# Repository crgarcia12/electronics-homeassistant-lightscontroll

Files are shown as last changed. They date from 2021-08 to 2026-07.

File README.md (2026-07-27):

# Home Automation Lights Controller - ESPHome & Home Assistant Compatible

A smart lighting controller PCB that integrates seamlessly with ESPHome and Home Assistant while maintaining full compatibility with traditional mechanical switches. This device acts as a "sidecar" to existing latching relays, adding smart home capabilities without compromising safety or requiring rewiring.

## Table of Contents

- [Overview](#overview)
- [Key Features](#key-features)
- [Quick Start](#quick-start)
- [Prerequisites](#prerequisites)
- [Available Versions](#available-versions)
- [How It Works](#how-it-works)
- [Installation Guide](#installation-guide)
- [Configuration](#configuration)
- [Technical Specifications](#technical-specifications)
- [Ordering from JLCPCB](#how-to-order-from-jlcpcb)
- [Development](#development-notes)
- [Version History](#version-history)
- [Contributing](#contributing)

## Overview

This circuit controls home lights following these core principles:

1. **Safe**: Safety is first and is not compromised in any decision
2. **Fail-safe**: If this device fails, the lights are still controllable using the mechanical switches
3. **Follows standard installation**: This device does not require you to rewire your house
4. **Centrally installable**: Can be installed in a central electrical panel

Following those principles and using as a reference a multi-switch light controlled with a mechanical latching relay, this is the wiring concept:

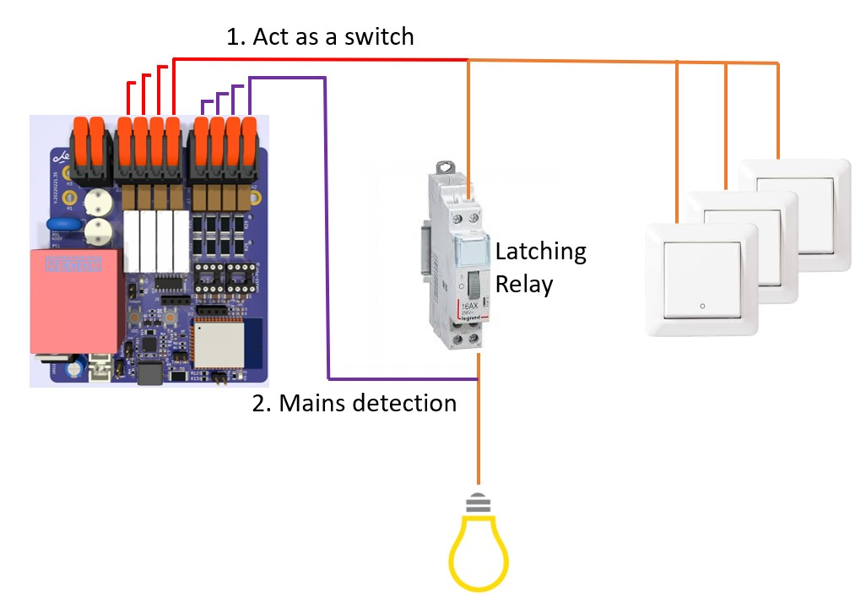
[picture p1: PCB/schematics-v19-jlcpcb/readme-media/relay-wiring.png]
Relay wiring diagram showing how the controller integrates with existing latching relay setup


A normal circuit sends all push buttons to the latching relay, which controls the lights. This circuit (ESPHome) acts as a sidecar to the latching relay, functioning as a standard push button while also sensing the output of the latching relay to detect whether the lights are on or off.

## Key Features

### Hardware Features

- **Extensible design**:
  - Exposed I2C pins
  - Exposed Serial pins
  - Multiple GPIO pins available
  - 3.3V jumper: Allows disconnecting the internal ESP32 and replacing it with any other microcontroller
  - Relay pins (4-channel version): Relays can be controlled with an external microcontroller or device directly
  - Current sensing pins: Current sensing information is exposed for external microcontroller or device integration
  - Provides both 3.3V and 5V power rails
- **ESPHome compatible**: Easy integration with Home Assistant
- **Latest versions use ESP32-S3**: A powerful microcontroller with extensive features

### Safety Features

This device incorporates multiple layers of protection:

- Input fast-blow fuse
- Input MOV (Metal Oxide Varistor) for surge protection
- Slow fuses in every relay output
- Slow fuses in every mains detection input
- 4kV insulated power supply for low voltage isolation
- Conformal coating with 90kV/mm² insulation
- High-precision temperature sensor (SHT40)

## Available Versions

There are two main versions of the board:
- **4-channel version**: Compact design for smaller installations
- **8-channel version**: Extended capacity for larger installations

Latest versions use the ESP32-S3, which is a powerful microcontroller with WiFi, Bluetooth, and extensive GPIO capabilities.

## Quick Start

### What You'll Need

- One of the PCB versions (4 or 8 channels)
- Existing installation with mechanical latching relays
- WiFi network for ESPHome connectivity
- Home Assistant instance (optional, but recommended)

### Basic Setup Steps

1. **Order the PCB**: See [Ordering from JLCPCB](#how-to-order-from-jlcpcb) section
2. **Wire the device**: Connect to your existing latching relay setup
3. **Flash ESPHome**: Upload the ESPHome configuration (see [Configuration](#configuration))
4. **Integrate with Home Assistant**: The device will auto-discover in Home Assistant

For detailed instructions, see the [Installation Guide](#installation-guide) section below.

## Prerequisites

Before installing this controller, ensure you have:

- Basic understanding of electrical wiring and safety
- Existing mechanical latching relay installation
- Access to your electrical panel
- **Safety equipment**: Insulated tools, voltage tester
- **Knowledge**: Only qualified electricians should work with mains voltage
- ESPHome installed (for firmware flashing)
- Home Assistant (optional, for smart home integration)

## Current Version: Version 27

Version 27 is an evolution of version 26.1, optimized to fit perfectly in the standard DIN rail enclosure.

**Hardware**: Uses SN74LVCH8 level shifter with OUTPUT_ENABLED feature

Board schematics for version 27
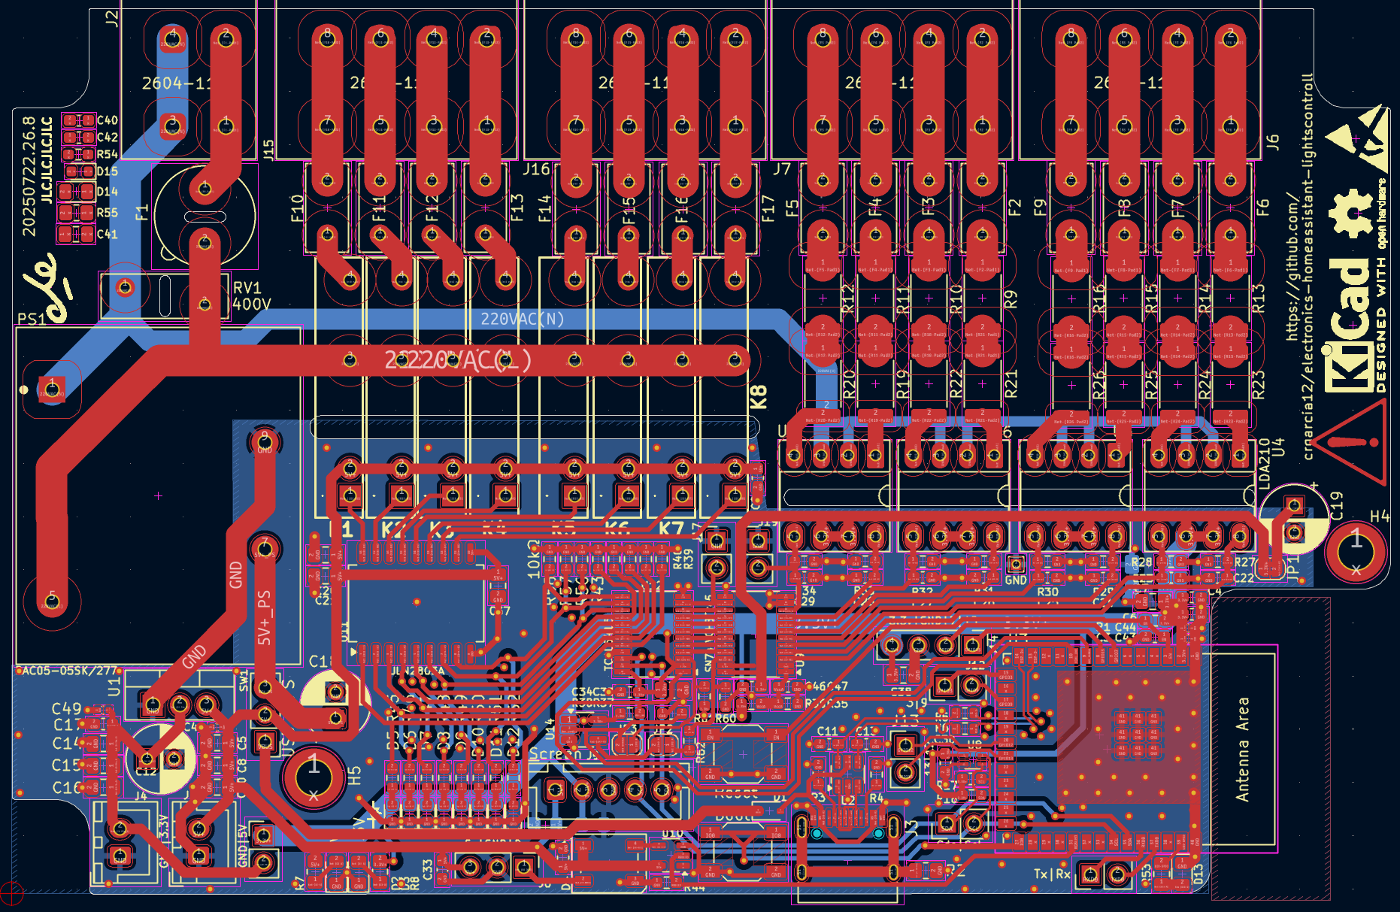
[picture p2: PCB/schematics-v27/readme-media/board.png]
PCB layout for version 27

Front view of PCB version 27
Back view of PCB version 27
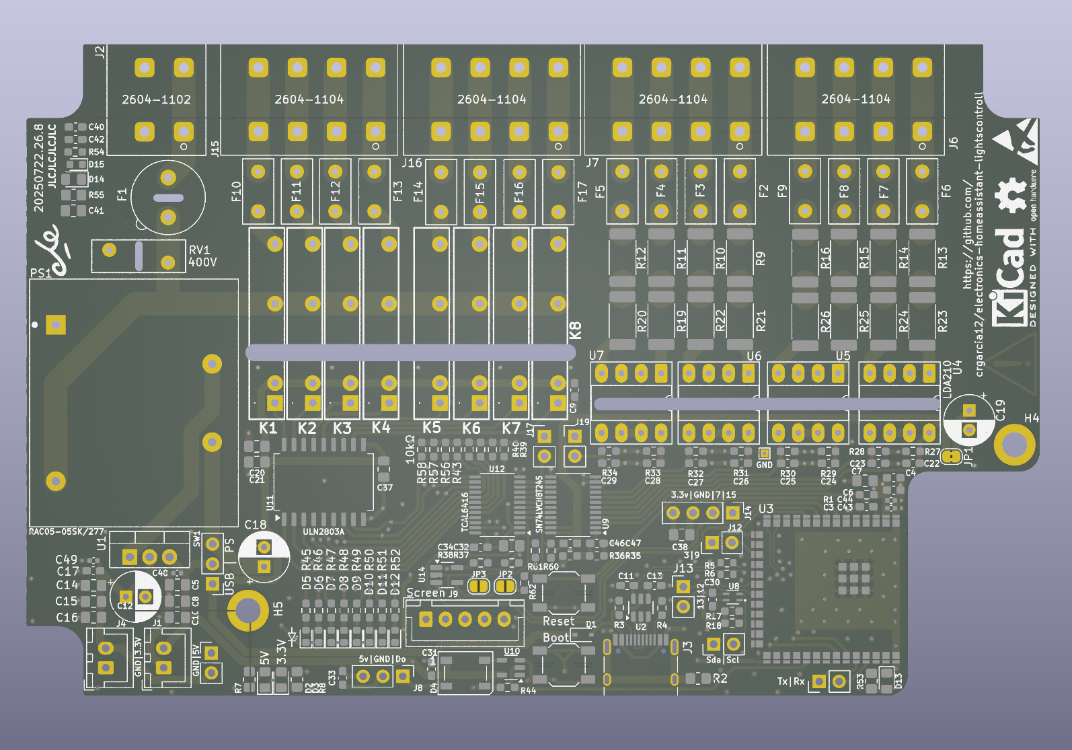
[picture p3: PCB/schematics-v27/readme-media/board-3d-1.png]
3D render of board - angle 1

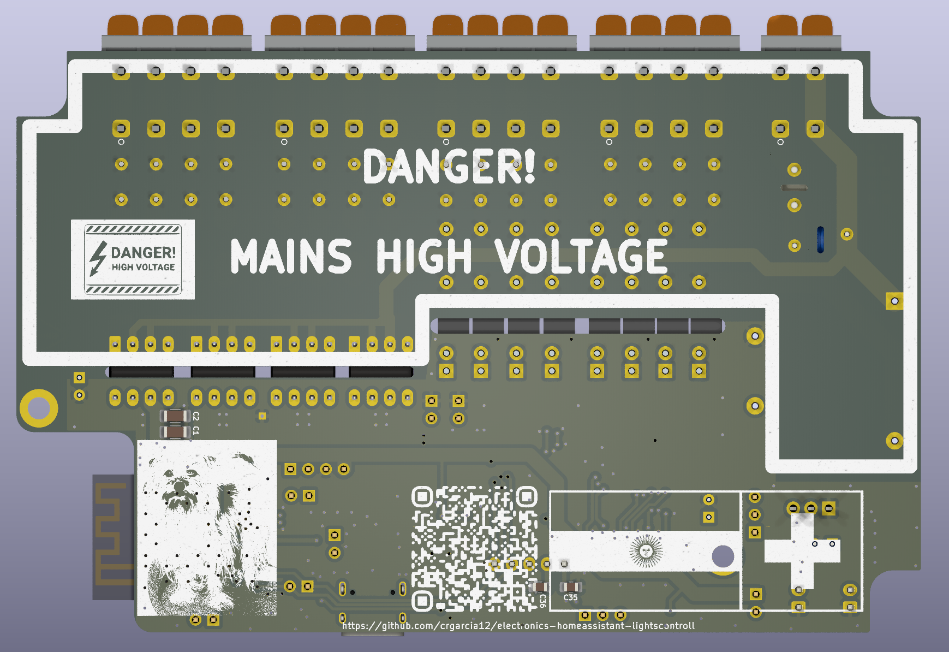
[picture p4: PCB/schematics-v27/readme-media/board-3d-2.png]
3D render of board - angle 2

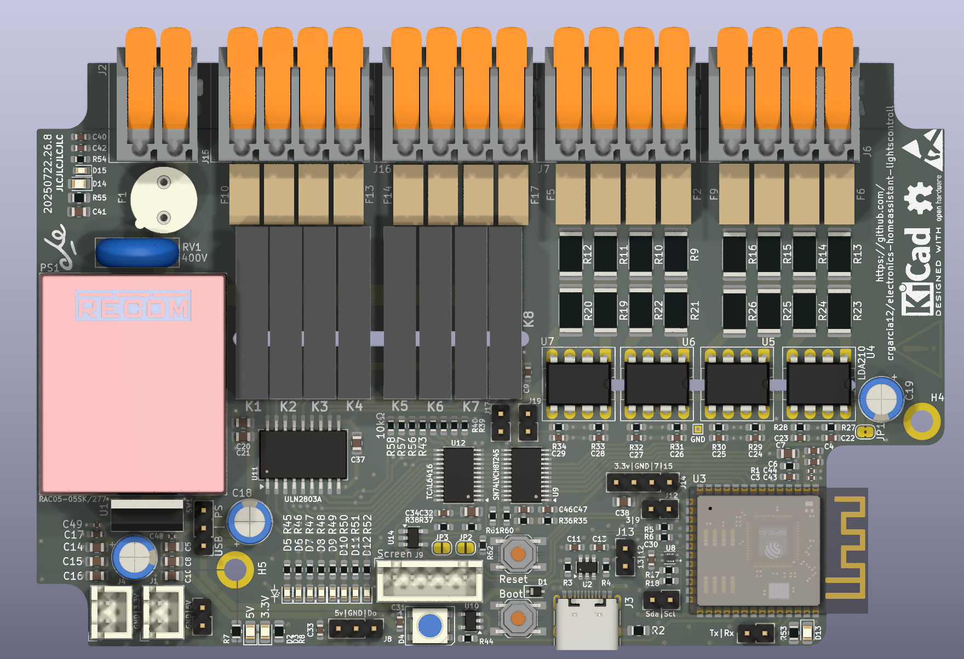
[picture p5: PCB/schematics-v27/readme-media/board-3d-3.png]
3D render of board - angle 3

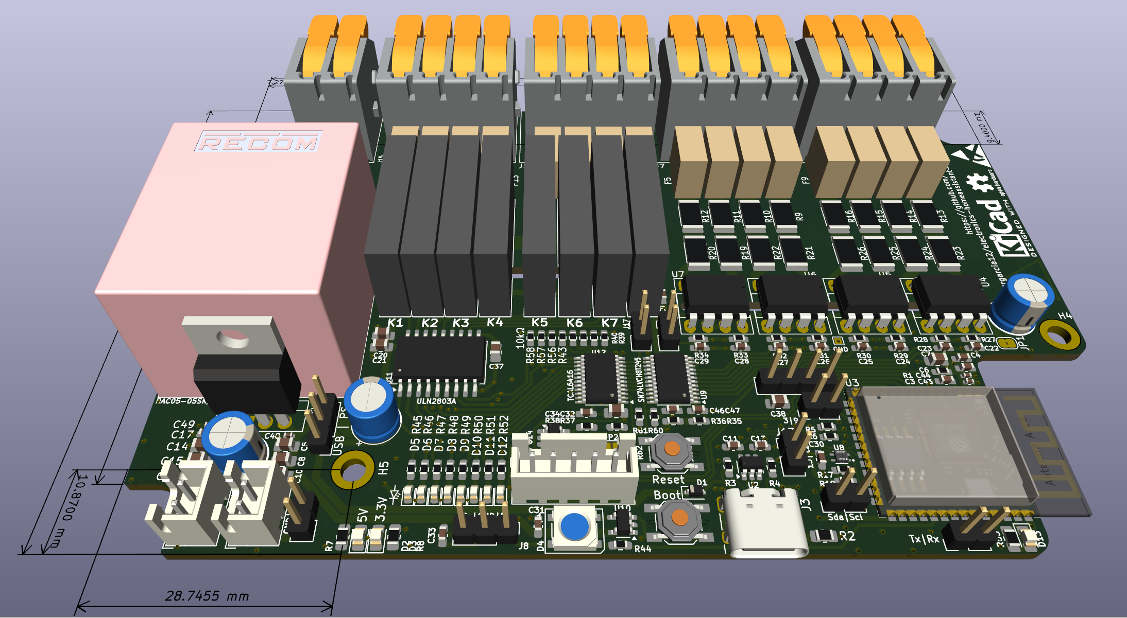
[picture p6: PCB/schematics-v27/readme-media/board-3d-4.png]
3D render of board - angle 4

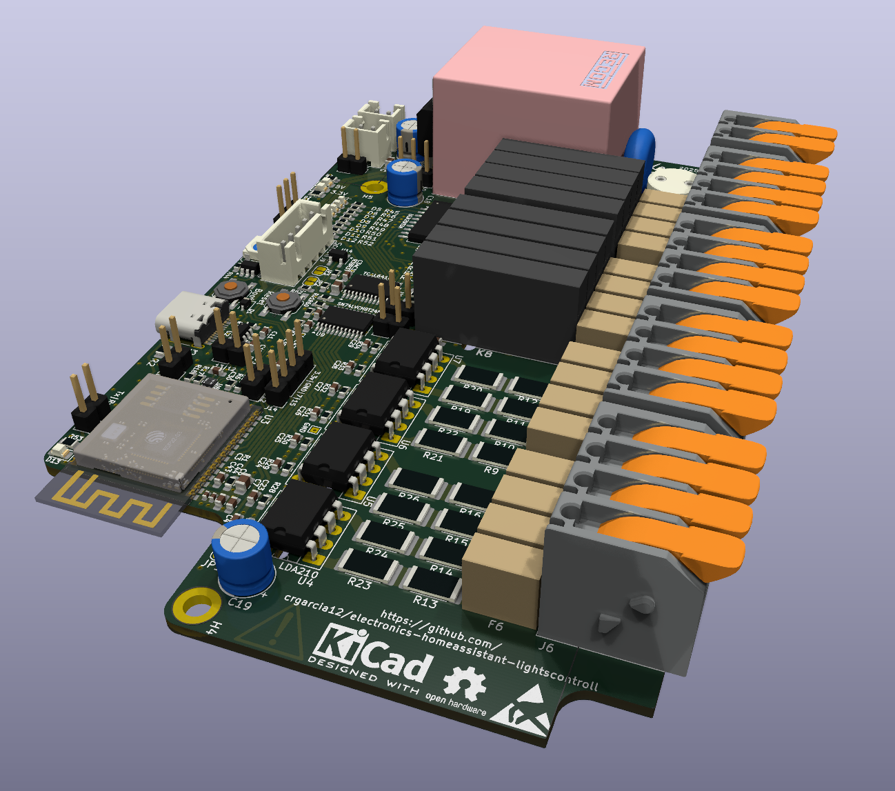
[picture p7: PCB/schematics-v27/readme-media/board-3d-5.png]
3D render of board - angle 5


## How It Works

### Mains Sensing
The PCB uses an optocoupler (LDA210 or ILD755) to detect the presence of mains voltage. These Darlington optocouplers are chosen specifically for their low current requirements, drawing only 0.7mA at less than 2V. This low-power design allows for efficient sensing without overheating components.

To reduce the mains voltage to a safe level for the optocoupler, a 300kΩ resistance setup is used. This configuration dissipates only 0.17W, which is split across two resistors. Each resistor, therefore, dissipates about 0.08W, preventing overheating issues commonly seen with other designs (such as those using the HCP chip). This improvement enhances both the safety and longevity of the PCB.

Each mains sensing channel is equipped with a fuse to protect against failures. In the event that one of the resistors fails short, the remaining resistor can carry up to 1.5mA until the fuse burns out, effectively preventing further damage. During this failure condition, the resistor would dissipate about 0.4W, so large resistors are used to withstand this potential load.

### Optocoupler and Capacitor Behavior

This PCB uses a Darlington optocoupler (LDA210), chosen for its high-gain behavior, which allows the system to react more quickly when mains power is turned on and requires less current on the LED side.

The oscilloscope images below show two different channels after the optocoupler while they are sensing mains. The yellow channel does not have any capacitors on the output, while the blue line has the capacitors.

In the first image, the optocoupler’s response to the sine wave is shown when mains power is ON. The blue line illustrates how capacitors help maintain the output in a high state when the AC cycle is crossing zero. This capacitor-induced holding effect ensures that the output remains stable, preventing fluctuations in the DC output that could cause false OFF triggers. However, this design means the line must be off for several cycles before the microcontroller can reliably detect the "off" state. Using excessively large capacitors can increase the detection delay to a noticeable extent, so capacitor size must be carefully selected to balance responsiveness and stability.

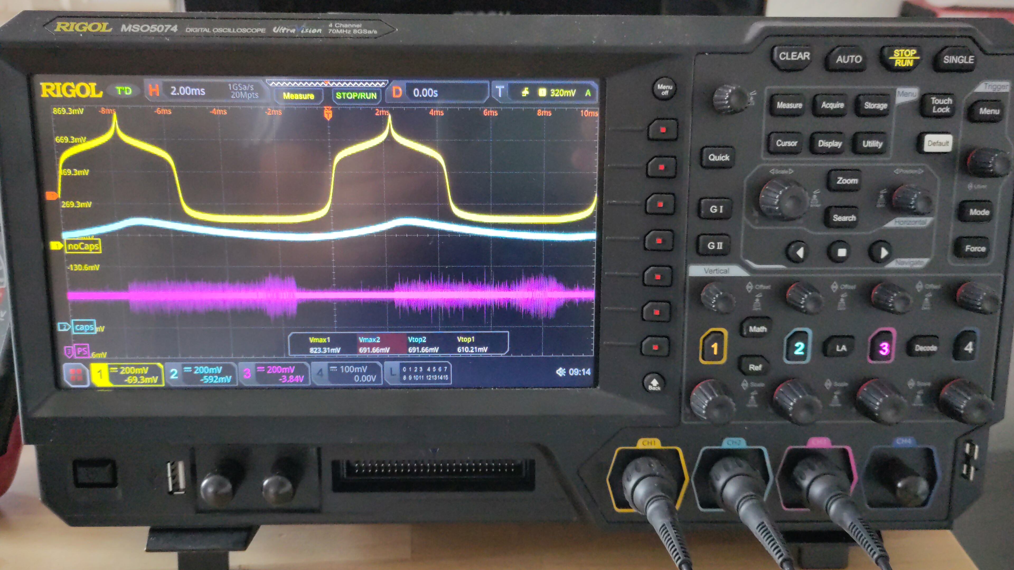
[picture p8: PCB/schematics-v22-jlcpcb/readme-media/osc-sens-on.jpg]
oscilloscope-sensing-mains-1


When mains power is first applied (yellow line), the capacitor requires time to charge before the optocoupler’s output reaches a high state (blue line). This results in a slight delay before the microcontroller detects the power-on state. If overly large capacitors are used, this delay becomes more pronounced, which can reduce responsiveness. The capacitor size must be carefully selected to minimize this delay while ensuring system stability.

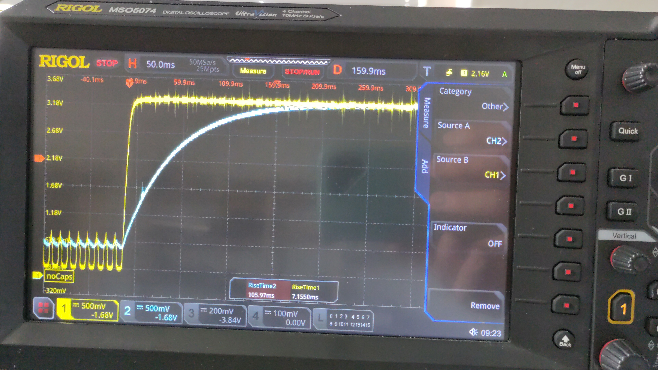
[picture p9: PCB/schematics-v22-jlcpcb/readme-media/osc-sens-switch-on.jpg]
oscilloscope-sensing-mains-2


Switching off mains power can generate noise, particularly depending on where in the sine wave the power is cut (e.g., at zero-crossing). Capacitors on the PCB help absorb much of this noise, reducing the likelihood of transient spikes or false "on" triggers that could interfere with other components or the microcontroller. This filtering helps improve system reliability, especially in noisy environments.

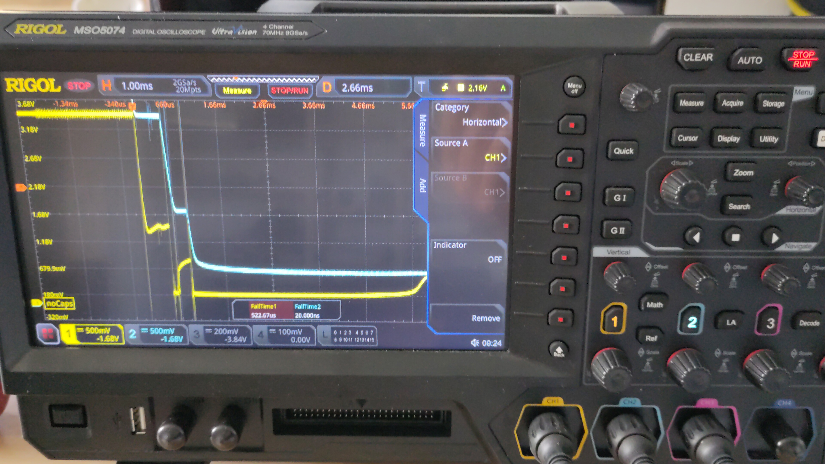
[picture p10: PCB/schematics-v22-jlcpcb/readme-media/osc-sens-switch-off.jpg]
oscilloscope-sensing-mains-3


### Relays
The initial design for this system included small PCB-mounted mechanical relays, such as the PCN105D model. These relays, while compact and effective for basic switching, generated significant electromagnetic interference (EMI) due to the mechanical contacts. Despite efforts to mitigate this noise by adding flyback diodes and isolating the ground plane, the interference remained high. Under certain conditions, EMI levels were high enough to cause the microcontroller to reset, making this setup unreliable for stable home automation.

The image below illustrates the noise generated by the PCN105D mechanical relay during operation. This noise spike, especially during switching events, demonstrated the limitations of PCB-mounted relays in applications requiring low EMI.

These PCB relays are intended to trigger DIN-mounted latching relays, which are commonly used in electrical installations typically without flyback diodes, resulting in voltage spikes of several KV when switched off.

This picture shows PCN105D relays when switched off:

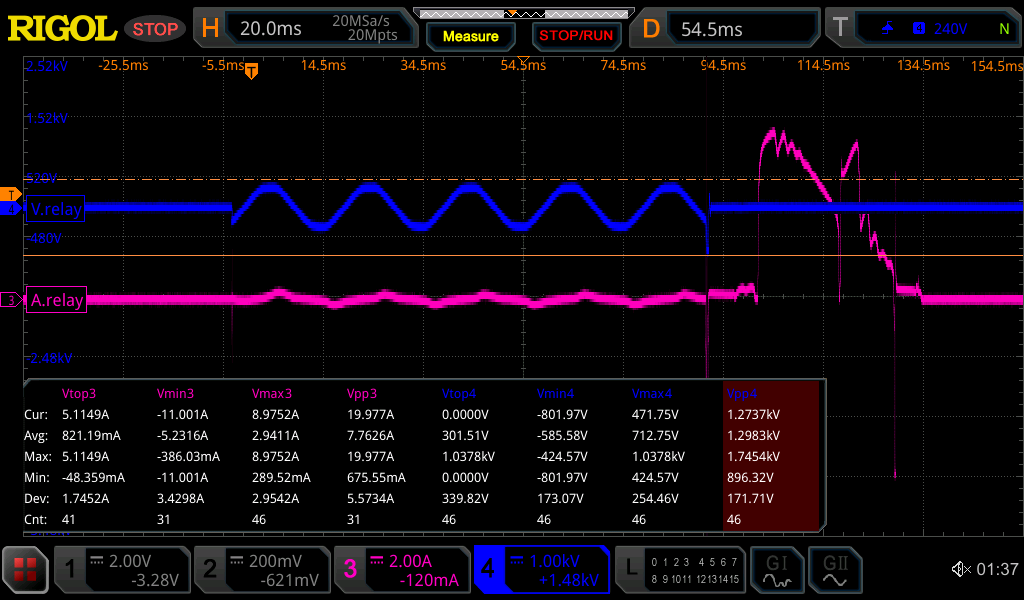
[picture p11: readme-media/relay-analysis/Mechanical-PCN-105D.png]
Oscilloscope showing EMI noise from PCN105D mechanical relay


To address the noise and stability issues, the design was upgraded to use AQG22205 solid-state relays. These relays are only rated at 2A, but they incorporate an internal snubber circuit, making them far more resistant to voltage spikes on the mains side. Unlike mechanical relays, these solid-state relays do not generate any noise during switching.

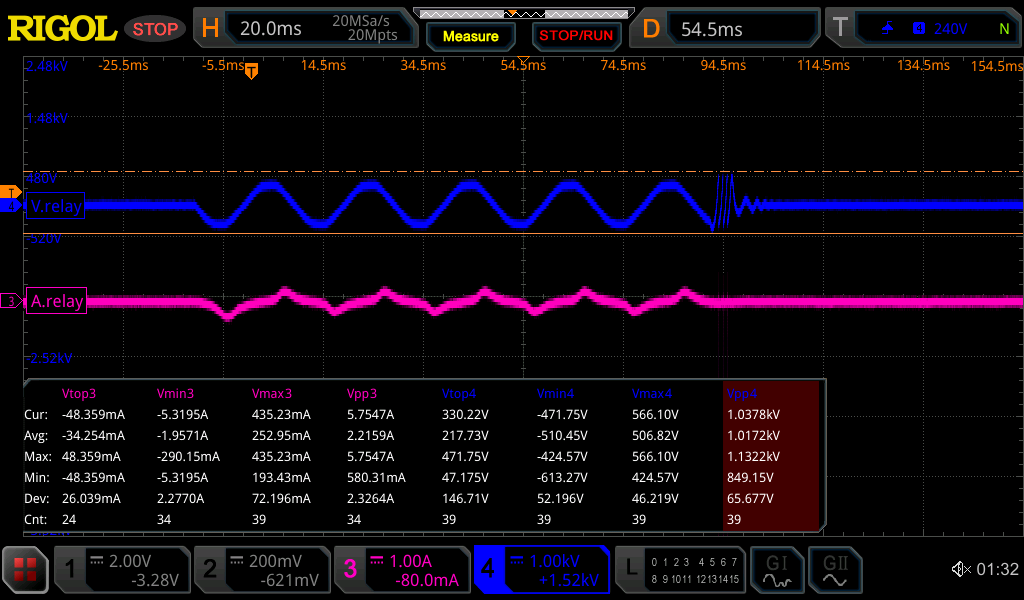
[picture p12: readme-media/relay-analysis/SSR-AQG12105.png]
Oscilloscope showing clean switching with AQG12105 solid-state relay


## Installation Guide

> **⚠️ WARNING**: Installation involves working with mains voltage. Only qualified electricians should perform this installation. Improper installation can result in serious injury or death.

### Wiring Instructions

1. **Power off** all circuits at the breaker
2. **Verify** power is off using a voltage tester
3. Connect the controller to your existing latching relay setup following the wiring diagram above
4. Connect each mains sensing input to the appropriate circuit outputs
5. Ensure all connections are secure and properly insulated
6. **Double-check** all wiring before applying power

### First Power-On

1. Apply power to the device
2. The device should create a WiFi access point named "Hamodule Fallback Hotspot"
3. Connect to this access point and configure your WiFi credentials
4. The device will restart and connect to your network

## Configuration

### ESPHome Configuration

Example configuration files are provided in the
[`firmware/tester-code-esphome`](firmware/tester-code-esphome/) directory:

- [`EspHome.yml`](firmware/tester-code-esphome/EspHome.yml) - Basic 4-channel configuration
- [`EspHome-v22.yml`](firmware/tester-code-esphome/EspHome-v22.yml) - Configuration for version 22

#### Basic Configuration Example

```yaml
esphome:
  name: hamodule
  platform: ESP32
  board: esp32dev

wifi:
  ssid: "YOUR_WIFI_SSID"
  password: "YOUR_WIFI_PASSWORD"

api:
ota:

# Temperature sensor
sensor:
  - platform: sht4x
    temperature:
      name: "Temperature"
    humidity:
      name: "Relative Humidity"

# Light sensing and control
binary_sensor:
  - platform: gpio
    name: "Light 1 Status"
    pin: GPIO_PIN_NUMBER

switch:
  - platform: gpio
    name: "Light 1"
    pin: GPIO_PIN_NUMBER
```

### Home Assistant Integration

Once configured with ESPHome, the device will automatically be discovered by Home Assistant. You can then:

1. Go to **Settings** → **Devices & Services**
2. Look for the ESPHome integration
3. Click **Configure** on your device
4. Add it to your dashboard

Example floorplan integrations are available in the [`home-assistant`](home-assistant/) directory.

### ESP-IDF MQTT Firmware

The unified C++ firmware in [`firmware/lightcontrol`](firmware/lightcontrol/) supports the four-channel and
eight-channel boards. On first boot, connect to the `LightsSetup-XXXX` access point and open
`http://192.168.4.1` to configure WiFi, MQTT, room/device names, and the HTTPS firmware update URL.
Home Assistant discovers the light controls, firmware version sensor, and firmware update button through MQTT.
When an SHT40 is present at I2C address `0x44`, the firmware also publishes temperature and relative humidity
every 30 seconds. The onboard WS2812B on GPIO38 is exposed as a full RGB and brightness-controlled Home
Assistant light.

Configuration can instead be written directly over USB without using the setup access point. Store one
version-controlled JSON file per controller under
[`firmware/lightcontrol/provisioning/devices`](firmware/lightcontrol/provisioning/devices/). These files contain
the expected MAC address, WiFi SSID, MQTT broker/user, device name, room, and OTA URL, but never passwords.

Copy `secrets.example.json` to the ignored `secrets.local.json` and enter the shared WiFi and MQTT passwords:

```powershell
Copy-Item .\firmware\lightcontrol\provisioning\secrets.example.json `
  .\firmware\lightcontrol\provisioning\secrets.local.json
```

Then provision a connected controller:

```powershell
powershell -ExecutionPolicy Bypass -File .\firmware\lightcontrol\provision.ps1 `
  -Port COM3 `
  -ConfigPath .\firmware\lightcontrol\provisioning\devices\lightscontrol-36d4.json
```

The script verifies the connected ESP32 MAC, merges the tracked configuration with the ignored passwords,
flashes only the NVS partition, and deletes its temporary credential files. Missing secrets are requested
interactively instead of being added to the device configuration. `mqttPassword` can be shared by every
controller, or `mqttPasswords` can map each tracked MQTT username to a separate password.

The first OTA-capable image must be installed over USB because it introduces the dual-slot partition table.
Afterward, pressing **Install firmware update** in Home Assistant downloads the configured HTTPS image into
the inactive slot. ESP-IDF retains the previous image for automatic rollback if the new image cannot boot.
The Home Assistant **Firmware status** diagnostic reports each OTA phase and download percentage.
The RGB LED rapidly blinks purple while updating, then alternates blue and green during the reboot
connection sequence and turns off once WiFi and MQTT are healthy. The first update that installs this
behavior is still executed by the previous firmware, so purple indication begins with subsequent updates.
The separate active-high status LED on GPIO1 stays off and emits one brief pulse whenever an MQTT
message is published or received.

## Technical Specifications

### Circuit Simulation

If you want to understand how the mains sensing circuit works, you can use this simulation: [lushprojects circuit simulator](http://lushprojects.com/circuitjs/circuitjs.html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).

<details>
<summary>Circuit simulation code</summary>

```
$ 1 0.000005 30.13683688681966 70 5 50 5e-11
v -96 368 -96 80 0 1 50 230 0 0 0.5
w 48 80 48 144 0
d 48 144 112 208 2 default
d 48 272 112 208 2 default
d -16 208 48 144 2 default
d -16 208 48 272 2 default
w 48 272 48 368 0
w 48 368 -96 368 0
w -16 208 -16 304 0
w 112 208 160 208 0
w -16 304 224 304 0
r -96 80 48 80 0 300000
x 633 351 750 354 4 20 ESP32\sGPIO
407 448 208 528 208 1
w 224 240 224 304 0
v 752 272 752 208 0 0 40 3.3 0 0 0.5
w 624 208 544 208 0
r 624 272 752 272 0 50000
w 544 240 544 272 0
c 624 208 624 272 0 0.0000049999999999999996 0.08913507182464649 0.001
w 544 272 624 272 0
w 624 208 752 208 0
s 272 208 336 208 0 0 false
r 624 320 752 320 0 1000000
w 624 272 624 320 0
w 752 272 752 320 0
x 209 185 404 188 4 20 Mains\sSensing\sSwitch
w 448 208 336 208 0
w 272 208 160 208 0
w 448 240 224 240 0
o 0 64 0 4099 320 0.00078125 0 2 0 3
o 17 64 0 4099 5 0.00009765625 1 2 17 3
o 23 64 0 4099 5 0.00009765625 2 2 23 3
```
</details>

## How to Order from JLCPCB
Step-by-step guide for ordering PCB from JLCPCB

For detailed fabrication files and assembly instructions, see the [Development Notes](#development-notes) section below.

## Development Notes

## Generating fabrication files for JLCPCB
1. Plot PCB Gerber + Drill + Map:

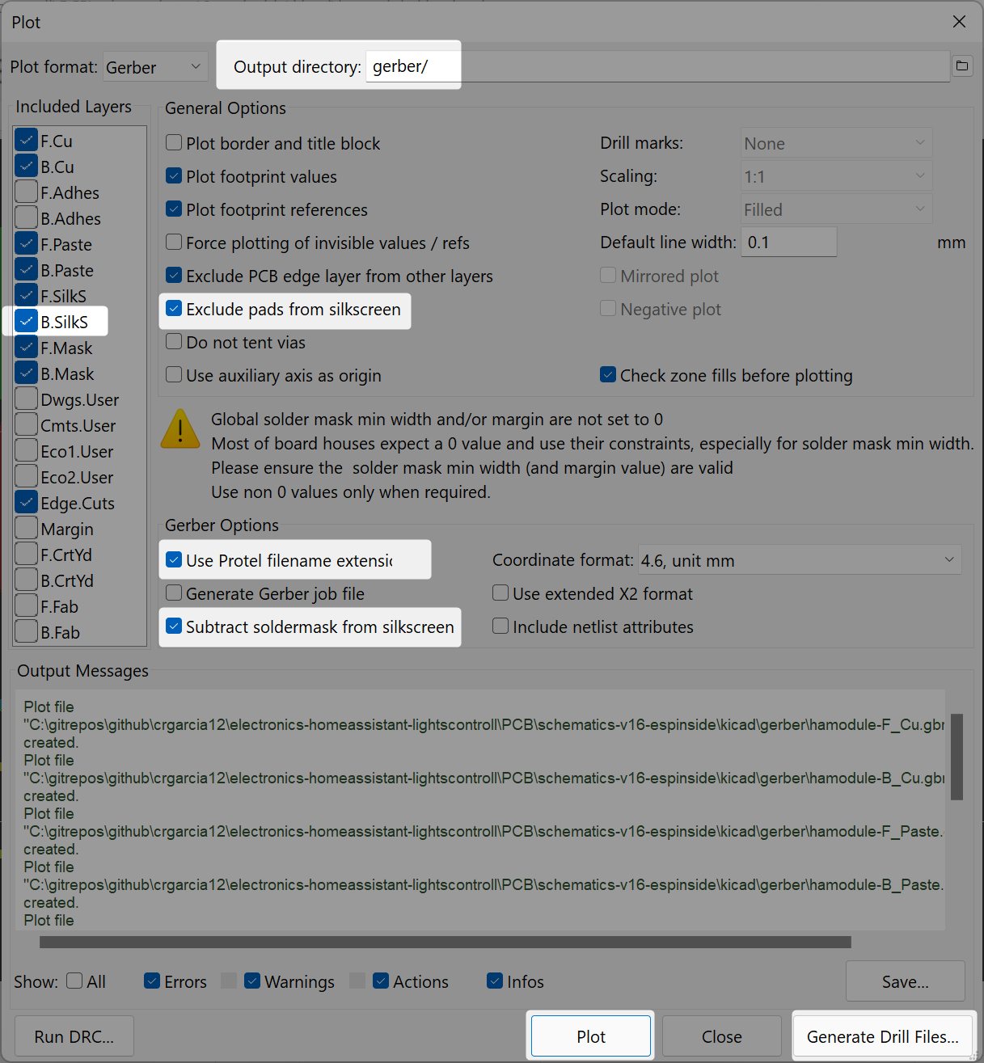
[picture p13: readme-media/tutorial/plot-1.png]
    
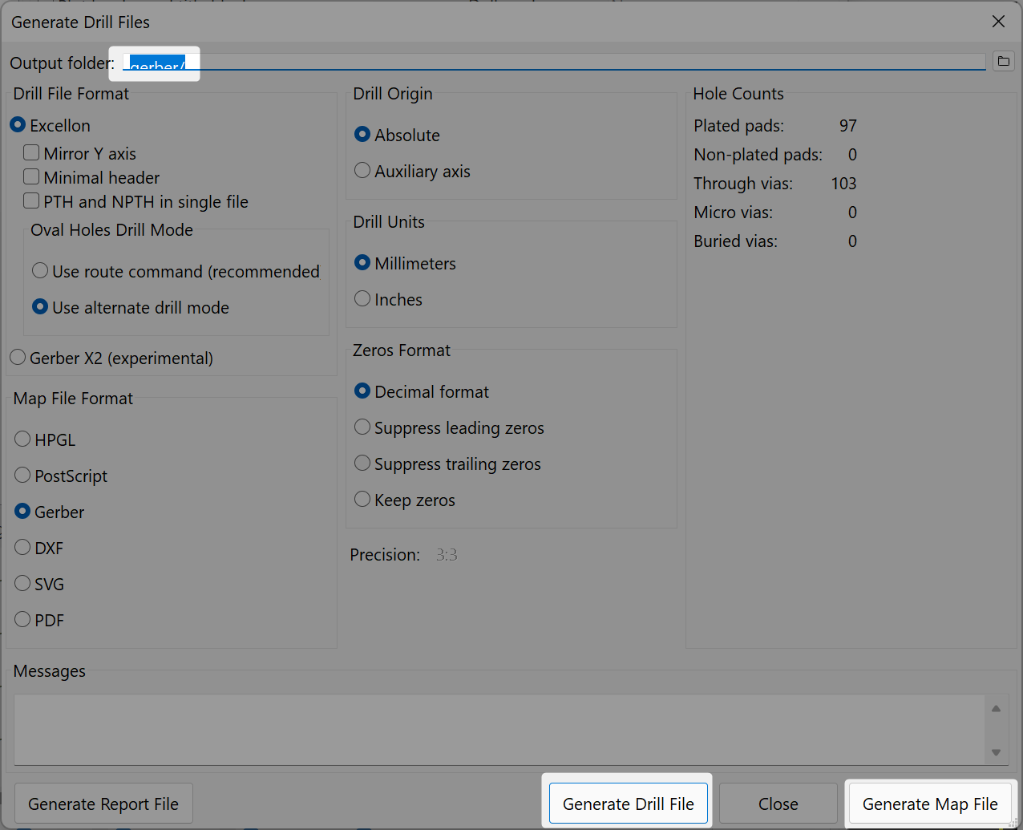
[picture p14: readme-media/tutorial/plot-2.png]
    

1. Bom files
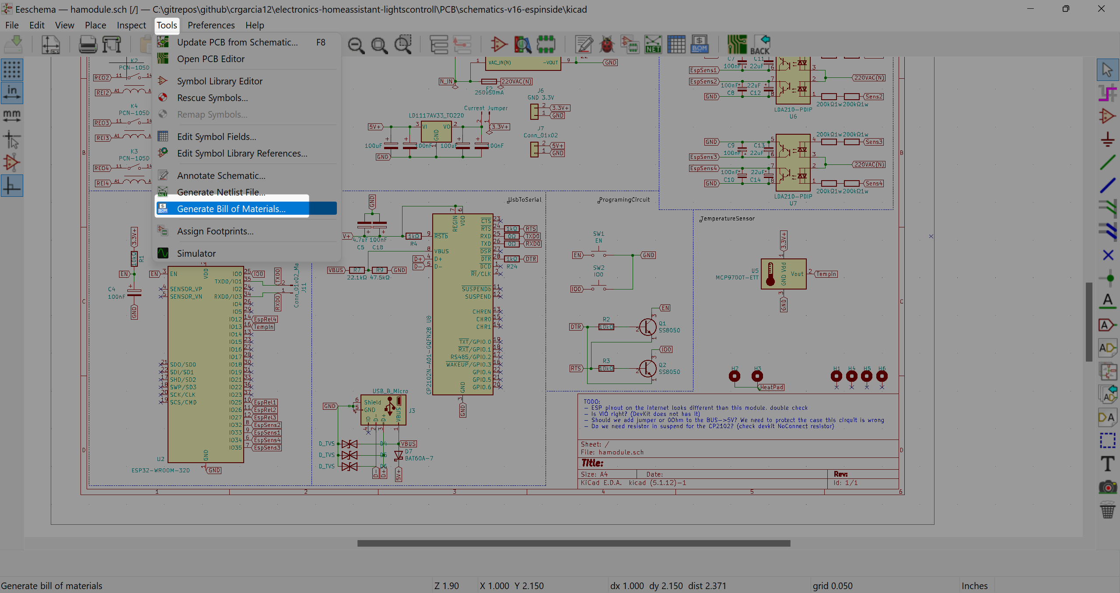
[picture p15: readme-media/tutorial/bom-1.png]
    
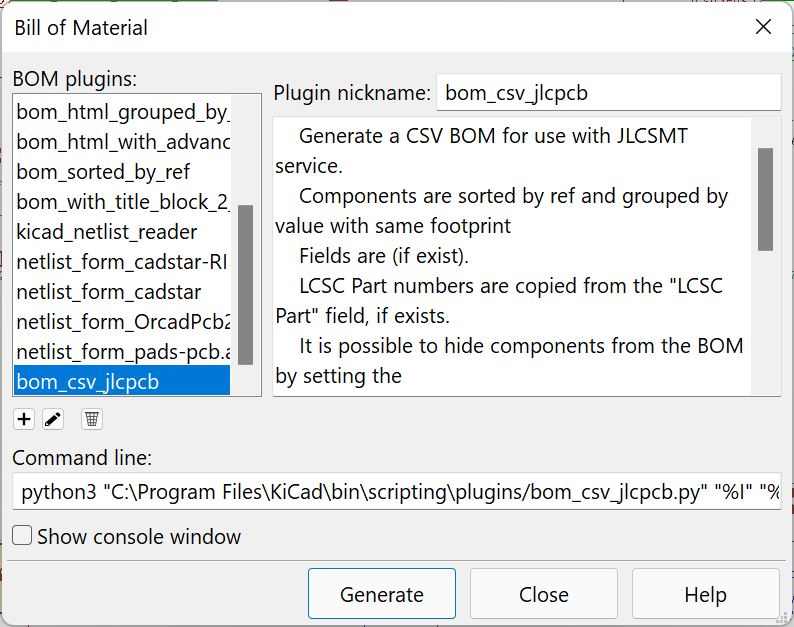
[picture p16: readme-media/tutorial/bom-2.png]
    

    Command: python3 "C:\Program Files\KiCad\bin\scripting\plugins/bom_csv_jlcpcb.py" "%I" "%O.csv"
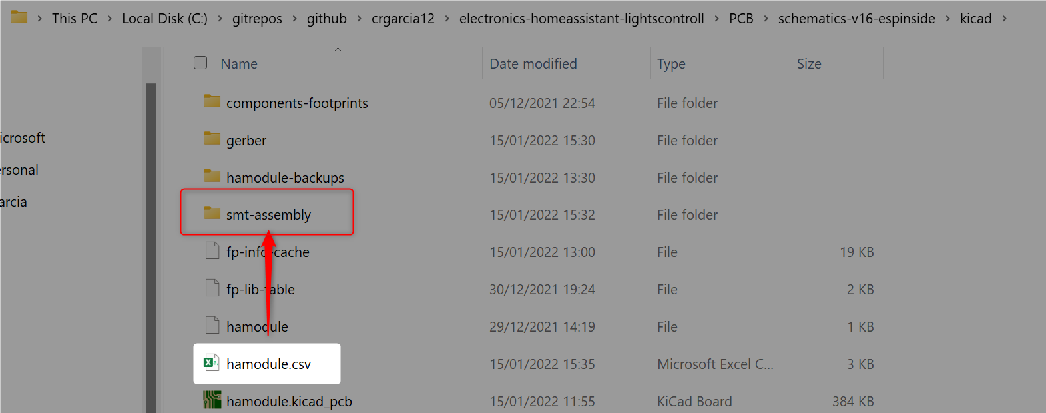
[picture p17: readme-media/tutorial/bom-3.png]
    

1. Drill files
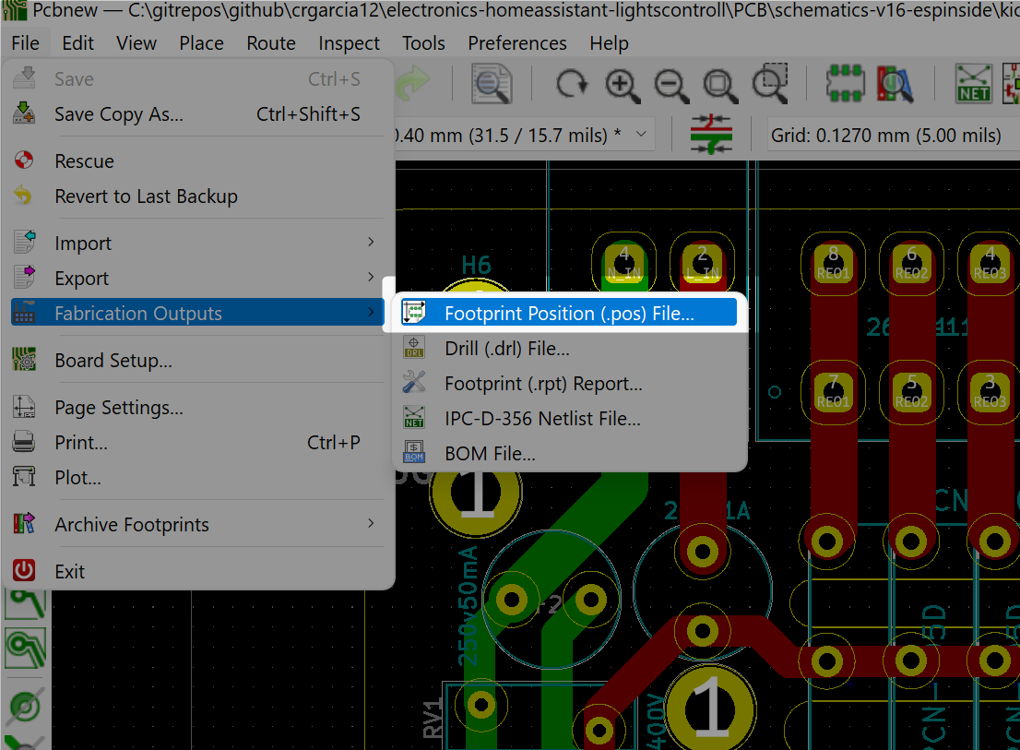
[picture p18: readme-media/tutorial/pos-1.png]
    
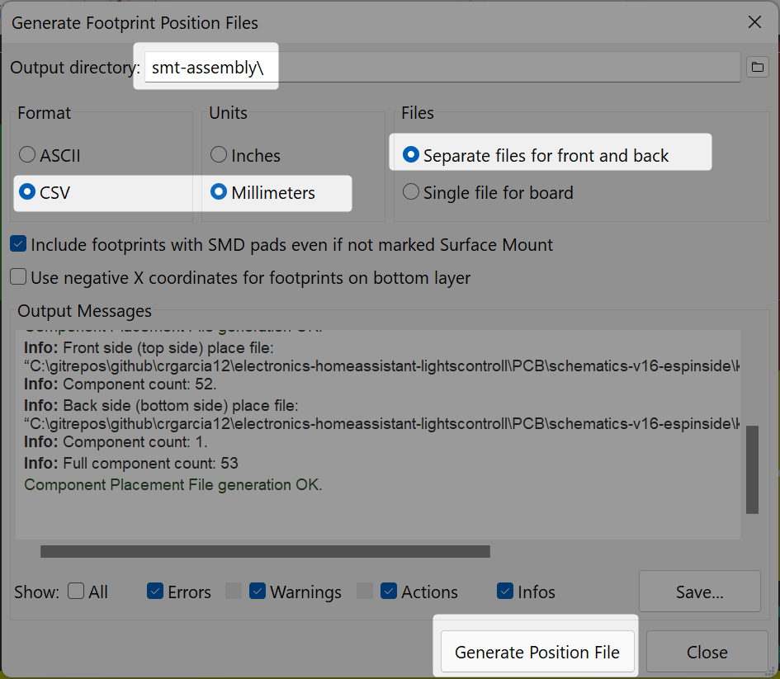
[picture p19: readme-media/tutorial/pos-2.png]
    
    run the python script to rotate the components
    

    PS C:\\...\smt-assembly> python3 .\kicad-to-jlcpcb-pos.py .\hamodule-top-pos.csv .\hamodule-top-pos-jlcpcb.csv

### Generate Documentation

**Schematics:**
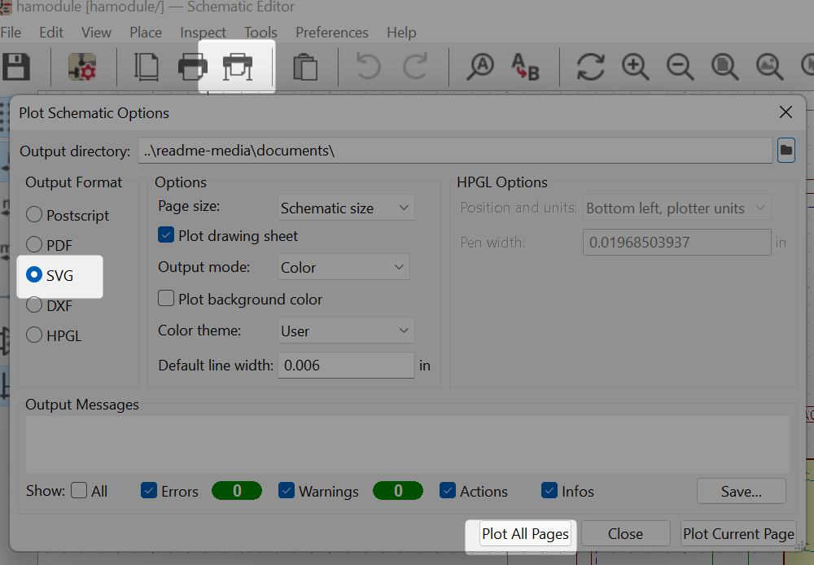
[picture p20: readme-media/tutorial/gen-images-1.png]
Screenshot showing schematic generation


**PCB:**
Print to PDF, and use a high-resolution PDF to JPG converting website like: https://pdf2jpg.net/

---

## Version History

This section documents the evolution of the board design through multiple iterations.

### Older Versions: 26.1, 26.2, 26.3 - Eight Channels with IO Expander
**Changes compared to version 23:**
- Using TCAL6416A instead of MCP23108 due to having push-pull instead of open-drain outputs
- MCP23017 has released an amendment to the datasheet declaring a bug in two pins, making them read-only
- Adjusted the border cut-outs to fit the middle mounting hole
- Fixed a bug in the TXB0108 implementation: OE and DIR pins should reference VccA (requires voltage divider: VccA = 3V, not 3.3V)
- Added descriptions in the schematics
- Created 3 subversions by JLCPCB to test fitting in the case (all the same circuit, different board sizes)
- **Known Bug**: The resistors R27-R34 are too weak because the 74LVCH8T245PWE4 level shifter has bus voltage holder

Version 26.1 (SN74LVCH8 + OUTPUT_ENABLED)
board-schematics
board-pcb
board-pcb
board-pcb
board-pcb
board-pcb
board-pcb
board-pcb
board-pcb

### Older Versions: 24 - Eight Channels with IO Expander

**Changes compared to version 23:**
- Using TCAL6416A instead of MCP23108 due to having push-pull instead of open-drain outputs
- MCP23017 has released an amendment to the datasheet declaring a bug in two pins, making them read-only
- Adjusted the border cut-outs to fit the middle mounting hole
- There are two versions of this board: one using SN74LVCH8 and the other one using TXB0108. To compare them, switch between the two schematics in two browser tabs

Version 24.8-1 (TXB0108)
board-schematics
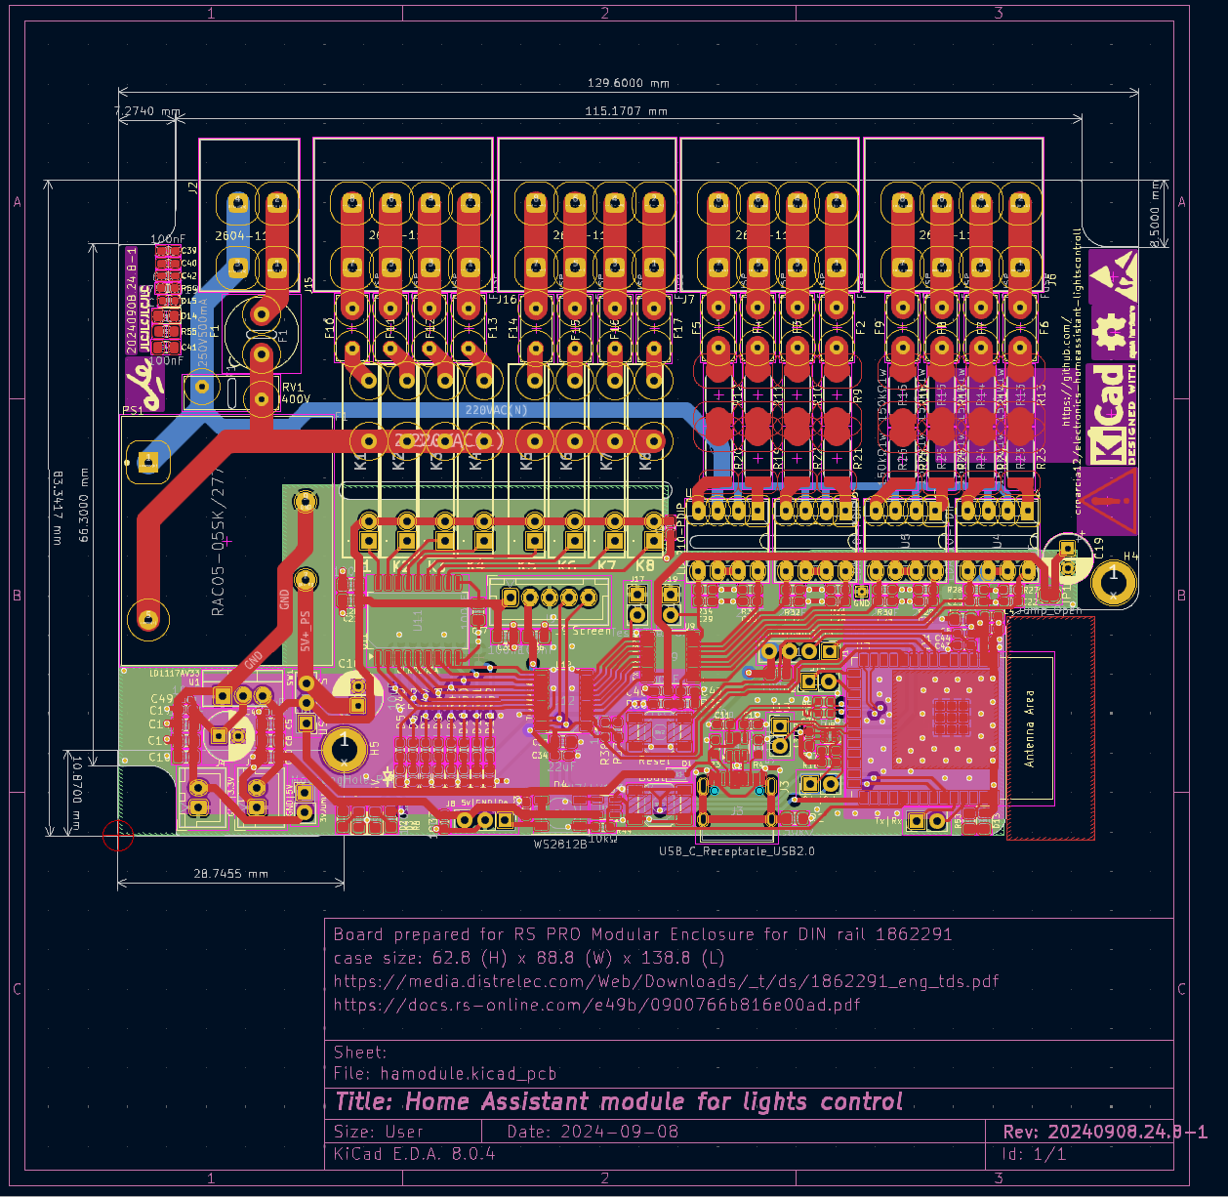
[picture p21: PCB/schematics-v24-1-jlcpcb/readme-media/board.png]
board-pcb


Version 24.8-2 (SN74LVCH8 + OUTPUT_ENABLED)
board-schematics
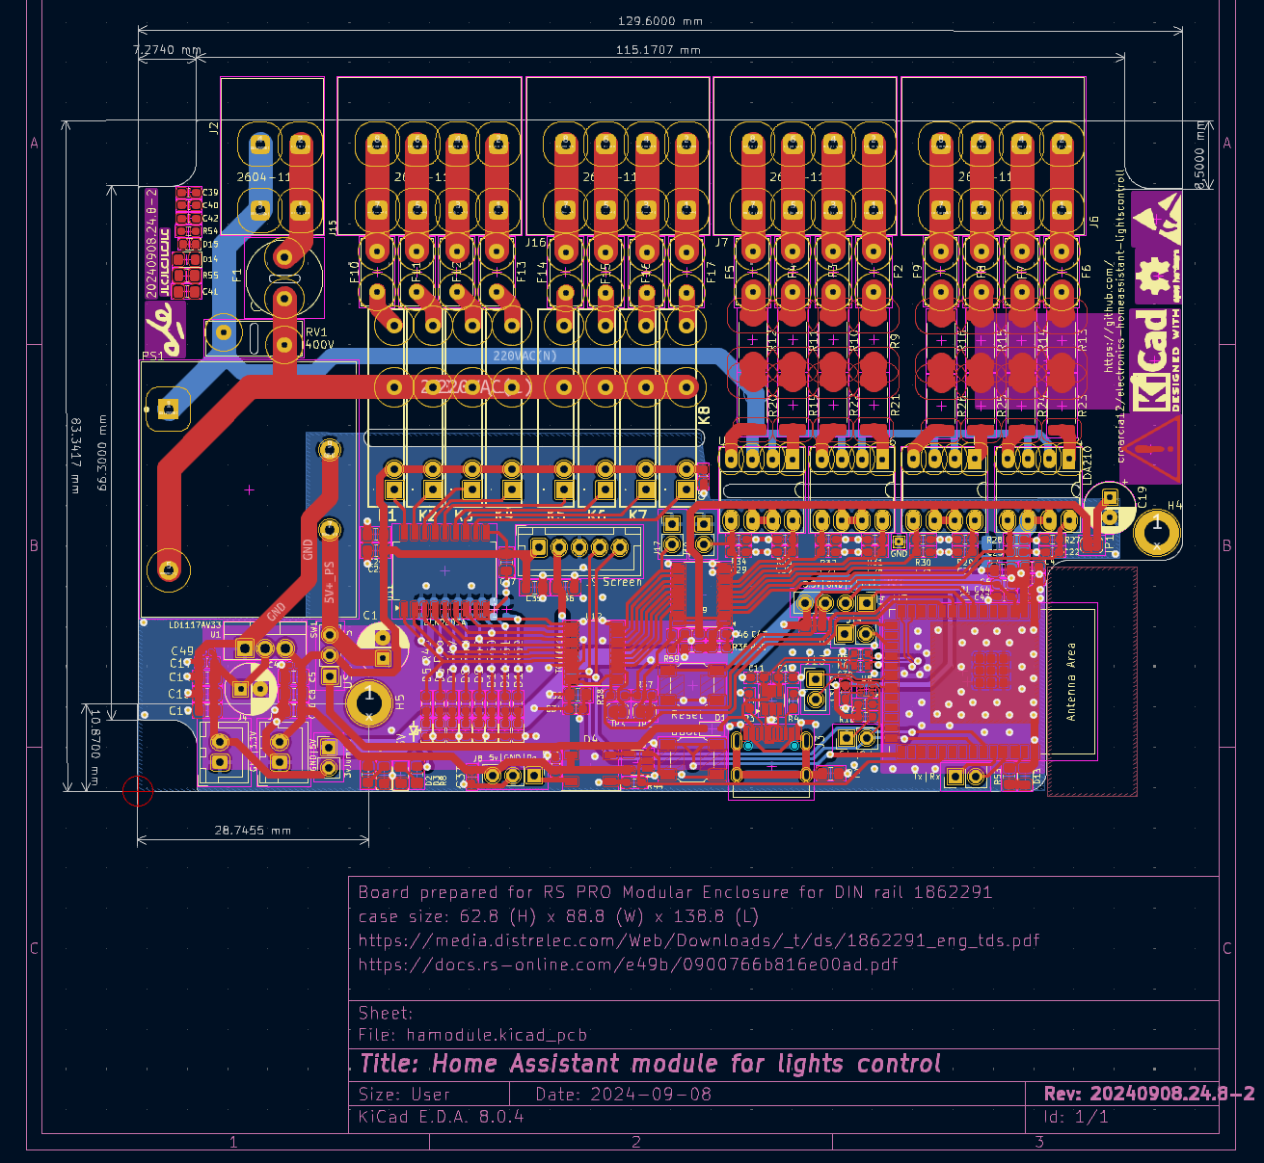
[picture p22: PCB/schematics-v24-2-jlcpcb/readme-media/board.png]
board-pcb

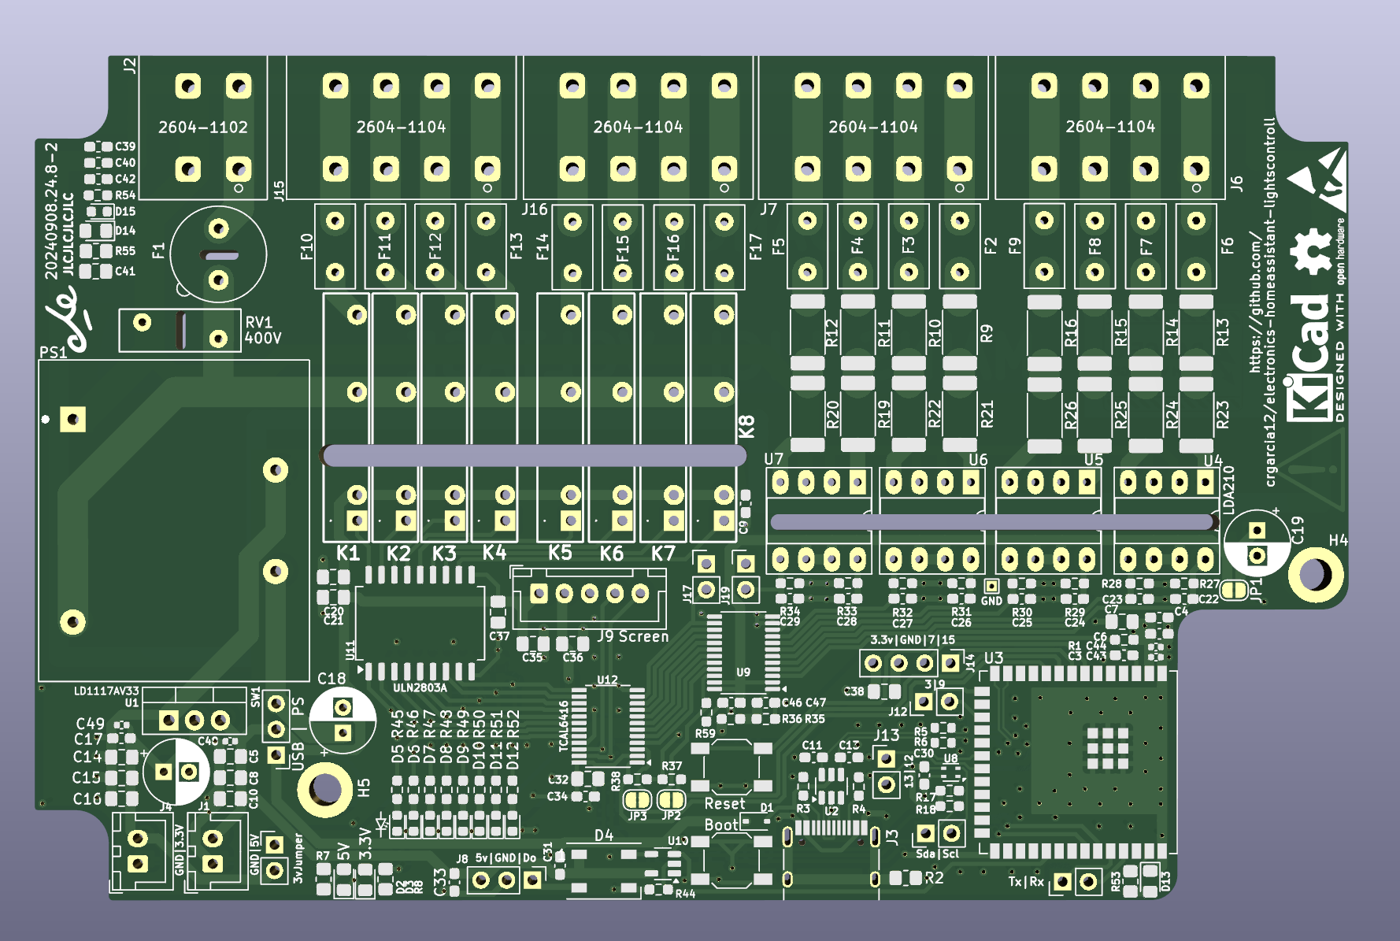
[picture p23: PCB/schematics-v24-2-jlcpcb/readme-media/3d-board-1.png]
board-pcb

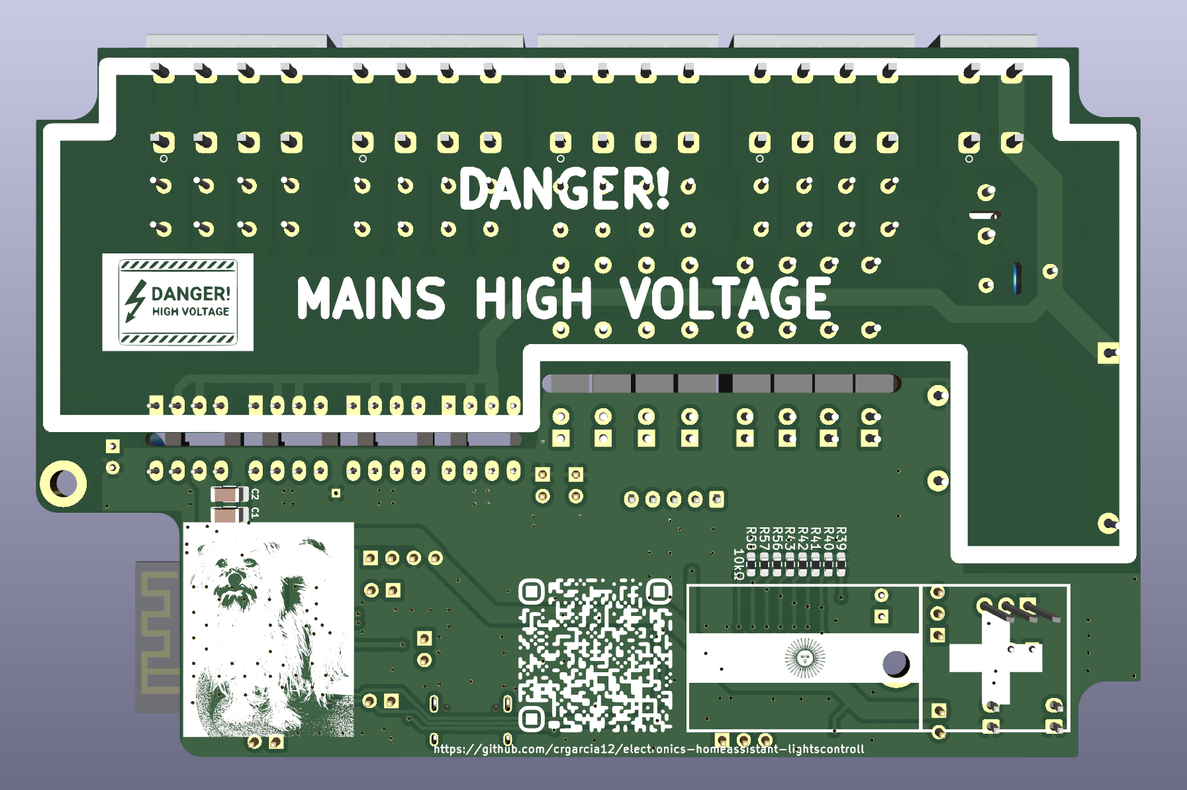
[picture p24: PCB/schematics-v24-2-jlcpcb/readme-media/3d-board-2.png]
board-pcb

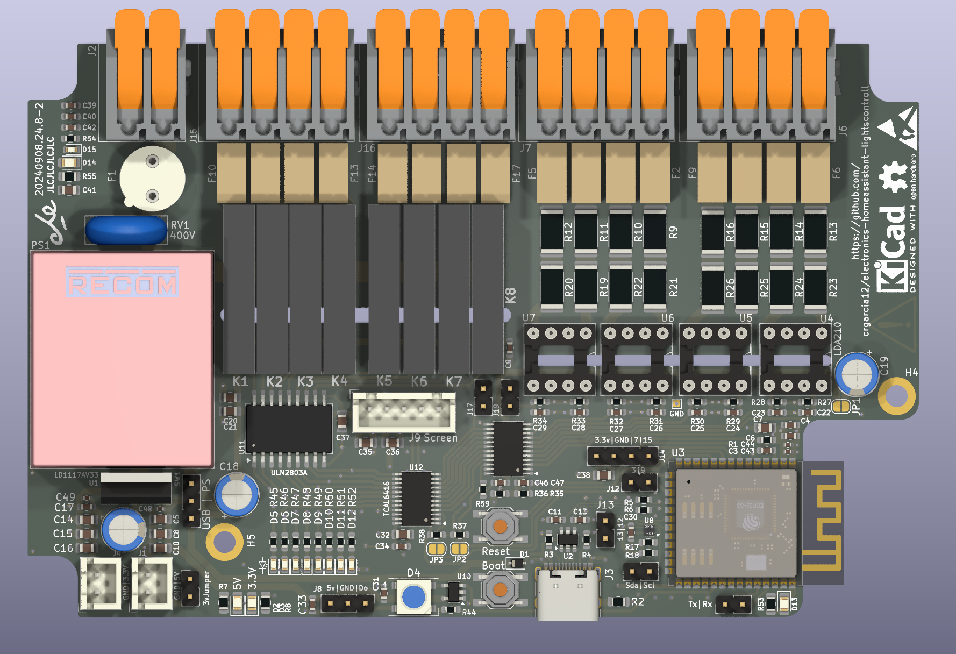
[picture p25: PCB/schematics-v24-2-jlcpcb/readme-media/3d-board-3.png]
board-pcb

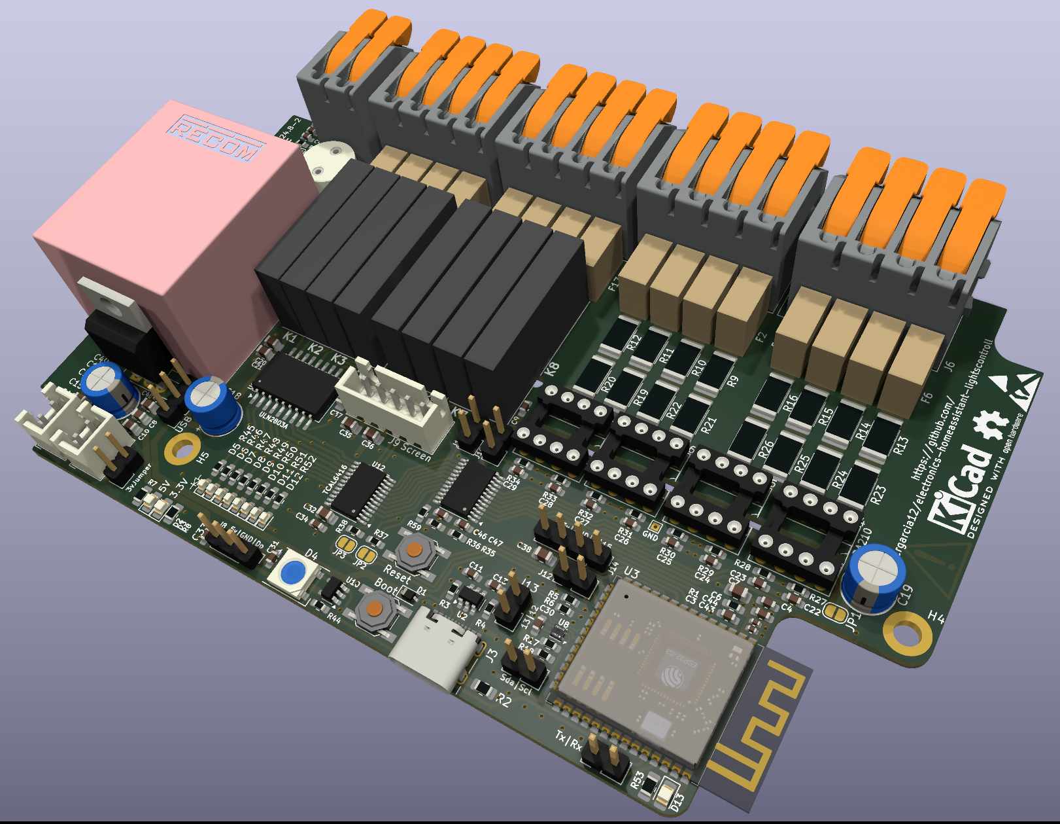
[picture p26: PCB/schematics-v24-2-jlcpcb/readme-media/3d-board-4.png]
board-pcb


### Older Versions: 23 - Eight Channels

**Changes compared to version 22:**
* Eight channels controlled via I2C for relays and mains sensing
* Added RGB Led controller
* Capacitor for 5v line
* Compatible with case: RS PRO Modular Enclosure for DIN rail Stock number: 1862291 (https://uk.rs-online.com/web/p/din-rail-enclosures/1862291/)
* Added MCP23018 as IO expander and TXB0108PW to shift the output of the Darlington (~2.5V) to the logical high (3.3V)

Bugs
* MCP23018 is open drain and not a direct replace from MCP23017: Outputs are GND or disconnected, not Vcc
* Mid-PCB mounting hole in the cut version is not properly placed

board-schematics
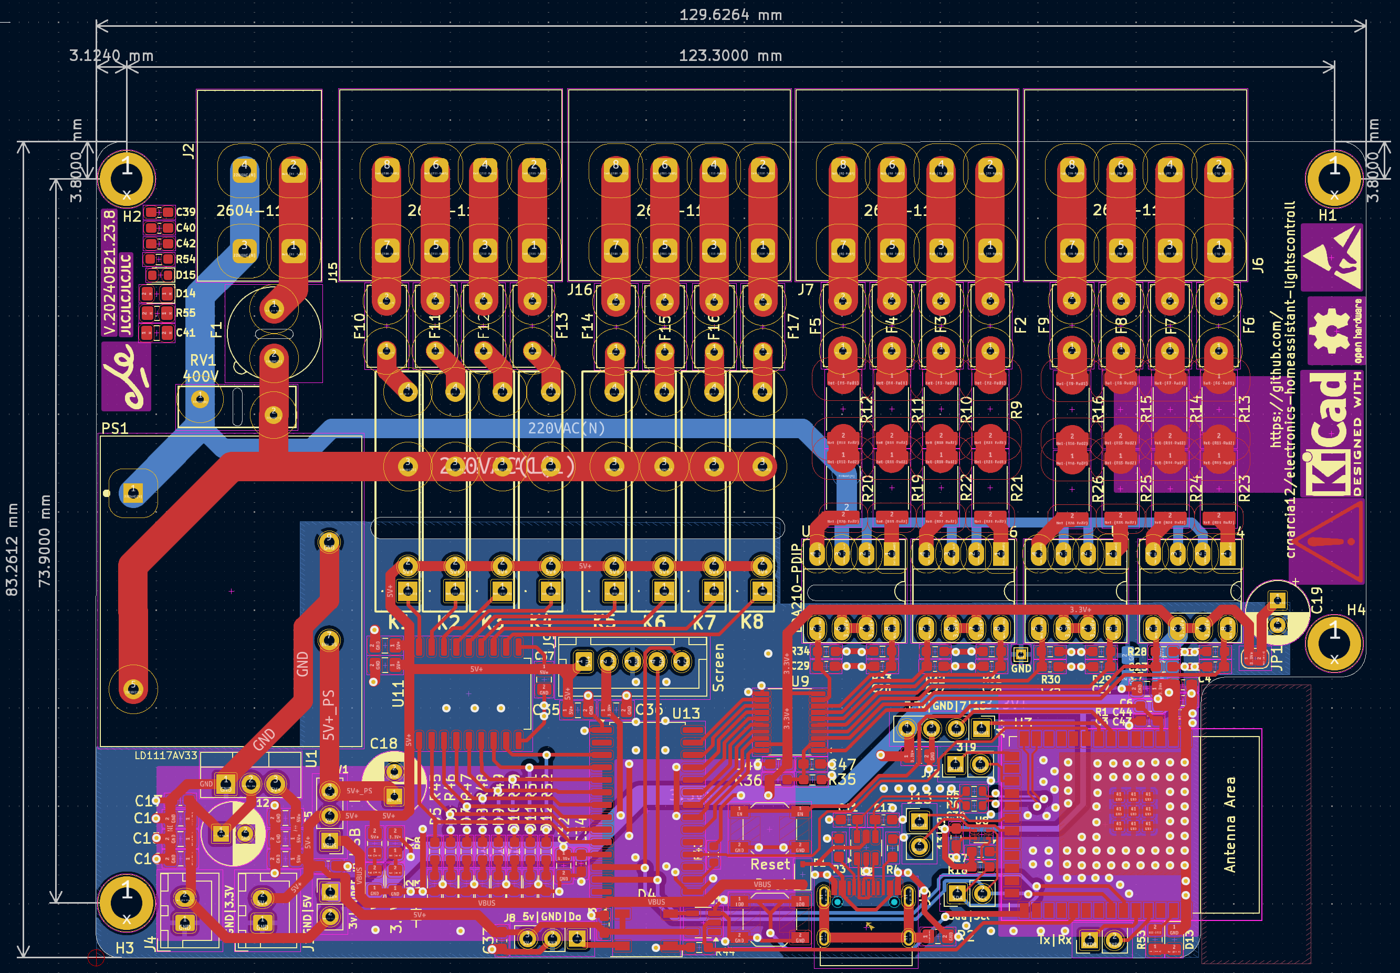
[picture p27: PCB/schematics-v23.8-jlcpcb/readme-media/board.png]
board-pcb

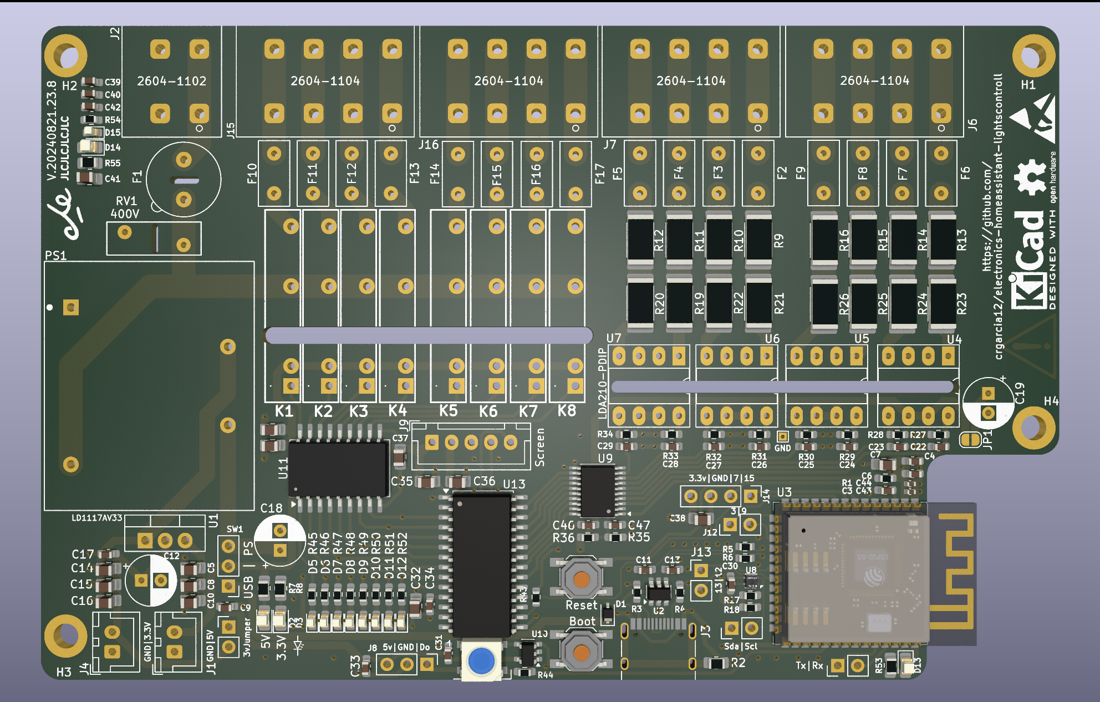
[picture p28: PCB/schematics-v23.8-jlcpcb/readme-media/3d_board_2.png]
board-pcb

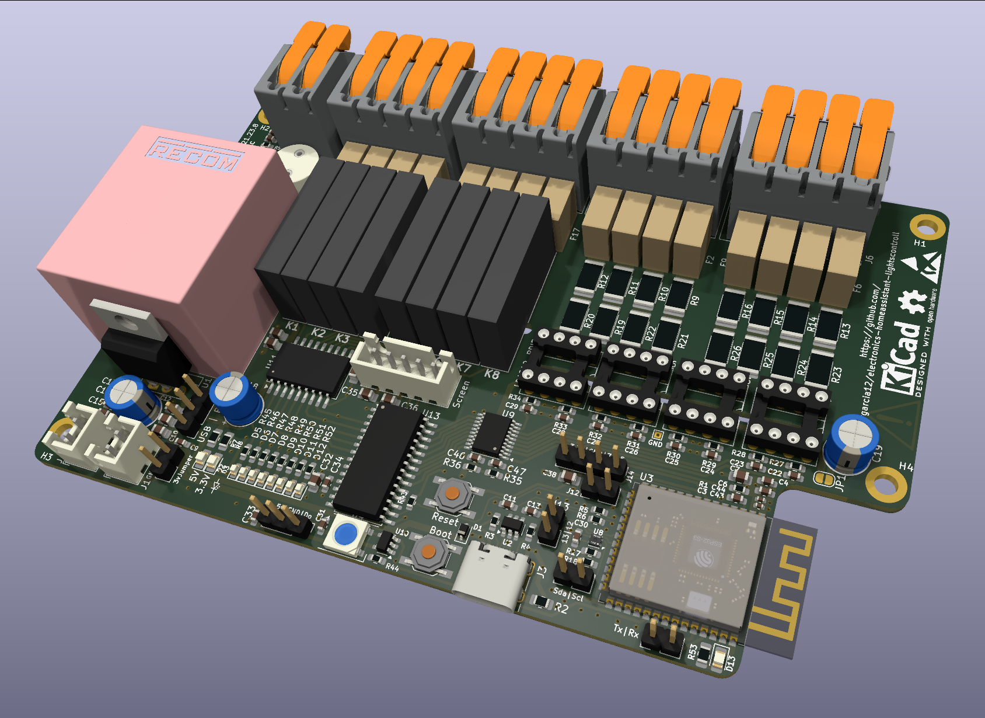
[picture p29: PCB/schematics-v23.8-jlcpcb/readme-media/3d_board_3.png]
board-pcb

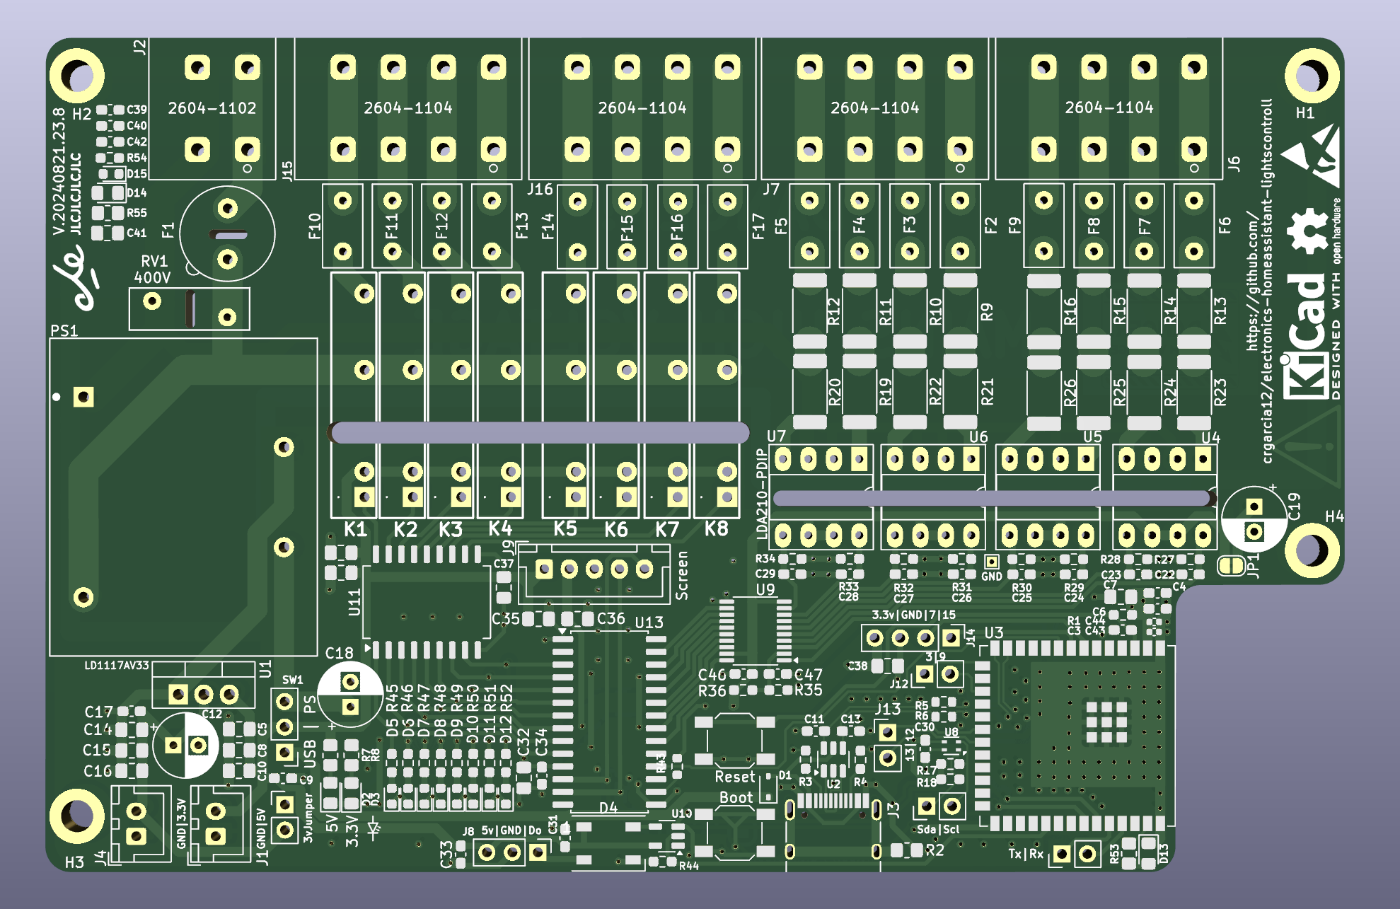
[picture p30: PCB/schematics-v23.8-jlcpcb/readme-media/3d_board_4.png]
board-pcb


### Older Versions: 22 - Four Channels
[Detailed information](PCB/schematics-v22-jlcpcb/)

**Changes since Version 17:**
- Cut-out ESP32 antenna area
- Moved silkscreen for better readability
- Improved schematic readability
- Added LEDs to indicate when relays are ON

board-schematics
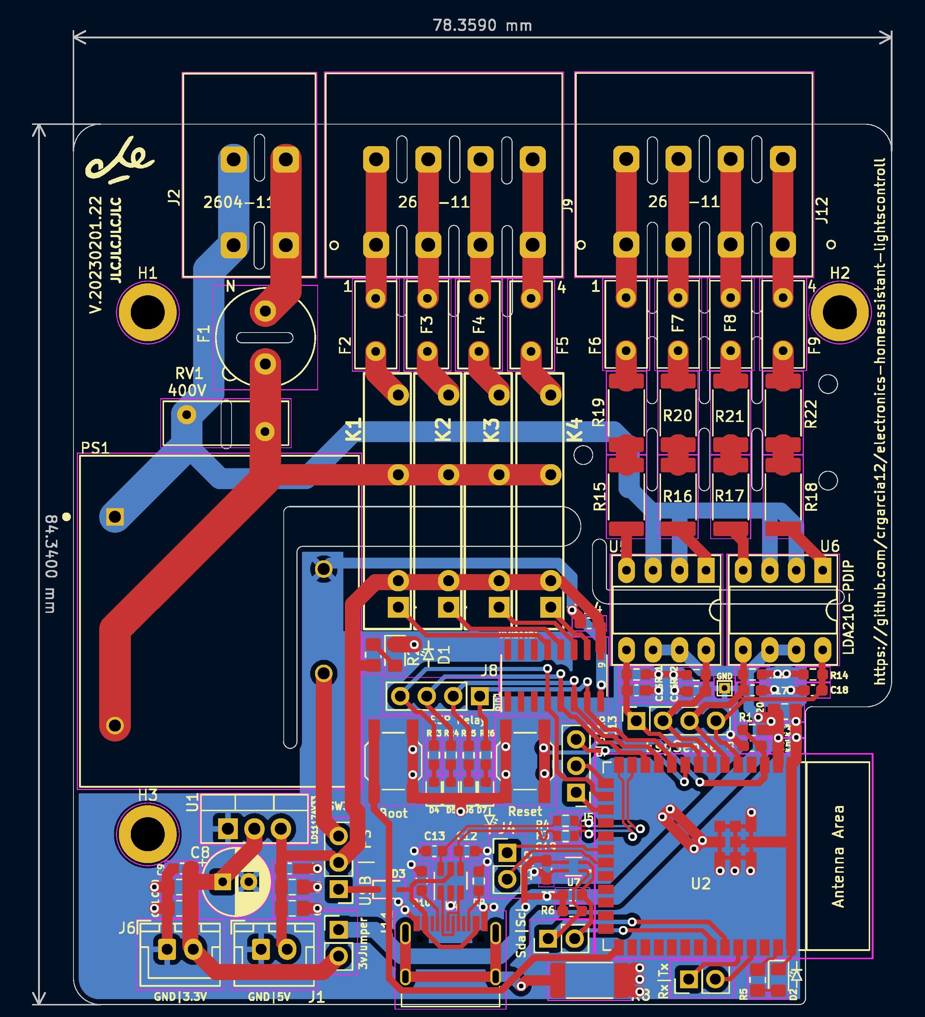
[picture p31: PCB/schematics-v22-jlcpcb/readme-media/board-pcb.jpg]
board-pcb

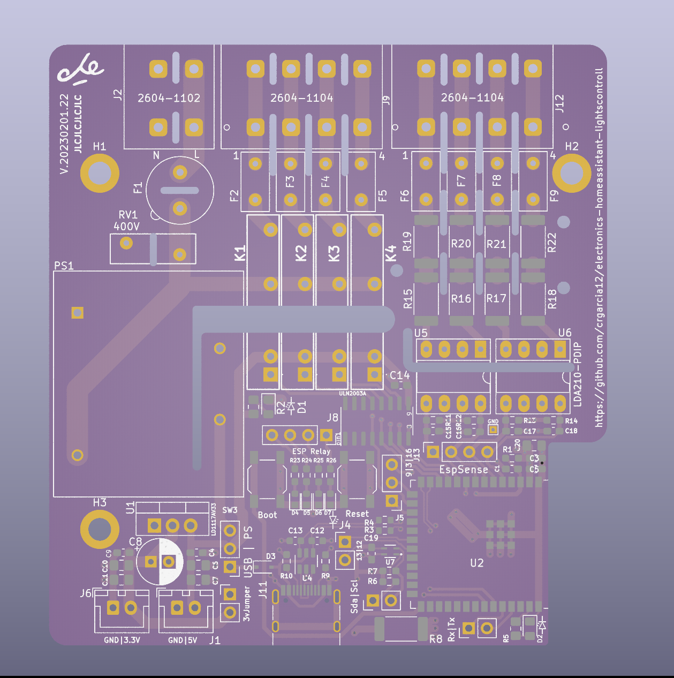
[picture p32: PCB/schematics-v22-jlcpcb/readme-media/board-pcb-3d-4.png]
board-pcb-3d

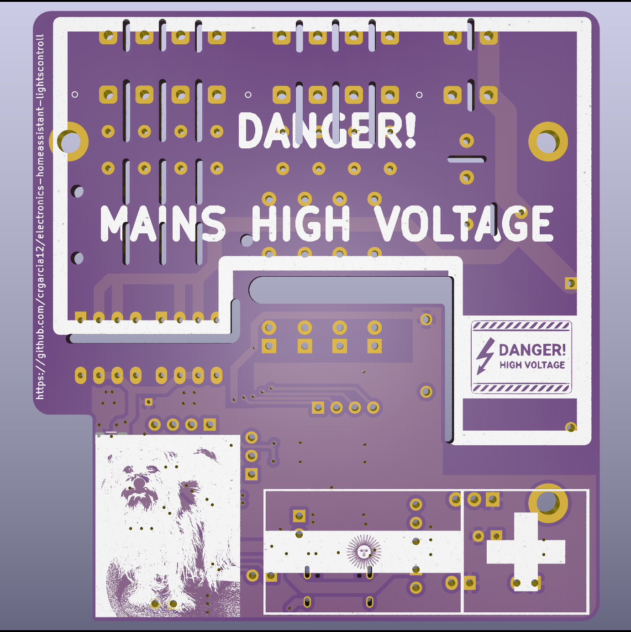
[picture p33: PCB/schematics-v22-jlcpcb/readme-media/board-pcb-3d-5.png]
board-pcb-3d

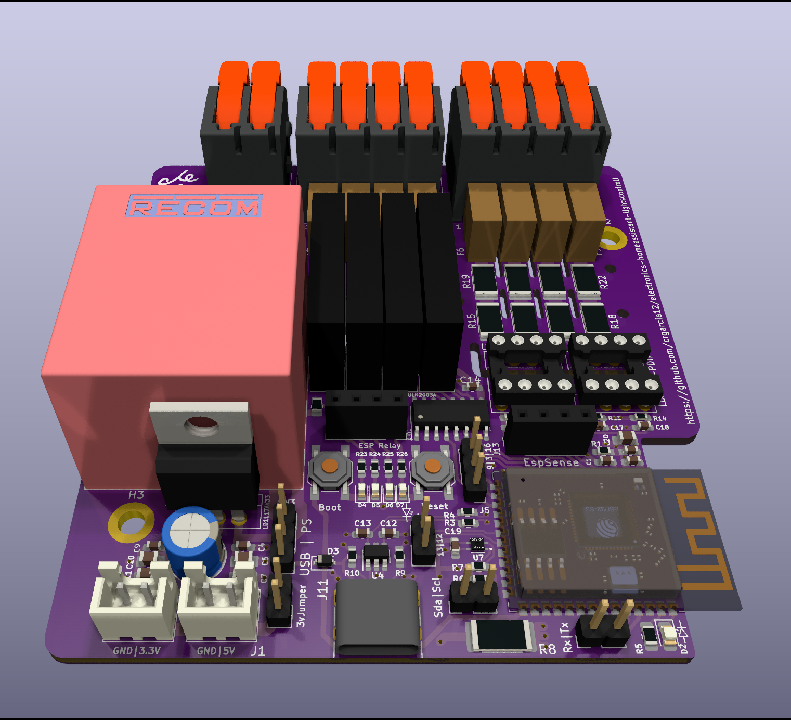
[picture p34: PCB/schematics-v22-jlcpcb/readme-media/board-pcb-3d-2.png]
board-pcb-3d

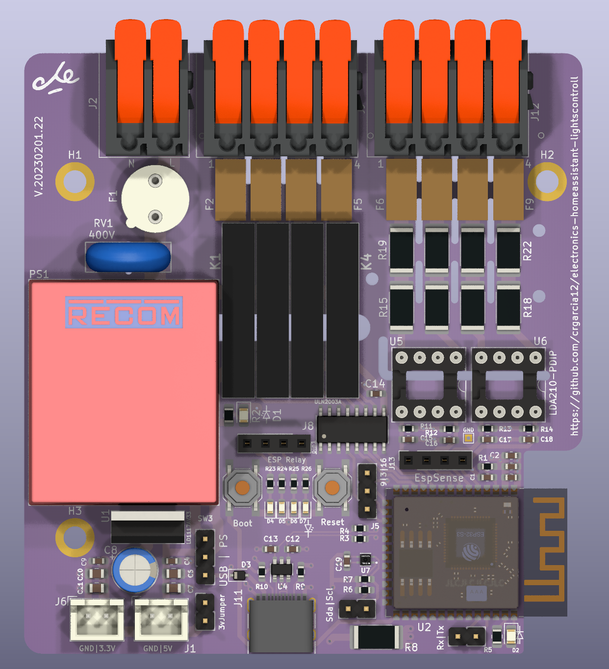
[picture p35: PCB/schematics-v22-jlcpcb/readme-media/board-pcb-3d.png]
board-pcb-3d

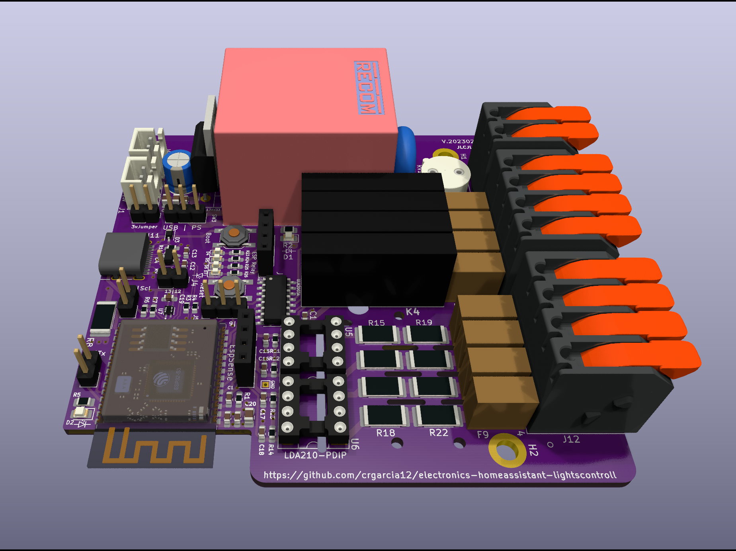
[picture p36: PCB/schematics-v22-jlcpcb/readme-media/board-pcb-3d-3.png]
board-pcb-3d

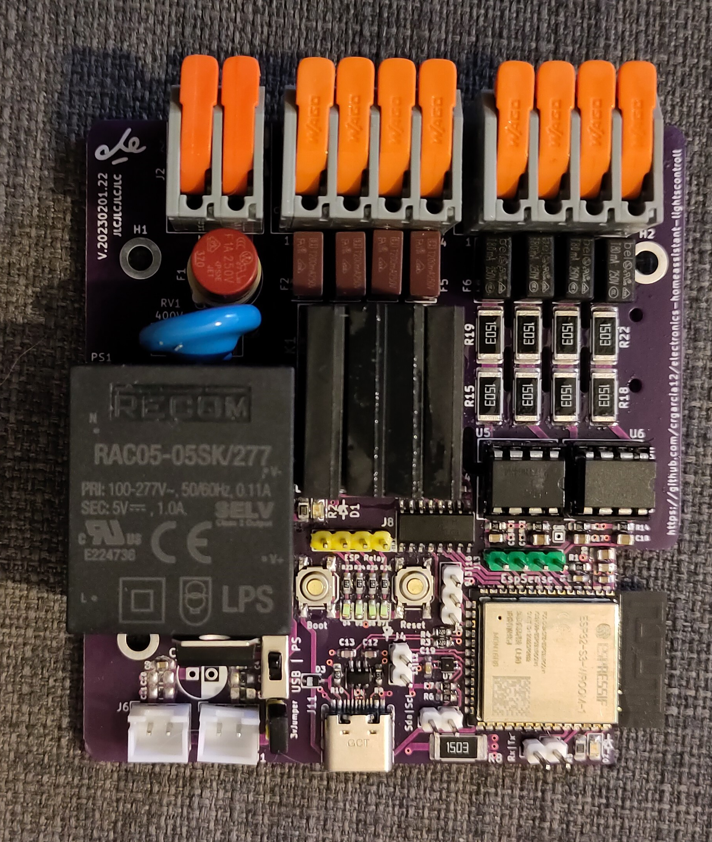
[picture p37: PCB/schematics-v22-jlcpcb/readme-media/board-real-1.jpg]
board-real-image

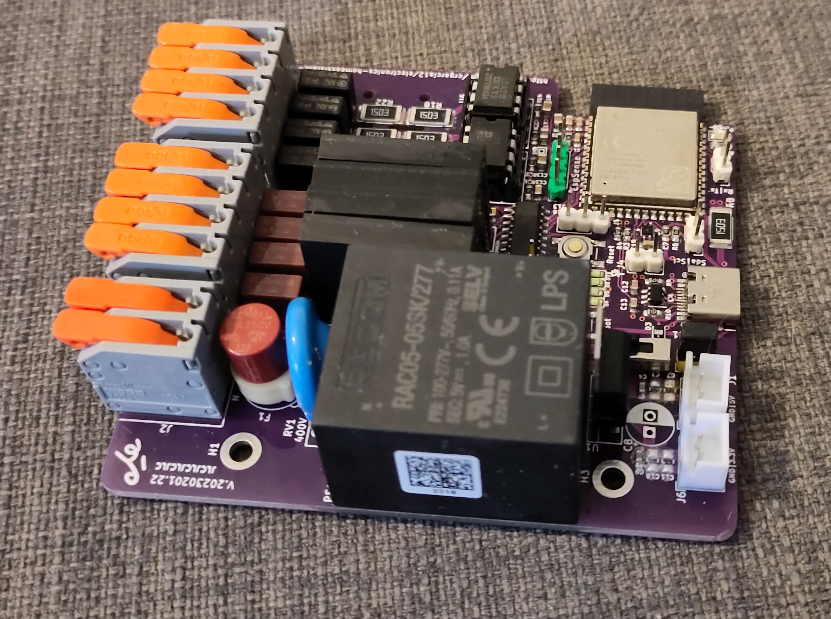
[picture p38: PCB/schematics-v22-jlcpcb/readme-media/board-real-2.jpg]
board-real-image

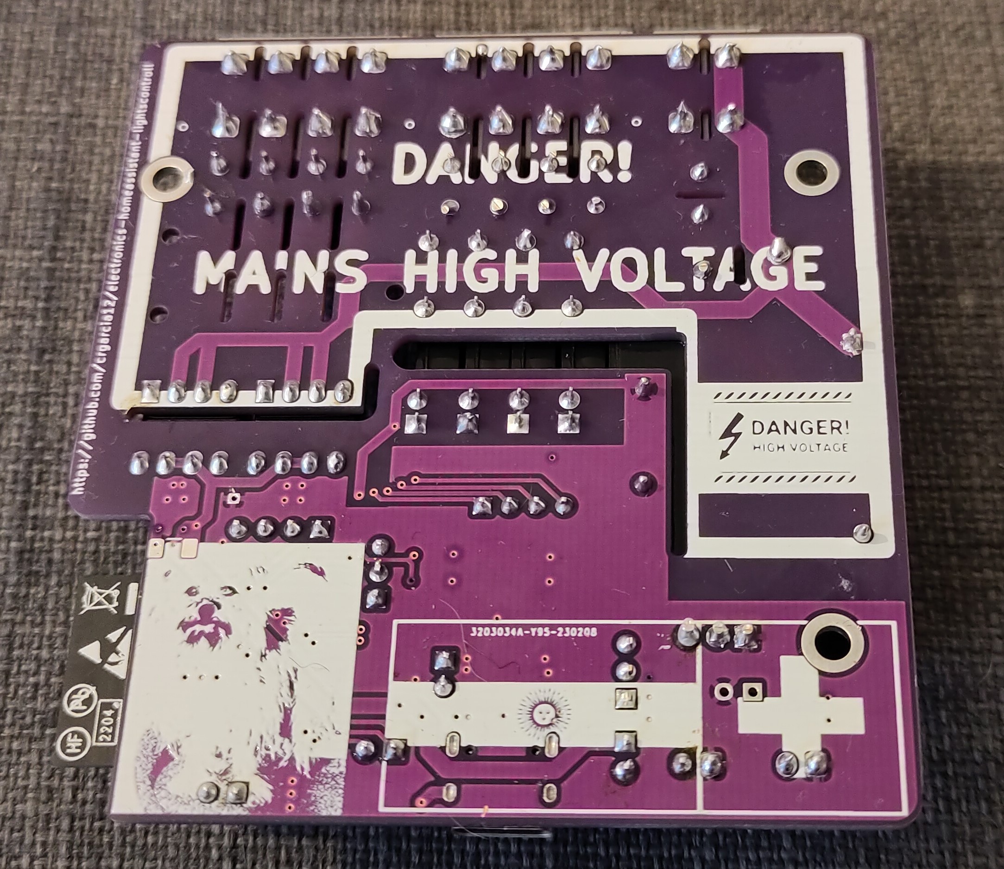
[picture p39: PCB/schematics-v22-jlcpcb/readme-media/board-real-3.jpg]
board-real-image

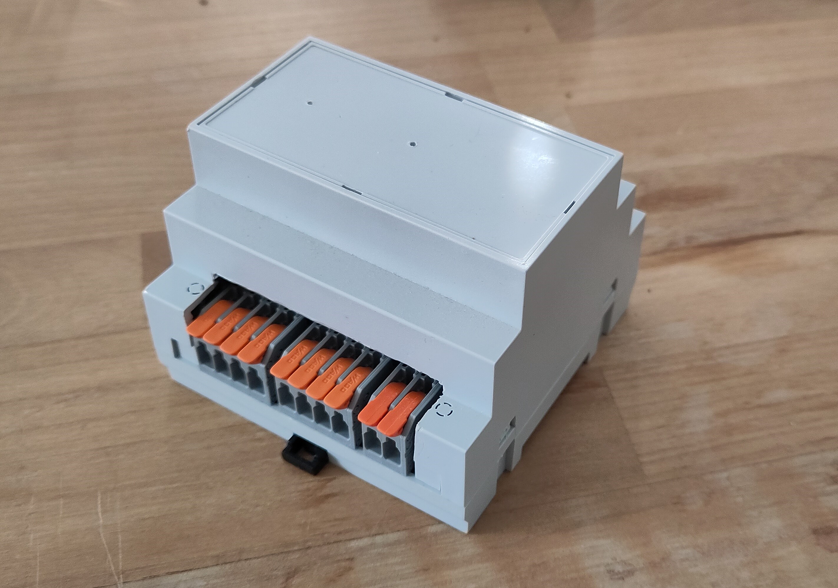
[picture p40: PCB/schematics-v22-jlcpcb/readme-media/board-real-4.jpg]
board-real-image


### Older Versions: 21

**Key Changes:**
- Using the new ESP32-S3 microcontroller
- Replaced CP2102 with ESP integrated USB support
- Replaced USB protection diodes with an IC

board-schematics
board-pcb
board-pcb-3d
board-pcb-3d
board-pcb-3d
board-pcb-3d

### Older Versions: 20
[Detailed information](PCB/schematics-v20-pcbway/)

**Changes since Version 17:**
- Mains sensing is inverted to make better use of rectifier capacitors and have constant reading
- Removed low-voltage fuse (having only one fuse is sufficient since PS has overcurrent protection and >4kV insulation)
- Moved screws - now has one extra holding point
- Exposed GPIO12 and GPIO33 for better board extensibility
- Moved to SSR with integrated snubber instead of mechanical relays (the kickback of the inductive load from latching relays was creating spikes and restarting the ESP32)
- Added SMD capacitors to the 3.3V and 5V lines for noisy conditions
- Separated GND for relays and ULN from the digital signal plane to reduce noise 

board-schematics
board-pcb
board-pcb-3d
board-pcb-3d
board-pcb-3d
board-pcb-3d

### Older Versions: 19
[Detailed information](PCB/schematics-v19-jlcpcb/)

**Changes since Version 17:**
- Added fuses to every relay output (protection in case two relays are closed simultaneously and one is accidentally wired to N - current could flow from one to the other)
- Moved SHT40 and extended the footprint for easier soldering
- Moved LD11 for easier fitting in the case
- Tested with both optocouplers: LDA210 and ILD755-D

board-schematics
board-pcb
board-pcb-3d
board-pcb-3d
board-pcb-3d
board-pcb-3d

### Older Versions: 17
[Detailed information](PCB/schematics-v17-safety-jlcpcb/)

**Major changes since Version 13:**
- Changed optocoupler to one with lower current requirements
- Changed resistors to 150kΩ × 2
- Added fuses to every sensing channel and removed fuse in N
- Added a separate fuse for 5V and 3.3V track
- Littlefuse now has a holder instead of being soldered directly to PCB
- Added ESP32 onboard module
- Added temperature sensor to detect if the board gets too hot
- Added USB-C powered by CP2102N UART chip
- Removed capacitors from 5V→3.3V converter to avoid inrush current at the USB
- Added external pull-up resistors for ESP32 (some pins do not have internal pull-ups)
- Added mains nets with proper creepage and clearance
- Replaced mains connectors with Wago lever connectors (super reliable and easy to use!)
- Replaced analog temperature sensor with SHT40 using I2C protocol
- Added I2C terminal so any I2C sensor can be plugged in
board-schematics
board-pcb
board-pcb-3d

board-pcb-3d

The enclosure compared with a DIN relay. Size is perfect :)
board-pcb-3d

### Older Versions: 16
Size comparison between V16 and V13:

board-pcb-3d

### Older Versions: 13

**Miniaturization improvements:**
- Using SPST-NO 3A smaller relays
- Using SMD 3W 29kΩ resistors instead of THT
- Removed external buttons connector
- Removed external LEDs connector
- Using SMD ULN2003A instead of THT
- HCPL3700 THT capacitors replaced by Tantalum SMD

**Security additions:**
- Added fuse at the neutral return from the sensors (F2)
- Resistors are placed before HCPL3700 to work with less than 4V to N instead of 110V to N

**Stability improvements:**
- Added filter capacitor to ULN2003A
- Added filter capacitors to LD1117AV33

**Other changes:**
- Added LED indicator when powered on

v2-board-schematics
v2-board-pcb
v2-board-pcb-3d
v2-board-pcb-3d

### Older Versions: 9

Early development version. 

v1-board-schematics
v1-board-pcb
v1-board-pcb-3d
v2-board-pcb-3d

### Older Versions: 1

Initial prototype version (included to show the evolution of the project). 

Version 1 board schematics
Version 1 PCB layout

---

## Contributing

Contributions are welcome! If you have improvements, bug fixes, or new features to propose:

1. Fork the repository
2. Create a feature branch (`git checkout -b feature/your-feature`)
3. Make your changes
4. Test thoroughly (especially if working with mains voltage)
5. Submit a pull request with a clear description of your changes

**Please note:** Any contributions involving electrical safety must be thoroughly tested and documented.

## Safety Disclaimer

⚠️ **WARNING**: This device works with mains voltage which can be lethal. Only qualified electricians should install, modify, or work on this device. The authors assume no liability for any damage, injury, or death resulting from the use of this device. Use at your own risk.

## License

This project is open source. Please check the repository for specific license information.

---

## Support

For questions, issues, or discussions:
- Open an issue on GitHub
- Review existing issues and documentation
- Check the ESPHome and Home Assistant communities for integration help

---

**Project maintained by the community. Star ⭐ this repository if you find it useful!**

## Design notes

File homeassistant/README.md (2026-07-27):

# Home Assistant setup

Copy `homeassistant/lightcontrol-dashboard.yaml` to
`/config/lightcontrol-dashboard.yaml`, then add an additional YAML dashboard:

```yaml
lovelace:
  dashboards:
    lightcontrol-dashboard:
      mode: yaml
      title: LightControl
      icon: mdi:home-lightbulb
      show_in_sidebar: true
      filename: lightcontrol-dashboard.yaml
```

Restart Home Assistant after changing `configuration.yaml`.

## What it does

- MQTT discovery exposes the controller switches, firmware update entities, update-check buttons,
  diagnostics, and sensors.
- The dashboard creates one collapsed Online/Offline summary per discovered controller. Expanding
  it shows every switch, update entity, and sensor belonging to that device. New controllers appear
  automatically.
- The dashboard publishes `UPDATE` to `home/lightcontrol/all/firmware/update`.
- **Check for updates in all controllers** publishes `CHECK` to
  `home/lightcontrol/all/firmware/check`, waking each
  online controller's release task immediately.
- Each device keeps its own `update.lightcontrol_*_firmware` entity for individual updates.
- Identity diagnostics include the configured device name, room, board model, and channel count.

## Dashboard dependency

This dashboard uses two HACS frontend cards:

- `custom:auto-entities` to discover controllers and their entities automatically.
- `custom:expander-card` to keep each controller collapsed until its details are needed.

Install **Auto Entities** and **Expander Card** from **HACS → Frontend**.

## Update flow

1. Press a controller's **Check for updates** button, or
   **Check for updates in all controllers** for the fleet.
2. Use an individual `update.lightcontrol_*_firmware` entity for one controller.
3. Test that controller.
4. Use **Update all controllers** to publish the global MQTT update command.

While an update runs, the update entity reports that installation is in progress and the expanded
controller card's **Firmware status** sensor moves through `scheduled`, `checking release`,
`downloading N%`, and `restarting`. A failure is retained there with its ESP-IDF error.

The RGB LED rapidly blinks purple throughout the update. After installation, the controller reboots,
alternates blue and green while reconnecting, and turns the RGB LED off when WiFi and MQTT are healthy.
The update that first installs this behavior cannot blink purple because the previous firmware performs
that download. The separate active-high status LED on GPIO1 stays off and emits one brief pulse whenever
an MQTT message is published or received.

The global command is not retained, so offline controllers do not unexpectedly update later.
Online controllers wait a random 0-30 seconds before downloading to avoid a download spike.

## Release versions

The firmware release workflow builds `firmware/lightcontrol` with ESP-IDF `v5.3.1`.

Firmware versions are stable numeric `MAJOR.MINOR.PATCH` values without a prefix or suffix:

- `1.0.1`
- `1.0.2`
- `1.0.3`

Push a numeric tag to publish a stable release. You can also run the workflow manually with an
existing numeric tag. Controllers ignore drafts, prereleases, and tags that do not exactly match
the numeric version format.

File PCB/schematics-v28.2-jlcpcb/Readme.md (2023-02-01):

 # Home automation led controller custom module

 This circuit controll home lights following these rules:
 1. Safe: Safety is not trade in any decision.
 1. Fail safe: If this device fails, the ligts are still controllable using the mechanical switches.
 1. Follows standard instalation: This device does not require you to wire your house for it.
 1. It can be installed centrally

The circuit is placed close to the mains switching box, next to the latching relays. Wiring: 



A normal circuit sends all push buttons to the latching relay, which controlls the lights.
This circuit (ESPHome) is a side-car to the latching relay acting as an standard push button, but also sensing the output of the latching relay to detect if the lights are on or off.

# Changes in this version

* Using ESP32-S3-WROOM-2
* Using internal USB port
* Exposing a third GPIO (3,9,16)
* Changed USB protections by USBLC6-2SC6

# Device schematics

board-schematics

# PCB images

Solder mask color: #54006ED4

board-pcb
board-pcb-3d-4
board-pcb-3d
board-pcb-3d-2
board-pcb-3d-2

# Clearance
There are three nets: Default, Mains-LowVoltage and Mains. Even when conformal coating is added, Clearance are calculated without it for added safety. In practice, instead of using A7, A6 is being used to do the calculations:

* Default: Low voltage - 0.2mm
* Mains-LowVoltage: A6 < 2V = 0.13. For added safety 0.8 mm is used (red) 
* Mains: A6 for > 300V = 1.5mm (green)

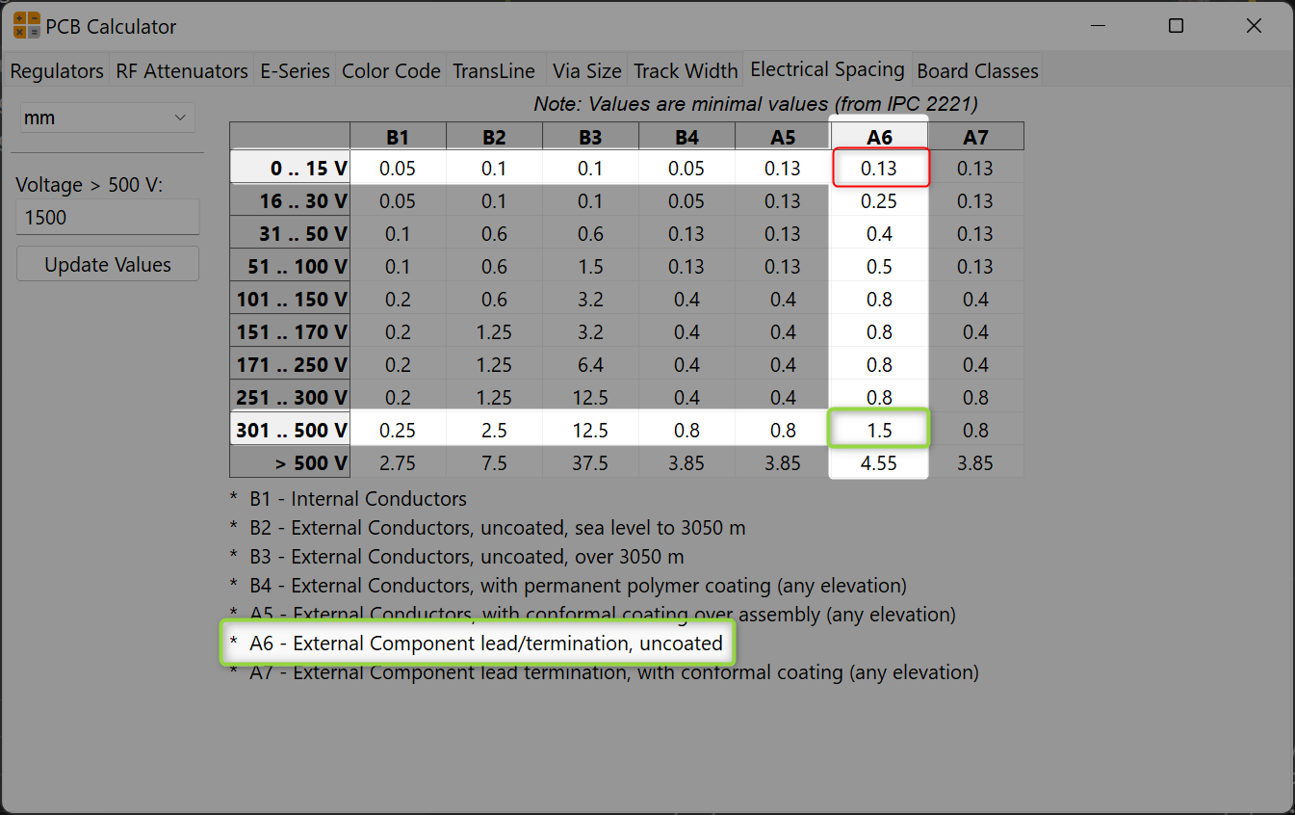
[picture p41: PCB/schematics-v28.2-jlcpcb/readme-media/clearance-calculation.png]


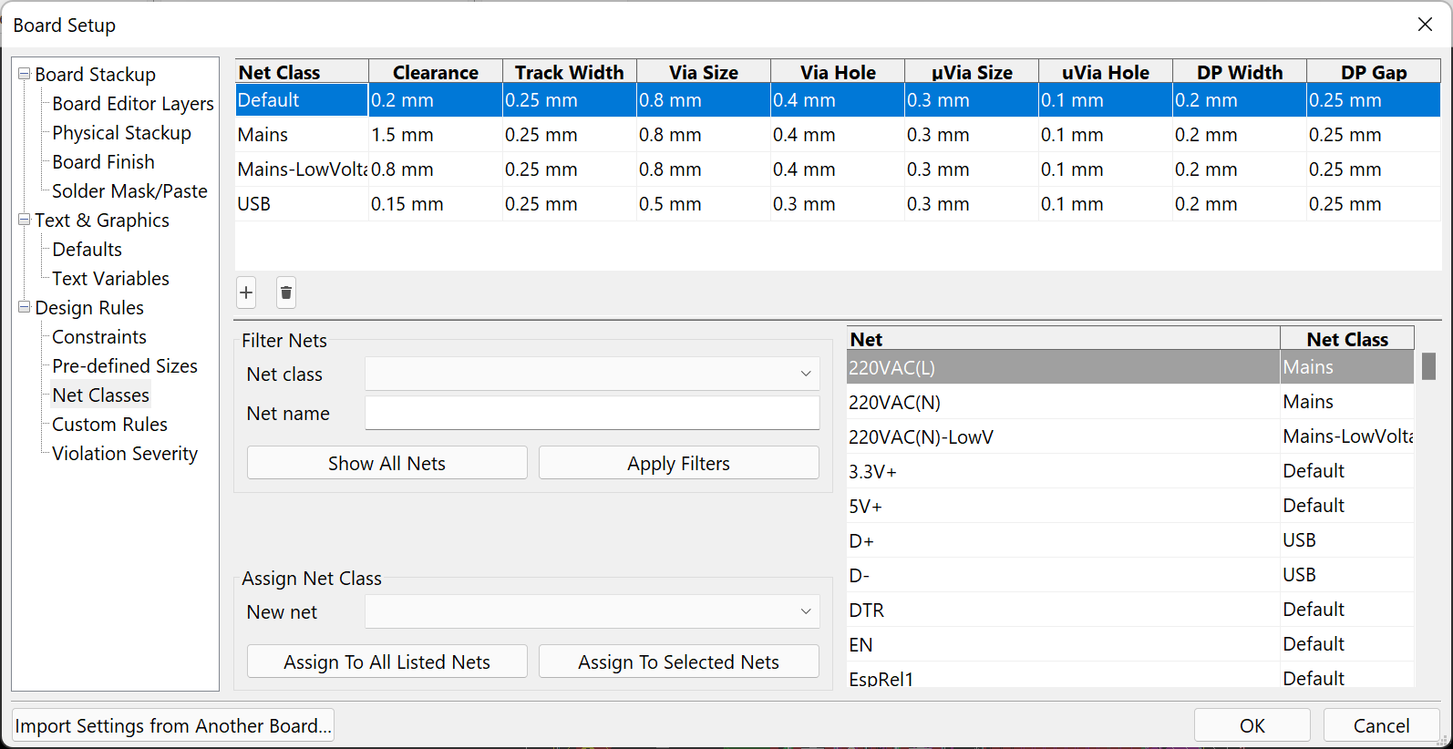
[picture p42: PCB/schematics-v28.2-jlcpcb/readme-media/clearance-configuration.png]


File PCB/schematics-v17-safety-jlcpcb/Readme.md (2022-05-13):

 # Home automation led controller custom module v17 (printed PCB V20220221.35)

 This circuit controll home lights following these rules:
 1. Safe: Safety is not trade in any decision.
 1. Fail safe: If this device fails, the ligts are still controllable using the mechanical switches.
 1. Follows standard instalation: This device does not require you to wire your house for it.
 1. It can be installed centrally

The circuit is placed close to the mains switching box, next to the latching relays. Wiring: 

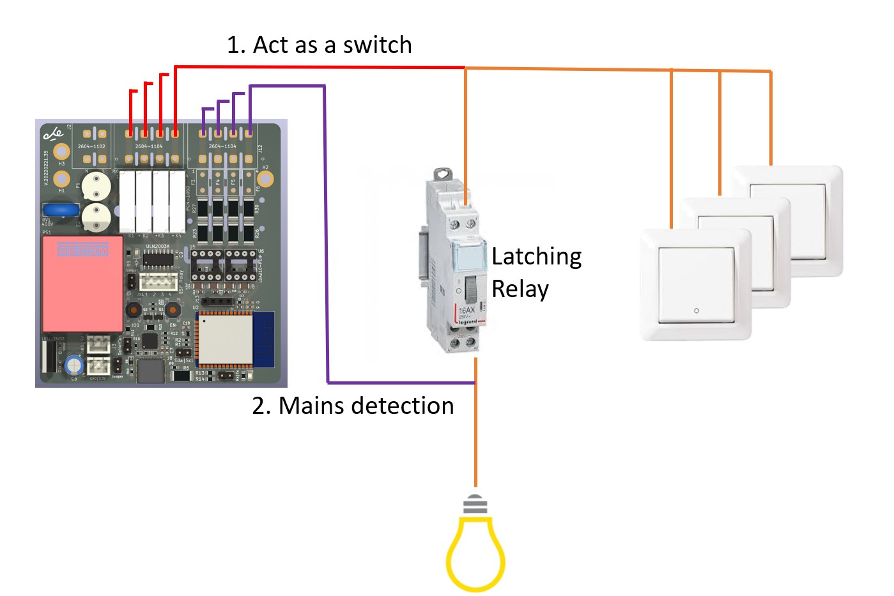
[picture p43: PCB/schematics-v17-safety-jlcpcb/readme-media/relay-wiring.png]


A normal circuit sends all push buttons to the latching relay, which controlls the lights.
This circuit (ESPHome) is a side-car to the latching relay acting as an standard push button, but also sensing the output of the latching relay to detect if the lights are on or off.

# Changes in this version

This version adds:
* USB-C support
* I2C temperature IC. To alert in case the board get hot
* Debugging pins for I2C and Serial
* Led to ESP32 pin
* Fix bug: ESP32 cannot pull up on all pins - adding external pull-ups resistors

Security additions:
* Added fuses to every sensing channel
* Added littlefuse holders, for easier replacing of fuses
* Increased net clearance
* Routed mains N far from digital area
* Redesigned safety slots
* Production board is conformal coated with a silicone resin Electrolube SCC3

# Device schematics

board-schematics
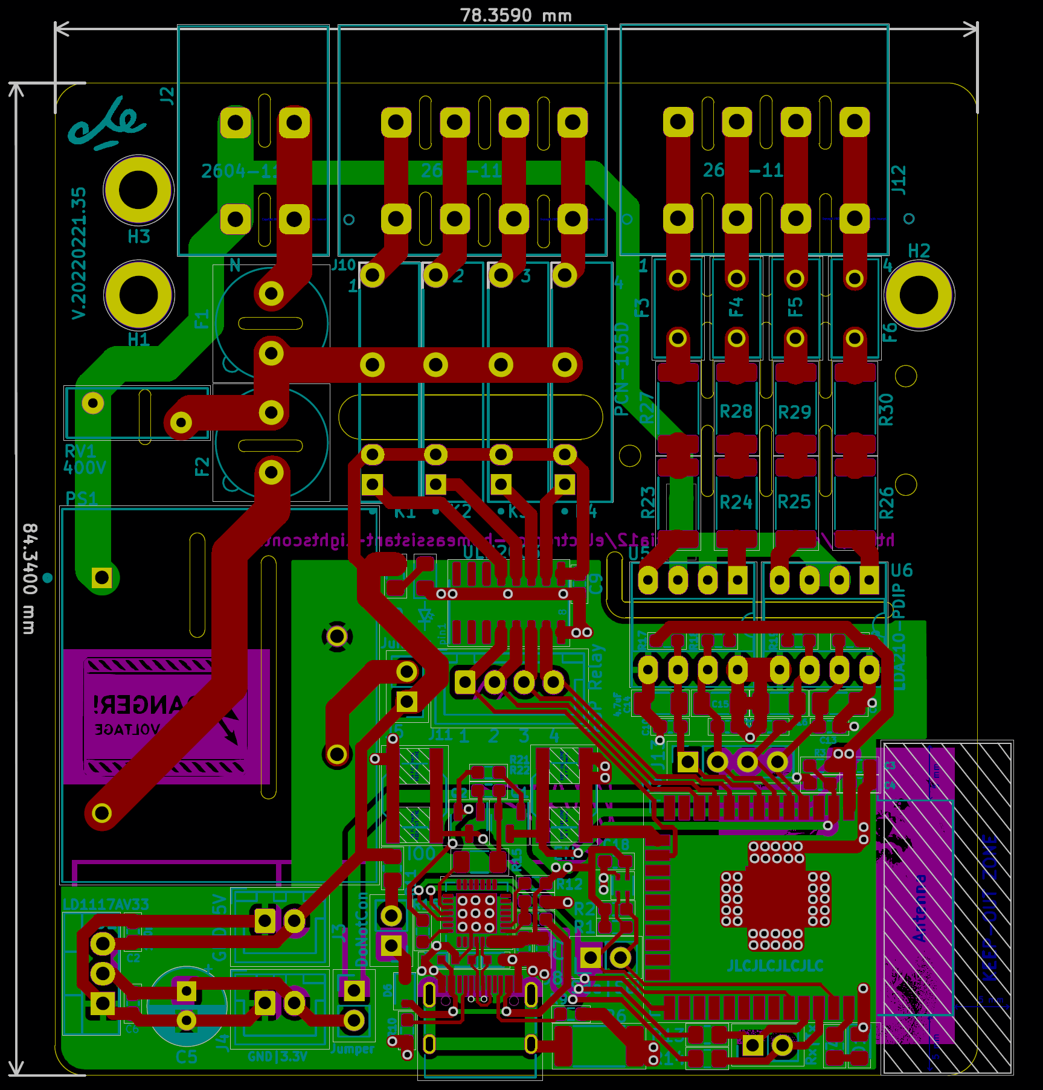
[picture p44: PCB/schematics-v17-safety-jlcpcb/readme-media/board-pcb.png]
board-pcb

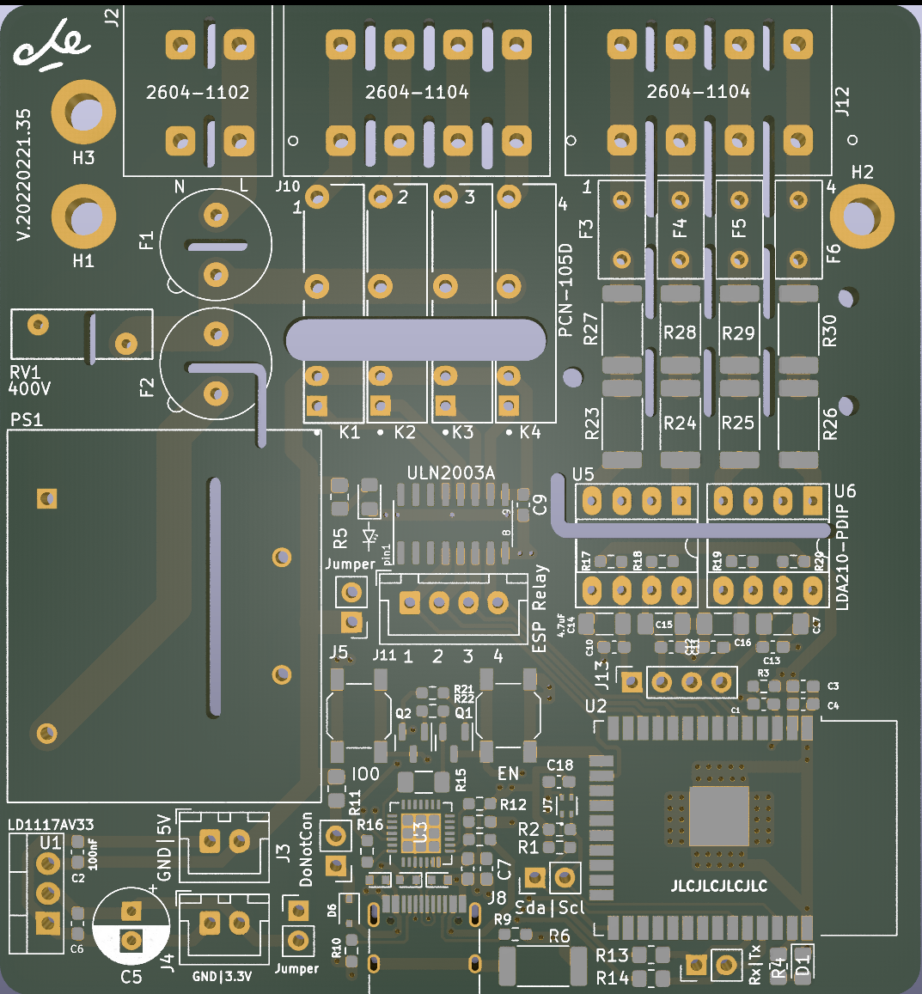
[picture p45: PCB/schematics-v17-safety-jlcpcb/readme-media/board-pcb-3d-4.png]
board-pcb-3d-4

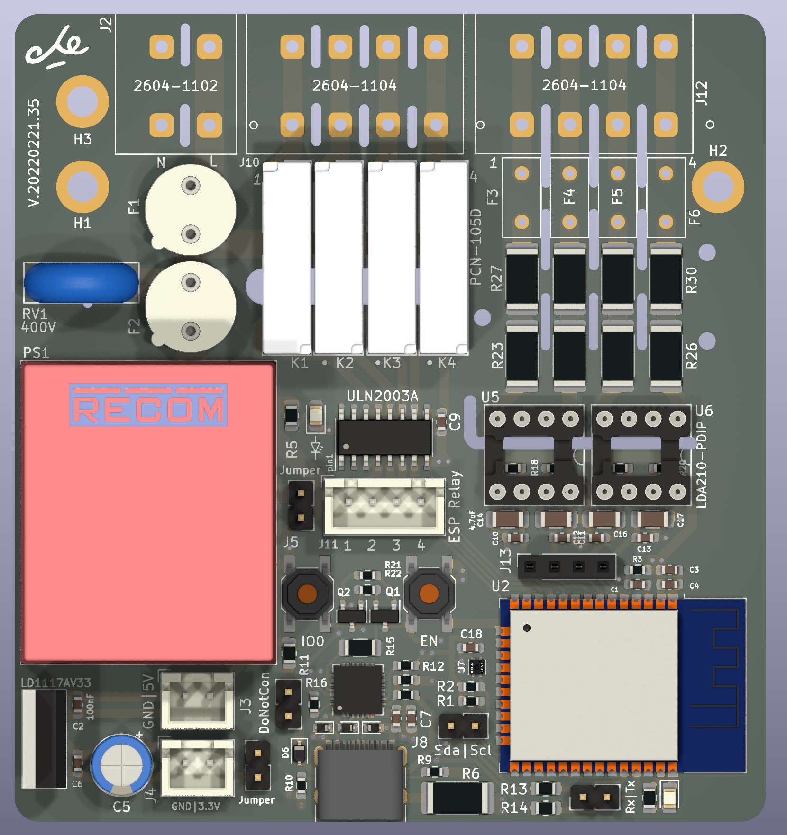
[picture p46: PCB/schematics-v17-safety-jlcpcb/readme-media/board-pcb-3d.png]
board-pcb-3d

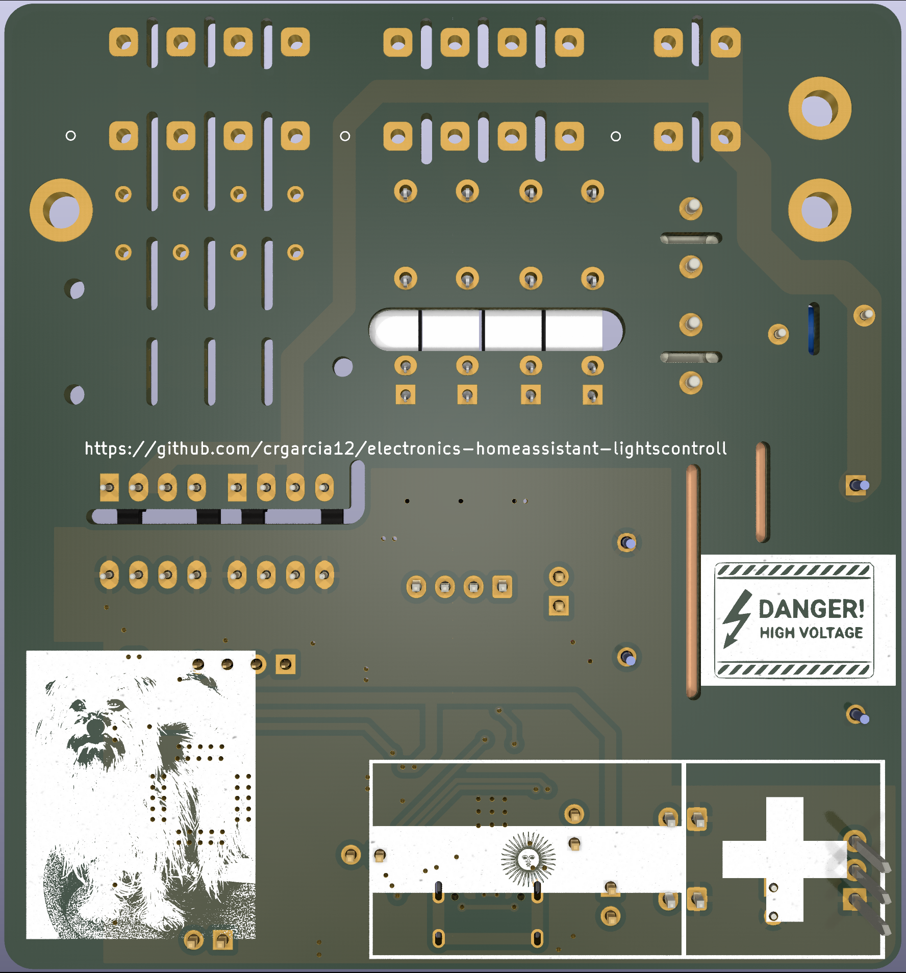
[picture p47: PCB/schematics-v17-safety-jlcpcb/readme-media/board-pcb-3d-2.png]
board-pcb-3d-2

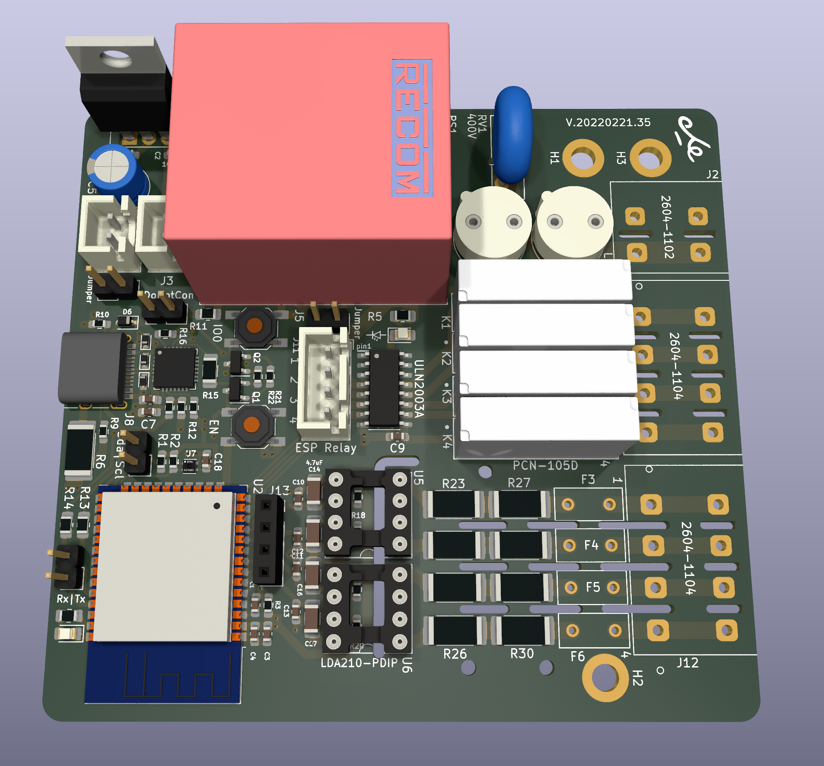
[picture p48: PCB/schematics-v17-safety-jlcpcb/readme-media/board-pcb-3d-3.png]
board-pcb-3d-2


# Clearance

There are three nets: Default, Mains-LowVoltage and Mains. Even when conformal coating is added, Clearance are calculated without it for added safety. In practice, instead of using A7, A6 is being used to do the calculations:

* Default: Low voltage - 0.2mm
* Mains-LowVoltage: A6 < 2V = 0.13. For added safety 0.8 mm is used (red) 
* Mains: A6 for > 300V = 1.5mm (green)

board-pcb-3d-2

board-pcb-3d-2

# Development notes

## Generating fabrication files for JLCPCB
1. Plot PCB Gerber + Drill + Map:

    
    

1. Bom files
    
    

    Command: python3 "C:\Program Files\KiCad\bin\scripting\plugins/bom_csv_jlcpcb.py" "%I" "%O.csv"
    

1. Drill files
    
    
    run the python script to rotate the components
    

    PS C:\\...\smt-assembly> python3 .\kicad-to-jlcpcb-pos.py .\hamodule-top-pos.csv .\hamodule-top-pos-jlcpcb.csv

## Generate documents

schematics:


PCBNew:

Print to PDF, and then use an online tool to get high resolution images. For example https://pdfshelter.com/pdf-to-jpg

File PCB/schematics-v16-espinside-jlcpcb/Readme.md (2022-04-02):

 # Home automation led controller custom module

 This circuit controll home lights following these rules:
 1. Safe: Safety is not trade in any decision.
 1. Fail safe: If this device fails, the ligts are still controllable using the mechanical switches.
 1. Follows standard instalation: This device does not require you to wire your house for it.
 1. It can be installed centrally

The circuit is placed close to the mains switching box, next to the latching relays. Wiring: 

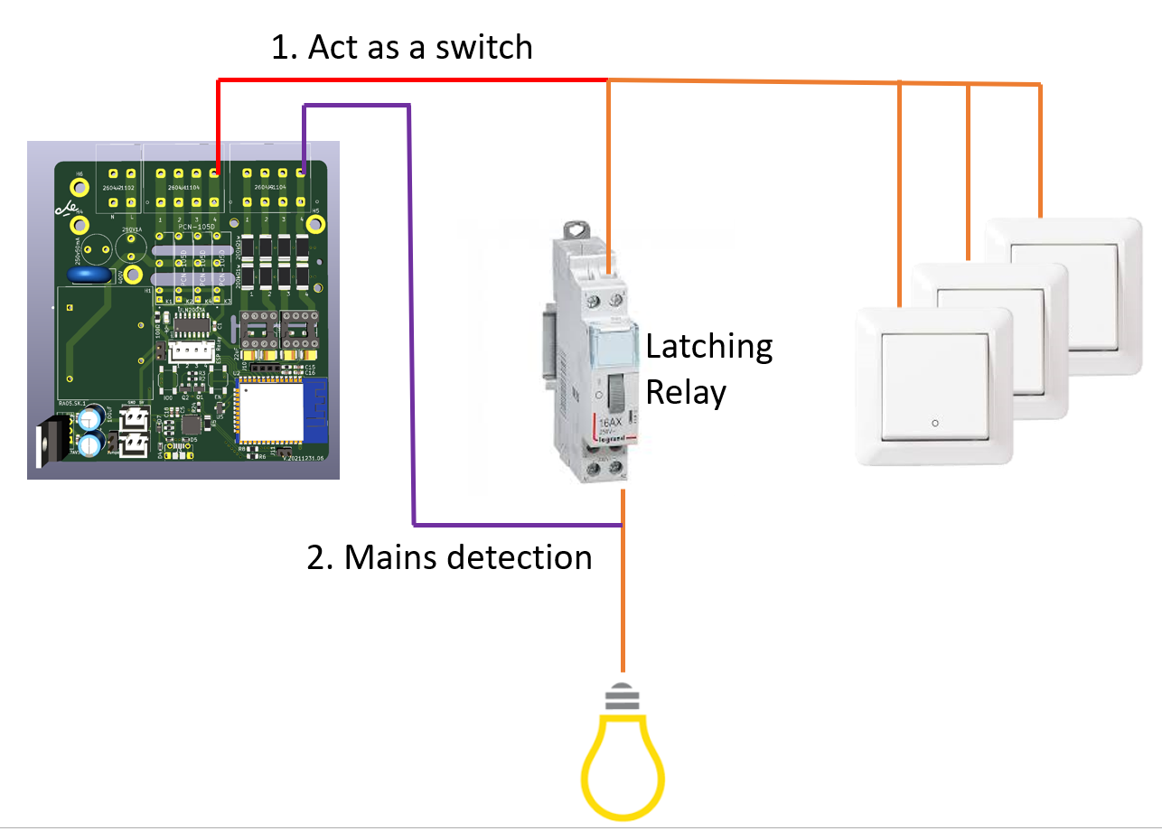
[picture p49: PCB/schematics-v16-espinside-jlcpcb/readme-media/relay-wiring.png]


A normal circuit sends all push buttons to the latching relay, which controlls the lights.
This circuit (ESPHome) is a side-car to the latching relay acting as an standard push button, but also sensing the output of the latching relay to detect if the lights are on or off.

# Changes in this version

This version was minimized by:
* Using SPST-NO 3A smaller relays
* Using SMD 3W 200k resistors instead of THT
* Removed external buttons connector
* Removed external leds connector
* Using SMD ULN2003A instead of THT
* Optocoupler THT capacitors replaced by Tantalum SMD
* Using bidirectional optocoupler (LDA210) instead of HCPL3700 to reduce Power dissipation (less current needed)
* Embedding an ESP32 into the board, and adding USB-to-Serial circuitery with CP2102N

Security additions:
* Added fuse at the neutral return from the sensors (F2)
* Resistors are before optocoupler, to make them work with less than 2V to N, instead of 110V to N

Stability:
* Added filter capacitor to ULN2003A
* Added filter capacitors to LD1117AV33

Others:
* Added led indicator when powered-on

Device schematics (under development) 

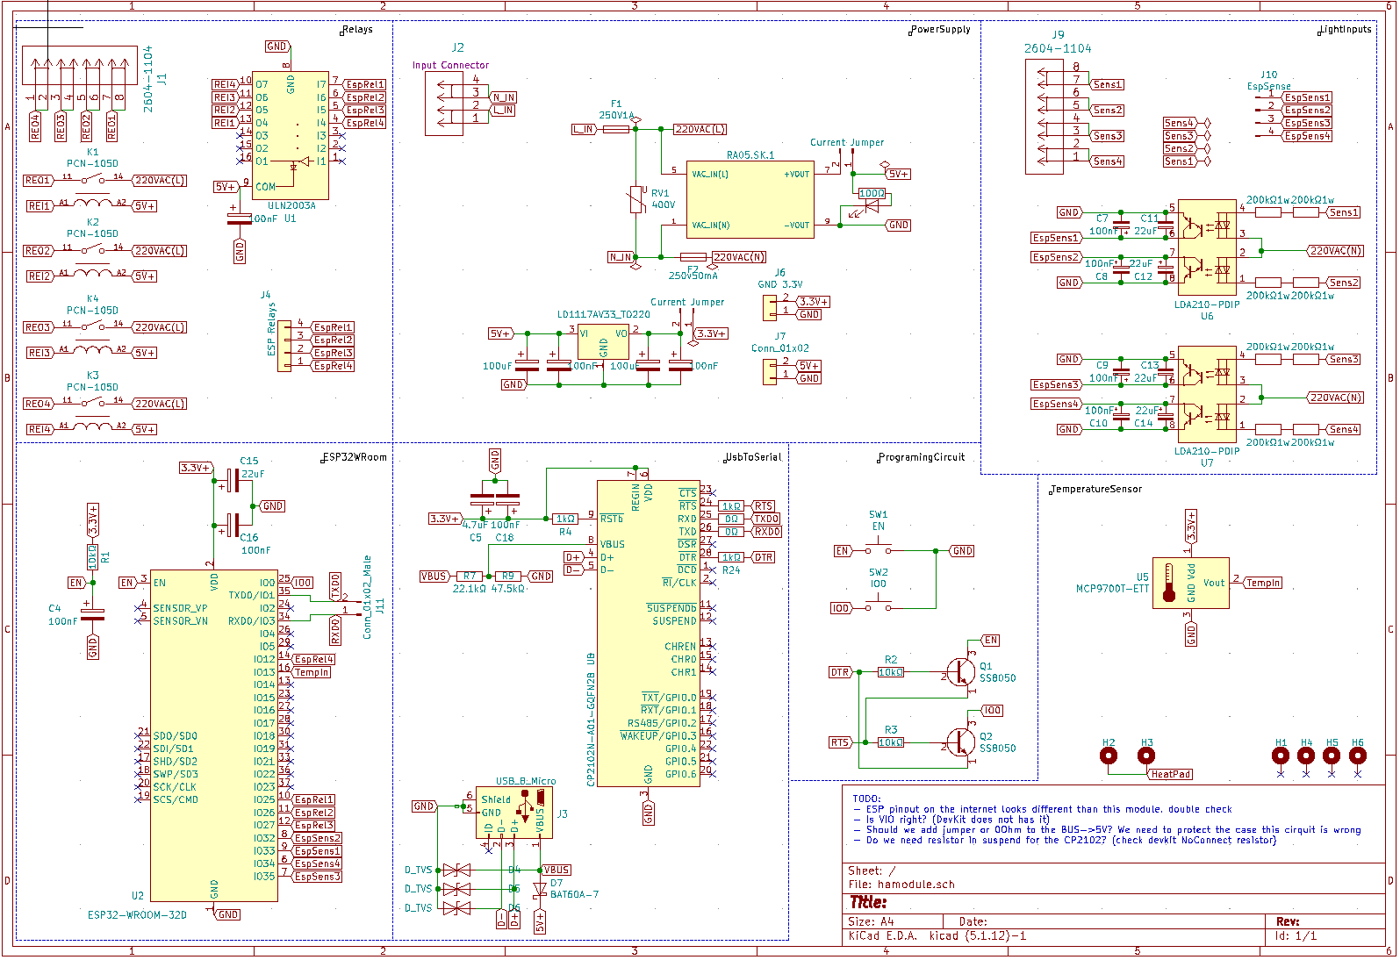
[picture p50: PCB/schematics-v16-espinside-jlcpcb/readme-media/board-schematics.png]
board-schematics

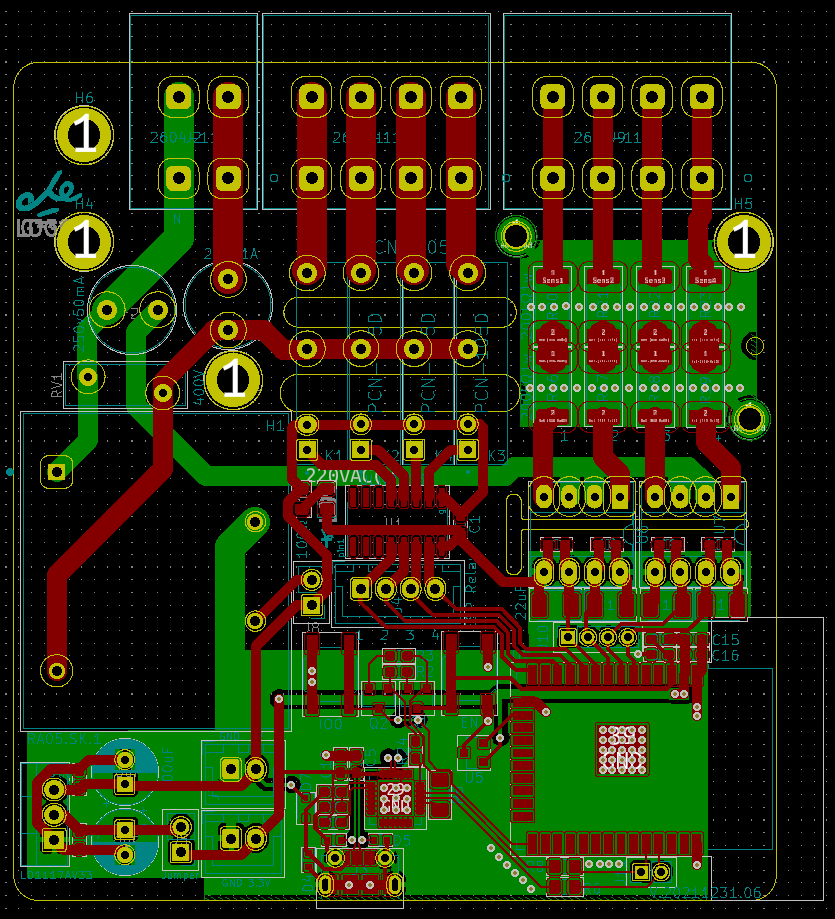
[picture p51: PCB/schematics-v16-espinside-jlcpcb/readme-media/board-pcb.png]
board-pcb

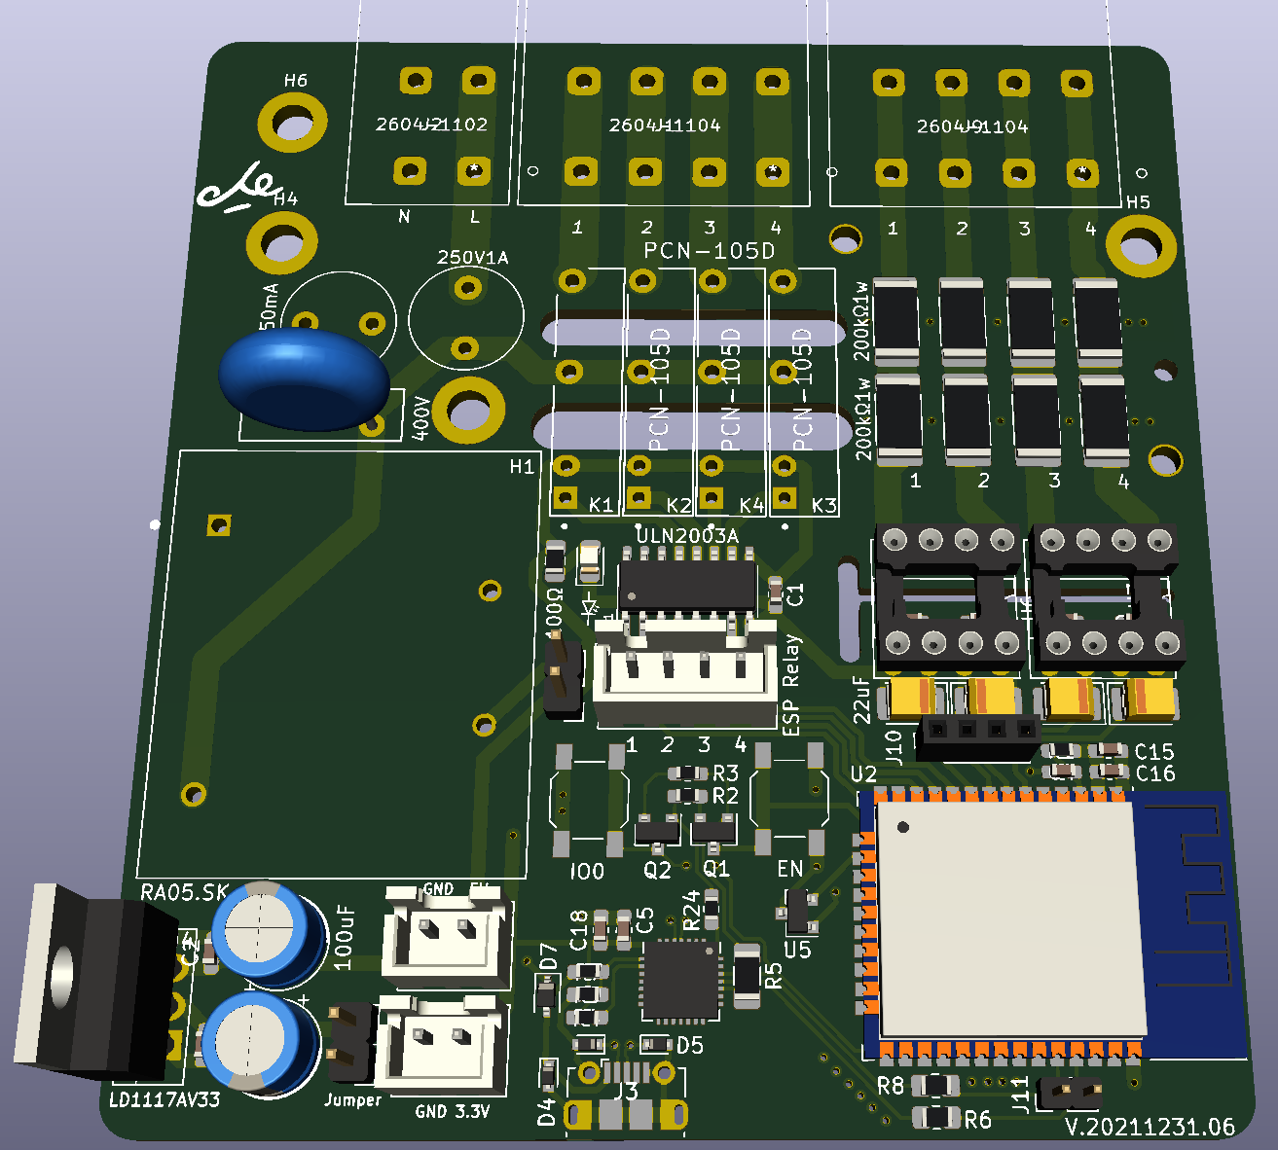
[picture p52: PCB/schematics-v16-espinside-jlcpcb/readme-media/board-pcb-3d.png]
board-pcb-3d

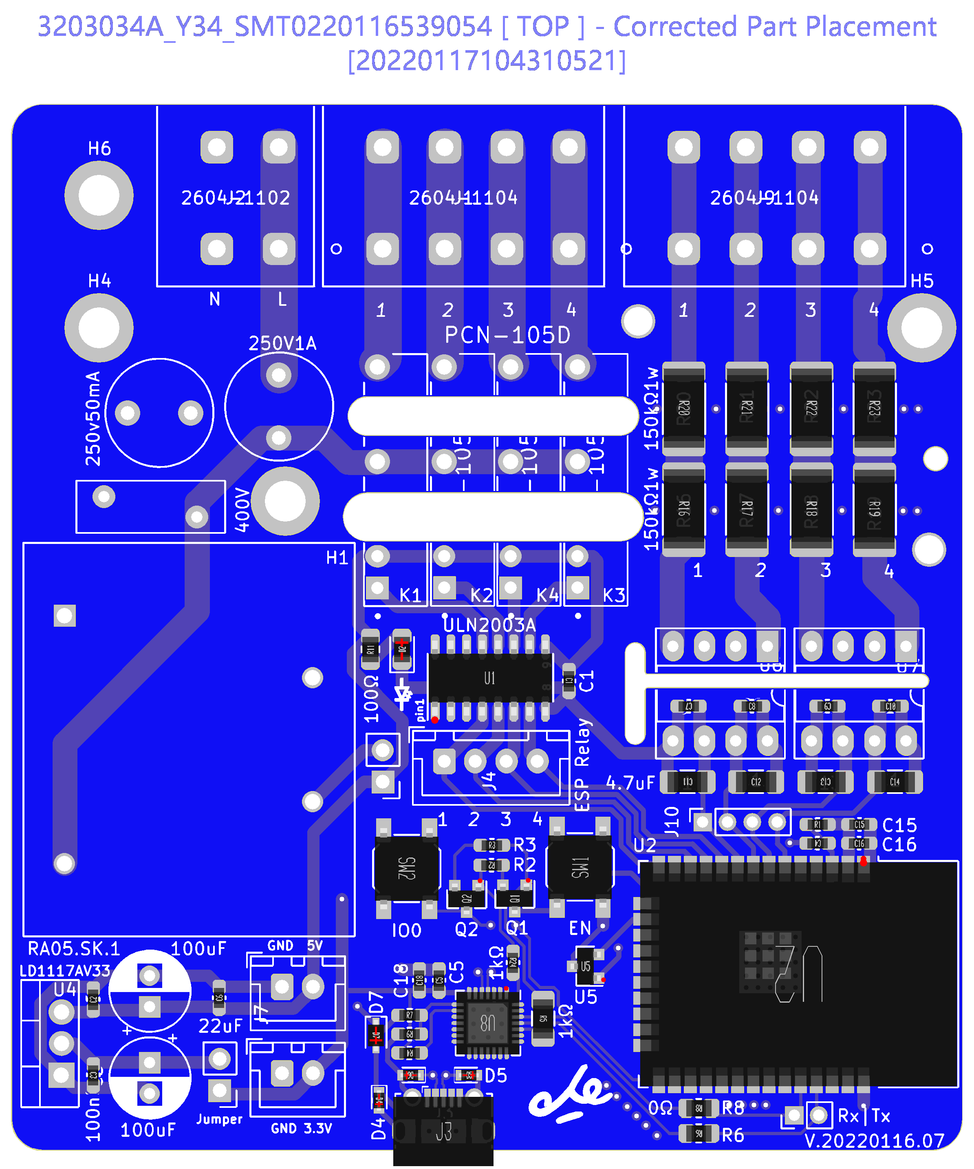
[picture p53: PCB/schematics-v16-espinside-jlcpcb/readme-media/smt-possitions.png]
board-smt-pos

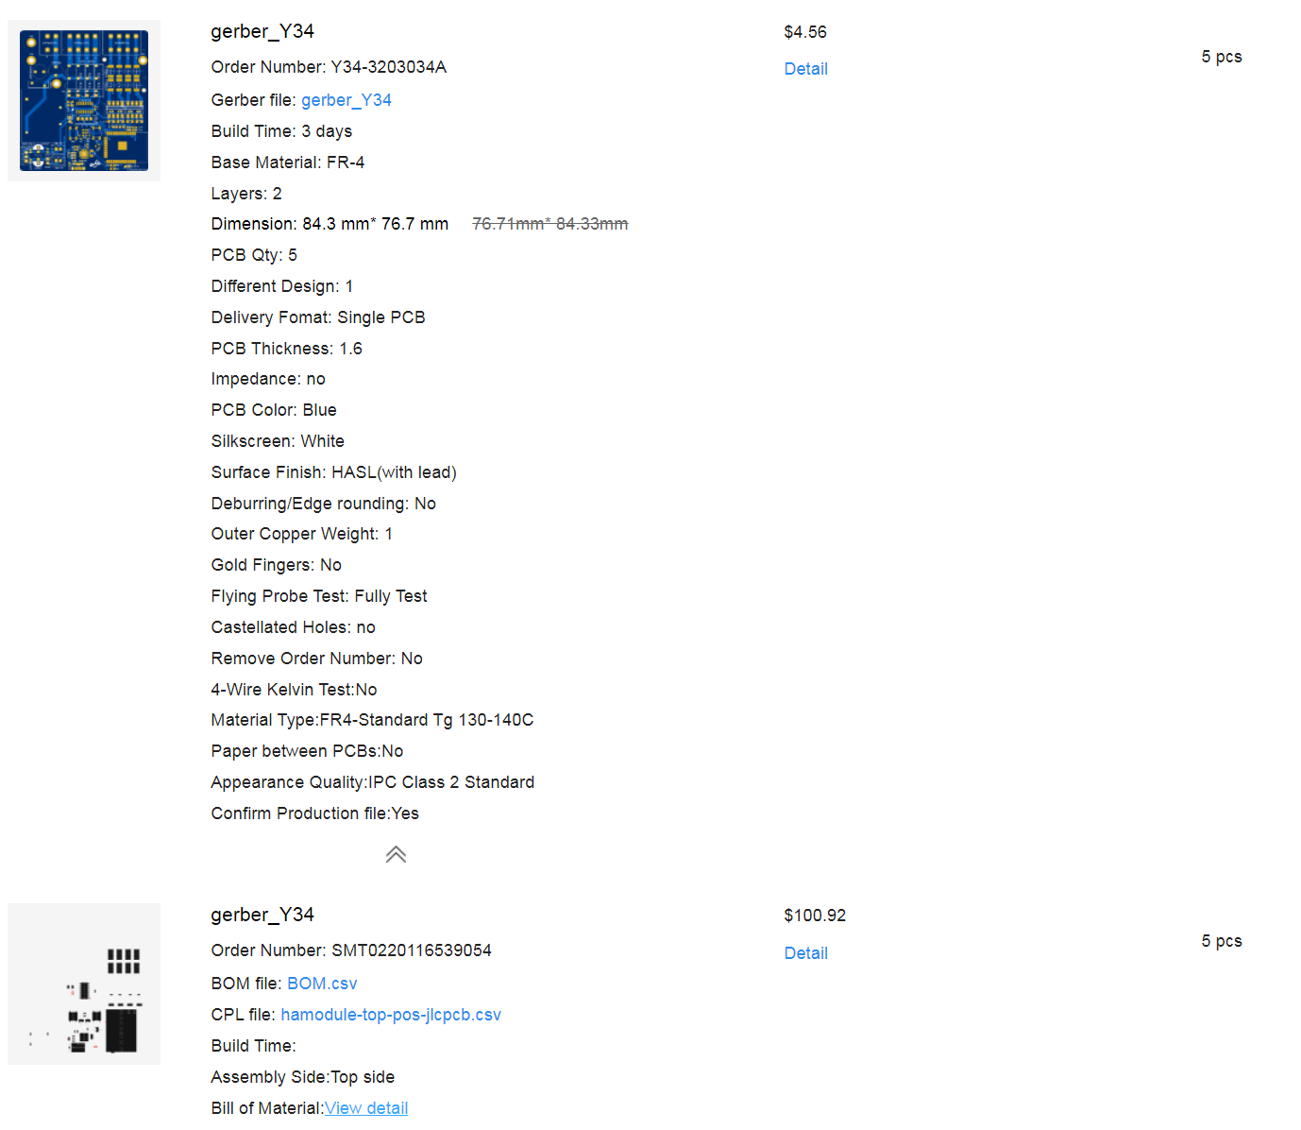
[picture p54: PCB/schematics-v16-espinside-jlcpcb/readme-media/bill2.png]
board-bill-1

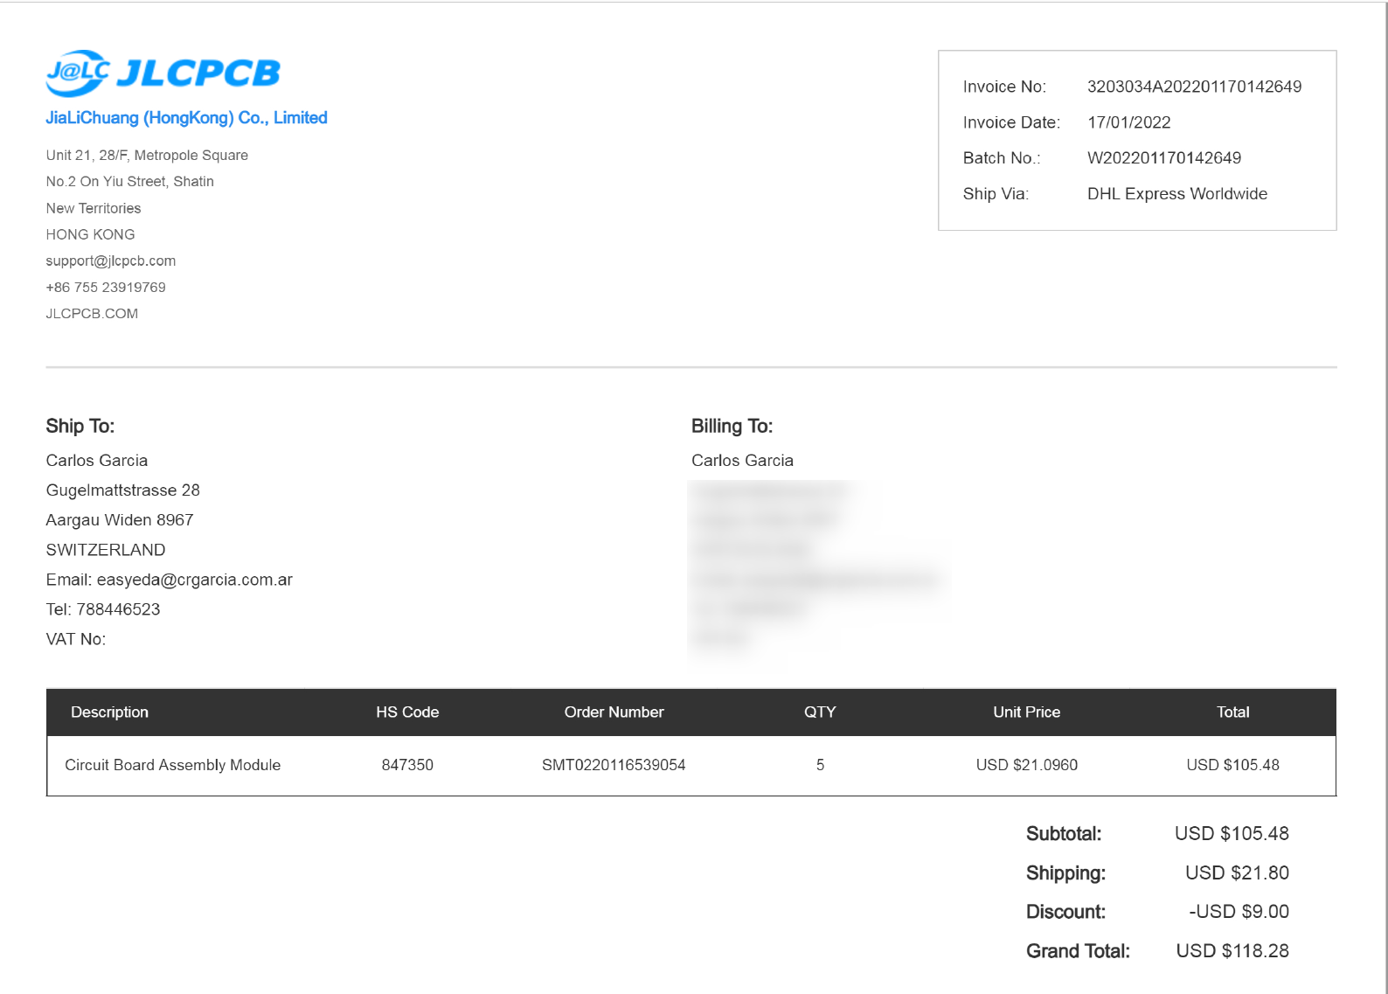
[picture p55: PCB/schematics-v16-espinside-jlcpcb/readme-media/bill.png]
board-bill-2

# Development notes

Generating fabrication files for JLCPCB
1. Plot PCB Gerber + Drill + Map:

    board-pcb-3d
    board-pcb-3d

1. Bom files
    board-pcb-3d
    board-pcb-3d
    board-pcb-3d

1. Drill files
    board-pcb-3d
    board-pcb-3d
    run the python script to rotate the components
    board-pcb-3d

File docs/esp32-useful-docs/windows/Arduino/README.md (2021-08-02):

If you want to use the Arduino IDE from Windows:

Check the usb-serial CHIP. It is usually CP2102.  
Install the CP22102 driver: https://www.silabs.com/developers/usb-to-uart-bridge-vcp-drivers

From arduino, the GPIO pin Nr is the green nr in this schematic:
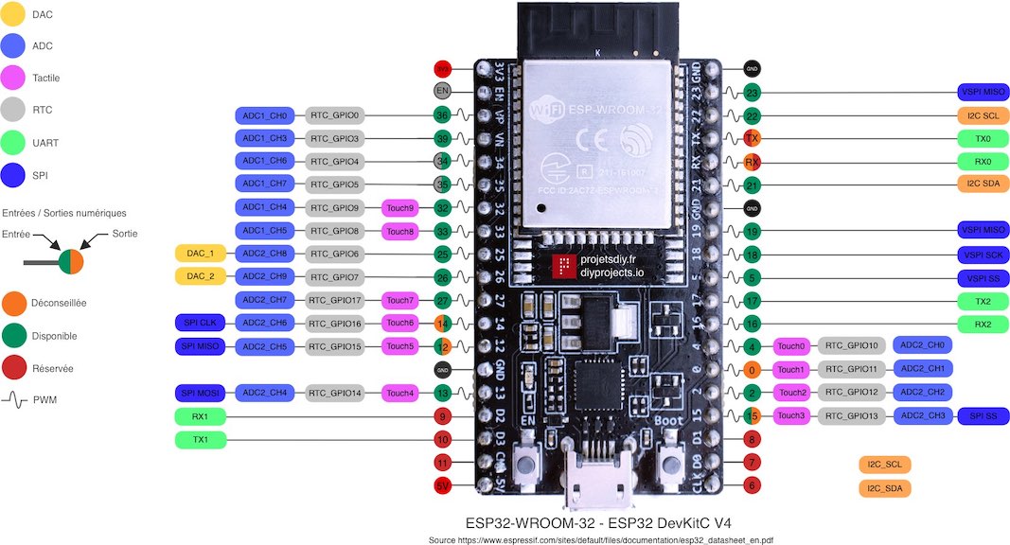
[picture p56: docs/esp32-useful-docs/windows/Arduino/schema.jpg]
ESP32 schematics

[source](https://diyprojects.io/esp32-gpio-pins-and-associated-functions-i-o-pwm-rtc-i2c-spi-adc-dac/#.YQghro4zZm8)

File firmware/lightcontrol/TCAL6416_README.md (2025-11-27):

# ESP32-S3 I2C Master with TCAL6416 I/O Expander

This project configures an ESP32-S3 microcontroller as an I2C master to communicate with a TCAL6416 16-bit I/O expander chip.

## Hardware Configuration

### TCAL6416 Connection
- **I2C Address**: 0x20 (when A2, A1, A0 pins are tied to GND)
- **VCC**: Connect to 3.3V
- **GND**: Connect to ground
- **SDA**: Connect to GPIO 21 (ESP32-S3)
- **SCL**: Connect to GPIO 22 (ESP32-S3)
- **Pull-up resistors**: 4.7kΩ resistors on both SDA and SCL lines (to 3.3V)

### ESP32-S3 Pin Configuration
```
GPIO 21 - I2C SDA (Data line)
GPIO 22 - I2C SCL (Clock line)
```

## TCAL6416 Features

The TCAL6416 is a 16-bit I/O expander with the following features:
- 16 I/O pins organized as two 8-bit ports (Port 0: P0_0 to P0_7, Port 1: P1_0 to P1_7)
- Each pin can be individually configured as input or output
- Input polarity inversion capability
- I2C interface with configurable address (0x20-0x27)
- Operating voltage: 1.65V to 5.5V
- Low standby current

## Register Map

| Register | Address | Description |
|---|---|---|
| Input Port 0 | 0x00 | Read input values of port 0 (P0_7-P0_0) |
| Input Port 1 | 0x01 | Read input values of port 1 (P1_7-P1_0) |
| Output Port 0 | 0x02 | Set output values of port 0 (P0_7-P0_0) |
| Output Port 1 | 0x03 | Set output values of port 1 (P1_7-P1_0) |
| Polarity Inversion Port 0 | 0x04 | Polarity inversion for port 0 |
| Polarity Inversion Port 1 | 0x05 | Polarity inversion for port 1 |
| Configuration Port 0 | 0x06 | Pin direction for port 0 (1=input, 0=output) |
| Configuration Port 1 | 0x07 | Pin direction for port 1 (1=input, 0=output) |

## Current Implementation

The current code implements:

1. **I2C Master Initialization**: Sets up ESP32-S3 as I2C master on GPIO 21 (SDA) and GPIO 22 (SCL)
2. **TCAL6416 Driver Functions**:
   - Register read/write operations
   - Pin-level control functions
   - Port configuration functions
3. **Demo Application**: 
   - Configures Port 0 (8 pins) as outputs
   - Configures Port 1 (8 pins) as inputs
   - Cycles through output pins on Port 0
   - Continuously reads input state from Port 1

## Building and Flashing

To build and flash the project:

1. **From VSCode**:
   ```
   Install the extension
   Click in the Build Fash and Monitor icon in the tray (like a flame) 
   ```

Alternative 

1. **Set up ESP-IDF environment** (if not already done):
   ```bash
   $env:IDF_PATH = "C:/Users/Carlos/esp/v5.5.1/esp-idf"
     
   # Or Windows (PowerShell)
   . $env:IDF_PATH/install.ps1
   . $env:IDF_PATH/export.ps1
   ```

2. **Build the project**:
   ```bash
   idf.py build
   ```

3. **Flash to ESP32-S3**:
   ```bash
   idf.py -p COMx flash monitor
   ```
   Replace `COMx` with your actual COM port.

## Usage Example

The demo application will:
1. Initialize I2C and TCAL6416
2. Configure Port 0 as outputs (all 8 pins)
3. Configure Port 1 as inputs (all 8 pins) 
4. Cycle through each output pin (0-7) turning them ON/OFF
5. Read and display the state of input Port 1

## Expected Output

```
I (xxx) i2c_tcal6416: ESP32-S3 I2C Master with TCAL6416 Demo
I (xxx) i2c_tcal6416: I2C master initialized successfully
I (xxx) i2c_tcal6416: TCAL6416 communication test successful, input port 0: 0xXX
I (xxx) i2c_tcal6416: TCAL6416 initialized successfully
I (xxx) i2c_tcal6416: Port 0: Configured as outputs (8 pins)
I (xxx) i2c_tcal6416: Port 1: Configured as inputs (8 pins)
I (xxx) i2c_tcal6416: Demo started - cycling through output pins and reading inputs
I (xxx) i2c_tcal6416: Setting pin 0 to LOW
I (xxx) i2c_tcal6416: Input port 1 state: 0xXX
I (xxx) i2c_tcal6416: Setting pin 0 to HIGH
I (xxx) i2c_tcal6416: Input port 1 state: 0xXX
...
```

## Customization

### Changing I2C Address
If your TCAL6416 has a different address (due to A2, A1, A0 pin configuration), modify:
```c
#define TCAL6416_ADDR   0x20  // Change this to your address
```

### Changing I2C Pins
To use different GPIO pins for I2C:
```c
#define I2C_MASTER_SCL_IO   22    // Change SCL pin
#define I2C_MASTER_SDA_IO   21    // Change SDA pin
```

### Custom Pin Configuration
To configure pins differently, modify the initialization:
```c
// Example: Configure port 0 pins 0-3 as outputs, 4-7 as inputs
tcal6416_write_reg(TCAL6416_REG_CONFIG_PORT0, 0xF0);  // 0xF0 = 11110000b
```

## API Functions Available

- `tcal6416_write_reg()` - Write to any TCAL6416 register
- `tcal6416_read_reg()` - Read from any TCAL6416 register
- `tcal6416_set_pin()` - Set individual pin state (HIGH/LOW)
- `tcal6416_read_inputs()` - Read entire input port state

## Troubleshooting

1. **No communication with TCAL6416**:
   - Check wiring connections
   - Verify I2C address (use I2C scanner if needed)
   - Ensure pull-up resistors are connected
   - Check power supply (3.3V)

2. **Build errors**:
   - Ensure ESP-IDF is properly installed and environment is set up
   - Check that you've removed the `MINIMAL_BUILD` setting from CMakeLists.txt

3. **Pin not responding**:
   - Verify pin is configured as output in configuration register
   - Check that you're writing to the correct port register
   - Measure voltage levels with multimeter

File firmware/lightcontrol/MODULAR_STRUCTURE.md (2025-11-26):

# Modular ESP32-S3 I2C + TCAL6416 Project Structure

This project has been refactored into a clean, modular architecture for better maintainability and reusability.

## 📁 Project Structure

```
main/
├── main.c    # Main application logic
├── i2c_driver.h           # I2C driver header
├── i2c_driver.c           # I2C driver implementation
├── tcal6416.hpp            # TCAL6416 driver header  
├── tcal6416.c            # TCAL6416 driver implementation
├── CMakeLists.txt        # Build configuration
└── idf_component.yml     # Component dependencies
```

## 🔧 Module Breakdown

### 1. I2C Driver Module (`i2c_driver.h` / `i2c_driver.c`)
**Purpose**: Generic I2C master functionality for ESP32-S3

**Key Features**:
- ✅ I2C master initialization and configuration
- ✅ Single byte read/write operations
- ✅ Multi-byte read/write operations  
- ✅ Device presence testing
- ✅ Comprehensive error handling and logging
- ✅ Configurable GPIO pins, frequency, and timeouts

**API Functions**:
```c
esp_err_t i2c_master_init(void);
esp_err_t i2c_master_deinit(void);
esp_err_t i2c_master_write_byte(uint8_t device_addr, uint8_t reg_addr, uint8_t data);
esp_err_t i2c_master_read_byte(uint8_t device_addr, uint8_t reg_addr, uint8_t *data);
esp_err_t i2c_master_write_bytes(uint8_t device_addr, uint8_t reg_addr, const uint8_t *data, size_t len);
esp_err_t i2c_master_read_bytes(uint8_t device_addr, uint8_t reg_addr, uint8_t *data, size_t len);
esp_err_t i2c_master_test_device(uint8_t device_addr);
```

### 2. TCAL6416 Driver Module (`tcal6416.hpp` / `tcal6416.cpp`)
**Purpose**: Specific functionality for TCAL6416 I/O expander

**Key Features**:
- ✅ Device initialization with default or custom configuration
- ✅ Individual pin control (16 pins total)
- ✅ Port-level operations (2 ports × 8 pins each)
- ✅ Pin direction configuration (input/output)
- ✅ Register-level access for advanced operations
- ✅ Status reporting and debugging functions

**API Functions**:
```c
esp_err_t tcal6416_init_default(uint8_t i2c_address);
esp_err_t tcal6416_init_config(const tcal6416_config_t *config);
esp_err_t tcal6416_set_pin(uint8_t i2c_address, uint8_t pin, bool state);
esp_err_t tcal6416_get_pin(uint8_t i2c_address, uint8_t pin, bool *state);
esp_err_t tcal6416_set_port(uint8_t i2c_address, uint8_t port, uint8_t value);
esp_err_t tcal6416_read_port(uint8_t i2c_address, uint8_t port, uint8_t *value);
esp_err_t tcal6416_config_pin(uint8_t i2c_address, uint8_t pin, uint8_t direction);
esp_err_t tcal6416_config_port(uint8_t i2c_address, uint8_t port, uint8_t config);
esp_err_t tcal6416_print_status(uint8_t i2c_address);
```

### 3. Main Application (`main.c`)
**Purpose**: Application-specific logic and demo functionality

**Key Features**:
- ✅ Clean application initialization
- ✅ Individual pin testing function
- ✅ Continuous demo task with cycling pins
- ✅ Comprehensive status reporting
- ✅ Binary representation of port states
- ✅ Error handling with helpful troubleshooting messages

## 🚀 Benefits of Modular Design

### **Reusability**
- I2C driver can be used with any I2C device
- TCAL6416 driver is portable across different projects
- Clean separation allows easy testing of individual modules

### **Maintainability** 
- Each module has a single responsibility
- Easy to debug issues in specific functionality
- Clear API boundaries between modules

### **Scalability**
- Easy to add support for additional I2C devices
- Can extend TCAL6416 functionality without touching main app
- Simple to add new application features

### **Readability**
- Main application logic is clean and focused
- Driver implementation details are hidden
- Self-documenting code with comprehensive logging

## 📋 Configuration

### I2C Configuration (in `i2c_driver.h`):
```c
#define I2C_MASTER_SCL_IO           22    // GPIO for I2C clock
#define I2C_MASTER_SDA_IO           21    // GPIO for I2C data  
#define I2C_MASTER_FREQ_HZ          100000 // I2C frequency (100kHz)
```

### Application Configuration (in `main.c`):
```c
#define TCAL6416_I2C_ADDR           0x20  // TCAL6416 I2C address
```

## 🔍 Usage Examples

### Basic Pin Control:
```c
// Initialize system
i2c_master_init();
tcal6416_init_default(0x20);

// Control individual pins
tcal6416_set_pin(0x20, 0, true);   // Set pin 0 HIGH
tcal6416_set_pin(0x20, 1, false);  // Set pin 1 LOW

// Read input pins
bool pin_state;
tcal6416_get_pin(0x20, 8, &pin_state);  // Read pin 8 (port 1)
```

### Port-Level Operations:
```c
// Set entire port at once
tcal6416_set_port(0x20, 0, 0xFF);  // All port 0 pins HIGH

// Read entire input port
uint8_t input_state;
tcal6416_read_port(0x20, 1, &input_state);  // Read all port 1 pins
```

### Custom Configuration:
```c
tcal6416_config_t config = {
    .i2c_address = 0x20,
    .port0_config = 0x0F,    // Pins 0-3 output, 4-7 input
    .port1_config = 0xFF,    // All inputs
    .port0_polarity = 0x00,  // Normal polarity
    .port1_polarity = 0x00   // Normal polarity
};
tcal6416_init_config(&config);
```

## 🛠️ Building and Testing

1. **Build the project**:
   ```bash
   idf.py build
   ```

2. **Flash and monitor**:
   ```bash
   idf.py -p COMx flash monitor
   ```

3. **Expected output**:
   ```
   I (xxx) lightcontrol_app: === ESP32-S3 Light Control with TCAL6416 ===
   I (xxx) i2c_driver: I2C master initialized successfully
   I (xxx) tcal6416: TCAL6416 found at address 0x20
   I (xxx) tcal6416: TCAL6416 initialized with default configuration
   ...
   ```

## 🔧 Customization

### Adding New I2C Devices:
1. Create new driver header/source files
2. Use `i2c_driver.h` functions for communication
3. Add device-specific logic and registers

### Modifying Pin Configuration:
1. Edit the initialization in `app_main()`
2. Use `tcal6416_config_port()` or `tcal6416_config_pin()`
3. Customize the demo task for your specific needs

### Changing I2C Settings:
1. Modify defines in `i2c_driver.h`
2. Rebuild and reflash the project

This modular architecture provides a solid foundation for any I2C-based project with the ESP32-S3!

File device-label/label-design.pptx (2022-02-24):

## Label

N L R1 R2 R3 R4 L1 L2 L3 L4

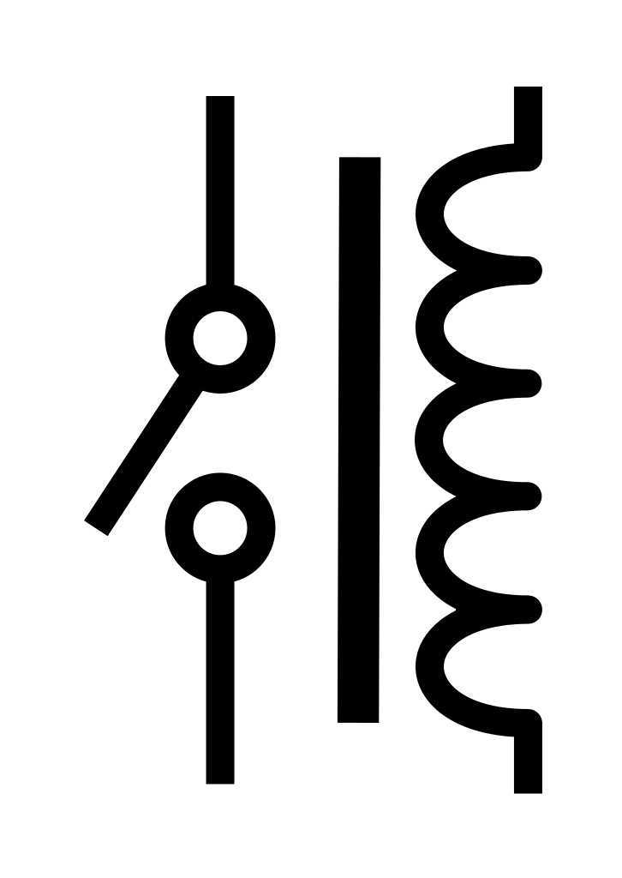
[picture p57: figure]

Max consumption: 500mA

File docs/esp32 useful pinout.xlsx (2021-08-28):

2 | OK | OK | OnBoard led
4 | OK | OK
13 | OK | OK
16 | OK | OK
17 | OK | OK
18 | OK | OK
19 | OK | OK
21 | OK | OK
22 | OK | OK
23 | OK | OK
25 | OK | OK
26 | OK | OK
27 | OK | OK
32 | OK | OK |  | mm
33 | OK | OK
34 | OK |  | input only
35 | OK |  | input only
36 | OK |  | input only
39 | OK |  | input only

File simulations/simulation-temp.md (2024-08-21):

```
$ 1 0.000005 25.510281670702206 59 5 50 5e-11
v -96 368 -96 80 0 1 50 5 0 0 0.5
w 48 80 48 144 0
d 48 144 112 208 2 default
d 48 272 112 208 2 default
d -16 208 48 144 2 default
d -16 208 48 272 2 default
w 48 272 48 368 0
w 48 368 -96 368 0
w -16 208 -16 304 0
w -16 304 128 304 0
r -96 80 48 80 0 300000
x 513 136 607 139 4 16 ESP32\sGPIO
w 320 16 320 208 0
v 624 64 624 0 0 0 40 3.3 0 0 0.5
w 496 0 416 0 0
r 496 64 624 64 0 5000
w 416 32 416 64 0
c 496 0 496 64 0 0.000001 0.6029847803709081 0.001
w 416 64 496 64 0
w 496 0 624 0 0
s 112 208 320 208 0 0 false
r 496 112 624 112 0 1000000
w 496 64 496 112 0
w 624 64 624 112 0
x 112 183 307 186 4 20 Mains\sSensing\sSwitch
400 368 16 416 16 1 0\s1\s0.4493703964247504\s0.47302767810085555\s100\sdefault 0\s1\s-0.023657281676105146\s0.5793274986948029\s100\sdefault 1
w 320 208 320 336 0
400 384 336 432 336 1 0\s1\s0.4499372909303604\s0.4731693914387385\s100\sdefault 0\s1\s-0.023232100508378095\s0.57918578535692\s100\sdefault 1
w 464 384 544 384 0
r 464 288 544 288 0 1000000
w 432 384 464 384 0
c 464 320 464 384 0 0.000001 0.6024178858652981 0.001
w 432 352 432 384 0
r 528 320 624 320 0 5000
w 464 320 432 320 0
v 624 384 624 320 0 0 40 3.3 0 0 0.5
x 462 264 556 267 4 16 ESP32\sGPIO
w 320 16 368 16 0
w 544 288 544 384 0
w 624 384 544 384 0
w 464 320 464 288 0
w 384 336 320 336 0
w 128 304 352 304 0
w 352 304 352 64 0
w 352 64 416 64 0
w 352 304 352 384 0
w 352 384 432 384 0
x 428 -20 579 -17 4 20 -----\sCircuit\s1\s-----
x 436 234 587 237 4 20 -----\sCircuit\s2\s-----
w 464 320 528 320 0
o 21 128 0 x81013 5 0.00009765625 0 2 1 0 21 3 0.000049999999999999996 0
o 29 128 0 x81013 5 0.00009765625 1 2 1 0 29 3 0.000049999999999999996 0
```

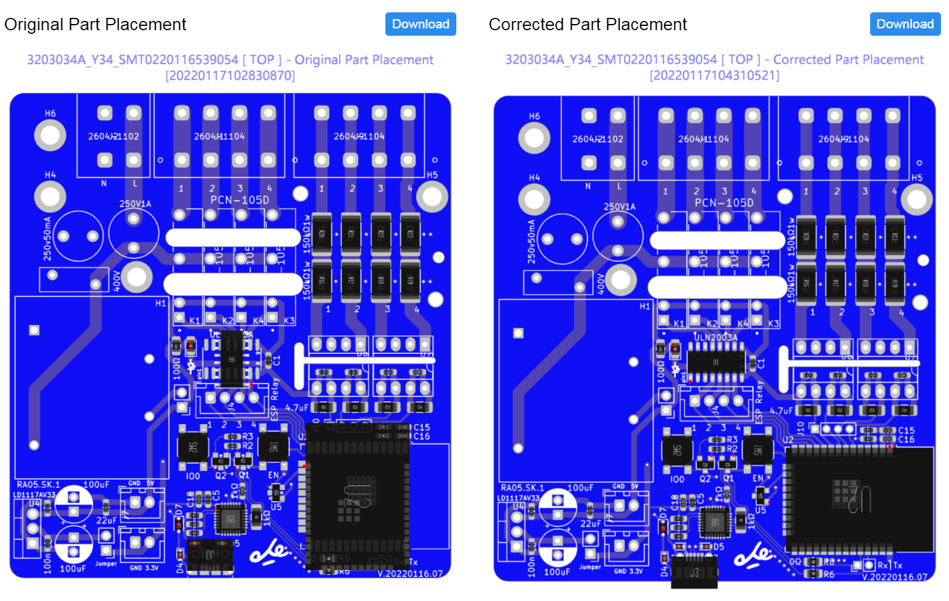
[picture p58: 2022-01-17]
PCB/schematics-v16-espinside-jlcpcb/readme-media/documents/placement-fixing.png

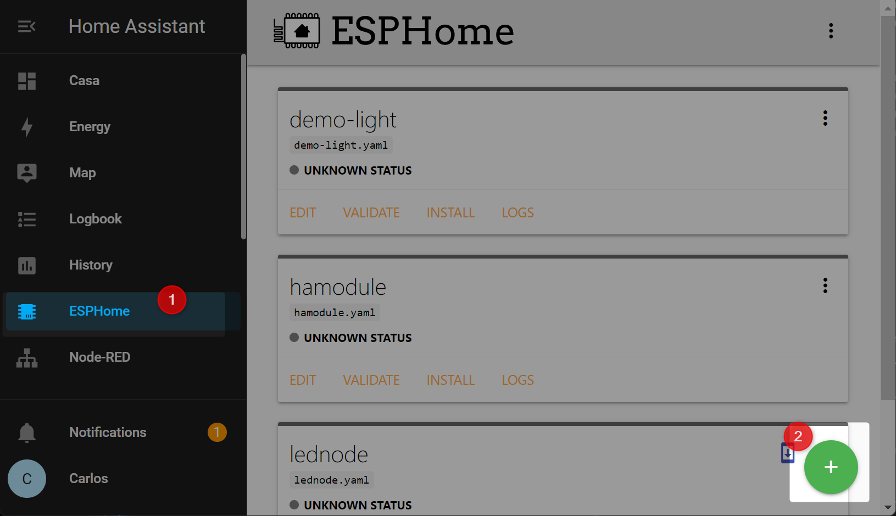
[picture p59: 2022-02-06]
PCB/schematics-v24-1-jlcpcb/readme-media/configureEspHome/1-add-device.png

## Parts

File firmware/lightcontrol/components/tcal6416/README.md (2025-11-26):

# TCAL6416 I/O Expander Driver for ESP32

This is a comprehensive ESP-IDF component for the Texas Instruments TCAL6416 16-bit I/O expander.

## Features

- ✅ **16 I/O pins** organized as two 8-bit ports
- ✅ **Individual pin control** - Set/read any of the 16 pins independently  
- ✅ **Port-level operations** - Control 8 pins at once
- ✅ **Configurable pin direction** - Each pin can be input or output
- ✅ **Polarity inversion** - Option to invert input polarity per pin
- ✅ **I2C interface** - Supports addresses 0x20-0x27
- ✅ **ESP-IDF integration** - Proper error handling with ESP_CHECK macros
- ✅ **Version management** - Semantic versioning support

## Hardware Specifications

- **Supply voltage**: 1.65V to 5.5V
- **I2C addresses**: 0x20 to 0x27 (configurable via A2, A1, A0 pins)
- **I2C speed**: Up to 400 kHz
- **Pin count**: 16 I/O pins (P0_0 to P0_7, P1_0 to P1_7)
- **Package**: VQFN-24, TSSOP-24

## Usage

### Basic Example

```c
#include "tcal6416.hpp"

void app_main(void)
{
    // Initialize I2C master (your I2C setup code here)
    // ...
    
    // Initialize TCAL6416
    tcal6416_handle_t tcal_handle;
    esp_err_t ret = tcal6416_init(&tcal_handle, 0, 0x20);  // I2C port 0, address 0x20
    if (ret != ESP_OK) {
        ESP_LOGE("app", "TCAL6416 initialization failed");
        return;
    }
    
    // Set pin 0 HIGH
    tcal6416_set_pin(&tcal_handle, 0, true);
    
    // Read pin 8 (port 1, pin 0)
    bool pin_state;
    tcal6416_get_pin(&tcal_handle, 8, &pin_state);
    
    // Set entire port 0 to 0xFF (all HIGH)
    tcal6416_set_port(&tcal_handle, TCAL6416_PORT0, 0xFF);
    
    // Print device status
    tcal6416_print_status(&tcal_handle);
}
```

### Custom Configuration

```c
tcal6416_config_t config = {
    .i2c_address = 0x20,
    .i2c_port = 0,
    .port0_config = 0x0F,    // Pins 0-3 output, 4-7 input
    .port1_config = 0xFF,    // All inputs
    .port0_polarity = 0x00,  // Normal polarity
    .port1_polarity = 0x00   // Normal polarity
};

tcal6416_handle_t tcal_handle;
tcal6416_init_with_config(&tcal_handle, &config);
```

## API Reference

### Initialization
- `tcal6416_init()` - Initialize with default configuration
- `tcal6416_init_with_config()` - Initialize with custom configuration
- `tcal6416_test_communication()` - Test device communication

### Pin Operations
- `tcal6416_set_pin()` - Set individual pin state
- `tcal6416_get_pin()` - Read individual pin state
- `tcal6416_config_pin()` - Configure pin direction

### Port Operations  
- `tcal6416_set_port()` - Set entire port state
- `tcal6416_read_port()` - Read entire port state
- `tcal6416_config_port()` - Configure port direction

### Advanced Features
- `tcal6416_set_pin_polarity()` - Set polarity inversion per pin
- `tcal6416_write_register()` - Direct register write access
- `tcal6416_read_register()` - Direct register read access
- `tcal6416_print_status()` - Print complete device status

### Utility
- `tcal6416_get_version()` - Get driver version information

## Pin Mapping

| Pin Number | Port | Port Pin | Description |
|---|---|---|---|
| 0-7 | 0 | P0_0-P0_7| Port 0 pins |
| 8-15 | 1 | P1_0-P1_7| Port 1 pins |

## Register Map

| Register | Address | Description |
|---|---|---|
| Input Port 0 | 0x00 | Read input values of port 0 |
| Input Port 1 | 0x01 | Read input values of port 1 |
| Output Port 0 | 0x02 | Set output values of port 0 |
| Output Port 1 | 0x03 | Set output values of port 1 |
| Polarity Inversion Port 0 | 0x04 | Polarity inversion for port 0 |
| Polarity Inversion Port 1 | 0x05 | Polarity inversion for port 1 |
| Configuration Port 0 | 0x06 | Pin direction for port 0 (1=input, 0=output) |
| Configuration Port 1 | 0x07 | Pin direction for port 1 (1=input, 0=output) |

## Dependencies

- ESP-IDF v4.4 or newer
- I2C driver component (automatically handled)

## License

This component is released under the public domain (CC0) license.

## Contributing

Contributions are welcome! Please submit pull requests or issues on the project repository.

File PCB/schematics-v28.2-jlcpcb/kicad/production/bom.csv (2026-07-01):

Designator | Footprint | Quantity | Value | LCSC Part #
C1, C14, C19, C4, C5, C9 | 0603 | 6 | 100nF | C14663
C10, C11, C20, C6, C7 | 0805 | 5 | 22uF | C45783
C12, C13 | 0603 | 2 | 20p | C1648
C15, C16, C17, C18, C3 | 0603 | 5 | 22uF | C59461
C2 | 1206 | 1 | 100uF | C15008
C21, C8 | CP_Elec_6.3x5.3 | 2 | 100uF | C7469977
D1, D2, D8 | 0805 | 3 | LED | C2297
D3 | D_SOD-323 | 1 | BAT60A | C124187
D4, D5, D6, D7 | 0603 | 4 | LED | C72041
F1 | Fuseholder_TR5_Littelfuse_No560_No460 | 1 | 250V500mA
F2, F3, F4, F5, F6, F7, F8, F9 | FUSE_RST-1-BULK | 8 | Fuse | C2840857
H1, H2, H3 | MountingHole_3.2mm_M3_ISO14580_Pad | 3 | MountingHole_Pad
J10 | PinHeader_1x02_P2.54mm_Vertical | 1 | Serial | C492401
J11 | USB_C_Receptacle_HRO_TYPE-C-31-M-12 | 1 | USB_C_Receptacle_USB2.0 | C167321
J12, J9 | big_pads_2604-1104 | 2 | 2604-1104 | C3309598
J13 | PinSocket_1x04_P2.54mm_Vertical | 1 | EspSense | C49257
J14, J15, J3 | PinHeader_1x02_P2.54mm_Vertical | 3 | ~ | C492401
J2 | big_pads_2604-1102 | 1 | 2604-1102 | C3309286
J4 | PinHeader_1x02_P2.54mm_Vertical | 1 | 13|12 | C492401
J5 | PinHeader_1x03_P2.54mm_Vertical | 1 | 9|3|46 | C49257
J7 | PinHeader_1x02_P2.54mm_Vertical | 1 | Current Jumper | C492401
J8 | PinSocket_1x04_P2.54mm_Vertical | 1 | EspRelays | C49257
K1, K2, K3, K4 | AQG12205 | 4 | AQG12205 | C124711
NT1 | NetTie-2_SMD_Pad2.0mm | 1 | NetTie_2
PS1 | 277 | 1 | RAC05-05SK/277
R1, R11, R12, R13, R14, R6, R7 | 0603 | 7 | 10kΩ | C25804
R10, R9 | 0603 | 2 | 5.1kΩ | C23186
R15, R16, R17, R18, R19, R20, R21, R22, R8 | 2512 | 9 | 150kΩ1w | C25719
R2, R26, R5 | 0805 | 3 | 100Ω | C17408
R23, R24, R25, R27 | 0603 | 4 | 100Ω | C22775
R3, R4 | 0603 | 2 | 22Ω | C23345
RV1 | RV_Disc_D12mm_W4.2mm_P7.5mm | 1 | 400V
SW1, SW2 | SW_SPST_TL3342 | 2 | Switch | C318884
SW3 | PinHeader_1x03_P2.54mm_Vertical | 1 | USB|PS | C49257
TP1 | TestPoint_THTPad_1.0x1.0mm_Drill0.5mm | 1 | GND
U1 | SOT-223-3_TabPin2 | 1 | LD1117AV33
U11 | SOIC-18W_7.5x11.6mm_P1.27mm | 1 | ULN2803A | C845537
U2 | ESP32-S3-WROOM-2 | 1 | ESP32-S3-WROOM-2 | C2913202
U4 | SOT-23-6 | 1 | USBLC6-2SC6 | C2827654
U5, U6 | DIP-8_W7.62mm_Socket_LongPads | 2 | LDA210-PDIP
U7 | Sensirion_DFN-4_1.5x1.5mm_P0.8mm_SHT4x_NoCentralPad | 1 | SHT4x | C2909890

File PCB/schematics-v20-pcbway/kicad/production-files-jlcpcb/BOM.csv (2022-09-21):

Comment | Designator | Footprint | LCSC Part #
100nF Polarized capacitor small symbol | C1,C2,C7,C9,C12,C14,C19 | Capacitor_SMD | C14663
NC Polarized capacitor small symbol | C3,C4,C10,C11 | Capacitor_SMD
NC Polarized capacitor small symbol | C5 | Capacitor_SMD
22uF Unpolarized capacitor small symbol | C6,C15,C16,C17,C18 | Capacitor_SMD | C59461
10uF Polarized capacitor small symbol | C8 | Capacitor_THT
4.7uF Polarized capacitor small symbol | C13 | Capacitor_SMD | C19666
LED Light emitting diode | D1,D2 | LED_SMD | C2297
D_TVS Bidirectional transient-voltage-suppression diode | D3,D4,D5 | Diode_SMD | C383211
BAT60A-7 10V 3A High Current Recitifier Schottky Diode SOD-323 | D6 | Diode_SMD | C124187
250V500mA Fuse | F1 | Fuse
Fuse Fuse | F2,F3,F4,F5,F6,F7,F8,F9 | RST-80-AMMO
MountingHole_Pad Mounting Hole with connection | H1,H2,H3 | MountingHole
GND|5V Generic connector single row 01x02 script generated (k | J1 | Connector_JST
Conn_01x02_Male Generic connector single row 01x02 script gen | J2,J5,J7 | Connector_PinHeader_2.54mm
2604-1102 | J3 | wago-2604-1102
USB | PS Generic connector single row 01x03 script generated | J4 | Connector_PinHeader_2.54mm
GND|3.3V Generic connector single row 01x02 script generated | J6 | Connector_JST
Current Jumper Generic connector single row 01x02 script gene | J8 | Connector_PinHeader_2.54mm
EspRelays Generic connector single row 01x04 script generated | J9 | Connector_PinSocket_2.54mm
USB_C_Receptacle_USB2.0 USB 2.0-only Type-C Receptacle connector | J10 | Connector_USB | C167321
2604-1104 | J11,J12 | wago-2604-1104
EspSense Generic connector single row 01x04 script generated | J13 | Connector_PinSocket_2.54mm
AQG12205 Solid State Relays - PCB Mount 1A 5V Random Non-Zero Cr | K1,K2,K3,K4 | AQG12205
NetTie_2 Net tie 2 pins | NT1 | NetTie
RAC05-05SK/277 | PS1 | rac05-05sk
SS8050 NPN transistor base/emitter/collector | Q1,Q2 | Package_TO_SOT_SMD | C177739
10k Resistor | R1,R2,R3,R16,R17,R18,R19,R20,R21 | Resistor_SMD | C25804
100 Resistor | R4,R5 | Resistor_SMD | C17408
150k1w Resistor | R6,R22,R23,R24,R25,R26,R27,R28,R29 | Resistor_SMD | C25719
22.1k Resistor | R7 | Resistor_SMD | C25961
47.5k Resistor | R8 | Resistor_SMD | C23061
5.1k Resistor | R9,R10 | Resistor_SMD | C23186
1k Resistor | R11,R15 | Resistor_SMD | C25585
0 Resistor | R12,R13 | Resistor_SMD | C17477
1k Resistor | R14 | Resistor_SMD | C4410
400V Voltage dependent resistor | RV1 | Varistor
Switch Push button switch generic two pins | SW1,SW2 | Button_Switch_SMD | C318884
LD1117AV33 800mA Fixed Low Drop Positive Voltage Regulator Fixe | U1 | Package_TO_SOT_THT
ESP32-WROOM-32E RF Module ESP32-D0WD SoC Wi-Fi 802.11b/g/n Bl | U2 | RF_Module | C701343
CP2102N-A01-GQFN28 USB to UART master bridge QFN-28 | U3 | Package_DFN_QFN | C964632
ULN2003A High Voltage High Current Darlington Transistor Arrays | U4 | Package_SO | C7512
LDA210-PDIP DC Darlington Optocoupler Vce 35V CTR 600% SO-4 | U5,U6 | Package_DIP
SHT4x Temperature and humidity module | U7 | sht40 | C2909890

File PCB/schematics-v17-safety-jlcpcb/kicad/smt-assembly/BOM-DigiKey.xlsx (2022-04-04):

Index | Quantity | Part Number | Manufacturer Part Number | Description | Customer Reference | Available | Backorder | Unit Price | Extended Price CHF
1 | 100 | 1276-1934-1-ND | CL10B104KB8NFNC | CAP CER 0.1UF 50V X7R 0603 |  | 100 | 0 | 1160 | 1,16 Fr.
2 | 5 | BAT60AE6327HTSA1CT-ND | BAT60AE6327HTSA1 | DIODE SCHOTTKY 10V 3A SOD323-2 | 5 | 5 | 0 | 46000 | 2,30 Fr.
3 | 1 | 2073-USB4105-GF-A-060CT-ND | USB4105-GF-A-060 | CONN RCP USB2.0 TYP C 24P SMD RA |  | 1 | 0 | 78000 | 0,78 Fr.
4 | 20 | RHM100AECT-ND | ESR10EZPF1000 | RES SMD 100 OHM 1% 0.4W 0805 |  | 20 | 0 | 14100 | 2,82 Fr.
5 | 25 | RMCF0805ZT0R00CT-ND | RMCF0805ZT0R00 | RES 0 OHM JUMPER 1/8W 0805 |  | 25 | 0 | 1160 | 0,29 Fr.
6 | 10 | A126371CT-ND | CRG0805F47R | RES SMD 47 OHM 1% 1/8W 0805 |  | 10 | 0 | 5200 | 0,52 Fr.
7 | 15 | 641-1790-1-ND | SS8050-G | NPN TRANSISTOR 1.5A 40V SOT-23 R |  | 15 | 0 | 21700 | 3,26 Fr.
8 | 10 | 490-GRT188C81C475KE13JCT-ND | GRT188C81C475KE13J | CAP CER 4.7UF 16V X6S 0603 |  | 10 | 0 | 19300 | 1,93 Fr.
9 | 20 | 732-4983-1-ND | 150080GS75000 | LED GREEN CLEAR 0805 SMD |  | 20 | 0 | 17000 | 3,40 Fr.
10 | 100 | RMCF0603FT47K5CT-ND | RMCF0603FT47K5 | RES 47.5K OHM 1% 1/10W 0603 |  | 100 | 0 | 630 | 0,63 Fr.
11 | 100 | 311-5.10KHRCT-ND | RC0603FR-075K1L | RES 5.1K OHM 1% 1/10W 0603 |  | 100 | 0 | 890 | 0,89 Fr.
12 | 100 | RNCP0603FTD1K00CT-ND | RNCP0603FTD1K00 | RES 1K OHM 1% 1/8W 0603 |  | 100 | 0 | 2280 | 2,28 Fr.
13 | 100 | RMCF2512FT150KCT-ND | RMCF2512FT150K | RES 150K OHM 1% 1W 2512 |  | 100 | 0 | 11370 | 11,37 Fr.
14 | 100 | CR0603AFX-1002EASCT-ND | CR0603AFX-1002EAS | RESA-AS 0603 10K 1% 100MW TC100 |  | 100 | 0 | 2000 | 2,00 Fr.
15 | 100 | RMCF0603FT22K1CT-ND | RMCF0603FT22K1 | RES 22.1K OHM 1% 1/10W 0603 |  | 100 | 0 | 630 | 0,63 Fr.
16 | 5 | 1649-SHT41I-AD1B-R3CT-ND | SHT41I-AD1B-R3 | INDUSTRIAL SENSOR HUMID/TEMP |  | 5 | 0 | 370400 | 18,52 Fr.
17 | 50 | 1276-1055-1-ND | CL31B475KAHNNNE | CAP CER 4.7UF 25V X7R 1206 |  | 50 | 0 | 7320 | 3,66 Fr.
18 | 10 | 2449-CS1204AF160CT-ND | CS1204AF160 | LOW PROFILE SURFACE MOUNT TACTIL |  | 10 | 0 | 27000 | 2,70 Fr.
19 | 10 | 31-DESD5V0U1BB-7CT-ND | DESD5V0U1BB-7 | TVS DIODE 5VWM 7.2VC SOD523 |  | 10 | 0 | 20900 | 2,09 Fr.
20 | 20 | RMCF1206FT1K00CT-ND | RMCF1206FT1K00 | RES 1K OHM 1% 1/4W 1206 |  | 20 | 0 | 3300 | 0,66 Fr.
21 | 10 | 1276-1274-1-ND | CL10A226MP8NUNE | CAP CER 22UF 10V X5R 0603 |  | 10 | 0 | 12800 | 1,28 Fr.
22 | 5 | 1965-ESP32-WROOM-32E-N8CT-ND | ESP32-WROOM-32E-N8 | WIFI MODULE SPI FLASH |  | 5 | 0 | 304000 | 15,20 Fr.
23 | 10 | ULN2003ADR2GOSCT-ND | ULN2003ADR2G | TRANS 7NPN DARL 50V 0.5A 16SOIC |  | 0 | 10 | 51800 | 5,18 Fr.
24 | 10 | 336-5890-1-ND | CP2102N-A02-GQFN28R | IC USB TO UART BRIDGE QFN28 |  | 10 | 0 | 208000 | 20,80 Fr.

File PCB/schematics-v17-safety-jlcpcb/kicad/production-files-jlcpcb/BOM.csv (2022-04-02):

Comment | Designator | Footprint | LCSC Part # | Quantity
BAT60A-7 10V 3A High Current Recitifier Schottky Diode SOD-323 | D6 | Diode_SMD | C124187 | 1
100nF Polarized capacitor small symbol | C1,C2,C4,C6,C7,C9,C10,C11,C12,C13,C18 | Capacitor_SMD | C14663 | 11
USB_C_Receptacle_USB2.0 USB 2.0-only Type-C Receptacle connector | J8 | Connector_USB | C167321 | 1
100 Resistor | R4,R5 | Resistor_SMD | C17408 | 2
0 Resistor | R13,R14 | Resistor_SMD | C17477 | 2
50 Resistor | R11 | Resistor_SMD | C17738 | 1
SS8050-SMD NPN transistor base/emitter/collector | Q1 | Package_TO_SOT_SMD | C177739 | 1
SS8050 NPN transistor base/emitter/collector | Q2 | Package_TO_SOT_SMD | C177739 | 1
4.7uF Polarized capacitor small symbol | C8 | Capacitor_SMD | C19666 | 1
LED Light emitting diode | D1,D2 | LED_SMD | C2297 | 2
47.5k Resistor | R8,R17,R18,R19,R20 | Resistor_SMD | C23061 | 5
5.1k Resistor | R9,R10 | Resistor_SMD | C23186 | 2
1k Resistor | R12,R16 | Resistor_SMD | C25585 | 2
150k1w Resistor | R6,R23,R24,R25,R26,R27,R28,R29,R30 | Resistor_SMD | C25719 | 9
10k Resistor | R1,R2,R3,R21,R22 | Resistor_SMD | C25804 | 5
22.1k Resistor | R7 | Resistor_SMD | C25961 | 1
SHT4x Temperature and humidity module | U7 | sht40 | C2909890 | 1
4.7uF Polarized capacitor small symbol | C14,C15,C16,C17 | Capacitor_SMD | C29823 | 4
EN Push button switch generic two pins | SW1 | Button_Switch_SMD | C318884 | 1
IO0 Push button switch generic two pins | SW2 | Button_Switch_SMD | C318884 | 1
D_TVS Bidirectional transient-voltage-suppression diode | D3,D4,D5 | Diode_SMD | C383211 | 3
1k Resistor | R15 | Resistor_SMD | C4410 | 1
22uF Polarized capacitor small symbol | C3 | Capacitor_SMD | C59461 | 1
ESP32-WROOM-32E RF Module ESP32-D0WD SoC Wi-Fi 802.11b/g/n Bl | U2 | RF_Module | C701343 | 1
ULN2003A High Voltage High Current Darlington Transistor Arrays | U4 | Package_SO | C7512 | 1
CP2102N-A01-GQFN28 USB to UART master bridge QFN-28 | U3 | Package_DFN_QFN | C964632 | 1
10uF Polarized capacitor small symbol | C5 | Capacitor_THT |  | 1
250V500mA Fuse | F1 | Fuse |  | 1
250V50mA Fuse | F2 | Fuse |  | 1
Fuse Fuse | F3,F4,F5,F6 | RST-80-AMMO |  | 4
MountingHole_Pad Mounting Hole with connection | H1,H2,H3 | MountingHole |  | 3
Conn_01x02_Male Generic connector single row 01x02 script gen | J1,J6 | Connector_PinHeader_2.54mm |  | 2
2604-1102 | J2 | wago-2604-1102 |  | 1
GND|5V Generic connector single row 01x02 script generated (k | J3 | Connector_JST |  | 1
GND|3.3V Generic connector single row 01x02 script generated | J4 | Connector_JST |  | 1
Jumper Generic connector single row 01x02 script generated (k | J5 | Connector_PinHeader_2.54mm |  | 1
Current Jumper Generic connector single row 01x02 script gene | J7 | Connector_PinHeader_2.54mm |  | 1
DoNotCon Generic connector single row 01x02 script generated | J9 | Connector_PinHeader_2.54mm |  | 1
2604-1104 | J10,J12 | wago-2604-1104 |  | 2
ESP Relays Generic connector single row 01x04 script generate | J11 | Connector_JST |  | 1
EspSense Generic connector single row 01x04 script generated | J13 | Connector_PinSocket_2.54mm |  | 1
PCN-105D PCN-124D3MHZ 000 | K1,K2,K3,K4 | PCN |  | 4
NetTie_2 Net tie 2 pins | NT1 | NetTie |  | 1
RAC05-05SK/277 | PS1 | rac05-05sk |  | 1
400V Voltage dependent resistor | RV1 | Varistor |  | 1
LD1117AV33_TO220 800mA Fixed Low Drop Positive Voltage Regulator | U1 | Package_TO_SOT_THT |  | 1
LDA210-PDIP DC Darlington Optocoupler Vce 35V CTR 600% SO-4 | U5,U6 | Package_DIP |  | 2

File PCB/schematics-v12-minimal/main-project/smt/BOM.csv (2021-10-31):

Comment | Designator | Footprint | JLCPCB Part #
0.1uF | C5,C4,C3,C1,C2 | 805 | C235777
10k | R8,R7,R6,R5 | 1206 | C17902
ULN2003A | U1 | SOIC-16 | C7512
22uF | 22uF4,22uF3,22uF2,22uF1 | 3528 | C110051
39k1w | R17,R15,R13,R11,R16,R14,R12,R10 | 2512 | C25723
150 | R9 | 805 | C17471
LED | D9 | 805 | C2297

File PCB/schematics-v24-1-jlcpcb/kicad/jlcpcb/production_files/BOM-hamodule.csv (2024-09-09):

Comment | Designator | Footprint | LCSC
SN74LV1T34DBV | U10 | SOT-23-5 | C100024
BAT60A | D1 | D_SOD-323 | C124187
100nF | C3,C30,C31,C33,C39,C46,C47,C6 | C_0603_1608Metric_Pad1.08x0.95mm_HandSolder | C14663
10uF | C43,C44,C48,C49 | C_0402_1005Metric | C15525
20p | C11,C13,C17,C42,C9 | C_0603_1608Metric_Pad1.08x0.95mm_HandSolder | C1648
100Ω | R53,R55,R7,R8 | R_0805_2012Metric_Pad1.20x1.40mm_HandSolder | C17408
150kΩ | R2 | R_0805_2012Metric_Pad1.20x1.40mm_HandSolder | C17470
1kΩ | R36 | R_0603_1608Metric_Pad0.98x0.95mm_HandSolder | C21190
LED | D13,D14,D2,D3 | LED_0805_2012Metric_Pad1.15x1.40mm_HandSolder | C2297
5.1kΩ | R3,R4 | R_0603_1608Metric_Pad0.98x0.95mm_HandSolder | C23186
660Ω | R45,R46,R47,R48,R49,R50,R51,R52,R54 | R_0603_1608Metric_Pad0.98x0.95mm_HandSolder | C23193
22Ω | R5,R6 | R_0603_1608Metric | C23345
150kΩ1w | R10,R11,R12,R13,R14,R15,R16,R19,R20,R21,R22,R23,R24,R25,R26,R9 | R_2512_6332Metric_Pad1.40x3.35mm_HandSolder | C25719
10kΩ | R1,R17,R18,R27,R28,R29,R30,R31,R32,R33,R34,R35,R37,R38,R39,R40,R41,R42,R43,R44,R56,R57,R58 | R_0603_1608Metric_Pad0.98x0.95mm_HandSolder | C25804
USBLC6-2SC6 | U2 | SOT-23-6 | C2827654
SHT4x | U8 | Sensirion_DFN-4_1.5x1.5mm_P0.8mm_SHT4x_NoCentralPad | C2909890
ESP32-S3-WROOM-2 | U3 | ESP32-S3-WROOM-2 | C2913202
USB_C_Receptacle_USB2.0 | J3 | USB_C_Receptacle_HRO_TYPE-C-31-M-12 | C2927038
Reset | SW2,SW3 | SW_SPST_SKQG_WithStem | C318884
LD1117AV33 | U1 | TO-220-3_Vertical | C32833
22uF | C16,C21,C7,C8 | C_0805_2012Metric_Pad1.18x1.45mm_HandSolder | C45783
GND|5V | J1,J10,J11,J12,J13,J4,J5 | JST_XH_B2B-XH-A_1x02_P2.50mm_Vertical | C492401
5v|GND|Do | J8,SW1 | PinHeader_1x03_P2.54mm_Vertical | C49257
100nF | C10,C14,C15,C20,C32,C35,C36,C37,C38,C41,C5 | C_0805_2012Metric_Pad1.18x1.45mm_HandSolder | C49678
TXB0108PW | U9 | TSSOP-20_4.4x6.5mm_P0.65mm | C53406
WS2812B | D4 | LED_WS2812B_PLCC4_5.0x5.0mm_P3.2mm | C5446705
22uF | C22,C23,C24,C25,C26,C27,C28,C29,C34,C4,C40 | C_0603_1608Metric_Pad1.08x0.95mm_HandSolder | C59461
LED | D10,D11,D12,D15,D5,D6,D7,D8,D9 | LED_0603_1608Metric | C7496819
ULN2803A | U11 | SOP-18_7x12.5mm_P1.27mm | C845537

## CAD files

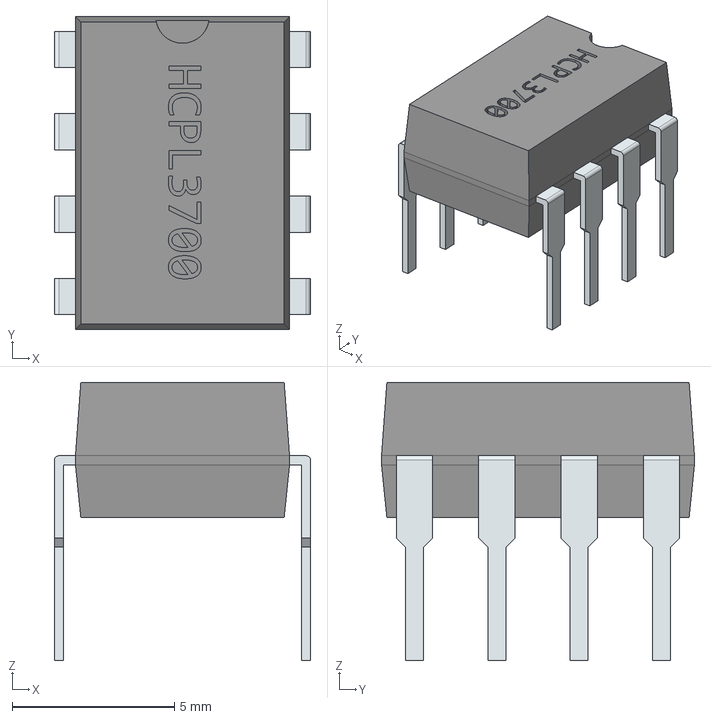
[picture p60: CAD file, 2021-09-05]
demo-11-esphome-module/schematics-v06/main-project/components-footprints/HCPL-3700-000/eec.models/ON_Semi_-_HCPL3700.step
7.90 x 9.66 x 8.58 mm

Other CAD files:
PCB/schematics-v01/recom/RAC05-05SK/RAC05-05SK.step
PCB/schematics-v01/recom/RAC15-05SK/RAC15-05SK.step
PCB/schematics-v01/skeed-connector/3D/1864053.stl
PCB/schematics-v01/skeed-connector/3D/1864053.stp
PCB/schematics-v01/skeed-connector/Allegro/1864053.psm
PCB/schematics-v01/skeed-connector/DEHDL/1864053/chips/chips.prt
PCB/schematics-v02/phoenixcontacts/1017505/1017505/3D/1017505.stl
PCB/schematics-v02/phoenixcontacts/1017505/1017505/3D/1017505.stp
PCB/schematics-v02/phoenixcontacts/1017505/1017505/Allegro/1017505.psm
PCB/schematics-v02/phoenixcontacts/1017505/1017505/DEHDL/1017505/chips/chips.prt
PCB/schematics-v02/phoenixcontacts/11880425/1017505/3D/1017505.stl
PCB/schematics-v02/phoenixcontacts/11880425/1017505/3D/1017505.stp
PCB/schematics-v02/phoenixcontacts/11880425/1017505/Allegro/1017505.psm
PCB/schematics-v02/phoenixcontacts/11880425/1017505/DEHDL/1017505/chips/chips.prt
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

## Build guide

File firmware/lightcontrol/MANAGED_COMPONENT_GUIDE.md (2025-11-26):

# ESP32-S3 Light Control with TCAL6416 Managed Component

This project now uses a **professional managed component architecture** for the TCAL6416 I/O expander, following ESP-IDF best practices.

## 🏗️ **Managed Component Architecture**

### **What is a Managed Component?**
A managed component is a reusable, self-contained piece of functionality that can be easily integrated into any ESP-IDF project. It's similar to libraries in other ecosystems (npm packages, Python pip packages, etc.).

### **Benefits Over Individual Files**
- ✅ **Reusability** - Can be used across multiple projects
- ✅ **Version Management** - Proper semantic versioning
- ✅ **Dependency Management** - Automatic handling of requirements
- ✅ **Professional Structure** - Matches Espressif's component design
- ✅ **Easy Updates** - Component can be updated independently
- ✅ **Clean Separation** - Application code is separate from driver code

## 📁 **New Project Structure**

```
lightcontrol/
├── main/
│   ├── main.cpp     # 🎯 Clean application code only
│   └── CMakeLists.txt           # 📋 Simplified build config
├── managed_components/
│   └── tcal6416/               # 📦 Self-contained component
│       ├── include/
│       │   └── tcal6416.hpp      # 🔗 Public API header
│       ├── src/
│       │   └── tcal6416.cpp      # ⚙️ Implementation
│       ├── CMakeLists.txt      # 🔧 Component build config
│       ├── idf_component.yml   # 📋 Component manifest
│       └── README.md           # 📚 Component documentation
├── CMakeLists.txt              # 🏗️ Main project config
└── Documentation files         # 📖 Project documentation
```

## 🎯 **Key Improvements**

### **Application Code (`main/main.c`)**
- ✅ **Clean & Focused** - Only application logic
- ✅ **Simple Includes** - Just `#include "tcal6416.hpp"`
- ✅ **Handle-Based API** - Modern, safe device management
- ✅ **Better Error Handling** - Uses ESP_CHECK macros

### **TCAL6416 Component (`managed_components/tcal6416/`)**
- ✅ **Professional API** - Handle-based design pattern
- ✅ **Comprehensive Features** - All TCAL6416 functionality
- ✅ **ESP-IDF Integration** - Proper error handling and logging
- ✅ **Version Information** - Semantic versioning support
- ✅ **Cross-Platform** - Works with any ESP-IDF version 4.4+

### **Build System**
- ✅ **Automatic Dependencies** - Handles I2C driver requirements
- ✅ **Version Compatibility** - Works with old and new ESP-IDF versions
- ✅ **Clean CMakeLists** - Simplified build configuration

## 🚀 **Usage Examples**

### **Basic Usage (Handle-Based API)**
```c
#include "tcal6416.hpp"

void app_main(void) {
    // Initialize I2C first
    // ... your I2C setup code ...
    
    // Create device handle
    tcal6416_handle_t tcal_handle;
    
    // Initialize with defaults (Port 0 = outputs, Port 1 = inputs)
    esp_err_t ret = tcal6416_init(&tcal_handle, 0, 0x20);
    if (ret != ESP_OK) {
        ESP_LOGE("app", "Init failed");
        return;
    }
    
    // Use the device
    tcal6416_set_pin(&tcal_handle, 0, true);     // Set pin 0 HIGH
    tcal6416_set_port(&tcal_handle, TCAL6416_PORT0, 0xFF); // All port 0 HIGH
    
    // Read inputs
    bool pin_state;
    tcal6416_get_pin(&tcal_handle, 8, &pin_state); // Read pin 8
    
    // Print status
    tcal6416_print_status(&tcal_handle);
}
```

### **Custom Configuration**
```c
tcal6416_config_t config = {
    .i2c_address = 0x20,
    .i2c_port = 0,
    .port0_config = 0x0F,    // Pins 0-3 output, 4-7 input
    .port1_config = 0xFF,    // All inputs
    .port0_polarity = 0x00,  // Normal polarity
    .port1_polarity = 0x00   // Normal polarity
};

tcal6416_handle_t tcal_handle;
tcal6416_init_with_config(&tcal_handle, &config);
```

## 🔧 **API Comparison**

### **Old Individual Files Approach**
```c
// Multiple includes needed
#include "i2c_driver.h"
#include "tcal6416.hpp"

// Address passed to every function
tcal6416_set_pin(0x20, pin, state);
tcal6416_read_port(0x20, port, &value);
```

### **New Managed Component Approach**
```c
// Single include
#include "tcal6416.hpp"

// Handle-based API (safer, cleaner)
tcal6416_set_pin(&handle, pin, state);
tcal6416_read_port(&handle, port, &value);
```

## 📋 **Hardware Connections**

```
ESP32-S3          TCAL6416
--------          --------
GPIO 21    <-->   SDA
GPIO 22    <-->   SCL
3.3V       <-->   VCC
GND        <-->   GND

Note: Add 4.7kΩ pull-up resistors on SDA and SCL lines
```

## 🛠️ **Building and Running**

1. **Build the project**:
   ```bash
   idf.py build
   ```

2. **Flash and monitor**:
   ```bash
   idf.py -p COMx flash monitor
   ```

3. **Expected output**:
   ```
   I (xxx) lightcontrol_app: === ESP32-S3 Light Control with TCAL6416 Managed Component ===
   I (xxx) lightcontrol_app: TCAL6416 Driver Version: 1.0.0
   I (xxx) lightcontrol_app: I2C master initialized successfully
   I (xxx) tcal6416: TCAL6416 initialized successfully at address 0x20
   ```

## 🔄 **Migration Benefits**

### **From Individual Files → Managed Component**
- 🎯 **Cleaner main application** - Focused on your business logic
- 🔧 **Professional driver** - Industry-standard patterns
- 📦 **Reusable component** - Use in other projects easily
- 🛡️ **Better error handling** - ESP-IDF best practices
- 📈 **Scalable architecture** - Easy to add more components

## 🌟 **Best Practices Implemented**

- ✅ **Handle-based API** - Safe device management
- ✅ **ESP-IDF integration** - Uses ESP_CHECK, ESP_LOG, etc.
- ✅ **Version management** - Semantic versioning
- ✅ **Comprehensive documentation** - API docs and examples
- ✅ **Cross-platform compatibility** - Works with different ESP-IDF versions
- ✅ **Professional structure** - Follows Espressif conventions

This managed component architecture provides a solid foundation that you can extend for any I2C-based project! 🚀

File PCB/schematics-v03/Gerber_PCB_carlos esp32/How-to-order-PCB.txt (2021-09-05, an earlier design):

How to Order PCB

Please refer to:
https://docs.easyeda.com/en/PCB/Order-PCB

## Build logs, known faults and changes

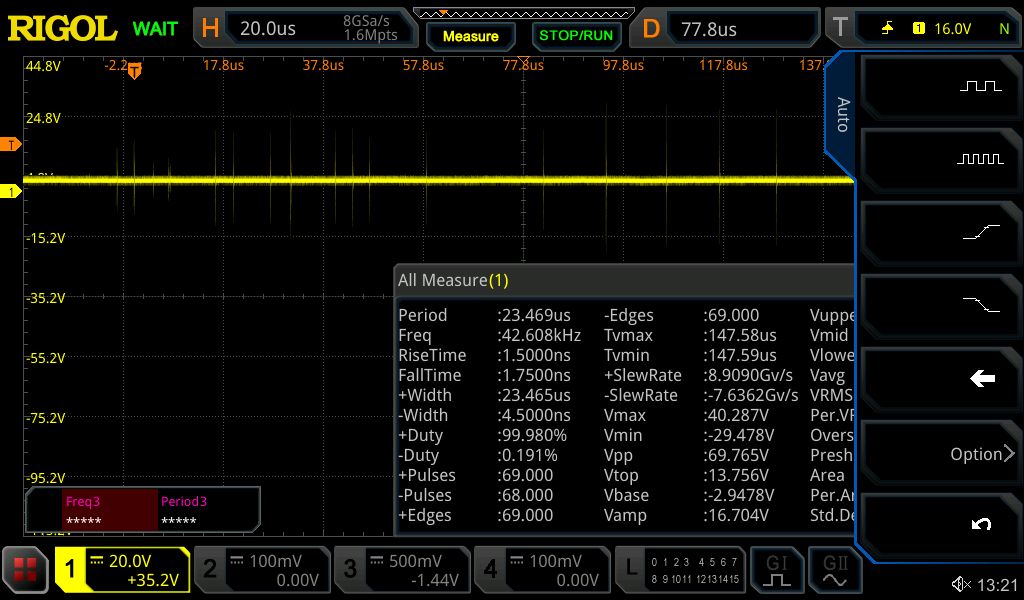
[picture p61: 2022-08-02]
current-issue/2022.08.02.13.21.54.784.jpeg

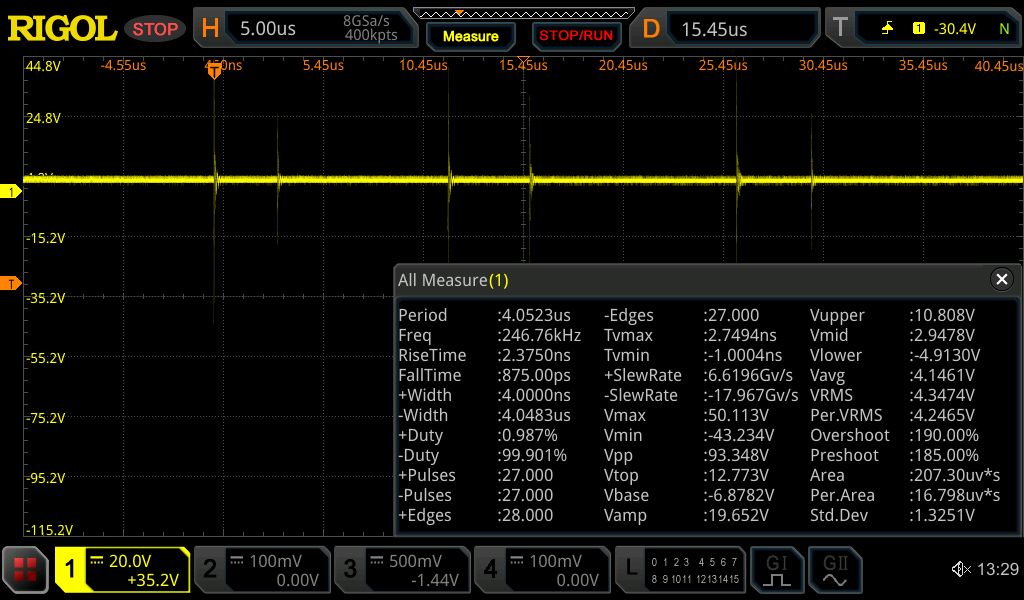
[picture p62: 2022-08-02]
current-issue/2022.08.02.13.30.12.396.failed.jpeg

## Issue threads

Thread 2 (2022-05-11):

Youtube video available?

johanf85, 2022-05-11:
Hi,

Very interesting project. I was looking into a similar solution for using regular light switches in combination with switching from within Home Assistant. I made a forum post in which I also mentioned your repo. See here: https://community.home-assistant.io/t/converting-light-switches/90337/22?u=johanf

Do you maybe have a Youtube video somewhere in which you demonstrate the PCB?

crgarcia12, 2022-05-11:
Hi @johanf85,
Thanks for the message!

I am travelling this week, so I don't have anything with me. Next week, I can upload some pictures to show the real PCB.
I never thought on making a video, but since this is the first "real" PCB I design, it took me many many months, pitfalls trial-and-error and learnings (like clearance, coating, digital signals, etc) to bring it to the current state.

Regarding your post, I like it very much!
I also thought on changing my main detections by a CT clamp. I actually bought bunch of them and tested. Doing that has the advantage that it can inform current consumption. One problem that I have, is that it makes the box a bit more messy with wires dangling around, and makes the installation more expensive... but happy to take a look at this approach if you think it would add value. What do you think?

Regarding the Shelly PRO:
I have other shellys and, in general, I like the product very very much.
In the other hand, I have had some problems with them:
- They get quite hot, which I assume it reduces their lifetime, and also does not make me feel confortable to have many hot devices in the mains board. I took a look at some published support cases, and I also saw many of them burning (not the PRO) or sparking. Understandable actually, I would not be able to put in such small box all what Shellys can do.
- If the Shelly burns, my house stop working. This is not aceptable for me, I want a "side-car" setup. Also, I am not sure if I will be able to buy a Shelly replacement in 5/10 years. In this project I uploaded the 3 order files are needed to get a fully assembled PCBs from PCBWay or partially PCB from JLCPCB.
In the worse case, if there are component you cannot find any longer, then you can simply remove the device and the house keeps working as it used to do before.

I also analyze other solutions, like DigitalStrom or KNX. They look very good, and also have their benefits and cons

Cheers!

johanf85, 2022-05-13:
Hi Carlos,

Yes that would be nice to see! Interesting project you are doing. I am nowhere near the skills of designing a PCB board for this.

And it's an interesting idea to supply the files so others can get their PCB assembled in the future, so that users are not dependent on the continuing of a product by a manufacturer.

Regarding the non-contact voltage detectors, I think the interesting part about that is that you don't have to connect the high voltage to a PCB. But you are right when it comes to switching a lot of lights, that it complicates the setup. I guess there are just multiple ways to go.

Maybe something to consider is the solution with a double switching relay like the one used here: https://maker.pro/raspberry-pi/projects/an-automated-light-switch-system-for-smarthomes-that-anyone-can-use

His relay, the finder 26.2, switches two circuits at once on every impulse. One circuit for the load (light) and one circuit with a input to a micro controller.

In that way there is no need to run a High voltage wire to a circuit of the microcontroller unit. However this design doesn't give information on whether the lamp is actually on, only whether the relay is in the on-position. But that is distinction I am willing to be okay with.

Yeah I heard about Digitalstrom too, but to me it seemed expensive and there is also a dependancy of a manufacturer.

Good luck on this project and your home.

Johan

crgarcia12, 2022-06-04:
Hi @johanf85, sorry for the delay, hard to find some time to work on this these weeks :S

The 3 files needed to get this PCB fully manufactured and assembled are in this repo. I added a GIF showing how you can order it on JLCPCB. If somebody cannot solder at all, there are services like PCBWay that can fully produce the board.
I also added some more pictures of the real PCB in the main readme.

I did a quick test on the non-contact voltage detectors. I like the idea very much, and it should be very easy to adapt my PCB to that. Once I have a bit more time I will try to do it, also because it will allow to measure consumption on the devices as well.

I looked at the double switching relay. For what I want I am using this device, it sounds too dangerous to mix mains and low voltage wires. Any mistake and something might go very wrong (I could write an entire book on the numerous stupid mistakes I have done and the tons-of devices I have blown :S )

That is why I added protections against mistakes in every input/output in the PCB. For example:
- Every sensing port has 330k resistance, an 80mA fuse and an optocoupler for isolation. In other words, the mains voltage never reaches the low-voltage sector, and I am pretty confident that it can hold thousands of volts without catching fire or exploding, even if the wires are connected wrongly.
- Outbound relays have 80 or 800mA slow blown fuses. The wet input has a 250mA fast-blowing fuse and a varistor. Pretty safe as well I think. If you connect the relay to the wrong device or plug the wrong wire, you will break the fuse, but probably nothing else.
- The low voltage Power Supply (200V->5v) is a well known brand with 4kV insulation resistance. It does not really need any pretection, but I anyways added a second fast fuse before it. I think this is quite a lot of protection for the microcontroller. I also checked with the oscilloscope and the noise is very low, because of all the capacitors around.

I did some security testing already, for example, I used a Insulation tester passing 1000V. Nothing popped.
I will do it again and take some pictures or a video and post it here. Maybe I can even make a worse case connection as well, to see how does the board reacts if I short-circuit everything :)

Another detail is that I am also coating the PCB with a 90kV/mm2 to avoid any arching. I think this is completely unnecessary because the board is quite protected already, but since it also cost nothing, why not?

In summary, my main goal is to try to not to let any input/output unprotected and consider all worse cases, even making wrong connections or pushing the device to the limits. The idea is that in the worse case you burn a varistor or a fuse, but no people should be in danger and nothing catches fire

I sent some PCBs for manufacture now with the latest design. Not sure where you live, but I could post you an empty one if  you want.

I am still thinking on how to make some video explaining all the design details and showing the assembly and the device working. I could also record the testing of all the protections and common wiring mistakes. The problem is that I don't have any cameras or experience building such video, so it will take a bit of time until I can do it

Closed 2023-02-13.

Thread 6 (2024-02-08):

Multiple Switches/lights

spplecxer, 2024-02-08:
First question: What if I wanted to control multiple lights or power outlets?
Second question: What if I wanted to make every component serviceable/replaceable without having to unsolder/solder anything?
I plan to use a separate esp32 board, separate relay board, even single relay boards (din mounted), separate power supply... I'd like to have your take on this way of doing it.
Thanks.

crgarcia12, 2024-02-09:
Hi @spplecxer, those are very good questions
- This PCB can control 4 different circuits. It is very easy to extend it, I did an 8 one as well. Every circuit can have as many switches/outlets/lights as you want, but they will all turn on/off together.
- The PCB has pin headers for you to do everything externally if you want. For example, you could decide to not to add the PowerSupply or the relays, and use the pinheaders to connect to them. The same goes for the ESP32. I origianlly started the with the same idea in mind, but after a while I realized that connecting low-voltage things around in a DIN rail were not very optimal, and a small mistake can do a big boom, so I decided to make one PCB with everything on it, and use high quality components to make it last (not like Shellys or all those cheap crap that burns all the time).
For example, if you look at the PS or the relays I selected, they are very good ones and I expect them to last long. I also added many fuses with holders, so no need to solder to replace them.
In the other hand, if you want to use external PS or relays boards (which I do for other projects, https://github.com/crgarcia12/electronics-workbench-controller) it should be easy to modify

Let me know what you think!

spplecxer, 2024-02-15:
Thanks for the detailed reply. I will stick with separate components as I want to be able to replace stuff easily. Your second board will suit my needs with some minor modifications. I plan to use single board 30a relays. I will start gathering the parts and will get back to you if I need any help with the project. Thanks.

Closed 2025-02-06.

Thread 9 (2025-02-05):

Features implementation and explanations

paolocesari, 2025-02-05:
Hi @crgarcia12 ,
thank you for this project and for all the work you have dedicated to it.
I really appreciate the quality of the components you chose and also very interesting is the evolution of this project from version 1 to the current one.

I have a few questions:

1) Is it possible to increase the output relays from 8 to 16? Modifying the circuit diagram/PCB or simply pairing two identical boards with a single ESP32? Using SN74LVCH8 + output_enabled version?

2) It is possible to use an ESP32 with ethernet connection instead of wireless?

3) Can it receive magnetic sensor inputs and activate an alarm siren? Adding any input PCB terminals?

Thank you very much for everything.
Paolo

crgarcia12, 2025-02-06:
Hi Paolo,

1)
I believe the easiest way to add another 8 relays is to add another TCAL6416
That IC is an I2C IO expander, so you only need to connect SDA and SDL, and then assign a different ADDR.

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

The board will get quite large though and I think it will not be easy to find a DIN case for it.
All the boards you see in this project were designed based on a off-the-shelf case (I will try to upload another picture in the coming days)

2)
I was also thinking on that at the begining, and I even did a litle pilot. At the end I removed it because to do it properly and with quality you need quite some PCB space and wireless have worked surprisingly good for me. Connection is super stable. There are a lot of schematics that show how to do that on the internet, some of them from trustable sources like Adafruit that can serve as inspiration

3)
That is a good idea. At the moment the board only needs 2 IO to control all inputs and outputs (I2C protocol), so there are a lot of extra pins you can use. Take a look at J12, J13 or J14 in the schematic, or even the GPIO38 that I am currently using to control a RGB LED, that at the end I ended up not using at all in real life 😂  - Would that work for you?

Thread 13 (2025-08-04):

Utilize NCP380 to prevent inrush current when connecting to USB, due to high level of capacitance

crgarcia12, 2025-08-04:

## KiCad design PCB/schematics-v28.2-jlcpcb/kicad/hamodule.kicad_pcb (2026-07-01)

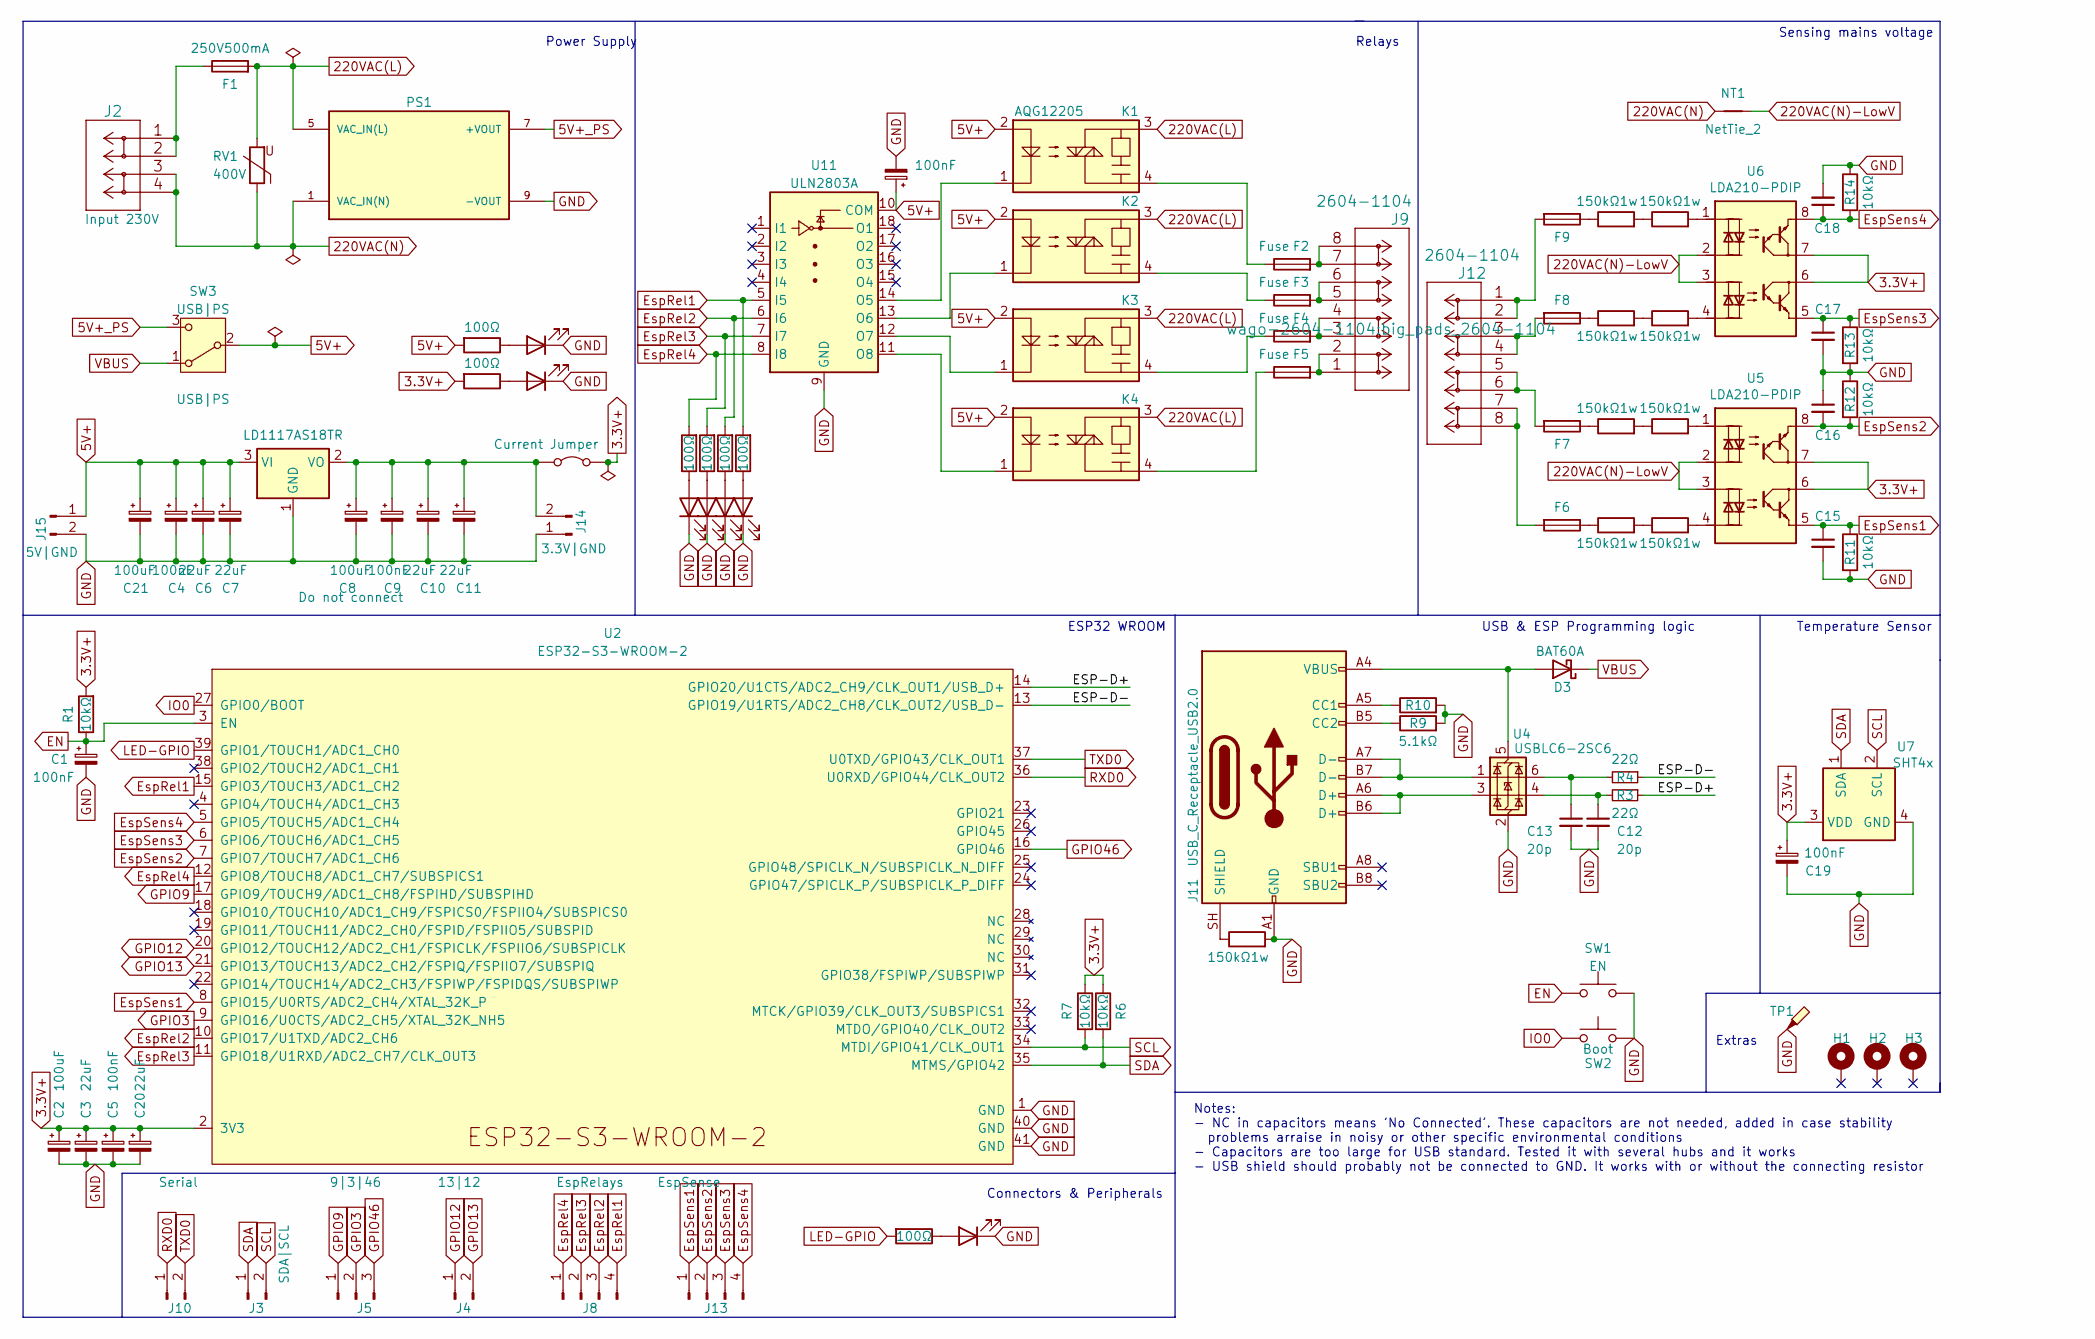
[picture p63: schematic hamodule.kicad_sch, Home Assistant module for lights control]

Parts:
C1, C4, C5, C9, C14, C19: 100nF; C_0603_1608Metric_Pad1.08x0.95mm_HandSolder; JLCPCB C14663
C2: 100uF; C_1206_3216Metric_Pad1.33x1.80mm_HandSolder; JLCPCB C15008
C3, C15, C16, C17, C18: 22uF; C_0603_1608Metric_Pad1.08x0.95mm_HandSolder; JLCPCB C59461
C6, C7, C10, C11, C20: 22uF; C_0805_2012Metric_Pad1.18x1.45mm_HandSolder; JLCPCB C45783
C8, C21: 100uF; CP_Elec_6.3x5.3; JLCPCB C7469977
C12, C13: 20p; C_0603_1608Metric; LCSC C1648
D1, D2, D8: LED; LED_0805_2012Metric_Pad1.15x1.40mm_HandSolder; JLCPCB C2297
D3: BAT60A; D_SOD-323; JLCPCB C124187
D4, D5, D6, D7: LED; LED_0603_1608Metric; JLCPCB C72041
F1: 250V500mA; Fuseholder_TR5_Littelfuse_No560_No460
F2, F3, F4, F5, F6, F7, F8, F9: Fuse; FUSE_RST-1-BULK; JLCPCB C2840857
H1, H2, H3: MountingHole_Pad; MountingHole_3.2mm_M3_ISO14580_Pad
J2: 2604-1102; big_pads_2604-1102; JLCPCB C3309286
J3, J14, J15: PinHeader_1x02_P2.54mm_Vertical; JLCPCB C492401
J4: 13|12; PinHeader_1x02_P2.54mm_Vertical; JLCPCB C492401
J5: 9|3|46; PinHeader_1x03_P2.54mm_Vertical; JLCPCB C49257
J7: Current Jumper; PinHeader_1x02_P2.54mm_Vertical; JLCPCB C492401
J8: EspRelays; PinSocket_1x04_P2.54mm_Vertical; JLCPCB C5116483
J9, J12: 2604-1104; big_pads_2604-1104; JLCPCB C3309598
J10: Serial; PinHeader_1x02_P2.54mm_Vertical; JLCPCB C492401
J11: USB_C_Receptacle_USB2.0; USB_C_Receptacle_HRO_TYPE-C-31-M-12; JLCPCB C167321
J13: EspSense; PinSocket_1x04_P2.54mm_Vertical; JLCPCB C5116483
K1, K2, K3, K4: AQG12205; Manufacturer_Part_Number AQG12205; Mouser Part Number 769-AQG12205
NT1: NetTie_2; NetTie-2_SMD_Pad2.0mm
PS1: RAC05-05SK/277; 277; PARTREV N/A
R1, R6, R7, R11, R12, R13, R14: 10kΩ; R_0603_1608Metric_Pad0.98x0.95mm_HandSolder; JLCPCB C25804
R2, R5, R26: 100Ω; R_0805_2012Metric_Pad1.20x1.40mm_HandSolder; JLCPCB C17408
R3, R4: 22Ω; R_0603_1608Metric; LCSC C23345
R8, R15, R16, R17, R18, R19, R20, R21, R22: 150kΩ1w; R_2512_6332Metric_Pad1.40x3.35mm_HandSolder; JLCPCB C25719
R9, R10: 5.1kΩ; R_0603_1608Metric_Pad0.98x0.95mm_HandSolder; JLCPCB C23186
R23, R24, R25, R27: 100Ω; R_0603_1608Metric_Pad0.98x0.95mm_HandSolder; JLCPCB C22775
RV1: 400V; RV_Disc_D12mm_W4.2mm_P7.5mm
SW1, SW2: Switch; SW_SPST_TL3342; JLCPCB C318884
SW3: USB|PS; PinHeader_1x03_P2.54mm_Vertical; JLCPCB C49257
TP1: GND; TestPoint_THTPad_1.0x1.0mm_Drill0.5mm
U1: LD1117AS18TR; SOT-223-3_TabPin2; JLCPCB C2845037
U2: ESP32-S3-WROOM-2; JLCPCB C2913202
U4: USBLC6-2SC6; SOT-23-6; JLCPCB C2827654
U5, U6: LDA210-PDIP; DIP-8_W7.62mm_Socket_LongPads
U7: SHT4x; Sensirion_DFN-4_1.5x1.5mm_P0.8mm_SHT4x_NoCentralPad; JLCPCB C2909890
U11: ULN2803A; SOIC-18W_7.5x11.6mm_P1.27mm; JLCPCB C845537

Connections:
3.3V+: C2.1, C3.1, C5.1, C19.1, C20.1, J7.2 (B), R1.2, R6.1, R7.1, R26.2, U2.2 (3V3), U5.6, U5.7, U6.6, U6.7, U7.3 (VDD)
5V+: C4.1, C6.1, C7.1, C14.1, C21.1, J15.1, K1.2, K2.2, K3.2, K4.2, R2.2, SW3.2 (B), U1.3 (VI), U11.10 (COM)
5V+_PS: PS1.7 (+VOUT), SW3.3 (C)
220VAC(L): F1.2, K1.3, K2.3, K3.3, K4.3, PS1.5 (VAC_IN(L)), RV1.2
220VAC(N): J2.3, J2.4, NT1.1, PS1.1 (VAC_IN(N)), RV1.1
220VAC(N)-LowV: NT1.2, U5.2, U5.3, U6.2, U6.3
/ESP-D+: R3.1, U2.14 (GPIO20/U1CTS/ADC2_CH9/CLK_OUT1/USB_D+)
/ESP-D-: R4.1, U2.13 (GPIO19/U1RTS/ADC2_CH8/CLK_OUT2/USB_D-)
EN: C1.1, R1.1, SW1.1, U2.3 (EN)
EspRel1: J8.4, R23.2, U2.15 (GPIO3/TOUCH3/ADC1_CH2), U11.5 (I5)
EspRel2: J8.3, R24.2, U2.10 (GPIO17/U1TXD/ADC2_CH6), U11.6 (I6)
EspRel3: J8.2, R25.2, U2.11 (GPIO18/U1RXD/ADC2_CH7/CLK_OUT3), U11.7 (I7)
EspRel4: J8.1, R27.2, U2.12 (GPIO8/TOUCH8/ADC1_CH7/SUBSPICS1), U11.8 (I8)
EspSens1: C15.1, J13.1, R11.1, U2.8 (GPIO15/U0RTS/ADC2_CH4/XTAL_32K_P), U5.5
EspSens2: C16.2, J13.2, R12.2, U2.7 (GPIO7/TOUCH7/ADC1_CH6), U5.8
EspSens3: C17.1, J13.3, R13.1, U2.6 (GPIO6/TOUCH6/ADC1_CH5), U6.5
EspSens4: C18.1, J13.4, R14.2, U2.5 (GPIO5/TOUCH5/ADC1_CH4), U6.8
GND: C1.2, C2.2, C3.2, C4.2, C5.2, C6.2, C7.2, C8.2, C9.2, C10.2, C11.2, C12.2, C13.2, C14.2, C15.2, C16.1, C17.2, C18.2, C19.2, C20.2, C21.2, D1.1 (K), D2.1 (K), D4.1 (K), D5.1 (K), D6.1 (K), D7.1 (K), D8.1 (K), J11.A1 (GND), J11.A12 (GND), J11.B1 (GND), J11.B12 (GND), J14.1, J15.2, PS1.9 (-VOUT), R8.2, R9.2, R10.2, R11.2, R12.1, R13.2, R14.1, SW1.2, SW2.2, TP1.1 (1_1), U1.1 (GND), U2.1 (GND), U2.40 (GND), U2.41 (GND), U4.2 (GND), U7.4 (GND), U11.9 (GND)
GPIO3: J5.2, U2.9 (GPIO16/U0CTS/ADC2_CH5/XTAL_32K_NH5)
GPIO9: J5.1, U2.17 (GPIO9/TOUCH9/ADC1_CH8/FSPIHD/SUBSPIHD)
GPIO12: J4.1, U2.20 (GPIO12/TOUCH12/ADC2_CH1/FSPICLK/FSPIIO6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)
GPIO13: J4.2, U2.21 (GPIO13/TOUCH13/ADC2_CH2/FSPIQ/FSPIIO7/S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)
GPIO46: J5.3, U2.16 (GPIO46)
IO0: SW2.1, U2.27 (GPIO0/BOOT)
LED-GPIO: R5.2, U2.39 (GPIO1/TOUCH1/ADC1_CH0)
unnamed: C12.1, R3.2, U4.4 (I/O2)
unnamed: C13.1, R4.2, U4.6 (I/O1)
unnamed: D1.2 (A), R2.1
unnamed: D2.2 (A), R5.1
unnamed: D3.2 (A), J11.A4 (VBUS), J11.A9 (VBUS), J11.B4 (VBUS), J11.B9 (VBUS), U4.5 (VBUS)
unnamed: D4.2 (A), R23.1
unnamed: D5.2 (A), R24.1
unnamed: D6.2 (A), R25.1
unnamed: D7.2 (A), R27.1
unnamed: D8.2 (A), R26.1
unnamed: F1.1, J2.1, J2.2
unnamed: F2.1, K1.4
unnamed: F2.2, J9.7, J9.8
unnamed: F3.1, K2.4
unnamed: F3.2, J9.5, J9.6
unnamed: F4.1, K3.4
unnamed: F4.2, J9.3, J9.4
unnamed: F5.1, K4.4
unnamed: F5.2, J9.1, J9.2
unnamed: F6.1, R19.1
unnamed: F6.2, J12.7, J12.8
unnamed: F7.1, R20.1
unnamed: F7.2, J12.5, J12.6
unnamed: F8.1, R21.1
unnamed: F8.2, J12.3, J12.4
unnamed: F9.1, R22.1
unnamed: F9.2, J12.1, J12.2
unnamed: J11.A5 (CC1), R10.1
unnamed: J11.B5 (CC2), R9.1
unnamed: J11.A6 (D+), J11.B6 (D+), U4.3 (I/O2)
unnamed: J11.A7 (D-), J11.B7 (D-), U4.1 (I/O1)
unnamed: J11.SH (SHIELD), R8.1
unnamed: C8.1, C9.1, C10.1, C11.1, J7.1 (A), J14.2, U1.2 (VO)
unnamed: R15.1, R19.2
unnamed: R15.2, U5.4
unnamed: R16.1, R20.2
unnamed: R16.2, U5.1
unnamed: R17.1, R21.2
unnamed: R17.2, U6.4
unnamed: R18.1, R22.2
unnamed: R18.2, U6.1
unnamed: K1.1, U11.14 (O5)
unnamed: K2.1, U11.13 (O6)
unnamed: K3.1, U11.12 (O7)
unnamed: K4.1, U11.11 (O8)
RXD0: J10.1, U2.36 (U0RXD/GPIO44/CLK_OUT2)
SCL: J3.2, R7.2, U2.34 (MTDI/GPIO41/CLK_OUT1), U7.2 (SCL)
SDA: J3.1, R6.2, U2.35 (MTMS/GPIO42), U7.1 (SDA)
TXD0: J10.2, U2.37 (U0TXD/GPIO43/CLK_OUT1)
VBUS: D3.1 (K), SW3.1 (A)

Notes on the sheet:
USB & ESP Programming logic
Relays
Temperature Sensor
Power Supply
Extras
Connectors & Peripherals
ESP32 WROOM
Notes: - NC in capacitors means 'No Connected'. These capacitors are not needed, added in case stability problems arraise in noisy or other specific environmental conditions - Capacitors are too large for USB standard. Tested it with several hubs and it works - USB shield should probably not be con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
Sensing mains voltage

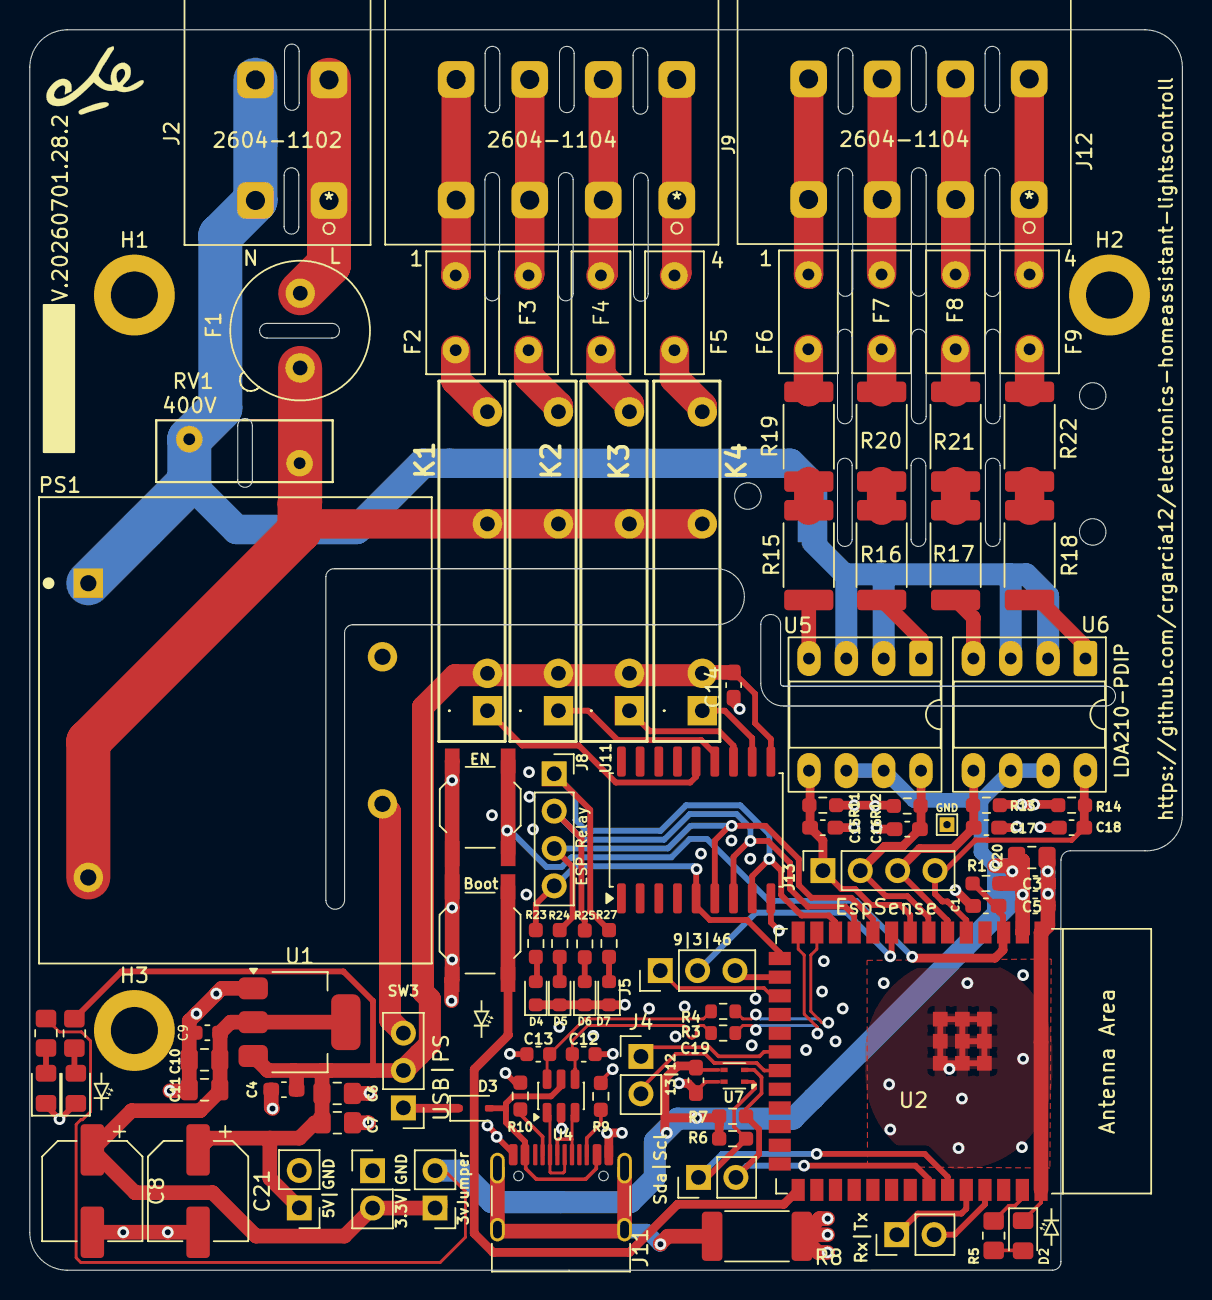
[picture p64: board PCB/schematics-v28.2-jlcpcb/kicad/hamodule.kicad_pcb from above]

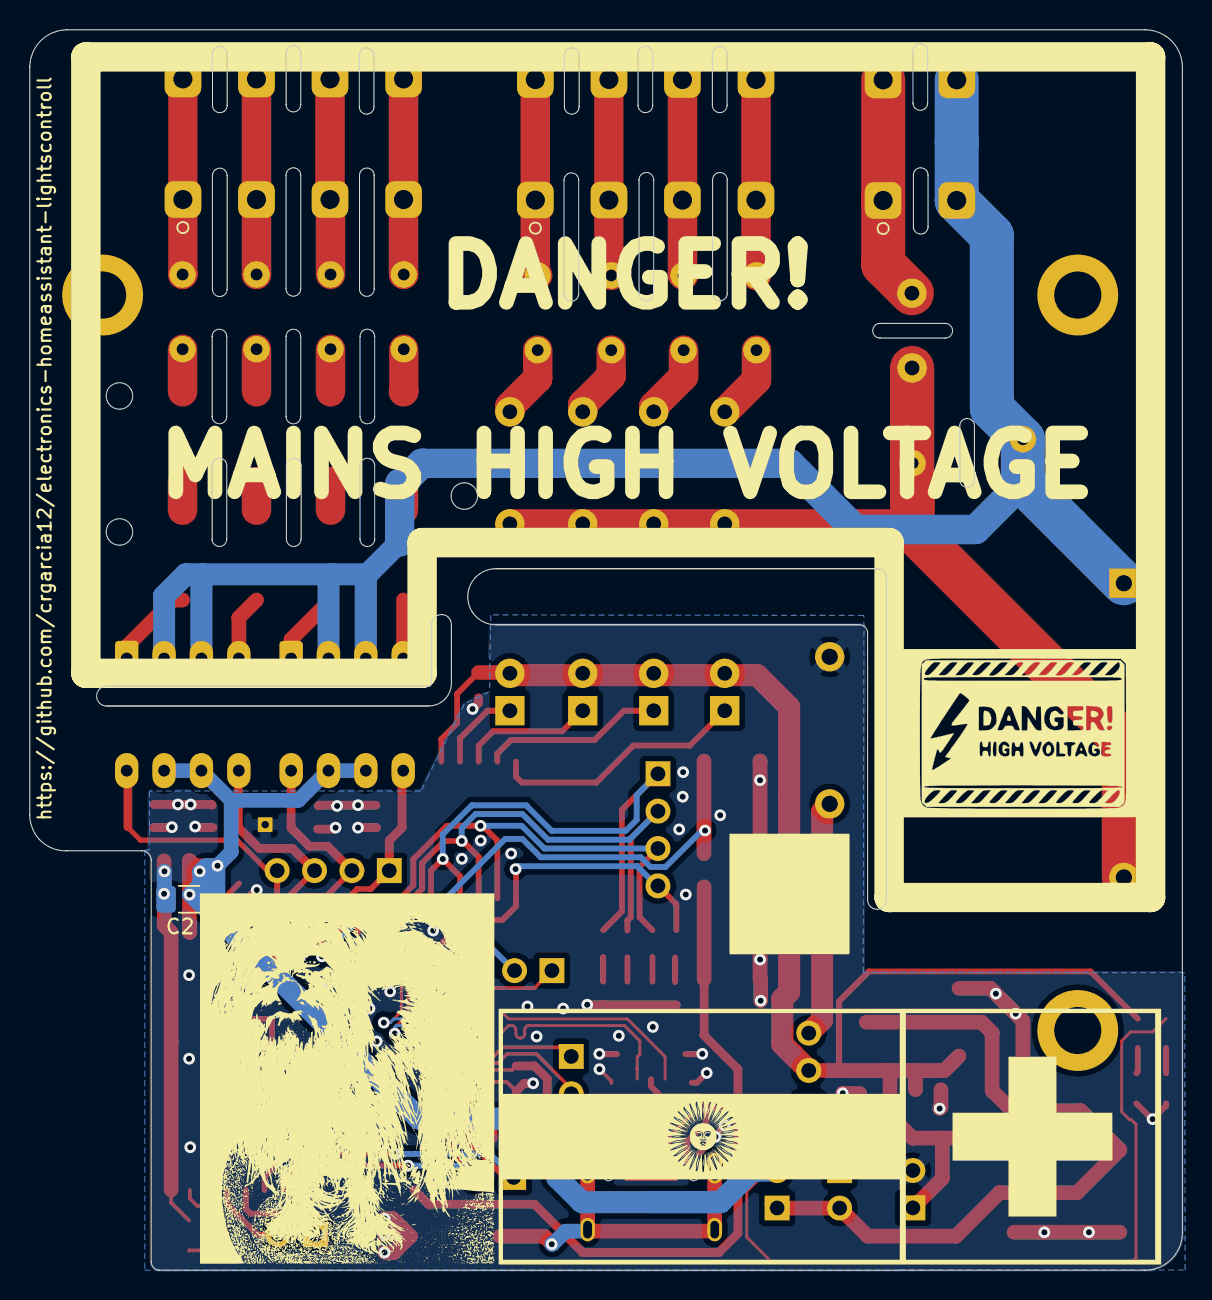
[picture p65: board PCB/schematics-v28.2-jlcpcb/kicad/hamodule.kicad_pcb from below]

Board: 4 copper layers, 78.4 x 84.3 mm, 106 parts (5 on the bottom side), 75 nets.

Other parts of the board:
G1: LOGO; che
G2, G2#2, G4: LOGO; led_6000dpi
G3: LOGO; danger1_negative
G5: LOGO; depsi
G6: LOGO; flags

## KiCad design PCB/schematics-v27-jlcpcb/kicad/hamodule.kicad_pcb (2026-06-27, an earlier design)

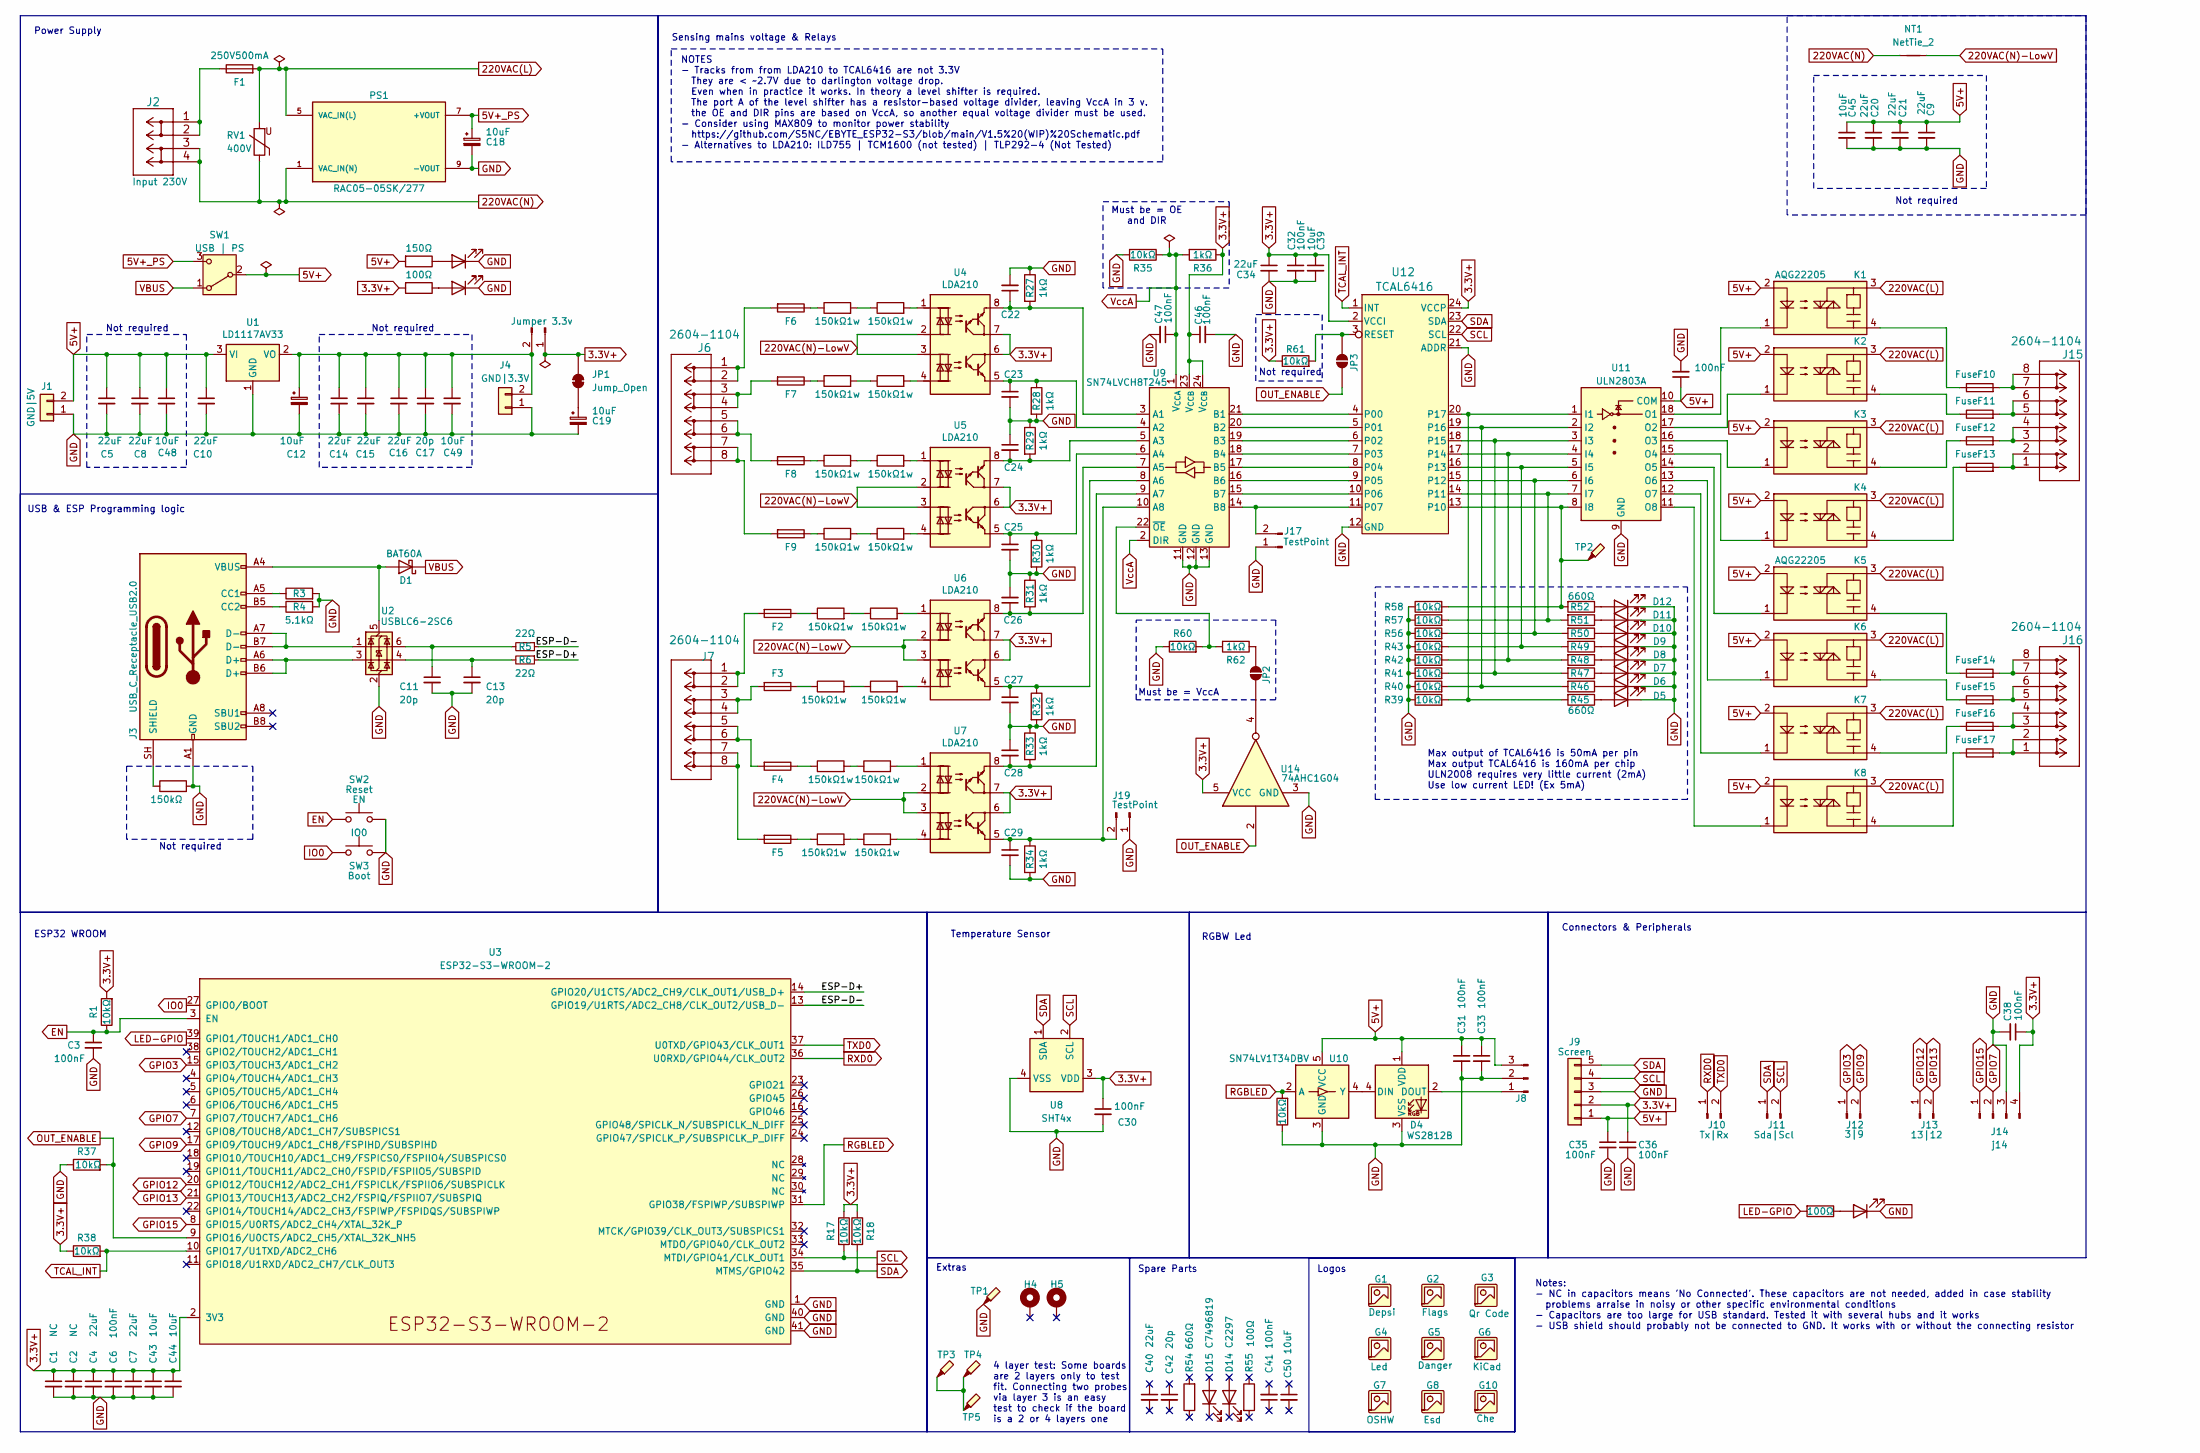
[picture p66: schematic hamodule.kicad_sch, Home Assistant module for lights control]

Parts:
C1, C2: NC; C_1206_3216Metric_Pad1.33x1.80mm_HandSolder
C3, C6, C30, C31, C33, C46, C47: 100nF; C_0603_1608Metric_Pad1.08x0.95mm_HandSolder; JLCPCB C14663
C4, C22, C23, C24, C25, C26, C27, C28, C29, C40: 22uF; C_0603_1608Metric_Pad1.08x0.95mm_HandSolder; JLCPCB C59461
C5, C7, C8, C10, C14, C15, C16, C20, C21, C34: 22uF; C_0805_2012Metric_Pad1.18x1.45mm_HandSolder; JLCPCB C45783
C9: 22uF; C_0805_2012Metric_Pad1.18x1.45mm_HandSolder; LCSC C45783
C11, C13, C17, C42: 20p; C_0603_1608Metric_Pad1.08x0.95mm_HandSolder; LCSC C1648
C12, C18, C19: 10uF; CP_Radial_D6.3mm_P2.50mm
C32, C35, C36, C37, C38, C41: 100nF; C_0805_2012Metric_Pad1.18x1.45mm_HandSolder; JLCPCB C49678
C39, C43, C44, C45, C48, C49, C50: 10uF; C_0402_1005Metric; JLCPCB C15525
D1: BAT60A; D_SOD-323; JLCPCB C124187
D2: 5V; LED_0805_2012Metric_Pad1.15x1.40mm_HandSolder; JLCPCB C2297
D3: 3.3V; LED_0805_2012Metric_Pad1.15x1.40mm_HandSolder; JLCPCB C2297
D4: WS2812B; LED_WS2812B_PLCC4_5.0x5.0mm_P3.2mm; JLCPCB C5446705
D5, D6, D7, D8, D9, D10, D11, D12: LED; LED_0603_1608Metric; JLCPCB C7496819
D13: LED; LED_0805_2012Metric_Pad1.15x1.40mm_HandSolder; JLCPCB C2297
D14: C2297; LED_0805_2012Metric_Pad1.15x1.40mm_HandSolder; JLCPCB C2297
D15: C7496819; LED_0603_1608Metric; JLCPCB C7496819
F1: 250V500mA; Fuseholder_TR5_Littelfuse_No560_No460
F2, F3, F4, F5, F6, F7, F8, F9, F10, F11, F12, F13, F14, F15, F16, F17: Fuse; FUSE_RST-1-BULK
G1: Depsi; depsi
G2: Flags; flags
G3: Qr Code; qr_code
G4: Led; led
G5: Danger; danger
G6: KiCad; KiCad-Logo2_5mm_SilkScreen
G7: OSHW; OSHW-Logo2_7.3x6mm_SilkScreen
G8: Esd; ESD-Logo_6.6x6mm_SilkScreen
G10: Che; che
H4, H5: MountingHole_Pad; MountingHole_3.2mm_M3_ISO14580_Pad
J1: GND|5V; JST_XH_B2B-XH-A_1x02_P2.50mm_Vertical; JLCPCB C158012
J2: 2604-1102; WAGO-2604-1102
J3: USB_C_Receptacle_USB2.0; USB_C_Receptacle_HRO_TYPE-C-31-M-12; JLCPCB C2927038
J4: GND|3.3V; JST_XH_B2B-XH-A_1x02_P2.50mm_Vertical; JLCPCB C158012
J5: Jumper 3.3v; PinHeader_1x02_P2.54mm_Vertical; JLCPCB C492401
J6, J7, J15, J16: 2604-1104; WAGO_2604-1104; JLCPCB C3309598
J8: 5v|GND|Do; PinHeader_1x03_P2.54mm_Vertical; JLCPCB C49257
J9: Screen; JST_XH_B5B-XH-A_1x05_P2.50mm_Vertical; JLCPCB C32713270
J10: Tx|Rx; PinHeader_1x02_P2.54mm_Vertical; JLCPCB C492401
J11: Sda|Scl; PinHeader_1x02_P2.54mm_Vertical; JLCPCB C492401
J12: 3|9; PinHeader_1x02_P2.54mm_Vertical; JLCPCB C492401
J13: 13|12; PinHeader_1x02_P2.54mm_Vertical; JLCPCB C492401
J14: j14; PinHeader_1x04_P2.54mm_Vertical; JLCPCB C49257
J17, J19: TestPoint; PinHeader_1x02_P2.54mm_Vertical
JP1: Jump_Open; SolderJumper-2_P1.3mm_Bridged2Bar_RoundedPad1.0x1.5mm
JP2: SolderJumper-2_P1.3mm_Open_RoundedPad1.0x1.5mm
JP3: Jump_Closed; SolderJumper-2_P1.3mm_Open_RoundedPad1.0x1.5mm
K1, K2, K3, K4, K5, K6, K7, K8: AQG22205; AQG12205; Manufacturer_Part_Number AQG12205; Mouser Part Number 769-AQG12205
NT1: NetTie_2; NetTie-2_SMD_Pad2.0mm
PS1: RAC05-05SK/277; RAC05-05SK_277; PARTREV N/A
R1, R17, R18, R35, R37, R38, R39, R40, R41, R42, R43, R44, R56, R57, R58, R60, R61: 10kΩ; R_0603_1608Metric_Pad0.98x0.95mm_HandSolder; JLCPCB C25804
R2: 150kΩ; R_0805_2012Metric_Pad1.20x1.40mm_HandSolder; JLCPCB C17470
R3, R4: 5.1kΩ; R_0603_1608Metric_Pad0.98x0.95mm_HandSolder; JLCPCB C23186
R5, R6: 22Ω; R_0603_1608Metric; LCSC C23345
R7: 150Ω; R_0805_2012Metric_Pad1.20x1.40mm_HandSolder; JLCPCB C17437
R8, R53, R55: 100Ω; R_0805_2012Metric_Pad1.20x1.40mm_HandSolder; JLCPCB C17408
R9, R10, R11, R12, R13, R14, R15, R16, R19, R20, R21, R22, R23, R24, R25, R26: 150kΩ1w; R_2512_6332Metric_Pad1.40x3.35mm_HandSolder; JLCPCB C25719
R27, R28, R29, R30, R31, R32, R33, R34, R36, R62: 1kΩ; R_0603_1608Metric_Pad0.98x0.95mm_HandSolder; JLCPCB C21190
R45, R46, R47, R48, R49, R50, R51, R52, R54: 660Ω; R_0603_1608Metric_Pad0.98x0.95mm_HandSolder; JLCPCB C23193
RV1: 400V; RV_Disc_D12mm_W4.2mm_P7.5mm
SW1: USB | PS; PinHeader_1x03_P2.54mm_Vertical; JLCPCB C49257
SW2: Reset; SW_SPST_SKQG_WithStem; JLCPCB C318884
SW3: Boot; SW_SPST_SKQG_WithStem; JLCPCB C318884
TP1: GND; TestPoint_THTPad_1.0x1.0mm_Drill0.5mm
TP2: I8; TestPoint_THTPad_1.0x1.0mm_Drill0.5mm
TP3, TP4, TP5: 4 layer test; TestPoint_THTPad_1.0x1.0mm_Drill0.5mm
U1: LD1117AV33; TO-220-3_Vertical; JLCPCB C32833
U2: USBLC6-2SC6; SOT-23-6; JLCPCB C2827654
U3: ESP32-S3-WROOM-2; JLCPCB C2913202
U4, U5, U6, U7: LDA210; DIP-8_W7.62mm_Socket_LongPads
U8: SHT4x; Sensirion_DFN-4_1.5x1.5mm_P0.8mm_SHT4x_NoCentralPad; JLCPCB C2909890
U9: SN74LVCH8T245; TSSOP-24_4.4x7.8mm_P0.65mm; JLCPCB C201741
U10: SN74LV1T34DBV; SOT-23-5; JLCPCB C100024
U11: ULN2803A; SOIC-18W_7.5x11.6mm_P1.27mm; JLCPCB C845537
U12: TCAL6416; TSSOP-24_4.4x7.8mm_P0.65mm; JLCPCB C20345827
U14: 74AHC1G04; SOT-23-5_HandSoldering; JLCPCB C460485

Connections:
3.3V+: C1.1, C2.1, C4.1, C6.1, C7.1, C30.1, C32.1, C34.1, C36.1, C38.1, C39.1, C43.1, C44.1, C46.1, J5.1, J9.2, J14.4, JP1.1 (A), R1.2, R8.2, R17.1, R18.1, R36.1, R38.1, R61.1, U3.2 (3V3), U4.6, U4.7, U5.6, U5.7, U6.6, U6.7, U7.6, U7.7, U8.3 (VDD), U9.23 (V_{CCB}), U9.24 (V_{CCB}), U12.2 (VCCI), U12.24 (VCCP), U14.5 (VCC)
5V+: C5.1, C8.1, C9.1, C10.1, C20.1, C21.1, C31.1, C33.1, C35.1, C37.1, C45.1, C48.1, D4.1 (VDD), J1.2, J8.3, J9.1, K1.2, K2.2, K3.2, K4.2, K5.2, K6.2, K7.2, K8.2, R7.2, SW1.2 (B), U1.3 (VI), U10.5 (VCC), U11.10 (COM)
5V+_PS: C18.1, PS1.7 (+VOUT), SW1.3 (C)
220VAC(L): F1.2, K1.3, K2.3, K3.3, K4.3, K5.3, K6.3, K7.3, K8.3, PS1.5 (VAC_IN(L)), RV1.2
220VAC(N): J2.3, J2.4, NT1.1, PS1.1 (VAC_IN(N)), RV1.1
220VAC(N)-LowV: NT1.2, U4.2, U4.3, U5.2, U5.3, U6.2, U6.3, U7.2, U7.3
/ESP-D+: R6.1, U3.14 (GPIO20/U1CTS/ADC2_CH9/CLK_OUT1/USB_D+)
/ESP-D-: R5.1, U3.13 (GPIO19/U1RTS/ADC2_CH8/CLK_OUT2/USB_D-)
EN: C3.1, R1.1, SW2.1, U3.3 (EN)
GND: C1.2, C2.2, C3.2, C4.2, C5.2, C6.2, C7.2, C8.2, C9.2, C10.2, C11.2, C12.2, C13.2, C14.2, C15.2, C16.2, C17.2, C18.2, C19.2, C20.2, C21.2, C22.2, C23.2, C24.1, C25.2, C26.2, C27.2, C28.1, C29.2, C30.2, C31.2, C32.2, C33.2, C34.2, C35.2, C36.2, C37.2, C38.2, C39.2, C43.2, C44.2, C45.2, C46.2, C47.2, C48.2, C49.2, D2.1 (K), D3.1 (K), D4.3 (VSS), D5.1 (K), D6.1 (K), D7.1 (K), D8.1 (K), D9.1 (K), D10.1 (K), D11.1 (K), D12.1 (K), D13.1 (K), J1.1, J3.A1 (GND), J3.A12 (GND), J3.B1 (GND), J3.B12 (GND), J4.1, J8.2, J9.3, J14.3, J17.1, J19.1, PS1.9 (-VOUT), R2.2, R3.2, R4.2, R27.1, R28.2, R29.1, R30.2, R31.1, R32.2, R33.1, R34.2, R35.2, R37.1, R39.1, R40.1, R41.1, R42.1, R43.1, R44.1, R56.1, R57.1, R58.1, R60.1, SW2.2, SW3.2, TP1.1 (1_1), U1.1 (GND), U2.2 (GND), U3.1 (GND), U3.40 (GND), U3.41 (GND), U8.4 (VSS), U9.11 (GND), U9.12 (GND), U9.13 (GND), U10.3 (GND), U11.9 (GND), U12.12 (GND), U12.21 (ADDR), U14.3 (GND)
GPIO3: J12.1, U3.15 (GPIO3/TOUCH3/ADC1_CH2)
GPIO7: J14.2, U3.7 (GPIO7/TOUCH7/ADC1_CH6)
GPIO9: J12.2, U3.17 (GPIO9/TOUCH9/ADC1_CH8/FSPIHD/SUBSPIHD)
GPIO12: J13.1, U3.20 (GPIO12/TOUCH12/ADC2_CH1/FSPICLK/FSPIIO6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)
GPIO13: J13.2, U3.21 (GPIO13/TOUCH13/ADC2_CH2/FSPIQ/FSPIIO7/S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)
GPIO15: J14.1, U3.8 (GPIO15/U0RTS/ADC2_CH4/XTAL_32K_P)
IO0: SW3.1, U3.27 (GPIO0/BOOT)
LED-GPIO: R53.2, U3.39 (GPIO1/TOUCH1/ADC1_CH0)
unnamed: C11.1, R5.2, U2.6 (I/O1)
unnamed: C13.1, R6.2, U2.4 (I/O2)
unnamed: D1.2 (A), J3.A4 (VBUS), J3.A9 (VBUS), J3.B4 (VBUS), J3.B9 (VBUS), U2.5 (VBUS)
unnamed: D2.2 (A), R7.1
unnamed: D3.2 (A), R8.1
unnamed: D4.4 (DIN), U10.4 (Y)
unnamed: D4.2 (DOUT), J8.1
unnamed: D5.2 (A), R45.1
unnamed: D6.2 (A), R46.1
unnamed: D7.2 (A), R47.1
unnamed: D8.2 (A), R48.1
unnamed: D9.2 (A), R49.1
unnamed: D10.2 (A), R50.1
unnamed: D11.2 (A), R51.1
unnamed: D12.2 (A), R52.1
unnamed: D13.2 (A), R53.1
unnamed: F1.1, J2.1, J2.2
unnamed: F2.1, R9.1
unnamed: F2.2, J7.1, J7.2
unnamed: F3.1, R10.1
unnamed: F3.2, J7.3, J7.4
unnamed: F4.1, R11.1
unnamed: F4.2, J7.5, J7.6
unnamed: F5.1, R12.1
unnamed: F5.2, J7.7, J7.8
unnamed: F6.1, R13.1
unnamed: F6.2, J6.1, J6.2
unnamed: F7.1, R14.1
unnamed: F7.2, J6.3, J6.4
unnamed: F8.1, R15.1
unnamed: F8.2, J6.5, J6.6
unnamed: F9.1, R16.1
unnamed: F9.2, J6.7, J6.8
unnamed: F10.1, K1.4
unnamed: F10.2, J15.7, J15.8
unnamed: F11.1, K2.4
unnamed: F11.2, J15.5, J15.6
unnamed: F12.1, K3.4
unnamed: F12.2, J15.3, J15.4
unnamed: F13.1, K4.4
unnamed: F13.2, J15.1, J15.2
unnamed: F14.1, K5.4
unnamed: F14.2, J16.7, J16.8
unnamed: F15.1, K6.4
unnamed: F15.2, J16.5, J16.6
unnamed: F16.1, K7.4
unnamed: F16.2, J16.3, J16.4
unnamed: F17.1, K8.4
unnamed: F17.2, J16.1, J16.2
unnamed: J3.A5 (CC1), R3.1
unnamed: J3.B5 (CC2), R4.1
unnamed: J3.A6 (D+), J3.B6 (D+), U2.3 (I/O2)
unnamed: J3.A7 (D-), J3.B7 (D-), U2.1 (I/O1)
unnamed: J3.SH (SHIELD), R2.1
unnamed: C12.1, C14.1, C15.1, C16.1, C17.1, C49.1, J4.2, J5.2, U1.2 (VO)
unnamed: J17.2, U9.14 (B8), U12.11 (P07)
unnamed: C29.1, J19.2, R34.1, U7.5, U9.10 (A8)
unnamed: C19.1, JP1.2 (B)
unnamed: JP2.1 (A), R62.1
unnamed: JP2.2 (B), U14.4
unnamed: JP3.1 (A), R61.2, U12.3 (RESET)
unnamed: R10.2, R22.1
unnamed: R11.2, R19.1
unnamed: R12.2, R20.1
unnamed: R13.2, R23.1
unnamed: R14.2, R24.1
unnamed: R15.2, R25.1
unnamed: R16.2, R26.1
unnamed: R19.2, U7.1
unnamed: R20.2, U7.4
unnamed: R9.2, R21.1
unnamed: R21.2, U6.1
unnamed: R22.2, U6.4
unnamed: R23.2, U4.1
unnamed: R24.2, U4.4
unnamed: R25.2, U5.1
unnamed: R26.2, U5.4
unnamed: TP3.1 (1_1), TP4.1 (1_1), TP5.1 (1_1)
unnamed: C22.1, R27.2, U4.8, U9.3 (A1)
unnamed: C23.1, R28.1, U4.5, U9.4 (A2)
unnamed: C24.2, R29.2, U5.8, U9.5 (A3)
unnamed: C25.1, R30.1, U5.5, U9.6 (A4)
unnamed: C26.1, R31.2, U6.8, U9.7 (A5)
unnamed: C27.1, R32.1, U6.5, U9.8 (A6)
unnamed: C28.2, R33.2, U7.8, U9.9 (A7)
unnamed: R60.2, R62.2, U9.22 (~OE)
unnamed: R39.2, R45.2, U11.1 (I1), U12.20 (P17)
unnamed: R40.2, R46.2, U11.2 (I2), U12.19 (P16)
unnamed: R41.2, R47.2, U11.3 (I3), U12.18 (P15)
unnamed: R42.2, R48.2, U11.4 (I4), U12.17 (P14)
unnamed: R43.2, R49.2, U11.5 (I5), U12.16 (P13)
unnamed: R50.2, R56.2, U11.6 (I6), U12.15 (P12)
unnamed: R51.2, R57.2, U11.7 (I7), U12.14 (P11)
unnamed: R52.2, R58.2, TP2.1 (1_1), U11.8 (I8), U12.13 (P10)
unnamed: K1.1, U11.18 (O1)
unnamed: K2.1, U11.17 (O2)
unnamed: K3.1, U11.16 (O3)
unnamed: K4.1, U11.15 (O4)
unnamed: K5.1, U11.14 (O5)
unnamed: K6.1, U11.13 (O6)
unnamed: K7.1, U11.12 (O7)
unnamed: K8.1, U11.11 (O8)
unnamed: U9.21 (B1), U12.4 (P00)
unnamed: U9.20 (B2), U12.5 (P01)
unnamed: U9.19 (B3), U12.6 (P02)
unnamed: U9.18 (B4), U12.7 (P03)
unnamed: U9.17 (B5), U12.8 (P04)
unnamed: U9.16 (B6), U12.9 (P05)
unnamed: U9.15 (B7), U12.10 (P06)
OUT_ENABLE: JP3.2 (B), R37.2, U3.9 (GPIO16/U0CTS/ADC2_CH5/XTAL_32K_NH5), U14.2
RGBLED: R44.2, U3.31 (GPIO38/FSPIWP/SUBSPIWP), U10.2 (A)
RXD0: J10.1, U3.36 (U0RXD/GPIO44/CLK_OUT2)
SCL: J9.4, J11.2, R17.2, U3.34 (MTDI/GPIO41/CLK_OUT1), U8.2 (SCL), U12.22 (SCL)
SDA: J9.5, J11.1, R18.2, U3.35 (MTMS/GPIO42), U8.1 (SDA), U12.23 (SDA)
TCAL_INT: R38.2, U3.10 (GPIO17/U1TXD/ADC2_CH6), U12.1 (INT)
TXD0: J10.2, U3.37 (U0TXD/GPIO43/CLK_OUT1)
VBUS: D1.1 (K), SW1.1 (A)
VccA: C47.1, R35.1, R36.2, U9.1 (V_{CCA}), U9.2 (DIR)

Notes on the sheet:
Must be = VccA
USB & ESP Programming logic
NOTES - Tracks from from LDA210 to TCAL6416 are not 3.3V They are < ~2.7V due to darlington voltage drop. Even when in practice it works. In theory a level shifter is required. The port A of the level shifter has a resistor-based voltage divider, leaving VccA in 3 v. the OE and DIR pins are based o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
Must be = OE and DIR
Spare Parts
Not required
Temperature Sensor
Power Supply
Logos
Extras
Max output of TCAL6416 is 50mA per pin Max output TCAL6416 is 160mA per chip ULN2008 requires very little current (2mA) Use low current LED! (Ex 5mA)
Connectors & Peripherals
4 layer test: Some boards are 2 layers only to test fit. Connecting two probes via layer 3 is an easy test to check if the board is a 2 or 4 layers one
ESP32 WROOM
RGBW Led
Notes: - NC in capacitors means 'No Connected'. These capacitors are not needed, added in case stability problems arraise in noisy or other specific environmental conditions - Capacitors are too large for USB standard. Tested it with several hubs and it works - USB shield should probably not be con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
Sensing mains voltage & Relays

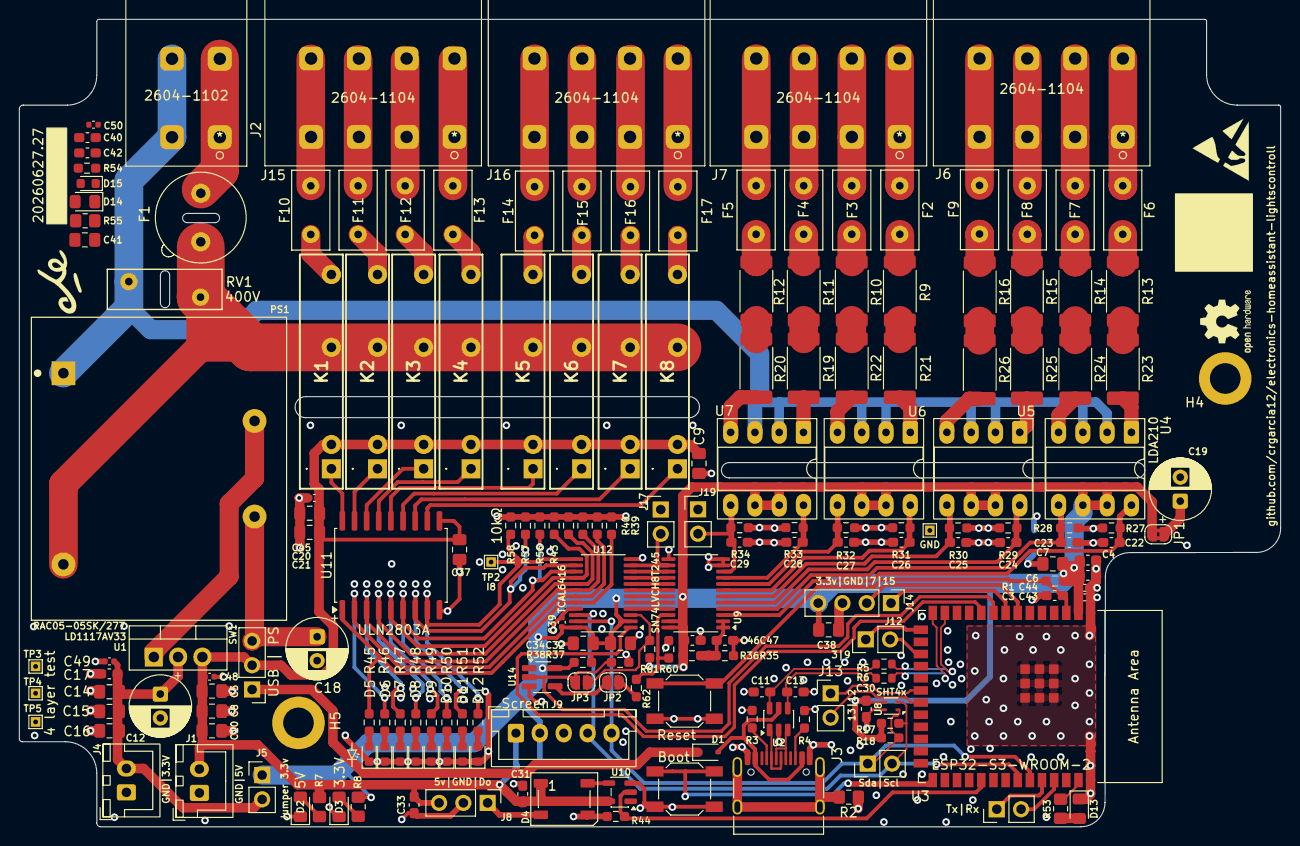
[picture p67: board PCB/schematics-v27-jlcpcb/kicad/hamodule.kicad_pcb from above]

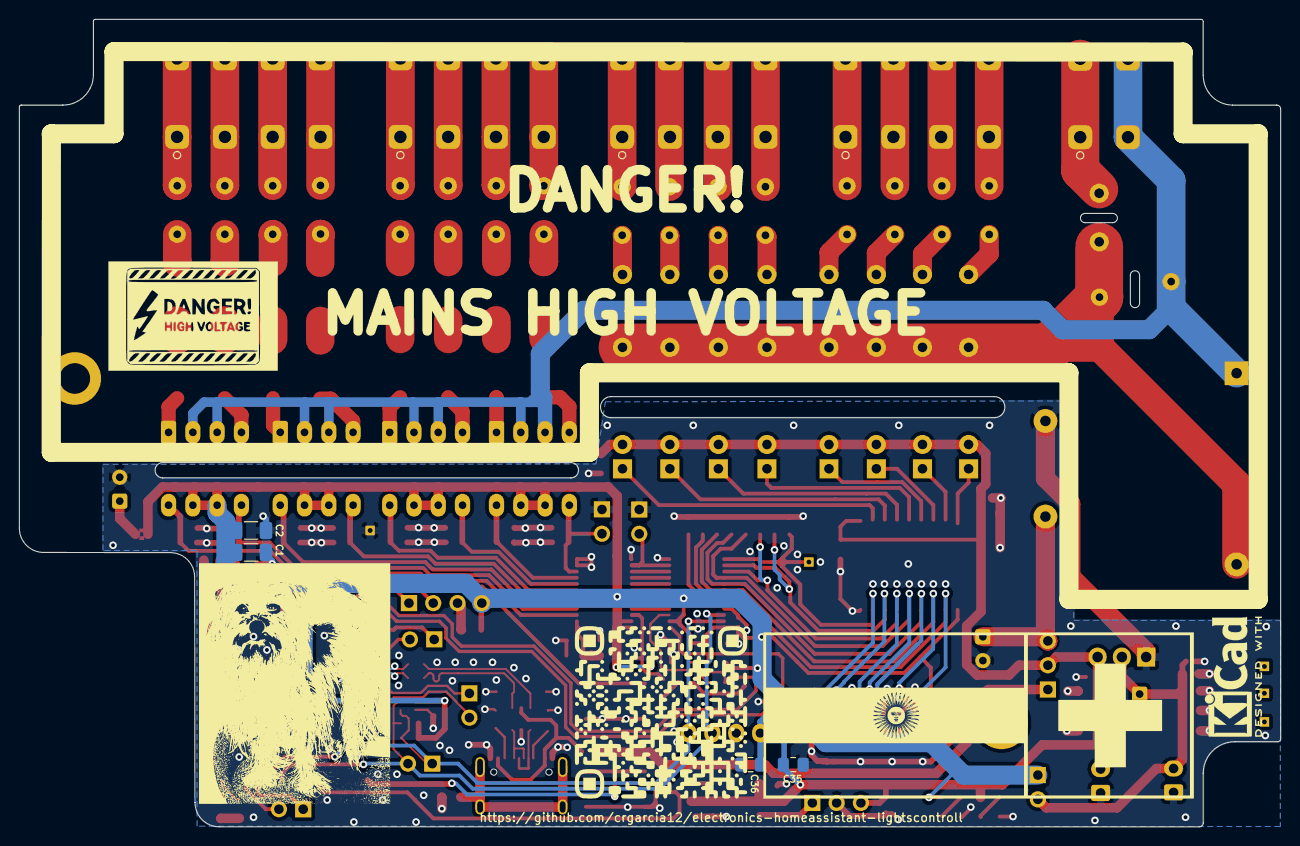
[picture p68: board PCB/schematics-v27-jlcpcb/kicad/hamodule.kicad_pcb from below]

Board: 4 copper layers, 131.9 x 84.5 mm, 207 parts (10 on the bottom side), 136 nets.

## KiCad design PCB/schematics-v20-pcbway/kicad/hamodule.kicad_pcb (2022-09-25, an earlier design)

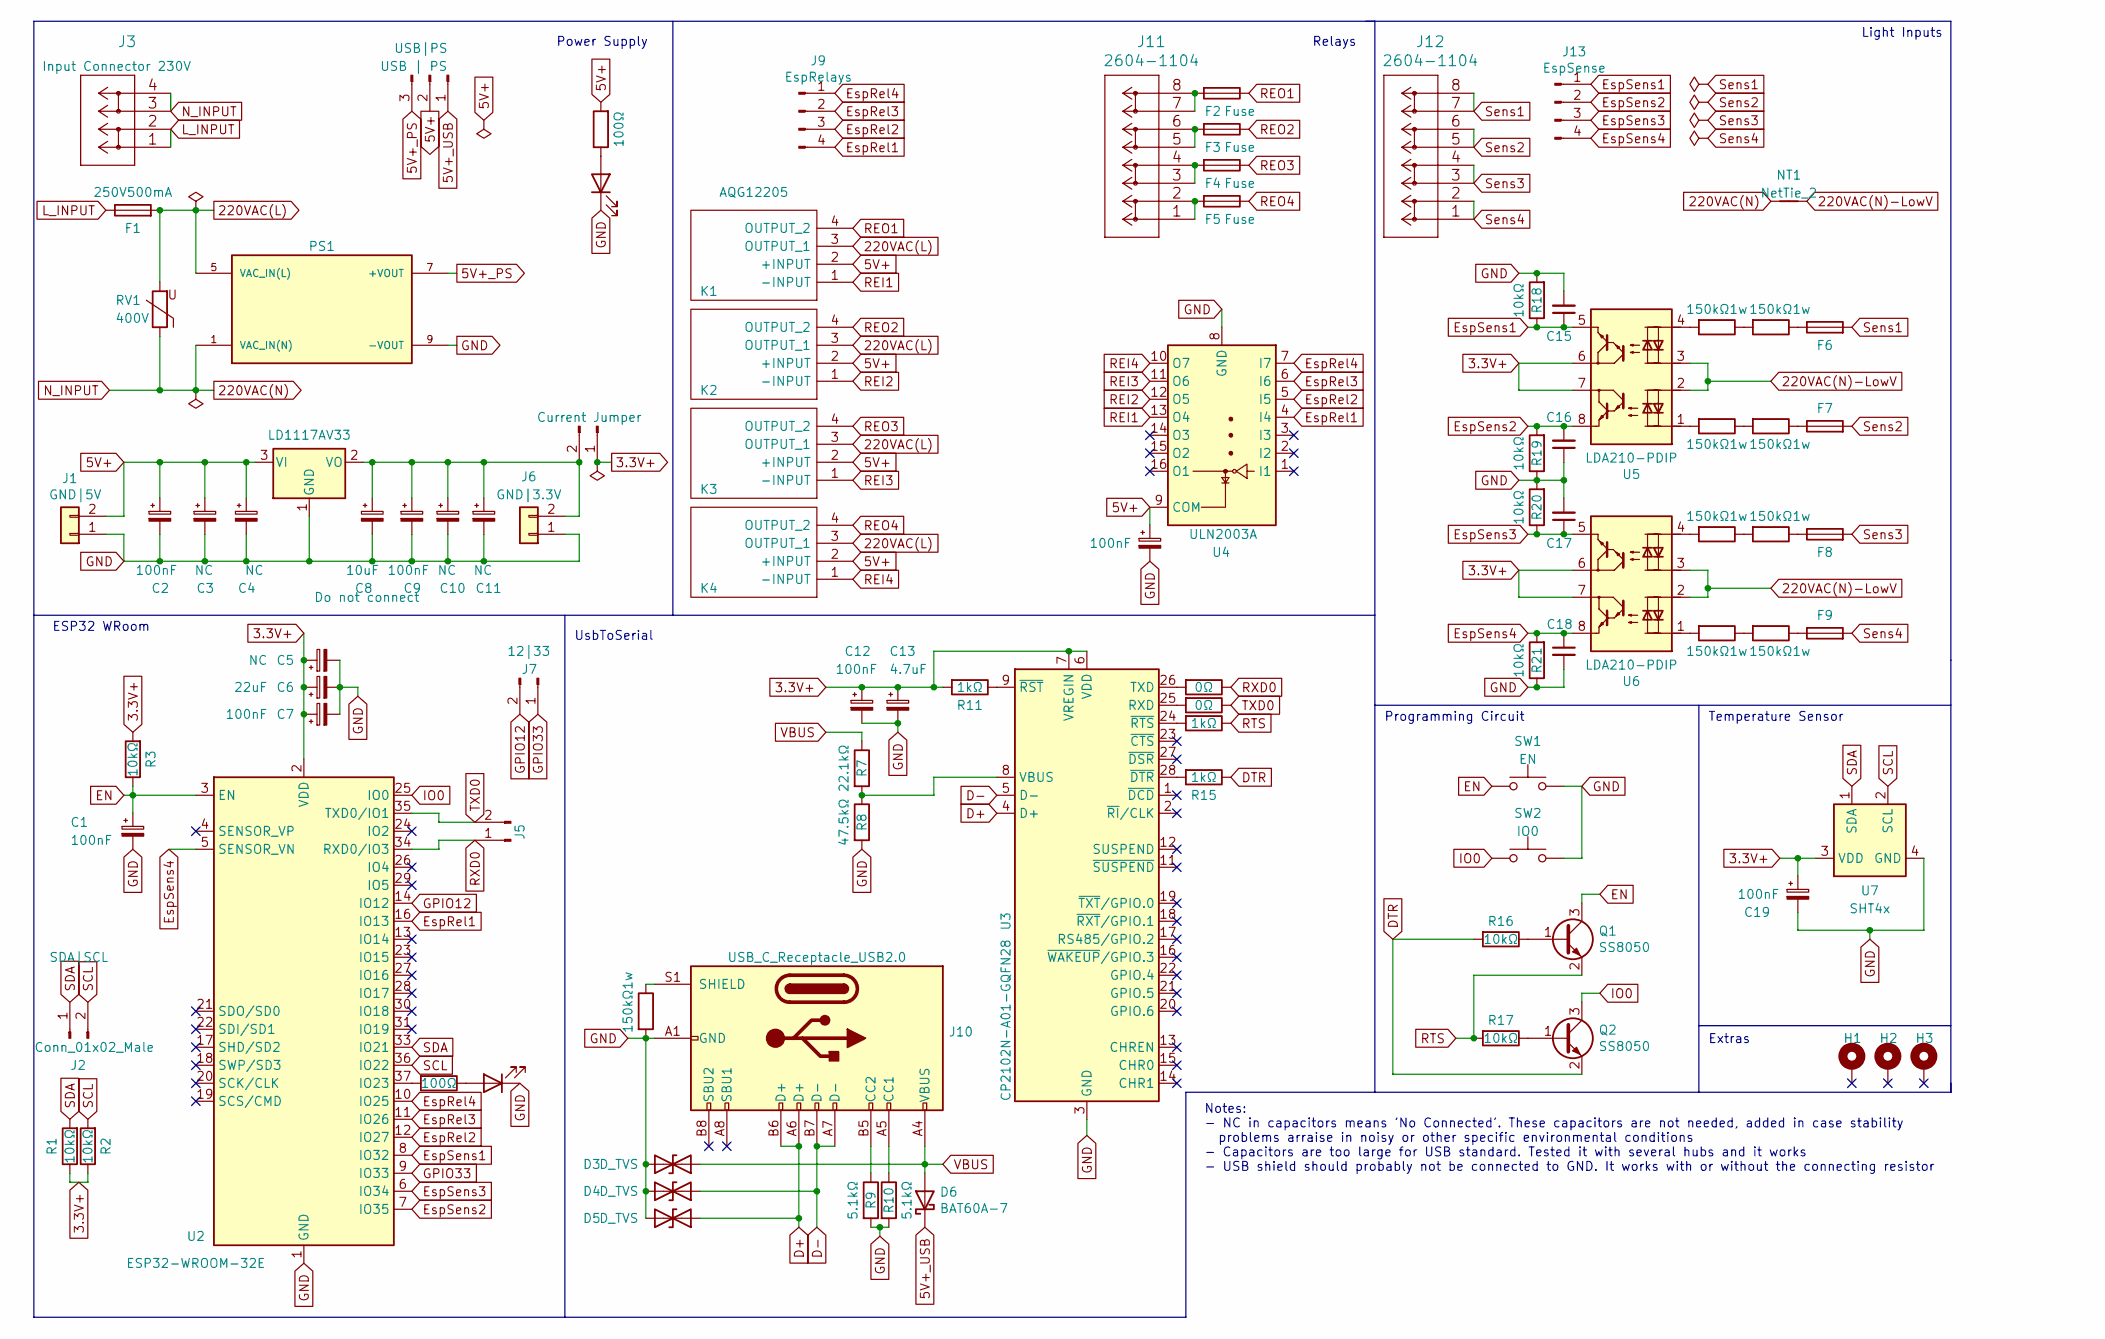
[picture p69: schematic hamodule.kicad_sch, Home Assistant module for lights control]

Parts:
C1, C2, C7, C9, C12, C14, C19: 100nF; C_0603_1608Metric_Pad1.08x0.95mm_HandSolder; JLCPCB C14663
C3, C4, C10, C11: NC; C_0805_2012Metric_Pad1.18x1.45mm_HandSolder
C5: NC; C_0603_1608Metric_Pad1.08x0.95mm_HandSolder
C6, C15, C16, C17, C18: 22uF; C_0603_1608Metric_Pad1.08x0.95mm_HandSolder; JLCPCB C59461
C8: 10uF; CP_Radial_D6.3mm_P2.50mm
C13: 4.7uF; C_0603_1608Metric_Pad1.08x0.95mm_HandSolder; JLCPCB C19666
D1, D2: LED; LED_0805_2012Metric_Pad1.15x1.40mm_HandSolder; JLCPCB C2297
D3, D4, D5: D_TVS; D_SOD-523; JLCPCB C383211
D6: BAT60A-7; D_SOD-323; JLCPCB C124187
F1: 250V500mA; Fuseholder_TR5_Littelfuse_No560_No460
F2, F3, F4, F5, F6, F7, F8, F9: Fuse; FUSE_RST-1-BULK
H1, H2, H3: MountingHole_Pad; MountingHole_3.2mm_M3_ISO14580_Pad
J1: GND|5V; JST_XH_B2B-XH-A_1x02_P2.50mm_Vertical
J2, J5, J7: Conn_01x02_Male; PinHeader_1x02_P2.54mm_Vertical
J3: 2604-1102; big_pads_2604-1102
J4: USB | PS; PinHeader_1x03_P2.54mm_Vertical
J6: GND|3.3V; JST_XH_B2B-XH-A_1x02_P2.50mm_Vertical
J8: Current Jumper; PinHeader_1x02_P2.54mm_Vertical
J9: EspRelays; PinSocket_1x04_P2.54mm_Vertical
J10: USB_C_Receptacle_USB2.0; USB_C_Receptacle_HRO_TYPE-C-31-M-12; JLCPCB C167321
J11, J12: 2604-1104; big_pads_2604-1104
J13: EspSense; PinSocket_1x04_P2.54mm_Vertical
K1, K2, K3, K4: AQG12205; Manufacturer_Part_Number AQG12205; Mouser Part Number 769-AQG12205
NT1: NetTie_2; NetTie-2_SMD_Pad2.0mm
PS1: RAC05-05SK/277; 277; PARTREV N/A
Q1, Q2: SS8050; SOT-23; JLCPCB C177739
R1, R2, R3, R16, R17, R18, R19, R20, R21: 10kΩ; R_0603_1608Metric_Pad0.98x0.95mm_HandSolder; JLCPCB C25804
R4, R5: 100Ω; R_0805_2012Metric_Pad1.20x1.40mm_HandSolder; JLCPCB C17408
R6, R22, R23, R24, R25, R26, R27, R28, R29: 150kΩ1w; R_2512_6332Metric_Pad1.40x3.35mm_HandSolder; JLCPCB C25719
R7: 22.1kΩ; R_0603_1608Metric_Pad0.98x0.95mm_HandSolder; JLCPCB C25961
R8: 47.5kΩ; R_0603_1608Metric_Pad0.98x0.95mm_HandSolder; JLCPCB C23061
R9, R10: 5.1kΩ; R_0603_1608Metric_Pad0.98x0.95mm_HandSolder; JLCPCB C23186
R11, R15: 1kΩ; R_0603_1608Metric_Pad0.98x0.95mm_HandSolder; JLCPCB C25585
R12, R13: 0Ω; R_0805_2012Metric_Pad1.20x1.40mm_HandSolder; JLCPCB C17477
R14: 1kΩ; R_1206_3216Metric_Pad1.30x1.75mm_HandSolder; JLCPCB C4410
RV1: 400V; RV_Disc_D12mm_W4.2mm_P7.5mm
SW1, SW2: Switch; SW_SPST_SKQG_WithStem; JLCPCB C318884
U1: LD1117AV33; TO-220-3_Vertical
U2: ESP32-WROOM-32E; ESP32-WROOM-32; JLCPCB C701343
U3: CP2102N-A01-GQFN28; QFN-28-1EP_5x5mm_P0.5mm_EP3.35x3.35mm; JLCPCB C964632
U4: ULN2003A; SOIC-16_3.9x9.9mm_P1.27mm; JLCPCB C7512
U5, U6: LDA210-PDIP; DIP-8_W7.62mm_Socket_LongPads
U7: SHT4x; XDCR_SHT40-AD1B-R2; JLCPCB C2909890

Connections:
3.3V+: C5.1, C6.1, C7.1, C12.1, C13.1, C19.1, J8.1, R1.1, R2.1, R3.2, R11.2, U2.2 (VDD), U3.6 (VDD), U3.7 (VREGIN), U5.6, U5.7, U6.6, U6.7, U7.3 (VDD)
5V+: C2.1, C3.1, C4.1, C14.1, J1.2, J4.2, K1.2 (+INPUT), K2.2 (+INPUT), K3.2 (+INPUT), K4.2 (+INPUT), R5.2, U1.3 (VI), U4.9 (COM)
5V+_PS: J4.3, PS1.7 (+VOUT)
5V+_USB: D6.1 (K), J4.1
220VAC(L): F1.2, K1.3 (OUTPUT_1), K2.3 (OUTPUT_1), K3.3 (OUTPUT_1), K4.3 (OUTPUT_1), PS1.5 (VAC_IN(L)), RV1.2
220VAC(N): J3.3, J3.4, NT1.1, PS1.1 (VAC_IN(N)), RV1.1
220VAC(N)-LowV: NT1.2, U5.2, U5.3, U6.2, U6.3
D+: D5.1 (A1), J10.A6 (D+), J10.B6 (D+), U3.4 (D+)
D-: D4.1 (A1), J10.A7 (D-), J10.B7 (D-), U3.5 (D-)
DTR: Q2.2 (E), R15.1, R16.2
EN: C1.1, Q1.3 (C), R3.1, SW1.1, U2.3 (EN)
EspRel1: J9.4, U2.16 (IO13), U4.4 (I4)
EspRel2: J9.3, U2.12 (IO27), U4.5 (I5)
EspRel3: J9.2, U2.11 (IO26), U4.6 (I6)
EspRel4: J9.1, U2.10 (IO25), U4.7 (I7)
EspSens1: C15.1, J13.1, R18.1, U2.8 (IO32), U5.5
EspSens2: C16.2, J13.2, R19.2, U2.7 (IO35), U5.8
EspSens3: C17.1, J13.3, R20.1, U2.6 (IO34), U6.5
EspSens4: C18.1, J13.4, R21.2, U2.5 (SENSOR_VN), U6.8
GND: C1.2, C2.2, C3.2, C4.2, C5.2, C6.2, C7.2, C8.2, C9.2, C10.2, C11.2, C12.2, C13.2, C14.2, C15.2, C16.1, C17.2, C18.2, C19.2, D1.1 (K), D2.1 (K), D3.2 (A2), D4.2 (A2), D5.2 (A2), J1.1, J6.1, J10.A1 (GND), J10.A12 (GND), J10.B1 (GND), J10.B12 (GND), PS1.9 (-VOUT), R6.2, R8.2, R9.2, R10.2, R18.2, R19.1, R20.2, R21.1, SW1.2, SW2.2, U1.1 (GND), U2.1 (GND), U2.15 (GND), U2.38 (GND), U2.39 (GND), U3.3 (GND), U3.29 (GND), U4.8 (GND), U7.4 (GND)
GPIO12: J7.2, U2.14 (IO12)
GPIO33: J7.1, U2.9 (IO33)
IO0: Q2.3 (C), SW2.1, U2.25 (IO0)
L_INPUT: F1.1, J3.1, J3.2
unnamed: C8.1, C9.1, C10.1, C11.1, J6.2, J8.2, U1.2 (VO)
unnamed: D1.2 (A), R4.1
unnamed: D2.2 (A), R5.1
unnamed: F2.2, J11.7, J11.8
unnamed: F3.2, J11.5, J11.6
unnamed: F4.2, J11.3, J11.4
unnamed: F5.2, J11.1, J11.2
unnamed: F6.1, R26.1
unnamed: F7.1, R27.1
unnamed: F8.1, R28.1
unnamed: F9.1, R29.1
unnamed: J10.A5 (CC1), R10.1
unnamed: J10.B5 (CC2), R9.1
unnamed: J10.S1 (SHIELD), R6.1
unnamed: Q1.1 (B), R16.1
unnamed: Q2.1 (B), R17.1
unnamed: R4.2, U2.37 (IO23)
unnamed: R7.2, R8.1, U3.8 (VBUS)
unnamed: R11.1, U3.9 (~RST)
unnamed: R12.2, U3.26 (TXD)
unnamed: R13.2, U3.25 (RXD)
unnamed: R14.2, U3.24 (~RTS)
unnamed: R15.2, U3.28 (~DTR)
unnamed: R22.1, R26.2
unnamed: R22.2, U5.4
unnamed: R23.1, R27.2
unnamed: R23.2, U5.1
unnamed: R24.1, R28.2
unnamed: R24.2, U6.4
unnamed: R25.1, R29.2
unnamed: R25.2, U6.1
REI1: K1.1 (-INPUT), U4.13 (O4)
REI2: K2.1 (-INPUT), U4.12 (O5)
REI3: K3.1 (-INPUT), U4.11 (O6)
REI4: K4.1 (-INPUT), U4.10 (O7)
REO1: F2.1, K1.4 (OUTPUT_2)
REO2: F3.1, K2.4 (OUTPUT_2)
REO3: F4.1, K3.4 (OUTPUT_2)
REO4: F5.1, K4.4 (OUTPUT_2)
RTS: Q1.2 (E), R14.1, R17.2
RXD0: J5.1, R12.1, U2.34 (RXD0/IO3)
SCL: J2.2, R2.2, U2.36 (IO22), U7.2 (SCL)
SDA: J2.1, R1.2, U2.33 (IO21), U7.1 (SDA)
Sens1: F6.2, J12.7, J12.8
Sens2: F7.2, J12.5, J12.6
Sens3: F8.2, J12.3, J12.4
Sens4: F9.2, J12.1, J12.2
TXD0: J5.2, R13.1, U2.35 (TXD0/IO1)
VBUS: D3.1 (A1), D6.2 (A), J10.A4 (VBUS), J10.A9 (VBUS), J10.B4 (VBUS), J10.B9 (VBUS), R7.1

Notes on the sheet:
Programming Circuit
UsbToSerial
Relays
Temperature Sensor
Power Supply
Extras
ESP32 WRoom
Notes: - NC in capacitors means 'No Connected'. These capacitors are not needed, added in case stability problems arraise in noisy or other specific environmental conditions - Capacitors are too large for USB standard. Tested it with several hubs and it works - USB shield should probably not be con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
Light Inputs

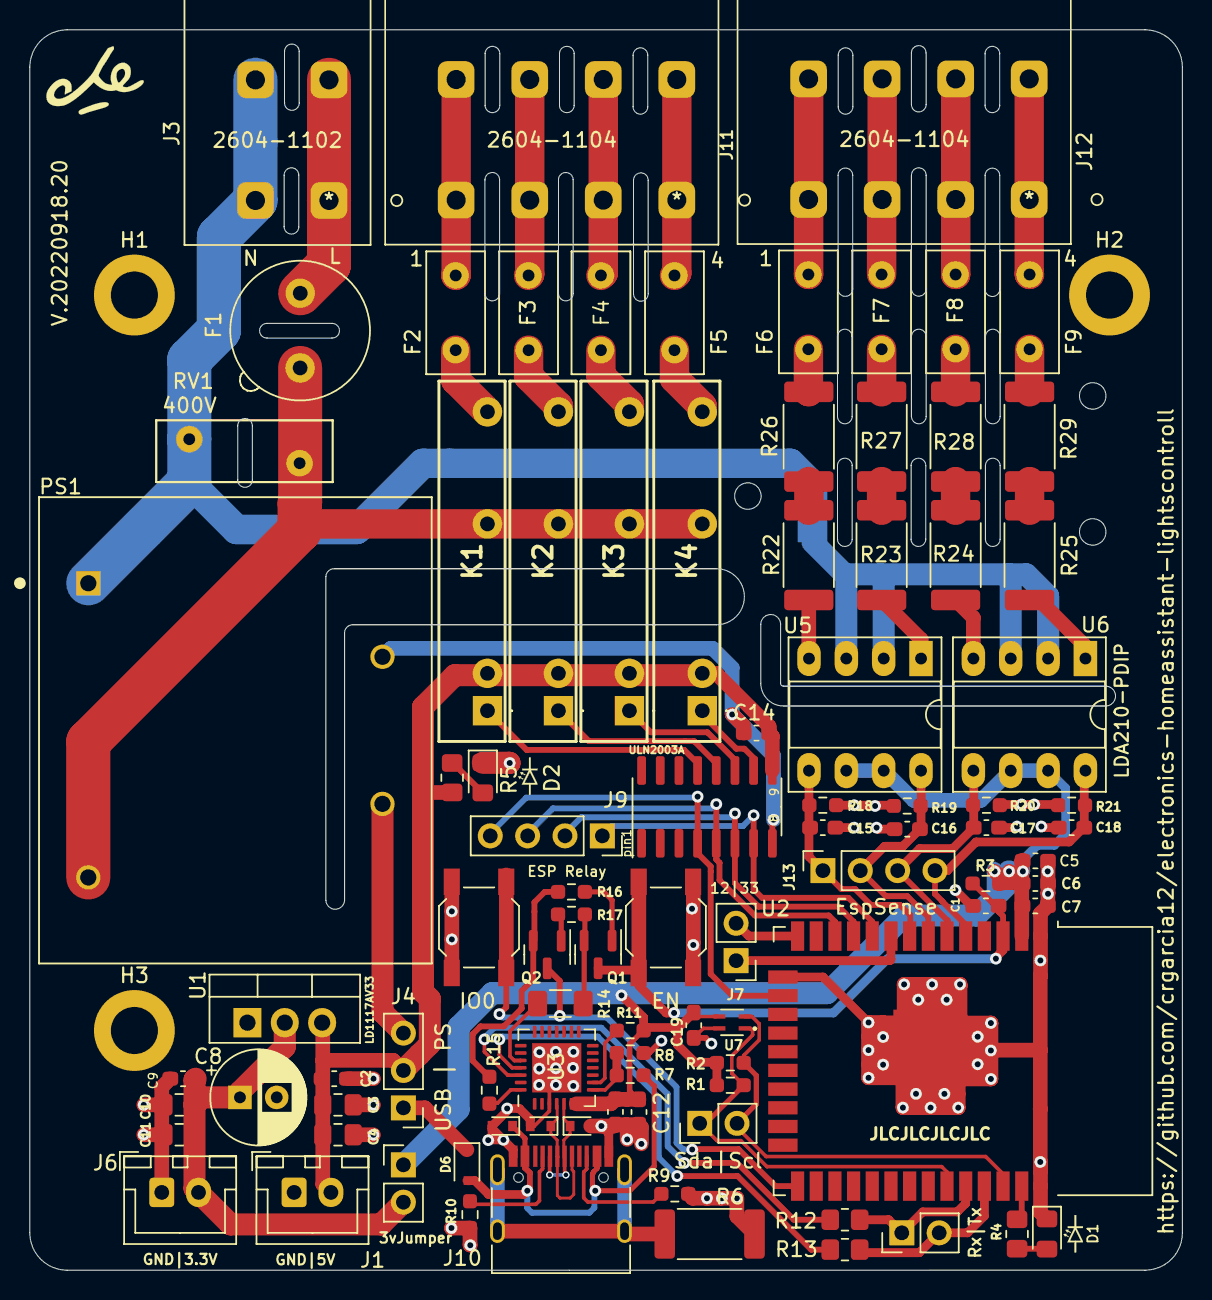
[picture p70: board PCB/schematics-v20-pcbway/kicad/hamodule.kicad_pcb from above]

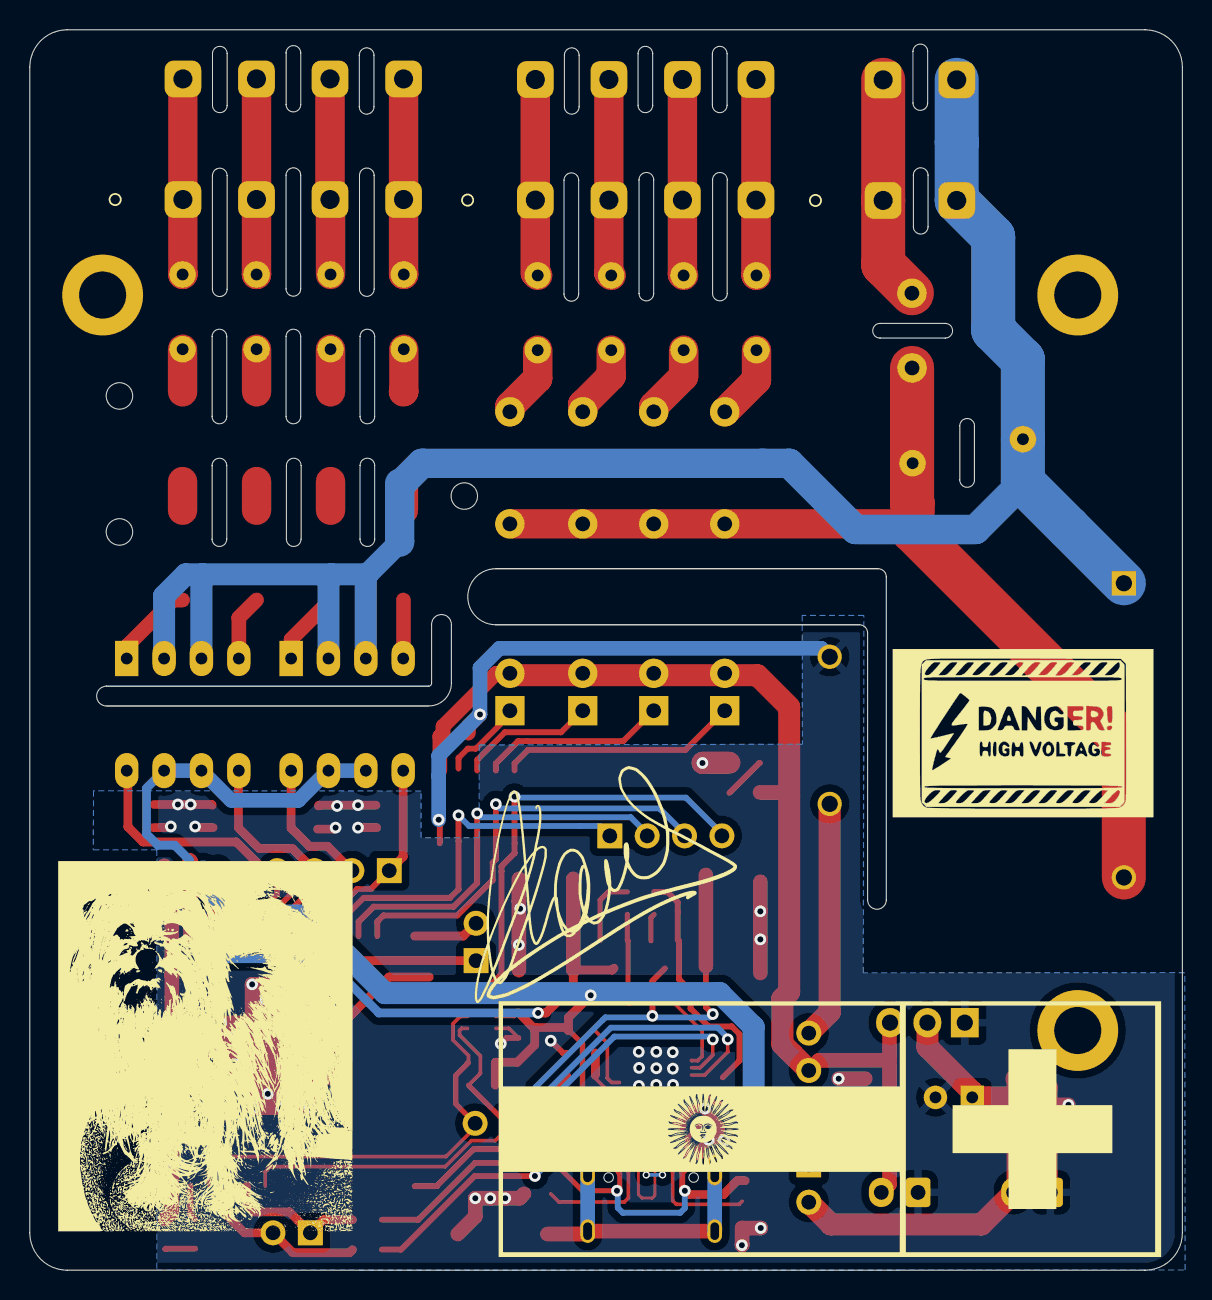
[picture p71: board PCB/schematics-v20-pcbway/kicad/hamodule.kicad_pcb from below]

Board: 2 copper layers, 78.4 x 84.3 mm, 104 parts (5 on the bottom side), 73 nets.

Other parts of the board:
G1: LOGO; che
G2, G4: LOGO; led_6000dpi
G3: LOGO; danger1_negative
G5: LOGO; depsi
G6: LOGO; flags
G7: LOGO; paula

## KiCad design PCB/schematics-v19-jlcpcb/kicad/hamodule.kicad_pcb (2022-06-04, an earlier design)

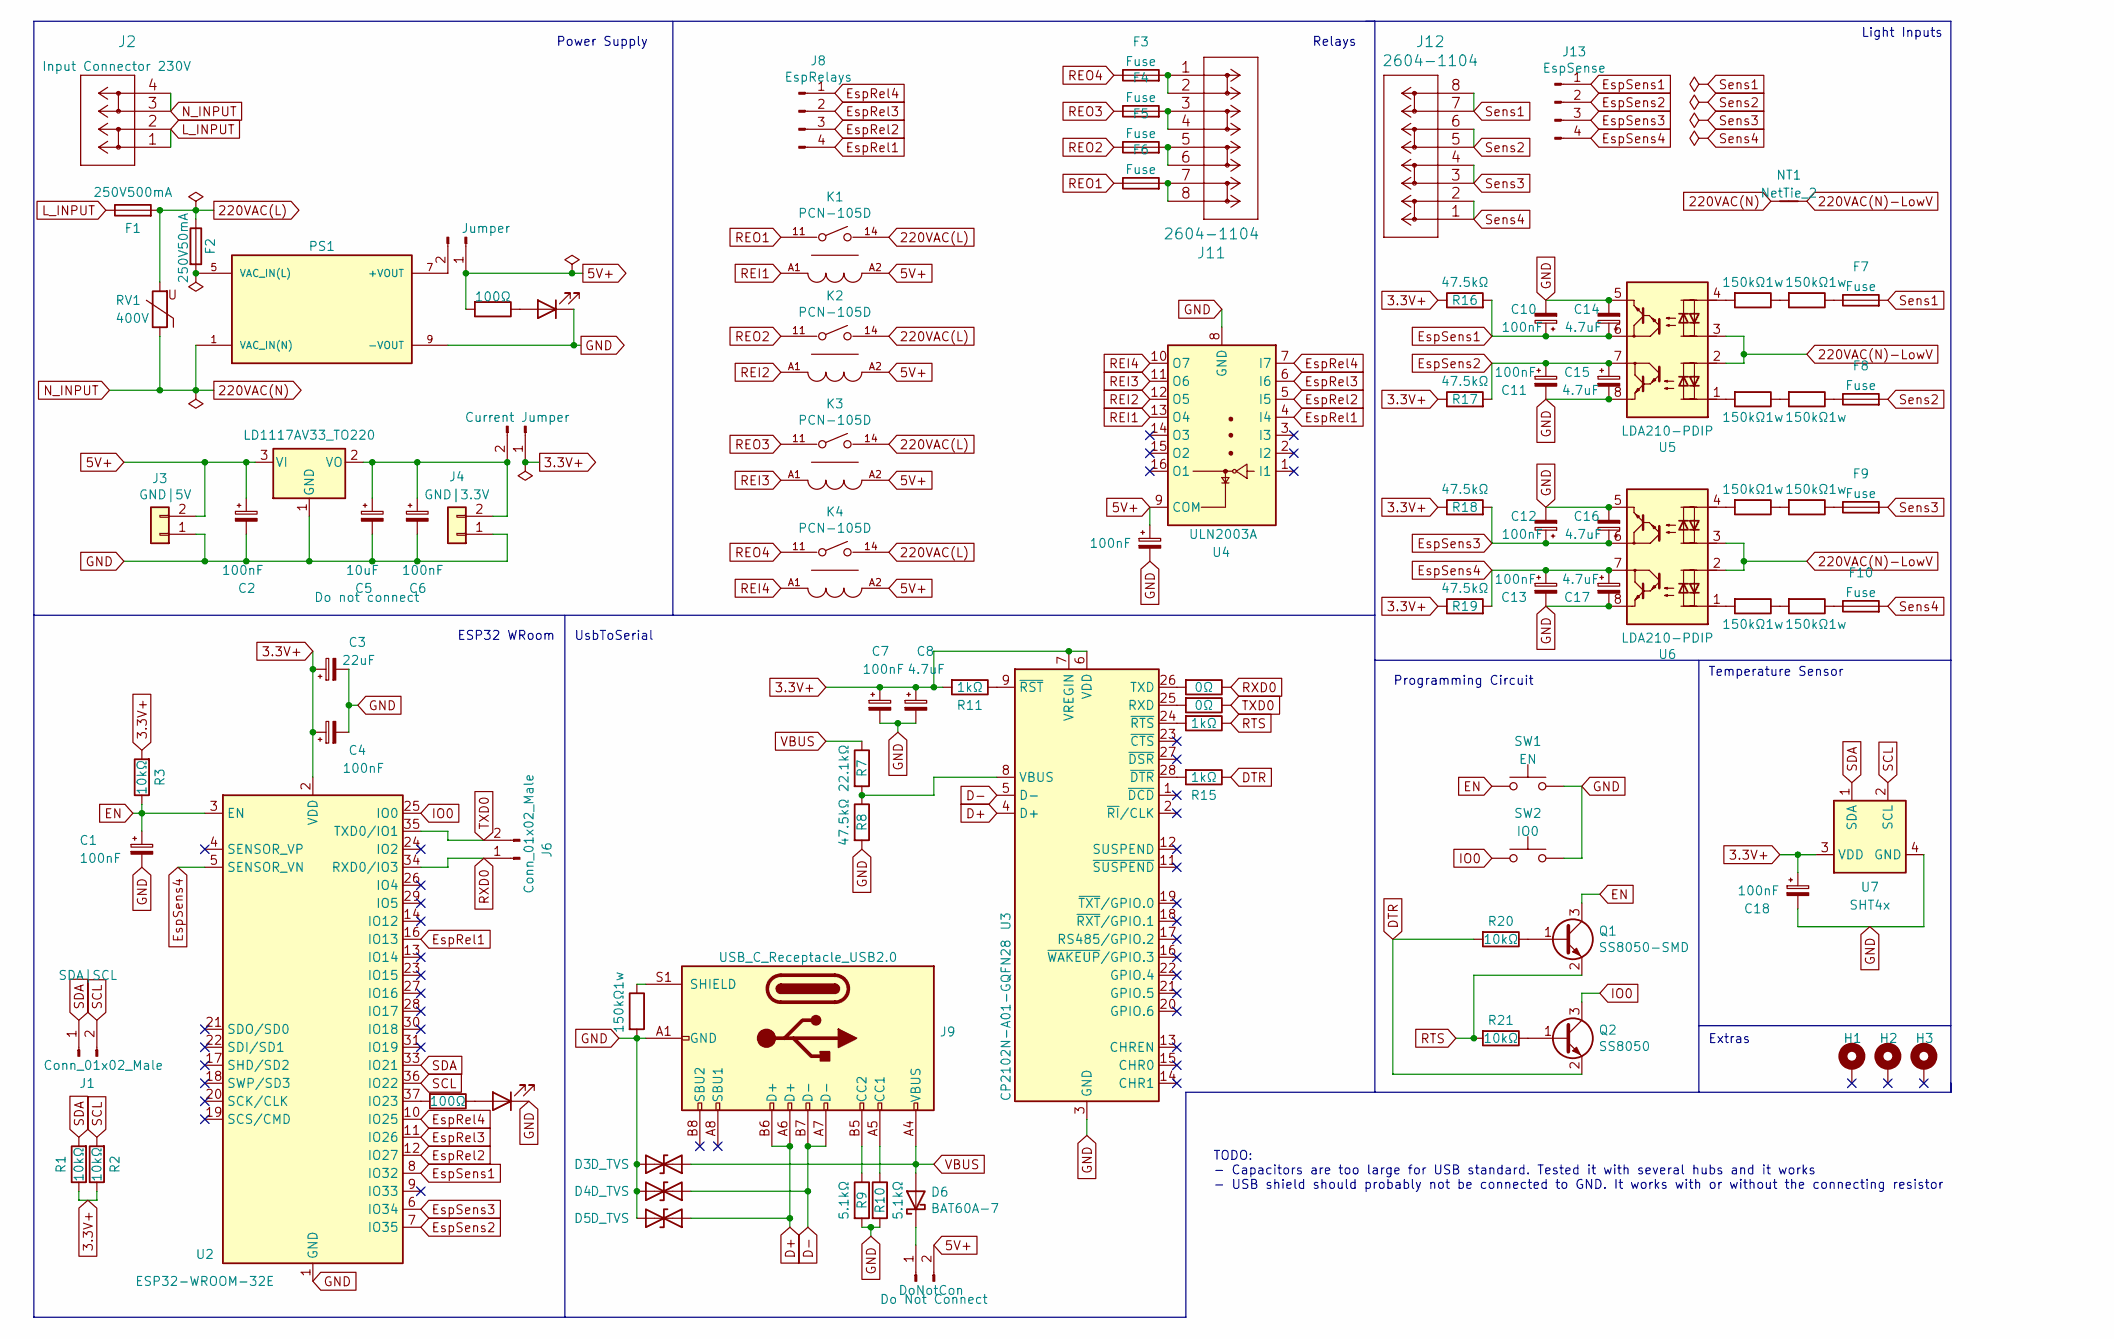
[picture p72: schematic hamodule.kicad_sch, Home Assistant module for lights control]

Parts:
C1, C2, C4, C6, C7, C9, C10, C11, C12, C13, C18: 100nF; C_0603_1608Metric_Pad1.08x0.95mm_HandSolder; JLCPCB C14663
C3: 22uF; C_0603_1608Metric_Pad1.08x0.95mm_HandSolder; JLCPCB C59461
C5: 10uF; CP_Radial_D6.3mm_P2.50mm
C8: 4.7uF; C_0603_1608Metric_Pad1.08x0.95mm_HandSolder; JLCPCB C19666
C14, C15, C16, C17: 4.7uF; C_1206_3216Metric_Pad1.33x1.80mm_HandSolder; JLCPCB C29823
D1, D2: LED; LED_0805_2012Metric_Pad1.15x1.40mm_HandSolder; JLCPCB C2297
D3, D4, D5: D_TVS; D_SOD-523; JLCPCB C383211
D6: BAT60A-7; D_SOD-323; JLCPCB C124187
F1: 250V500mA; Fuseholder_TR5_Littelfuse_No560_No460
F2: 250V50mA; Fuseholder_TR5_Littelfuse_No560_No460
F3, F4, F5, F6, F7, F8, F9, F10: Fuse; FUSE_RST-1-BULK
H1, H2, H3: MountingHole_Pad; MountingHole_3.2mm_M3_ISO14580_Pad
J1, J6: Conn_01x02_Male; PinHeader_1x02_P2.54mm_Vertical
J2: 2604-1102; big_pads_2604-1102
J3: GND|5V; JST_XH_B2B-XH-A_1x02_P2.50mm_Vertical
J4: GND|3.3V; JST_XH_B2B-XH-A_1x02_P2.50mm_Vertical
J5: Jumper; PinHeader_1x02_P2.54mm_Vertical
J7: Current Jumper; PinHeader_1x02_P2.54mm_Vertical
J8: EspRelays; PinSocket_1x04_P2.54mm_Vertical
J9: USB_C_Receptacle_USB2.0; USB_C_Receptacle_HRO_TYPE-C-31-M-12; JLCPCB C167321
J10: DoNotCon; PinHeader_1x02_P2.54mm_Vertical
J11, J12: 2604-1104; big_pads_2604-1104
J13: EspSense; PinSocket_1x04_P2.54mm_Vertical
K1, K2, K3, K4: PCN-105D; bigpads_TE_Connectivity-PCN-124D; coil voltage 24V; current rating 3A; mouser part number 655-PCN-124D3MHZ,000; digikey description RELAY GEN PURPOSE SPST 3A 24V
NT1: NetTie_2; NetTie-2_SMD_Pad2.0mm
PS1: RAC05-05SK/277; 277; PARTREV N/A
Q1: SS8050-SMD; SOT-23; JLCPCB C177739
Q2: SS8050; SOT-23; JLCPCB C177739
R1, R2, R3, R20, R21: 10kΩ; R_0603_1608Metric_Pad0.98x0.95mm_HandSolder; JLCPCB C25804
R4, R5: 100Ω; R_0805_2012Metric_Pad1.20x1.40mm_HandSolder; JLCPCB C17408
R6, R22, R23, R24, R25, R26, R27, R28, R29: 150kΩ1w; R_2512_6332Metric_Pad1.40x3.35mm_HandSolder; JLCPCB C25719
R7: 22.1kΩ; R_0603_1608Metric_Pad0.98x0.95mm_HandSolder; JLCPCB C25961
R8, R16, R17, R18, R19: 47.5kΩ; R_0603_1608Metric_Pad0.98x0.95mm_HandSolder; JLCPCB C23061
R9, R10: 5.1kΩ; R_0603_1608Metric_Pad0.98x0.95mm_HandSolder; JLCPCB C23186
R11, R15: 1kΩ; R_0603_1608Metric_Pad0.98x0.95mm_HandSolder; JLCPCB C25585
R12, R13: 0Ω; R_0805_2012Metric_Pad1.20x1.40mm_HandSolder; JLCPCB C17477
R14: 1kΩ; R_1206_3216Metric_Pad1.30x1.75mm_HandSolder; JLCPCB C4410
RV1: 400V; RV_Disc_D12mm_W4.2mm_P7.5mm
SW1, SW2: Switch; SW_SPST_SKQG_WithStem; JLCPCB C318884
U1: LD1117AV33_TO220; TO-220-3_Vertical
U2: ESP32-WROOM-32E; ESP32-WROOM-32; JLCPCB C701343
U3: CP2102N-A01-GQFN28; QFN-28-1EP_5x5mm_P0.5mm_EP3.35x3.35mm; JLCPCB C964632
U4: ULN2003A; SOIC-16_3.9x9.9mm_P1.27mm; JLCPCB C7512
U5, U6: LDA210-PDIP; DIP-8_W7.62mm_Socket_LongPads
U7: SHT4x; XDCR_SHT40-AD1B-R2; JLCPCB C2909890

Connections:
3.3V+: C3.1, C4.1, C7.1, C8.1, C18.1, J7.1, R1.1, R2.1, R3.2, R11.2, R16.1, R17.1, R18.1, R19.1, U2.2 (VDD), U3.6 (VDD), U3.7 (VREGIN), U7.3 (VDD)
5V+: C2.1, C9.1, J3.2, J5.1, J10.2, K1.A2, K2.A2, K3.A2, K4.A2, R5.2, U1.3 (VI), U4.9 (COM)
220VAC(L): F1.2, F2.1, K1.14, K2.14, K3.14, K4.14, RV1.2
220VAC(N): J2.3, J2.4, NT1.1, PS1.1 (VAC_IN(N)), RV1.1
220VAC(N)-LowV: NT1.2, U5.2, U5.3, U6.2, U6.3
D+: D5.1 (A1), J9.A6 (D+), J9.B6 (D+), U3.4 (D+)
D-: D4.1 (A1), J9.A7 (D-), J9.B7 (D-), U3.5 (D-)
DTR: Q2.2 (E), R15.1, R20.2
EN: C1.1, Q1.3 (C), R3.1, SW1.1, U2.3 (EN)
EspRel1: J8.4, U2.16 (IO13), U4.4 (I4)
EspRel2: J8.3, U2.12 (IO27), U4.5 (I5)
EspRel3: J8.2, U2.11 (IO26), U4.6 (I6)
EspRel4: J8.1, U2.10 (IO25), U4.7 (I7)
EspSens1: C10.1, C14.1, J13.1, R16.2, U2.8 (IO32), U5.6
EspSens2: C11.1, C15.1, J13.2, R17.2, U2.7 (IO35), U5.7
EspSens3: C12.1, C16.1, J13.3, R18.2, U2.6 (IO34), U6.6
EspSens4: C13.1, C17.1, J13.4, R19.2, U2.5 (SENSOR_VN), U6.7
GND: C1.2, C2.2, C3.2, C4.2, C5.2, C6.2, C7.2, C8.2, C9.2, C10.2, C11.2, C12.2, C13.2, C14.2, C15.2, C16.2, C17.2, C18.2, D1.1 (K), D2.1 (K), D3.2 (A2), D4.2 (A2), D5.2 (A2), J3.1, J4.1, J9.A1 (GND), J9.A12 (GND), J9.B1 (GND), J9.B12 (GND), PS1.9 (-VOUT), R6.2, R8.2, R9.2, R10.2, SW1.2, SW2.2, U1.1 (GND), U2.1 (GND), U2.15 (GND), U2.38 (GND), U2.39 (GND), U3.3 (GND), U3.29 (GND), U4.8 (GND), U5.5, U5.8, U6.5, U6.8, U7.4 (GND)
IO0: Q2.3 (C), SW2.1, U2.25 (IO0)
L_INPUT: F1.1, J2.1, J2.2
unnamed: C5.1, C6.1, J4.2, J7.2, U1.2 (VO)
unnamed: D1.2 (A), R4.1
unnamed: D2.2 (A), R5.1
unnamed: D6.1 (K), J10.1
unnamed: F2.2, PS1.5 (VAC_IN(L))
unnamed: F3.2, J11.1, J11.2
unnamed: F4.2, J11.3, J11.4
unnamed: F5.2, J11.5, J11.6
unnamed: F6.2, J11.7, J11.8
unnamed: F7.1, R26.1
unnamed: F8.1, R27.1
unnamed: F9.1, R28.1
unnamed: F10.1, R29.1
unnamed: J5.2, PS1.7 (+VOUT)
unnamed: J9.A5 (CC1), R10.1
unnamed: J9.B5 (CC2), R9.1
unnamed: J9.S1 (SHIELD), R6.1
unnamed: Q1.1 (B), R20.1
unnamed: Q2.1 (B), R21.1
unnamed: R4.2, U2.37 (IO23)
unnamed: R7.2, R8.1, U3.8 (VBUS)
unnamed: R11.1, U3.9 (~RST)
unnamed: R12.2, U3.26 (TXD)
unnamed: R13.2, U3.25 (RXD)
unnamed: R14.2, U3.24 (~RTS)
unnamed: R15.2, U3.28 (~DTR)
unnamed: R22.1, R26.2
unnamed: R22.2, U5.4
unnamed: R23.1, R27.2
unnamed: R23.2, U5.1
unnamed: R24.1, R28.2
unnamed: R24.2, U6.4
unnamed: R25.1, R29.2
unnamed: R25.2, U6.1
REI1: K1.A1, U4.13 (O4)
REI2: K2.A1, U4.12 (O5)
REI3: K3.A1, U4.11 (O6)
REI4: K4.A1, U4.10 (O7)
REO1: F6.1, K1.11
REO2: F5.1, K2.11
REO3: F4.1, K3.11
REO4: F3.1, K4.11
RTS: Q1.2 (E), R14.1, R21.2
RXD0: J6.1, R12.1, U2.34 (RXD0/IO3)
SCL: J1.2, R2.2, U2.36 (IO22), U7.2 (SCL)
SDA: J1.1, R1.2, U2.33 (IO21), U7.1 (SDA)
Sens1: F7.2, J12.7, J12.8
Sens2: F8.2, J12.5, J12.6
Sens3: F9.2, J12.3, J12.4
Sens4: F10.2, J12.1, J12.2
TXD0: J6.2, R13.1, U2.35 (TXD0/IO1)
VBUS: D3.1 (A1), D6.2 (A), J9.A4 (VBUS), J9.A9 (VBUS), J9.B4 (VBUS), J9.B9 (VBUS), R7.1

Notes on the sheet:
Programming Circuit
UsbToSerial
Relays
Temperature Sensor
Power Supply
Extras
ESP32 WRoom
TODO: - Capacitors are too large for USB standard. Tested it with several hubs and it works - USB shield should probably not be connected to GND. It works with or without the connecting resistor
Light Inputs

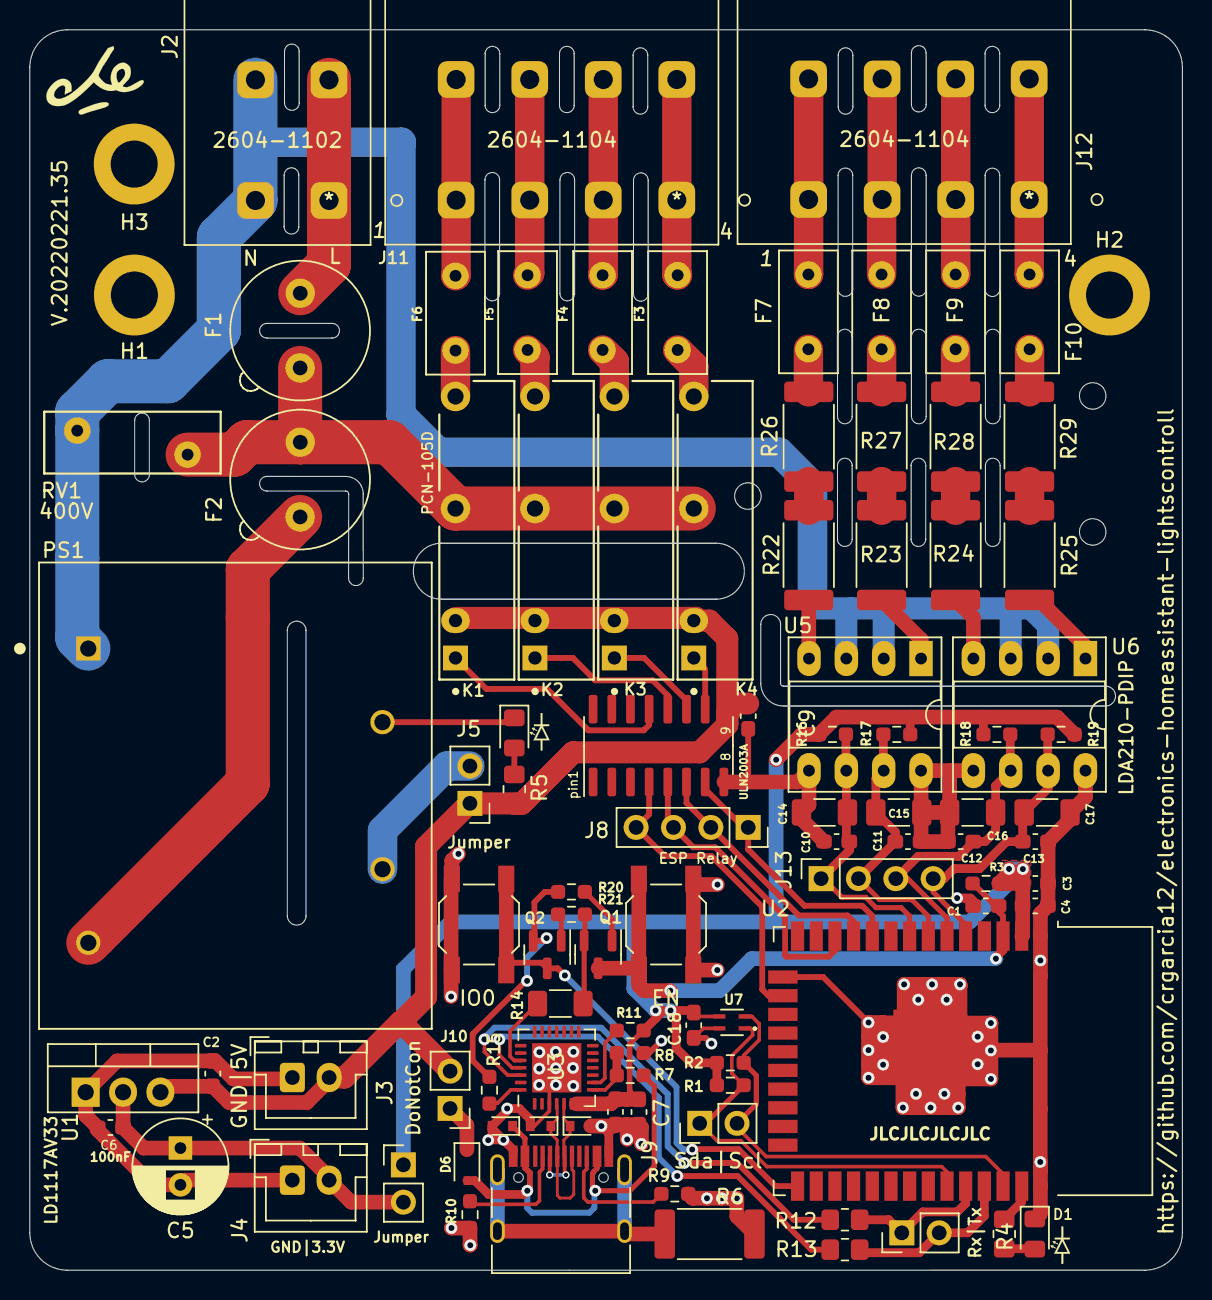
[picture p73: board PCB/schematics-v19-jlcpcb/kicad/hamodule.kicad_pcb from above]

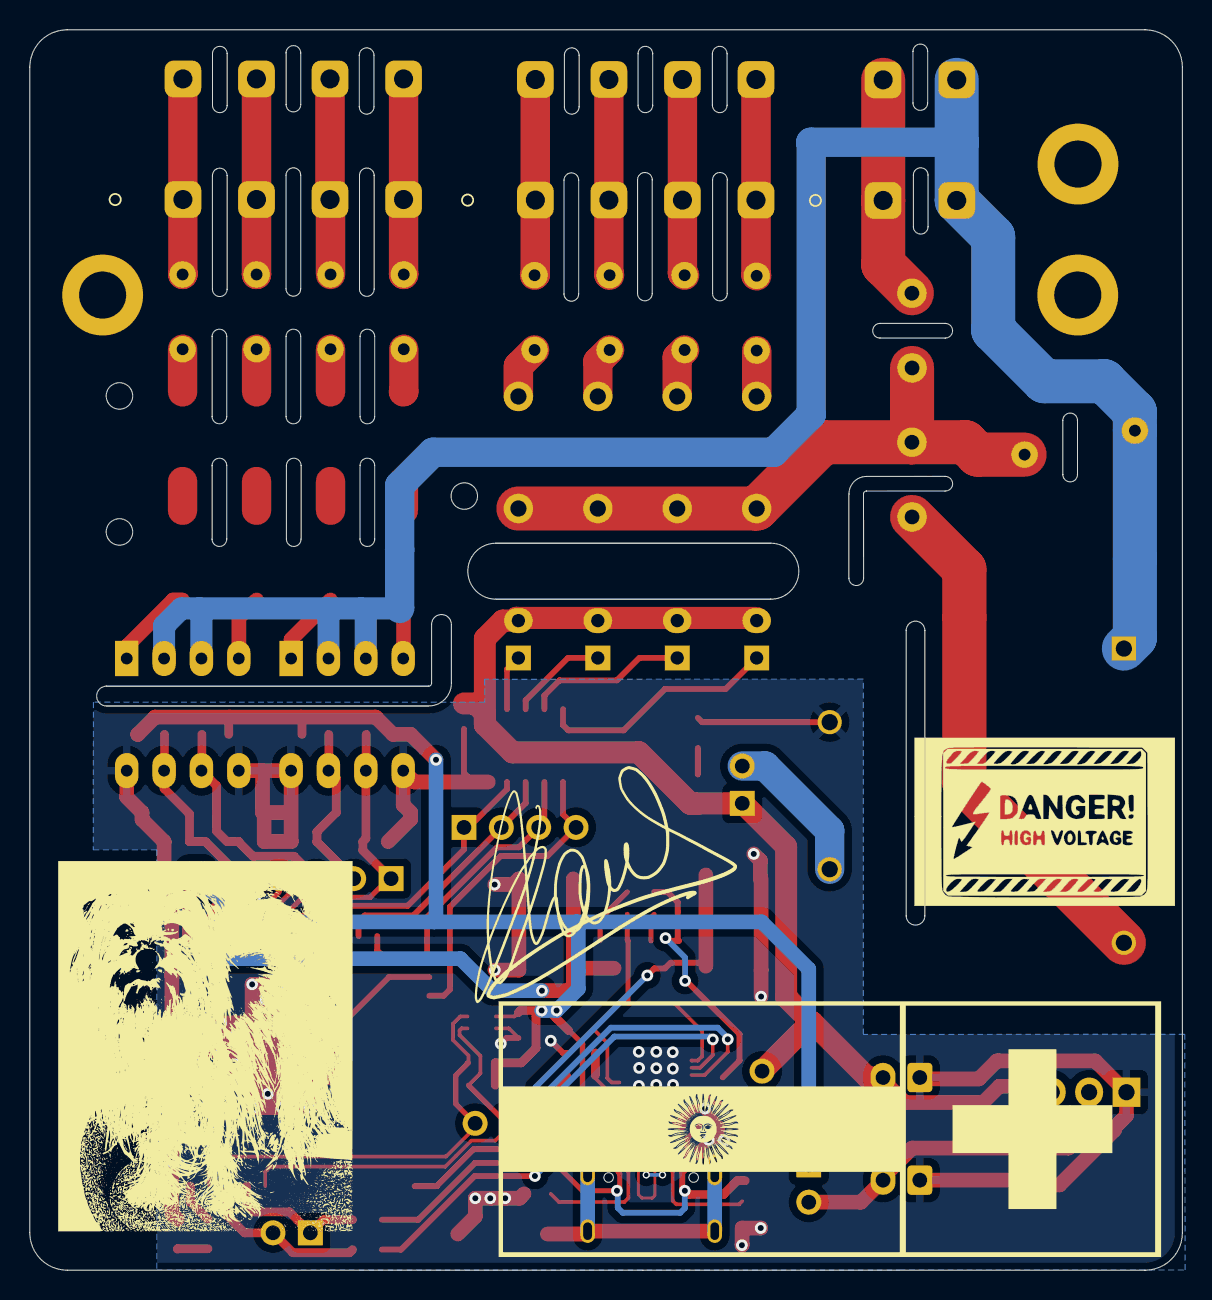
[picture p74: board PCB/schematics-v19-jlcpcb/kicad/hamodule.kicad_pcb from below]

Board: 2 copper layers, 78.4 x 84.3 mm, 101 parts (2 on the bottom side), 72 nets.

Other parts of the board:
G1: LOGO; che
G2, G2#2: LOGO; led_6000dpi
G3: LOGO; danger1_negative

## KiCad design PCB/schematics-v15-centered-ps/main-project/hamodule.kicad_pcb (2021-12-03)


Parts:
100uF_1, 100uF_2: 100uF; CP_Radial_D6.3mm_P2.50mm
C1, C2, C3, C5: 100nF; C_0805_2012Metric_Pad1.15x1.40mm_HandSolder; JLCPCB C28233
C6, C11, C12, C13, C14: 22uF; CP_EIA-3528-21_Kemet-B_Pad1.50x2.35mm_HandSolder; JLCPCB C110051
C7, C8, C9, C10: 100uF; C_0805_2012Metric_Pad1.15x1.40mm_HandSolder; JLCPCB C28233
D1, D2: LED; LED_0805_2012Metric_Pad1.15x1.40mm_HandSolder; JLCPCB C2297
F1: 250V1A; Fuse_Littelfuse_372_D8.50mm
F2: 250v50mA; Fuse_Littelfuse_372_D8.50mm
H1, H2, H4, H5, H6: MountingHole_Pad; MountingHole_3.2mm_M3_ISO14580_Pad
J1, J9: 2604-1104; big_pads_2604-1104
J2: 2604-1102; big_pads_2604-1102
J3: ESP Sensors; JST_XH_B4B-XH-A_1x04_P2.50mm_Vertical
J4: ESP Relays; JST_XH_B4B-XH-A_1x04_P2.50mm_Vertical
J5, J8: Current Jumper; PinHeader_1x02_P2.54mm_Vertical
J6: GND 3.3V; JST_XH_B2B-XH-A_1x02_P2.50mm_Vertical
J7: Conn_01x02; JST_XH_B2B-XH-A_1x02_P2.50mm_Vertical
K1, K2, K3, K4: PCN-105D; bigpads_TE_Connectivity-PCN-124D; coil voltage 24V; current rating 3A; mouser part number 655-PCN-124D3MHZ,000; digikey description RELAY GEN PURPOSE SPST 3A 24V
R9, R11: 100Ω; R_0805_2012Metric_Pad1.15x1.40mm_HandSolder; JLCPCB C17408
R12, R13, R14, R15: 10kΩ; R_1206_3216Metric_Pad1.42x1.75mm_HandSolder; JLCPCB C17902
R16, R17, R18, R19, R20, R21, R22, R23: 39kΩ3w; R_2512_6332Metric_Pad1.52x3.35mm_HandSolder; JLCPCB C144424
RA05.SK.1: RAC05.05SK.277; 277; PARTREV N/A
RV1: 400V; RV_Disc_D12mm_W4.2mm_P7.5mm
U1: ULN2003A; SOIC-16_3.9x9.9mm_P1.27mm; JLCPCB C7512
U4: LD1117AV33_TO220; TO-220-3_Vertical
U6, U7: LDA210-PDIP; DIP-8_W7.62mm_Socket_LongPads

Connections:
3.3V+: J5.1, J6.2, R12.1, R13.2, R14.1, R15.2
5V+: 100uF_1.1, C1.1, C2.1, J7.2, J8.1, K1.A2, K2.A2, K3.A2, K4.A2, R11.2, U1.9 (COM), U4.3 (VI)
220VAC(L): F1.2, K1.14, K2.14, K3.14, K4.14, RA05.SK.1.5 (VAC_IN(L)), RV1.2
220VAC(N): F2.2, U6.2, U6.3, U7.2, U7.3
EspRel1: J4.4, U1.7 (I7)
EspRel2: J4.3, U1.6 (I6)
EspRel3: J4.2, U1.5 (I5)
EspRel4: J4.1, U1.4 (I4)
EspSens1: C7.1, C11.1, J3.1, R12.2, U6.6
EspSens2: C8.1, C12.1, J3.2, R13.1, U6.7
EspSens3: C9.1, C13.1, J3.3, R14.2, U7.6
EspSens4: C10.1, C14.1, J3.4, R15.1, U7.7
GND(5V): 100uF_1.2, 100uF_2.2, C1.2, C2.2, C3.2, C7.2, C8.2, C9.2, C10.2, C11.2, C12.2, C13.2, C14.2, D2.1 (K), J6.1, J7.1, RA05.SK.1.9 (-VOUT), U1.8 (GND), U4.1 (GND), U6.5, U6.8, U7.5, U7.8
L_IN: F1.1, J2.1, J2.2
N_IN: F2.1, J2.3, J2.4, RA05.SK.1.1 (VAC_IN(N)), RV1.1
unnamed: 100uF_2.1, C3.1, J5.2, U4.2 (VO)
unnamed: C5.1, C6.1, D1.2 (A), R9.1
unnamed: C5.2, C6.2, D1.1 (K)
unnamed: D2.2 (A), R11.1
unnamed: J8.2, RA05.SK.1.7 (+VOUT)
unnamed: R16.1, R20.2
unnamed: R16.2, U6.4
unnamed: R17.1, R21.2
unnamed: R17.2, U6.1
unnamed: R18.1, R22.2
unnamed: R18.2, U7.4
unnamed: R19.1, R23.2
unnamed: R19.2, U7.1
REI1: K1.A1, U1.13 (O4)
REI2: K2.A1, U1.12 (O5)
REI3: K4.A1, U1.11 (O6)
REI4: K3.A1, U1.10 (O7)
REO1: J1.7, J1.8, K1.11
REO2: J1.5, J1.6, K2.11
REO3: J1.3, J1.4, K4.11
REO4: J1.1, J1.2, K3.11
Sens1: J9.7, J9.8, R20.1
Sens2: J9.5, J9.6, R21.1
Sens3: J9.3, J9.4, R22.1
Sens4: J9.1, J9.2, R23.1


Board: 2 copper layers, 76.7 x 84.3 mm, 57 parts (0 on the bottom side), 40 nets.

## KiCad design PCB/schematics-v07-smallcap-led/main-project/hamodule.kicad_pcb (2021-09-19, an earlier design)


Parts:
22uF1, 22uF2, 22uF3, 22uF4: CP_Small; CP_Radial_D10.0mm_P5.00mm
D1, D2, D3, D4: DIODE; D_DO-35_SOD27_P7.62mm_Horizontal
D5, D6, D7, D8: LED; LED_D3.0mm
F1: Fuse; Fuse_Littelfuse_372_D8.50mm
H1, H2, H3, H4, H5: MountingHole_Pad; MountingHole_3.2mm_M3_ISO14580_Pad
J1, J3, J8: 1017505; Manufacturer_Part_Number 1017505; Mouser Part Number 651-1017505
J2: Conn-ESP-Relays; JST_XH_B4B-XH-A_1x04_P2.50mm_Vertical
J4: Conn-Buttons; JST_XH_B5B-XH-A_1x05_P2.50mm_Vertical
J5: Conn_01x02; JST_XH_B2B-XH-A_1x02_P2.50mm_Vertical
J6: Conn-Esp-Sensors; JST_XH_B4B-XH-A_1x04_P2.50mm_Vertical
J7: Conn-LedIndicators; JST_XH_B5B-XH-A_1x05_P2.50mm_Vertical
K1, K2, K3, K4: G5Q-1; Relay_SPDT_Omron-G5Q-1
PS1: RAC05-05SK_277; 277; PARTREV N/A
R1, R2, R3, R4, R5, R6, R7, R8: 100; R_Axial_DIN0207_L6.3mm_D2.5mm_P7.62mm_Horizontal
R9, R10, R11, R12, R13, R14, R15, R16: 47k; R_Axial_DIN0516_L15.5mm_D5.0mm_P20.32mm_Horizontal
RV1: Varistor; RV_Disc_D21.5mm_W5.3mm_P10mm
U1: ULN2003A; DIP-16_W7.62mm_LongPads
U2: LD1117S33TR_SOT223; TO-220-3_Vertical
U3, U4, U5, U6: HCPL3700; DIP-8_W7.62mm_Socket_LongPads; Voltage - Isolation 2500Vrms; Voltage - Output (Max) 20V; mouser part number 512-HCPL-3700; digikey description Optoisolator Darlington Output 2500Vrms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

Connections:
3.3V+: J4.5, J7.1, R5.2, R6.2, R7.2, R8.2, U2.2 (VO), U3.8 (VCC), U4.8 (VCC), U5.8 (VCC), U6.8 (VCC)
5V+: J5.2, K1.5, K2.5, K3.5, K4.5, PS1.7 (+VOUT), U1.9 (COM), U2.3 (VI)
220VAC(L): F1.2, K1.2, K2.2, K3.2, K4.2, PS1.5 (VAC_IN(L)), RV1.2
220VAC(N): J3.1, J3.2, PS1.1 (VAC_IN(N)), R10.1, R12.1, R14.2, R16.1, RV1.1
EspRel1: D1.2 (A), J4.4, U1.4 (I4)
EspRel2: D2.2 (A), J4.3, U1.5 (I5)
EspRel3: D3.2 (A), J4.2, U1.6 (I6)
EspRel4: D4.2 (A), J4.1, U1.7 (I7)
EspSens1: D5.1 (K), J6.4, R1.1, U3.6 (VO)
EspSens2: D6.1 (K), J6.3, R2.1, U4.6 (VO)
EspSens3: D7.1 (K), J6.2, R3.1, U5.6 (VO)
EspSens4: D8.1 (K), J6.1, R4.1, U6.6 (VO)
GND(5V): J5.1, PS1.9 (-VOUT), U1.1 (I1), U1.2 (I2), U1.3 (I3), U1.8 (GND), U1.14 (O3), U1.15 (O2), U1.16 (O1), U2.1 (GND), U3.5 (GND), U4.5 (GND), U5.5 (GND), U6.5 (GND)
unnamed: 22uF1.1, U3.2 (DC+)
unnamed: 22uF1.2, U3.3 (DC-)
unnamed: 22uF2.1, U4.2 (DC+)
unnamed: 22uF2.2, U4.3 (DC-)
unnamed: 22uF3.1, U5.2 (DC+)
unnamed: 22uF3.2, U5.3 (DC-)
unnamed: 22uF4.1, U6.2 (DC+)
unnamed: 22uF4.2, U6.3 (DC-)
unnamed: D1.1 (K), J2.4
unnamed: D2.1 (K), J2.3
unnamed: D3.1 (K), J2.2
unnamed: D4.1 (K), J2.1
unnamed: D5.2 (A), R5.1
unnamed: D6.2 (A), R6.1
unnamed: D7.2 (A), R7.1
unnamed: D8.2 (A), R8.1
unnamed: F1.1, J3.7, J3.8
unnamed: J7.2, R4.2
unnamed: J7.3, R3.2
unnamed: J7.4, R2.2
unnamed: J7.5, R1.2
unnamed: R9.2, U3.4 (2_AC)
unnamed: R10.2, U3.1 (1_AC)
unnamed: R11.2, U4.4 (2_AC)
unnamed: R12.2, U4.1 (1_AC)
unnamed: R13.1, U5.4 (2_AC)
unnamed: R14.1, U5.1 (1_AC)
unnamed: R15.2, U6.4 (2_AC)
unnamed: R16.2, U6.1 (1_AC)
REI1: K1.1, U1.10 (O7)
REI2: K2.1, U1.11 (O6)
REI3: K3.1, U1.12 (O5)
REI4: K4.1, U1.13 (O4)
REO1: J1.7, J1.8, K1.3
REO2: J1.5, J1.6, K2.3
REO3: J1.3, J1.4, K3.3
REO4: J1.1, J1.2, K4.3
Sens1: J8.5, J8.6, R9.1
Sens2: J8.7, J8.8, R11.1
Sens3: J8.3, J8.4, R13.2
Sens4: J8.1, J8.2, R15.1


Board: 2 copper layers, 144.8 x 76.2 mm, 54 parts (0 on the bottom side), 54 nets.

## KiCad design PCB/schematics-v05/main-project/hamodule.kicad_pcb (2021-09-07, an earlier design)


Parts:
22uF1, 22uF2, 22uF3, 22uF4: CP_Small; CP_Radial_D6.3mm_P2.50mm
F1: Fuse; Fuse_Littelfuse_372_D8.50mm
H1, H2, H3, H4, H5, H6, H7, H8, H9: MountingHole_Pad; MountingHole_3.2mm_M3_ISO14580_Pad
J1, J2, J4: 1017505; Manufacturer_Part_Number 1017505; Mouser Part Number 651-1017505
K1, K2, K3, K4: G5Q-1; Relay_SPDT_Omron-G5Q-1
PS1: RAC05-05SK_277; 277; PARTREV N/A
R5, R6, R11, R12, R17, R18, R19, R20: 47k; R_Axial_DIN0204_L3.6mm_D1.6mm_P7.62mm_Horizontal
R7, R8, R9, R10: 10K; R_Axial_DIN0204_L3.6mm_D1.6mm_P7.62mm_Horizontal
RV1: Varistor; RV_Disc_D21.5mm_W5.3mm_P10mm
U1: ESP32-DEVKITC-32D; MODULE_ESP32-DEVKITC-32D; PARTREV 4
U2, U3, U4, U5: HCPL3700; ON_Semi-CASE_62605_ISSUE_P-0-0-0; Voltage - Isolation 2500Vrms; Voltage - Output (Max) 20V; mouser part number 512-HCPL-3700; digikey description Optoisolator Darlington Output 2500Vrms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
U6: ULN2003A; DIP-16_W7.62mm_LongPads

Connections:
3.3V+: R7.2, R8.2, R9.2, R10.2, U1.1 (3V3), U2.8 (VCC), U3.8 (VCC), U4.8 (VCC), U5.8 (VCC)
5V+: PS1.7 (+VOUT), U1.19 (EXT_5V), U6.9 (COM)
220VAC(L): F1.2, K1.2, K2.2, K3.2, K4.2, PS1.5 (VAC_IN(L)), RV1.2
220VAC(N): J2.1, J2.2, PS1.1 (VAC_IN(N)), RV1.1, U2.1 (1_AC), U3.1 (1_AC), U4.1 (1_AC), U5.1 (1_AC)
GND(5V): K1.5, K2.5, K3.5, K4.5, PS1.9 (-VOUT), U1.20 (GND3), U2.5 (GND), U3.5 (GND), U4.5 (GND), U5.5 (GND), U6.1 (I1), U6.2 (I2), U6.3 (I3), U6.8 (GND), U6.14 (O3), U6.15 (O2), U6.16 (O1)
GPIO19: U1.34 (IO2), U6.4 (I4)
GPIO21: U1.32 (IO4), U6.5 (I5)
GPIO22: U1.31 (IO16), U6.6 (I6)
GPIO23: U1.30 (IO17), U6.7 (I7)
GPIO32: R9.1, U1.22 (IO22), U4.6 (VO)
GPIO33: R10.1, U1.21 (IO23), U5.6 (VO)
GPIO34: R7.1, U1.27 (IO19), U2.6 (VO)
GPIO35: R8.1, U1.25 (IO21), U3.6 (VO)
unnamed: 22uF1.1, U2.2 (DC+)
unnamed: 22uF1.2, U2.3 (DC-)
unnamed: 22uF2.1, U3.2 (DC+)
unnamed: 22uF2.2, U3.3 (DC-)
unnamed: 22uF3.1, U4.2 (DC+)
unnamed: 22uF3.2, U4.3 (DC-)
unnamed: 22uF4.1, U5.2 (DC+)
unnamed: 22uF4.2, U5.3 (DC-)
unnamed: F1.1, J2.7, J2.8
unnamed: R5.2, R6.1
unnamed: R6.2, U2.4 (2_AC)
unnamed: R11.1, R18.2
unnamed: R11.2, U3.4 (2_AC)
unnamed: R12.1, R19.2
unnamed: R12.2, U4.4 (2_AC)
unnamed: R17.1, R20.2
unnamed: R17.2, U5.4 (2_AC)
REI1: K1.1, U6.13 (O4)
REI2: K2.1, U6.12 (O5)
REI3: K3.1, U6.11 (O6)
REI4: K4.1, U6.10 (O7)
REO1: J1.7, J1.8, K1.3
REO2: J1.5, J1.6, K2.3
REO3: J1.3, J1.4, K3.3
REO4: J1.1, J1.2, K4.3
Sens1: J4.7, J4.8, R5.1
Sens2: J4.5, J4.6, R18.1
Sens3: J4.3, J4.4, R19.1
Sens4: J4.1, J4.2, R20.1


Board: 2 copper layers, 158.8 x 71.1 mm, 41 parts (0 on the bottom side), 42 nets.

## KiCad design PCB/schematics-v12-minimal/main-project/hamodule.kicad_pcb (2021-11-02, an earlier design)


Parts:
22uF1, 22uF2, 22uF3, 22uF4: 22uF; CP_EIA-3528-21_Kemet-B_Pad1.50x2.35mm_HandSolder; JLCPCB C110051
100uF_1, 100uF_2: 100uF; CP_Radial_D6.3mm_P2.50mm
C1, C2, C3, C4, C5, C6, C7: 0.1uF; C_0805_2012Metric_Pad1.15x1.40mm_HandSolder; JLCPCB C235777
D9: LED; LED_0805_2012Metric_Pad1.15x1.40mm_HandSolder; JLCPCB C2297
F1: F250V; Fuse_Littelfuse_372_D8.50mm
F2: 250v-40mA; Fuse_Littelfuse_372_D8.50mm
F3, F4, F5, F6: Fuse; Fuse_1812_4532Metric_Pad1.30x3.40mm_HandSolder; JLCPCB C207063
H1, H2, H3: MountingHole_Pad; MountingHole_3.2mm_M3_ISO14580_Pad
J1, J3, J8: 1017505; 1017505_pretty; Manufacturer_Part_Number 1017505; Mouser Part Number 651-1017505
J2: ESP Relays; JST_XH_B4B-XH-A_1x04_P2.50mm_Vertical
J5: Conn_01x02; JST_XH_B2B-XH-A_1x02_P2.50mm_Vertical
J6: ESP Sensors; JST_XH_B4B-XH-A_1x04_P2.50mm_Vertical
J9, J11: Current Jumper; PinHeader_1x02_P2.54mm_Vertical
J10: GND 3.3V; JST_XH_B2B-XH-A_1x02_P2.50mm_Vertical
K1, K2, K3, K4: G5Q-1; Relay_SPDT_Omron-G5Q-1
R5, R6, R7, R8: 10kΩ; R_1206_3216Metric_Pad1.42x1.75mm_HandSolder; JLCPCB C17902
R9: 150Ω; R_0805_2012Metric_Pad1.15x1.40mm_HandSolder; JLCPCB C17471
R10, R11, R12, R13, R14, R15, R16, R17: 39kΩ1w; R_2512_6332Metric_Pad1.52x3.35mm_HandSolder; JLCPCB C25723
RA05.SK.277: RAC05.05SK.277; 277; PARTREV N/A
RV1: 400V; RV_Disc_D12mm_W4.2mm_P7.5mm
U1: ULN2003A; SOIC-16_3.9x9.9mm_P1.27mm; JLCPCB C7512
U2: LD1117S33TR_SOT223; TO-220-3_Vertical
U3, U4, U5, U6: HCPL3700; DIP-8_W7.62mm_Socket_LongPads; Voltage - Isolation 2500Vrms; Voltage - Output (Max) 20V; mouser part number 512-HCPL-3700; digikey description Optoisolator Darlington Output 2500Vrms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

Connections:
3.3V+: C1.1, C2.1, C3.1, C4.1, J10.2, J11.1, R5.2, R6.2, R7.2, R8.2, U3.8 (VCC), U4.8 (VCC), U5.8 (VCC), U6.8 (VCC)
5V+: 100uF_1.1, C6.1, C7.1, J5.2, J9.1, K1.5, K2.5, K3.5, K4.5, R9.2, U1.9 (COM), U2.3 (VI)
220VAC(L): F1.2, K1.2, K2.2, K3.2, K4.2, RA05.SK.277.5 (VAC_IN(L)), RV1.2
220VAC(N): F2.2, U3.4 (2_AC), U4.4 (2_AC), U5.4 (2_AC), U6.4 (2_AC)
EspRel1: J2.4, U1.7 (I7)
EspRel2: J2.3, U1.6 (I6)
EspRel3: J2.2, U1.5 (I5)
EspRel4: J2.1, U1.4 (I4)
EspSens1: J6.4, R8.1, U6.6 (VO)
EspSens2: J6.3, R7.1, U5.6 (VO)
EspSens3: J6.2, R6.1, U4.6 (VO)
EspSens4: J6.1, R5.1, U3.6 (VO)
GND(5V): 100uF_1.2, 100uF_2.2, C1.2, C2.2, C3.2, C4.2, C5.2, C6.2, C7.2, D9.1 (K), J5.1, J10.1, RA05.SK.277.9 (-VOUT), U1.8 (GND), U2.1 (GND), U3.5 (GND), U4.5 (GND), U5.5 (GND), U6.5 (GND)
unnamed: 22uF1.1, U3.2 (DC+)
unnamed: 22uF1.2, U3.3 (DC-)
unnamed: 22uF2.1, U4.2 (DC+)
unnamed: 22uF2.2, U4.3 (DC-)
unnamed: 22uF3.1, U5.2 (DC+)
unnamed: 22uF3.2, U5.3 (DC-)
unnamed: 22uF4.1, U6.2 (DC+)
unnamed: 22uF4.2, U6.3 (DC-)
unnamed: 100uF_2.1, C5.1, J11.2, U2.2 (VO)
unnamed: D9.2 (A), R9.1
unnamed: F1.1, J3.1, J3.2
unnamed: F2.1, J3.7, J3.8, RA05.SK.277.1 (VAC_IN(N)), RV1.1
unnamed: F3.1, R16.2
unnamed: F3.2, U3.1 (1_AC)
unnamed: F4.1, R14.2
unnamed: F4.2, U4.1 (1_AC)
unnamed: F5.1, R12.2
unnamed: F5.2, U5.1 (1_AC)
unnamed: F6.1, R10.2
unnamed: F6.2, U6.1 (1_AC)
unnamed: J9.2, RA05.SK.277.7 (+VOUT)
unnamed: R10.1, R17.2
unnamed: R11.2, R16.1
unnamed: R12.1, R15.2
unnamed: R13.2, R14.1
REI1: K1.1, U1.13 (O4)
REI2: K2.1, U1.12 (O5)
REI3: K3.1, U1.11 (O6)
REI4: K4.1, U1.10 (O7)
REO1: J1.7, J1.8, K1.3
REO2: J1.5, J1.6, K2.3
REO3: J1.3, J1.4, K3.3
REO4: J1.1, J1.2, K4.3
Sens1: J8.5, J8.6, R13.1
Sens2: J8.7, J8.8, R11.1
Sens3: J8.3, J8.4, R15.1
Sens4: J8.1, J8.2, R17.1


Board: 2 copper layers, 101.1 x 76.2 mm, 57 parts (0 on the bottom side), 50 nets.

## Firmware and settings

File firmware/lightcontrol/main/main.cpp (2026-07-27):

/**
 * ESP32-S3 Home Assistant bridge for:
 * - v27 board (8 channels via TCAL6416)
 * - v28 board (4 channels via direct GPIO)
 *
 * Runtime configuration is stored in NVS and can be set via setup AP + web page.
 */

#include <cctype>
#include <atomic>
#include <cstdio>
#include <cstring>
#include <memory>
#include <new>
#include <string>
#include <utility>
#include <vector>

#include "cJSON.h"
#include "driver/gpio.h"
#include "driver/i2c_master.h"
#include "esp_app_desc.h"
#include "esp_crt_bundle.h"
#include "esp_event.h"
#include "esp_http_client.h"
#include "esp_http_server.h"
#include "esp_https_ota.h"
#include "esp_log.h"
#include "esp_mac.h"
#include "esp_netif.h"
#include "esp_netif_ip_addr.h"
#include "esp_ota_ops.h"
#include "esp_system.h"
#include "esp_timer.h"
#include "esp_wifi.h"
#include "freertos/FreeRTOS.h"
#include "freertos/event_groups.h"
#include "freertos/semphr.h"
#include "freertos/task.h"
#include "led_strip.h"
#include "mqtt_client.h"
#include "nvs.h"
#include "nvs_flash.h"
#include "sht40.hpp"
#include "tcal6416.hpp"

static const char* TAG = "ha_bridge";

static constexpr gpio_num_t SETUP_MODE_BUTTON = GPIO_NUM_0;
static constexpr gpio_num_t V28_RELAY_GPIO[] = {GPIO_NUM_46, GPIO_NUM_8, GPIO_NUM_18, GPIO_NUM_17};
static constexpr gpio_num_t V28_SENSOR_GPIO[] = {GPIO_NUM_15, GPIO_NUM_7, GPIO_NUM_6, GPIO_NUM_5};
static constexpr gpio_num_t I2C_SDA = GPIO_NUM_42;
static constexpr gpio_num_t I2C_SCL = GPIO_NUM_41;
static constexpr gpio_num_t STATUS_LED_GPIO = GPIO_NUM_1;
static constexpr gpio_num_t RGB_LED_GPIO = GPIO_NUM_38;

static constexpr int I2C_FREQ_HZ = 100000;
static constexpr uint8_t TCAL_ADDR = 0x20;
static constexpr uint8_t SHT40_ADDR = 0x44;
static constexpr int RELAY_PULSE_MS = 300;
static constexpr int CHANNEL_POLL_MS = 250;
static constexpr int SHT40_POLL_MS = 30000;
static constexpr int DIAGNOSTICS_POLL_MS = 30000;
static constexpr int WIFI_CONNECT_TIMEOUT_MS = 20000;
static constexpr int MQTT_KEEPALIVE_SECONDS = 30;
static constexpr int STATUS_LED_PULSE_MS = 20;
static constexpr int STATUS_LED_PULSE_GAP_MS = 20;
static constexpr int STATUS_LED_ACTIVE_LEVEL = 1;
static constexpr int STATUS_LED_INACTIVE_LEVEL = 0;
static constexpr int RGB_LED_BLINK_MS = 400;
static constexpr int OTA_RGB_LED_BLINK_MS = 200;
static constexpr int OTA_HTTP_TX_BUFFER_SIZE = 2048;
static constexpr int OTA_PROGRESS_STEP_PERCENT = 5;
static constexpr int RELEASE_CHECK_MS = 6 * 60 * 60 * 1000;
static constexpr int GLOBAL_OTA_MAX_DELAY_MS = 30000;
static constexpr size_t MAX_RELEASE_RESPONSE_BYTES = 96 * 1024;

static constexpr bool V28_SENSOR_ACTIVE_HIGH = true;

static constexpr const char* NVS_NS = "cfg";
static constexpr const char* GLOBAL_OTA_TOPIC = "home/lightcontrol/all/firmware/update";
static constexpr const char* GLOBAL_RELEASE_CHECK_TOPIC = "home/lightcontrol/all/firmware/check";
static constexpr const char* GITHUB_RELEASES_API =
    "https://api.github.com/repos/crgarcia12/"
    "electronics-homeassistant-lightscontroll/releases?per_page=5";
static constexpr const char* FIRMWARE_ASSET_NAME = "lightcontrol.bin";

enum class BoardType {
    V27_8CH_TCAL,
    V28_4CH_GPIO,
};

enum class RgbLedMode {
    OTA_UPDATING,
    WIFI_CONNECTING,
    MQTT_ERROR,
    OFF,
};

struct RuntimeConfig {
    char wifi_ssid[33] = "";
    char wifi_password[65] = "";
    char mqtt_uri[128] = "";
    char mqtt_username[64] = "";
    char mqtt_password[64] = "";
    char device_name[48] = "";
    char room_name[48] = "";
    char ota_url[192] = "";
    bool configured = false;
};

struct ReleaseInfo {
    std::string version;
    std::string asset_url;
    std::string release_url;
};

struct OtaRequest {
    bool fleet_update = false;
};

struct AppContext {
    BoardType board = BoardType::V28_4CH_GPIO;
    int channel_count = 4;
    i2c_master_bus_handle_t i2c_bus = nullptr;
    std::unique_ptr<tcal6416::Device> tcal;
    std::unique_ptr<sht40::Device> environment_sensor;
    TaskHandle_t environment_task = nullptr;
    TaskHandle_t diagnostics_task = nullptr;
    TaskHandle_t release_task = nullptr;
    TaskHandle_t status_led_task = nullptr;
    led_strip_handle_t rgb_led = nullptr;
    TaskHandle_t rgb_led_task = nullptr;
    esp_mqtt_client_handle_t mqtt = nullptr;
    httpd_handle_t setup_httpd = nullptr;
    std::string node_id;
    std::string base_topic;
    std::string availability_topic;
    std::string mac_address;
    std::string ip_address;
    ReleaseInfo release;
    std::vector<bool> last_state;
    RuntimeConfig cfg;
};

static EventGroupHandle_t wifi_event_group;
static SemaphoreHandle_t state_mutex;
static constexpr int WIFI_CONNECTED_BIT = BIT0;
static AppContext g_ctx;
static std::atomic_bool ota_in_progress = false;
static std::atomic_bool release_check_requested = false;
static std::atomic_bool wifi_connected = false;
static std::atomic_bool mqtt_connected = false;
static std::atomic<RgbLedMode> rgb_led_mode = RgbLedMode::OFF;

static std::string sanitize_topic_part(const char* src) {
    std::string out;
    if (!src) {
        return "device";
    }
    for (size_t i = 0; src[i] != '\0'; ++i) {
        unsigned char c = static_cast<unsigned char>(src[i]);
        if (std::isalnum(c)) {
            out.push_back(static_cast<char>(std::tolower(c)));
        } else if (c == '-' || c == '_') {
            out.push_back(static_cast<char>(c));
        } else if (c == ' ') {
            out.push_back('_');
        }
    }
    if (out.empty()) {
        return "device";
    }
    return out;
}

static void set_default_device_name() {
    uint8_t mac[6] = {};
    ESP_ERROR_CHECK(esp_read_mac(mac, ESP_MAC_WIFI_STA));

    char node[32];
    std::snprintf(node, sizeof(node), "lightscontrol-%02X%02X%02X", mac[3], mac[4], mac[5]);
    g_ctx.node_id = node;

    char mac_address[18];
    std::snprintf(
        mac_address,
        sizeof(mac_address),
        "%02X:%02X:%02X:%02X:%02X:%02X",
        mac[0], mac[1], mac[2], mac[3], mac[4], mac[5]);
    g_ctx.mac_address = mac_address;

    if (g_ctx.cfg.device_name[0] == '\0') {
        std::snprintf(g_ctx.cfg.device_name, sizeof(g_ctx.cfg.device_name), "%s", node);
    }
    if (g_ctx.cfg.room_name[0] == '\0') {
        std::snprintf(g_ctx.cfg.room_name, sizeof(g_ctx.cfg.room_name), "room");
    }
}

static esp_err_t nvs_get_str_safe(nvs_handle_t handle, const char* key, char* out, size_t out_len) {
    if (out_len == 0) {
        return ESP_ERR_INVALID_ARG;
    }
    size_t required = out_len;
    esp_err_t err = nvs_get_str(handle, key, out, &required);
    if (err == ESP_ERR_NVS_NOT_FOUND) {
        out[0] = '\0';
        return ESP_OK;
    }
    if (err != ESP_OK) {
        out[0] = '\0';
        return err;
    }
    out[out_len - 1] = '\0';
    return ESP_OK;
}

static bool load_runtime_config(RuntimeConfig& cfg) {
    nvs_handle_t nvs_handle = 0;
    esp_err_t err = nvs_open(NVS_NS, NVS_READONLY, &nvs_handle);
    if (err != ESP_OK) {
        return false;
    }

    uint8_t configured = 0;
    err = nvs_get_u8(nvs_handle, "configured", &configured);
    if (err != ESP_OK || configured == 0) {
        nvs_close(nvs_handle);
        return false;
    }

    if (nvs_get_str_safe(nvs_handle, "wifi_ssid", cfg.wifi_ssid, sizeof(cfg.wifi_ssid)) != ESP_OK ||
        nvs_get_str_safe(nvs_handle, "wifi_pwd", cfg.wifi_password, sizeof(cfg.wifi_password)) != ESP_OK ||
        nvs_get_str_safe(nvs_handle, "mqtt_uri", cfg.mqtt_uri, sizeof(cfg.mqtt_uri)) != ESP_OK ||
        nvs_get_str_safe(nvs_handle, "mqtt_user", cfg.mqtt_username, sizeof(cfg.mqtt_username)) != ESP_OK ||
        nvs_get_str_safe(nvs_handle, "mqtt_pwd", cfg.mqtt_password, sizeof(cfg.mqtt_password)) != ESP_OK ||
        nvs_get_str_safe(nvs_handle, "dev_name", cfg.device_name, sizeof(cfg.device_name)) != ESP_OK ||
        nvs_get_str_safe(nvs_handle, "room_name", cfg.room_name, sizeof(cfg.room_name)) != ESP_OK ||
        nvs_get_str_safe(nvs_handle, "ota_url", cfg.ota_url, sizeof(cfg.ota_url)) != ESP_OK) {
        nvs_close(nvs_handle);
        return false;
    }

    nvs_close(nvs_handle);
    cfg.configured = cfg.wifi_ssid[0] != '\0' && cfg.mqtt_uri[0] != '\0';
    return cfg.configured;
}

static esp_err_t save_runtime_config(const RuntimeConfig& cfg) {
    nvs_handle_t nvs_handle = 0;
    esp_err_t err = nvs_open(NVS_NS, NVS_READWRITE, &nvs_handle);
    if (err != ESP_OK) {
        return err;
    }

    err = ESP_OK;
    err |= nvs_set_str(nvs_handle, "wifi_ssid", cfg.wifi_ssid);
    err |= nvs_set_str(nvs_handle, "wifi_pwd", cfg.wifi_password);
    err |= nvs_set_str(nvs_handle, "mqtt_uri", cfg.mqtt_uri);
    err |= nvs_set_str(nvs_handle, "mqtt_user", cfg.mqtt_username);
    err |= nvs_set_str(nvs_handle, "mqtt_pwd", cfg.mqtt_password);
    err |= nvs_set_str(nvs_handle, "dev_name", cfg.device_name);
    err |= nvs_set_str(nvs_handle, "room_name", cfg.room_name);
    err |= nvs_set_str(nvs_handle, "ota_url", cfg.ota_url);
    err |= nvs_set_u8(nvs_handle, "configured", 1);
    if (err == ESP_OK) {
        err = nvs_commit(nvs_handle);
    }
    nvs_close(nvs_handle);
    return err;
}

static bool is_setup_button_pressed() {
    gpio_config_t cfg = {};
    cfg.pin_bit_mask = (1ULL << SETUP_MODE_BUTTON);
    cfg.mode = GPIO_MODE_INPUT;
    cfg.pull_up_en = GPIO_PULLUP_ENABLE;
    cfg.pull_down_en = GPIO_PULLDOWN_DISABLE;
    ESP_ERROR_CHECK(gpio_config(&cfg));
    return gpio_get_level(SETUP_MODE_BUTTON) == 0;
}

static bool read_channel_state(int ch) {
    if (g_ctx.board == BoardType::V27_8CH_TCAL) {
        try {
            return g_ctx.tcal->getPin(static_cast<uint8_t>(ch - 1));
        } catch (const std::exception& e) {
            ESP_LOGE(TAG, "Failed reading TCAL sensor ch%d: %s", ch, e.what());
            return false;
        }
    }

    int idx = ch - 1;
    int raw = gpio_get_level(V28_SENSOR_GPIO[idx]);
    bool sensed_on = raw > 0;
    return V28_SENSOR_ACTIVE_HIGH ? sensed_on : !sensed_on;
}

static void pulse_relay_channel(int ch) {
    if (g_ctx.board == BoardType::V27_8CH_TCAL) {
        uint8_t pin = static_cast<uint8_t>(8 + (ch - 1));
        try {
            g_ctx.tcal->setPin(pin, true);
            vTaskDelay(pdMS_TO_TICKS(RELAY_PULSE_MS));
            g_ctx.tcal->setPin(pin, false);
        } catch (const std::exception& e) {
            ESP_LOGE(TAG, "Failed pulsing TCAL relay ch%d: %s", ch, e.what());
        }
        return;
    }

    int idx = ch - 1;
    gpio_set_level(V28_RELAY_GPIO[idx], 1);
    vTaskDelay(pdMS_TO_TICKS(RELAY_PULSE_MS));
    gpio_set_level(V28_RELAY_GPIO[idx], 0);
}

static void publish_channel_state(int ch, bool on) {
    if (!g_ctx.mqtt) {
        return;
    }

    char topic[192];
    std::snprintf(topic, sizeof(topic), "%s/light/%d/state", g_ctx.base_topic.c_str(), ch);
    esp_mqtt_client_publish(g_ctx.mqtt, topic, on ? "ON" : "OFF", 0, 1, true);
}

static void publish_environment_state(const sht40::Measurement& measurement) {
    if (!mqtt_connected.load()) {
        return;
    }

    char value[24];
    std::string temperature_topic = g_ctx.base_topic + "/environment/temperature";
    std::snprintf(value, sizeof(value), "%.2f", measurement.temperature_c);
    esp_mqtt_client_publish(g_ctx.mqtt, temperature_topic.c_str(), value, 0, 1, true);

    std::string humidity_topic = g_ctx.base_topic + "/environment/humidity";
    std::snprintf(value, sizeof(value), "%.2f", measurement.relative_humidity);
    esp_mqtt_client_publish(g_ctx.mqtt, humidity_topic.c_str(), value, 0, 1, true);
}

static const char* board_model() {
    return g_ctx.board == BoardType::V27_8CH_TCAL ? "v27-8ch" : "v28-4ch";
}

static const char* installed_firmware_version() {
    return esp_app_get_description()->version;
}

static ReleaseInfo release_snapshot() {
    ReleaseInfo snapshot;
    if (state_mutex && xSemaphoreTake(state_mutex, portMAX_DELAY) == pdTRUE) {
        snapshot = g_ctx.release;
        xSemaphoreGive(state_mutex);
    }
    return snapshot;
}

static void store_release_info(const ReleaseInfo& release) {
    if (state_mutex && xSemaphoreTake(state_mutex, portMAX_DELAY) == pdTRUE) {
        g_ctx.release = release;
        xSemaphoreGive(state_mutex);
    }
}

static std::string ip_address_snapshot() {
    std::string snapshot = "unknown";
    if (state_mutex && xSemaphoreTake(state_mutex, portMAX_DELAY) == pdTRUE) {
        if (!g_ctx.ip_address.empty()) {
            snapshot = g_ctx.ip_address;
        }
        xSemaphoreGive(state_mutex);
    }
    return snapshot;
}

static std::string effective_ota_url() {
    ReleaseInfo release = release_snapshot();
    if (!release.asset_url.empty()) {
        return release.asset_url;
    }
    return g_ctx.cfg.ota_url;
}

static void publish_retained(const std::string& topic, const char* payload) {
    if (mqtt_connected.load() && g_ctx.mqtt) {
        esp_mqtt_client_publish(g_ctx.mqtt, topic.c_str(), payload, 0, 1, true);
    }
}

static void publish_update_state() {
    if (!mqtt_connected.load()) {
        return;
    }

    ReleaseInfo release = release_snapshot();
    const char* installed = installed_firmware_version();
    const char* latest = release.version.empty() ? installed : release.version.c_str();

    std::unique_ptr<cJSON, decltype(&cJSON_Delete)> root(cJSON_CreateObject(), cJSON_Delete);
    if (!root) {
        ESP_LOGE(TAG, "Failed allocating firmware update state");
        return;
    }

    cJSON_AddStringToObject(root.get(), "installed_version", installed);
    cJSON_AddStringToObject(root.get(), "latest_version", latest);
    cJSON_AddStringToObject(root.get(), "title", "Light controller firmware");
    cJSON_AddBoolToObject(root.get(), "in_progress", ota_in_progress.load());
    if (!release.release_url.empty()) {
        cJSON_AddStringToObject(root.get(), "release_url", release.release_url.c_str());
    }

    std::unique_ptr<char, decltype(&cJSON_free)> payload(
        cJSON_PrintUnformatted(root.get()),
        cJSON_free);
    if (!payload) {
        ESP_LOGE(TAG, "Failed serializing firmware update state");
        return;
    }

    publish_retained(g_ctx.base_topic + "/firmware/update_state", payload.get());
}

static void publish_diagnostics_state() {
    if (!mqtt_connected.load()) {
        return;
    }

    char value[32];
    publish_retained(g_ctx.base_topic + "/diagnostics/device_name", g_ctx.cfg.device_name);
    publish_retained(g_ctx.base_topic + "/diagnostics/room_name", g_ctx.cfg.room_name);
    publish_retained(g_ctx.base_topic + "/diagnostics/board", board_model());

    std::snprintf(value, sizeof(value), "%d", g_ctx.channel_count);
    publish_retained(g_ctx.base_topic + "/diagnostics/channel_count", value);

    std::string ip_address = ip_address_snapshot();
    publish_retained(g_ctx.base_topic + "/diagnostics/ip_address", ip_address.c_str());

    wifi_ap_record_t access_point = {};
    if (esp_wifi_sta_get_ap_info(&access_point) == ESP_OK) {
        std::snprintf(value, sizeof(value), "%d", access_point.rssi);
        publish_retained(g_ctx.base_topic + "/diagnostics/wifi_signal", value);
    }

    int64_t uptime_seconds = esp_timer_get_time() / 1000000;
    std::snprintf(value, sizeof(value), "%lld", static_cast<long long>(uptime_seconds));
    publish_retained(g_ctx.base_topic + "/diagnostics/uptime", value);

    std::string ota_url = effective_ota_url();
    publish_retained(
        g_ctx.base_topic + "/firmware/ota_url",
        ota_url.empty() ? "not configured" : ota_url.c_str());
}

static bool write_rgb_led_color(uint8_t red, uint8_t green, uint8_t blue) {
    if (!g_ctx.rgb_led) {
        return false;
    }

    esp_err_t err = led_strip_set_pixel(g_ctx.rgb_led, 0, red, green, blue);
    if (err == ESP_OK) {
        err = led_strip_refresh(g_ctx.rgb_led);
    }
    if (err != ESP_OK) {
        ESP_LOGE(TAG, "Failed updating RGB LED: %s", esp_err_to_name(err));
        return false;
    }
    return true;
}

static void refresh_rgb_led_mode() {
    RgbLedMode next = RgbLedMode::OFF;
    if (ota_in_progress.load()) {
        next = RgbLedMode::OTA_UPDATING;
    } else if (!wifi_connected.load()) {
        next = RgbLedMode::WIFI_CONNECTING;
    } else if (!mqtt_connected.load()) {
        next = RgbLedMode::MQTT_ERROR;
    }

    RgbLedMode previous = rgb_led_mode.exchange(next);
    if (previous == next) {
        return;
    }

    switch (next) {
        case RgbLedMode::OTA_UPDATING:
            ESP_LOGI(TAG, "RGB LED: blinking purple while firmware updates");
            break;
        case RgbLedMode::WIFI_CONNECTING:
            ESP_LOGI(TAG, "RGB LED: alternating blue and green while WiFi connects");
            break;
        case RgbLedMode::MQTT_ERROR:
            ESP_LOGI(TAG, "RGB LED: red while MQTT is disconnected");
            break;
        case RgbLedMode::OFF:
            ESP_LOGI(TAG, "RGB LED: off, controller is connected");
            break;
    }
}

static void rgb_led_task_main(void* arg) {
    (void)arg;
    bool first_render = true;
    bool blink_phase = false;
    RgbLedMode previous = RgbLedMode::OFF;

    while (true) {
        RgbLedMode current = rgb_led_mode.load();
        if (current == RgbLedMode::OTA_UPDATING ||
            current == RgbLedMode::WIFI_CONNECTING) {
            if (first_render || previous != current) {
                blink_phase = true;
            } else {
                blink_phase = !blink_phase;
            }
            if (current == RgbLedMode::OTA_UPDATING) {
                write_rgb_led_color(
                    blink_phase ? 255 : 0,
                    0,
                    blink_phase ? 255 : 0);
            } else {
                write_rgb_led_color(
                    0,
                    blink_phase ? 0 : 255,
                    blink_phase ? 255 : 0);
            }
            first_render = false;
            previous = current;
            vTaskDelay(pdMS_TO_TICKS(
                current == RgbLedMode::OTA_UPDATING
                    ? OTA_RGB_LED_BLINK_MS
                    : RGB_LED_BLINK_MS));
            continue;
        }

        if (first_render || previous != current) {
            if (current == RgbLedMode::MQTT_ERROR) {
                write_rgb_led_color(255, 0, 0);
            } else {
                write_rgb_led_color(0, 0, 0);
            }
            first_render = false;
            previous = current;
        }
        vTaskDelay(pdMS_TO_TICKS(100));
    }
}

static void status_led_task_main(void* arg) {
    (void)arg;
    while (true) {
        uint32_t pending_pulses = ulTaskNotifyTake(pdTRUE, portMAX_DELAY);
        while (pending_pulses > 0) {
            gpio_set_level(STATUS_LED_GPIO, STATUS_LED_ACTIVE_LEVEL);
            vTaskDelay(pdMS_TO_TICKS(STATUS_LED_PULSE_MS));
            gpio_set_level(STATUS_LED_GPIO, STATUS_LED_INACTIVE_LEVEL);

            --pending_pulses;
            pending_pulses += ulTaskNotifyTake(pdTRUE, 0);
            if (pending_pulses > 0) {
                vTaskDelay(pdMS_TO_TICKS(STATUS_LED_PULSE_GAP_MS));
            }
        }
    }
}

static void trigger_status_led_pulse() {
    if (g_ctx.status_led_task) {
        xTaskNotifyGive(g_ctx.status_led_task);
    }
}

static void set_ota_in_progress(bool in_progress) {
    ota_in_progress.store(in_progress);
    refresh_rgb_led_mode();
}
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
extern "C" void app_main(void) {
    init_status_led();

    esp_err_t err = nvs_flash_init();
    if (err == ESP_ERR_NVS_NO_FREE_PAGES || err == ESP_ERR_NVS_NEW_VERSION_FOUND) {
        ESP_ERROR_CHECK(nvs_flash_erase());
        ESP_ERROR_CHECK(nvs_flash_init());
    } else {
        ESP_ERROR_CHECK(err);
    }

    state_mutex = xSemaphoreCreateMutex();
    if (!state_mutex) {
        ESP_ERROR_CHECK(ESP_ERR_NO_MEM);
    }

    load_runtime_config(g_ctx.cfg);
    set_default_device_name();

    init_i2c_bus();
    detect_board();
    init_environment_sensor();
    init_rgb_led();
    confirm_running_firmware();
    g_ctx.last_state.assign(g_ctx.channel_count, false);

    init_wifi_core();

    bool force_setup = is_setup_button_pressed();
    if (force_setup || !g_ctx.cfg.configured) {
        start_setup_portal();
        while (true) {
            vTaskDelay(pdMS_TO_TICKS(1000));
        }
    }

    if (!connect_wifi_sta()) {
        ESP_LOGW(TAG, "WiFi failed, starting setup portal");
        start_setup_portal();
        while (true) {
            vTaskDelay(pdMS_TO_TICKS(1000));
        }
    }

    g_ctx.base_topic = std::string("home/") + sanitize_topic_part(g_ctx.cfg.device_name);
    g_ctx.availability_topic = g_ctx.base_topic + "/status";
    if (g_ctx.environment_sensor &&
        xTaskCreate(
            environment_publisher_task,
            "environment_publisher",
            4096,
            nullptr,
            5,
            &g_ctx.environment_task) != pdPASS) {
        ESP_LOGE(TAG, "Failed to start SHT40 publisher task");
        g_ctx.environment_sensor.reset();
    }
    init_mqtt();
    if (xTaskCreate(
            diagnostics_publisher_task,
            "diagnostics",
            4096,
            nullptr,
            4,
            &g_ctx.diagnostics_task) != pdPASS) {
        ESP_LOGE(TAG, "Failed to start diagnostics publisher task");
    }
    if (xTaskCreate(
            release_publisher_task,
            "release_check",
            12288,
            nullptr,
            4,
            &g_ctx.release_task) != pdPASS) {
        ESP_LOGE(TAG, "Failed to start GitHub release publisher task");
    }
    if (xTaskCreate(
            state_publisher_task,
            "state_publisher",
            4096,
            nullptr,
            5,
            nullptr) != pdPASS) {
        ESP_LOGE(TAG, "Failed to start channel state publisher task");
    }
}

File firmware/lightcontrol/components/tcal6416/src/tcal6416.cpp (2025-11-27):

/**
 * @file tcal6416.cpp
 * @brief TCAL6416 16-bit I/O Expander Driver - Simple C++ Implementation using ESP-IDF I2C Master
 */

#include "tcal6416.hpp"
#include "esp_log.h"

namespace tcal6416 {

static const char* TAG = "tcal6416";

// Device implementation
Device::Device(i2c_master_bus_handle_t bus_handle, uint8_t i2c_address, const Config& config)
    : i2c_dev_handle_(nullptr), i2c_address_(i2c_address), config_(config), initialized_(false) {
    
    // Print driver version at initialization
    ESP_LOGI(TAG, "TCAL6416 Driver Version: 1.0.0");
    
    try {
        // Validate parameters
        if (!bus_handle) {
            throw InvalidArgumentException("Bus handle is null");
        }
        validateAddress(i2c_address);
        
        // Create I2C device using ESP-IDF I2C Master
        i2c_device_config_t dev_cfg = {
            .device_address = i2c_address,
            .scl_speed_hz = 100000, // Default to 100kHz
        };
        
        esp_err_t ret = i2c_master_bus_add_device(bus_handle, &dev_cfg, &i2c_dev_handle_);
        if (ret != ESP_OK) {
            throw InitializationException("Failed to add I2C device: " + std::string(esp_err_to_name(ret)), ret);
        }
        
        ESP_LOGI(TAG, "I2C device added at address 0x%02X", i2c_address);
        
        // Apply configuration
        applyConfiguration();
        
        initialized_ = true;
        
        ESP_LOGI(TAG, "TCAL6416 initialized successfully at address 0x%02X", i2c_address_);
        
    } catch (...) {
        // Cleanup on exception
        if (i2c_dev_handle_) {
            i2c_master_bus_rm_device(i2c_dev_handle_);
            i2c_dev_handle_ = nullptr;
        }
        throw; // Re-throw the exception
    }
}

Device::~Device() {
    if (initialized_ && i2c_dev_handle_) {
        esp_err_t ret = i2c_master_bus_rm_device(i2c_dev_handle_);
        if (ret != ESP_OK) {
            ESP_LOGE(TAG, "Failed to remove I2C device: %s", esp_err_to_name(ret));
        }
        ESP_LOGI(TAG, "TCAL6416 deinitialized");
    }
}

Device::Device(Device&& other) noexcept
    : i2c_dev_handle_(other.i2c_dev_handle_),
      i2c_address_(other.i2c_address_),
      config_(other.config_),
      initialized_(other.initialized_) {
    
    other.i2c_dev_handle_ = nullptr;
    other.initialized_ = false;
}

Device& Device::operator=(Device&& other) noexcept {
    if (this != &other) {
        // Clean up current resources
        if (initialized_ && i2c_dev_handle_) {
            i2c_master_bus_rm_device(i2c_dev_handle_);
        }
        
        // Move resources
        i2c_dev_handle_ = other.i2c_dev_handle_;
        i2c_address_ = other.i2c_address_;
        config_ = other.config_;
        initialized_ = other.initialized_;
        
        // Clear other object
        other.i2c_dev_handle_ = nullptr;
        other.initialized_ = false;
    }
    return *this;
}

void Device::setPin(uint8_t pin, bool state) {
    validatePin(pin);
    
    // Check if pin is configured as output
    Port port = (pin < 8) ? Port::PORT0 : Port::PORT1;
    uint8_t port_pin = pin % 8;
    uint8_t port_config = (port == Port::PORT0) ? config_.port0_config : config_.port1_config;
    
    if (port_config & (1 << port_pin)) {
        throw InvalidStateException("Pin " + std::to_string(pin) + " is configured as input");
    }
    
    Register reg_addr = (port == Port::PORT0) ? Register::OUTPUT_PORT0 : Register::OUTPUT_PORT1;
    
    // Read current port state
    uint8_t current_state = readRegisterInternal(reg_addr);
    
    // Modify the specific pin
    if (state) {
        current_state |= (1 << port_pin);   // Set bit
    } else {
        current_state &= ~(1 << port_pin);  // Clear bit
    }
    
    // Write back the modified state
    writeRegisterInternal(reg_addr, current_state);
}

bool Device::getPin(uint8_t pin) {
    validatePin(pin);
    
    Port port = (pin < 8) ? Port::PORT0 : Port::PORT1;
    uint8_t port_pin = pin % 8;
    Register reg_addr = (port == Port::PORT0) ? Register::INPUT_PORT0 : Register::INPUT_PORT1;
    
    // Read port state
    uint8_t port_state = readRegisterInternal(reg_addr);
    
    // Extract the specific pin state
    return (port_state & (1 << port_pin)) != 0;
}

void Device::setPort(Port port, uint8_t value) {
    Register reg_addr = (port == Port::PORT0) ? Register::OUTPUT_PORT0 : Register::OUTPUT_PORT1;
    writeRegisterInternal(reg_addr, value);
}

uint8_t Device::readPort(Port port) {
    Register reg_addr = (port == Port::PORT0) ? Register::INPUT_PORT0 : Register::INPUT_PORT1;
    return readRegisterInternal(reg_addr);
}

void Device::configPin(uint8_t pin, PinDirection direction) {
    validatePin(pin);
    
    Port port = (pin < 8) ? Port::PORT0 : Port::PORT1;
    uint8_t port_pin = pin % 8;
    Register reg_addr = (port == Port::PORT0) ? Register::CONFIG_PORT0 : Register::CONFIG_PORT1;
    
    // Read current configuration
    uint8_t current_config = readRegisterInternal(reg_addr);
    
    // Modify the specific pin configuration
    if (direction == PinDirection::INPUT) {
        current_config |= (1 << port_pin);   // Set bit for input
    } else {
        current_config &= ~(1 << port_pin);  // Clear bit for output
    }
    
    // Write back the modified configuration
    writeRegisterInternal(reg_addr, current_config);
    
    // Update internal config
    if (port == Port::PORT0) {
        config_.port0_config = current_config;
    } else {
        config_.port1_config = current_config;
    }
}

void Device::configPort(Port port, uint8_t config) {
    Register reg_addr = (port == Port::PORT0) ? Register::CONFIG_PORT0 : Register::CONFIG_PORT1;
    writeRegisterInternal(reg_addr, config);
    
    // Update internal config
    if (port == Port::PORT0) {
        config_.port0_config = config;
    } else {
        config_.port1_config = config;
    }
}

void Device::setPinPolarity(uint8_t pin, bool inverted) {
    validatePin(pin);
    
    Port port = (pin < 8) ? Port::PORT0 : Port::PORT1;
    uint8_t port_pin = pin % 8;
    Register reg_addr = (port == Port::PORT0) ? Register::POL_INV_PORT0 : Register::POL_INV_PORT1;
    
    // Read current polarity setting
    uint8_t current_polarity = readRegisterInternal(reg_addr);
    
    // Modify the specific pin polarity
    if (inverted) {
        current_polarity |= (1 << port_pin);   // Set bit for inverted
    } else {
        current_polarity &= ~(1 << port_pin);  // Clear bit for normal
    }
    
    // Write back the modified polarity
    writeRegisterInternal(reg_addr, current_polarity);
}
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

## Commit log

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2020-09-01 work on pcb and fix readme
    [pcbdesign.kicad_pcb]
2020-09-04 fixing encoder
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2021-09-20 caps are wrong way around
    [hamodule.kicad_pcb, hamodule.sch]
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2021-09-20 mounting holes + text correction + ...
    [hamodule-B_Cu.gbr, hamodule-B_Mask.gbr, hamodule-B_Paste.gbr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]
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2021-09-22 sent to jlcpcb! + esp32 init + smaller caps
    [1017505.psm, 1017505.stl, 1017505.stp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]
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2021-10-05 jlcpcb v2: increas connectors pads + fix numbering for sensors in labels
    [hamodule.kicad_pcb, hamodule.sch]
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2021-12-05 fixing rules, missed connections, GND plane
    [hamodule.kicad_pcb, hamodule.sch]
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2021-12-27 using the right USB connector. We need Mode B
    [hamodule.kicad_pcb, hamodule.sch]
2021-12-27 copying USB part from DevKit, adding missing caps, 0Ohm resistors for TXRX
    [hamodule.kicad_pcb, hamodule.sch]
2021-12-27 VBus is signaling the CP2102 before the diode (+resistors), and driving the 5V->3V after the diode
    [hamodule.kicad_pcb, hamodule.sch]
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2021-12-31 updated CP to same version as devkit + started working on BOM
    [BOM_orig.csv, bom_edited_jlcpcb.xls, hamodule.csv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]
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2022-01-16 changed big caps + readme + routing + JLCPCB
    [1017505.psm, 1017505.stl, 1017505.stp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]
2022-01-17 Disconnecting VBus from voltage regulator due to having too big capacitors.
    [1017505.psm, 1017505.stl, 1017505.stp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]
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2022-01-28 adding usb-c, reduce D+/- lenght, broke d View :(
    [hamodule.kicad_pcb, hamodule.kicad_sch]
2022-01-30 updating libraries to kicad6. some footprints got bigger :S
    [hamodule.kicad_pcb]
2022-01-31 fixing transistor symbol. pinout was wrong :(
    [hamodule.kicad_pcb, hamodule.kicad_sch]
2022-02-02 fixing kicad6 library reference. Using the right transistor package. Fixing 3D for some components
    [hamodule.kicad_pcb, hamodule.kicad_sch]
2022-02-02 adding gerber + BOM + new images for README
    [BOM.csv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]
2022-02-02 fixing silkscreen + JLCPCB CPL file
    [hamodule.kicad_pcb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]
2022-02-02 adding missing resistors to the USB port
    [hamodule.kicad_pcb, hamodule.kicad_sch]
2022-02-04 fixing EspRel wrong naming
    [hamodule.kicad_pcb, hamodule.kicad_sch]
2022-02-06 GPIO34+ do not have pull-ups, adding them in hardware
    [hamodule.kicad_pcb, hamodule.kicad_sch]
2022-02-06 fixing electrolytic Capacitor values
    [hamodule.kicad_sch]
2022-02-06 temp sensor GPIO is not compatible with Wifi! Crap, I should have tested this
    [hamodule.kicad_pcb, hamodule.kicad_sch]
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2022-02-24 fixing ERC errors
    [hamodule.kicad_pcb, hamodule.kicad_sch]
2022-02-25 move USB to upper side, and JLCPCB part. Fix netlits for mains + clearance
    [hamodule.kicad_pcb, hamodule.kicad_sch]
2022-02-26 adding second fuse + fixing mains net + silkscreen
    [BOM.csv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]
2022-02-26 switched 3.3v jumper after the JST. This allow disconnecting the onboard ESP, and connect an external one
    [hamodule.kicad_pcb, hamodule.kicad_sch]
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2022-02-28 changing temp sensor for I2C + status led
    [SHT40-AD1B-R3--3DModel-STEP-231308.STEP, XDCR_SHT40-AD1B-R2.step, hamodule.kicad_pcb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]
2022-02-28 TempSensor traces + fix 3D for buttons + remove board review
    [hamodule.kicad_pcb]
2022-03-01 add bom generator script + fab-files + silkscreen
    [BOM.csv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]
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2022-03-14 fixing nets clearance + re-routing N through high voltage area + moving relays
    [hamodule.kicad_pcb, hamodule.kicad_sch]
2022-03-14 Readme + Usb-C 3D + images + Fab files
    [BOM.csv, HRO-20-Type-C-31-M-12.step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]
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2022-03-20 mains class is 1.5mm clearance
2022-03-20 make cuts smaller. Add flags. Extend board a bit
    [hamodule.kicad_pcb]
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2022-03-31 rerouting some 5V + adding slots + fixing net
    [hamodule.kicad_pcb]
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2022-04-04 digikey + moving LDA up + small trace route
    [BOM-DigiKey.xlsx, BOM.csv, hamodule.kicad_pcb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]
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2022-05-09 [BUG] v17 - R11 lowers V too much and ESP cannot be programmed. Replacing by 0Ohms to not to change layout (removed in future versions)
    [hamodule.kicad_sch]
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2022-05-10 [V17][BUG] Updating the readme with the latest schematic image, showing the fix of the USB resistor bug
    [hamodule.kicad_sch]
2022-05-30 flipping SHT40 and adding bigger pads for easier soldering
    [hamodule-B_Courtyard.gbr, hamodule-B_Cu.gbl, hamodule-B_Mask.gbs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]
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2022-06-03 adding fuses for output + 3d modules for wago
    [2604-1102.stp, 2604-1104.stp, BOM.csv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]
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2022-06-03 moving GH URL + adding real pictures + Readme
    [hamodule.kicad_pcb]
2022-06-03 [V18] fab files + images + readme + [V1] schematics image in readme
    [CPL-top.csv, hamodule-B_Courtyard.gbr, hamodule-B_Cu.gbl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]
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2022-06-04 [V19] Adding pictures + prod files folder consistent name
    [BOM.csv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]
2022-06-15 ESPHome pin correction + Arduino test code
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2022-07-11 reversing sensing, to make a more stable reading
    [hamodule.kicad_pcb, hamodule.kicad_sch]
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2022-09-25 [V20] fixing net classes and removing exceptions. Nothing changed in the PCB itself
    [hamodule.kicad_pcb, hamodule.kicad_sch]
2022-09-25 [V20] Fixing relays 3D in PCBNew. Nothing changed on the PCB itself
    [hamodule.kicad_pcb]
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2022-12-05 improving schematics, removing global variables and use wires instead to make it clear how the circuit is working; trying to move inputs to the left, output to the right
    [hamodule.kicad_pcb, hamodule.kicad_sch]
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2023-02-08 Use VBus for ESD before BAT diode; Adding 2 more GPIO; Adding more caps
    [hamodule.kicad_pcb, hamodule.kicad_sch]
2023-02-08 gerbers + fixing silkscreen
    [BOM.csv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]
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2023-05-29 [V23] Fixing MCP, Fixing most DRC & ERC errors. Updating to Kicad7 (netclases, footprints changes only in library)
    [BOM.csv, HRO-20-Type-C-31-M-12.step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]
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2023-09-26 [V8] fixing switch silkscreen
    [hamodule.kicad_sch]
2023-09-30 [V23.8] Adding screen connector + Fixing version + adding caps
    [freerouting.dsn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]
2024-05-28 [23.8] Adding RGB Led, fixing placing and silkscreen
    [hamodule.kicad_pcb, hamodule.kicad_sch]
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2024-05-28 fixing power sockets (3.3v and 5v) + prod files + readme
    [hamodule-B_Courtyard.gbr, hamodule-B_Cu.gbl, hamodule-B_Mask.gbs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]
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2024-05-29 Upgrade to Kicad8, fix silkscreen
    [hamodule-B_Courtyard.gbr, hamodule-B_Cu.gbl, hamodule-B_Mask.gbs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]
2024-05-29 minor fixes
    [hamodule-B_Courtyard.gbr, hamodule-B_Cu.gbl, hamodule-B_Mask.gbs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]
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2024-08-06 [v23.8] Adding more caps and cleaning some tracks. Upgrade to latest Kicad and remove errors
    [BOM.csv, bom.csv, hamodule.kicad_pcb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]
2024-08-06 fixing some checkrules
    [hamodule.kicad_pcb, hamodule.kicad_sch]
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2024-08-09 fixing MCP and ULN inputs and outputs, They were overpowered
    [hamodule.kicad_pcb, hamodule.kicad_sch]
2024-08-09 replaccing NC caps by caps with value, and adding notes in schematics
    [BOM-hamodule.csv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]
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2025-05-04 fixing issue caused by Kicad8. Kicad 9 with many ERC fixed
    [BOM-hamodule.csv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]
2025-05-06 pull-up for TCAL. Fix ERC. Fix 3D models. Fix Silkscreen
    [hamodule.kicad_pcb, hamodule.kicad_sch]
2025-05-27 Adding GND vias close to signal. Separate signal vias to make sure that they dont create a large cut in layer 2 and 3. For example for the LEDs going to ULN or the R56, R57, etc. Their vias are not a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
    [hamodule.kicad_pcb, hamodule.kicad_sch]
2025-05-27 Changes in the schematic look: 1. Align label text to the right, in order the trace is under the label. 2. Display resistors values for the resistors next to the LED (R45... R5x) 3. Align the identif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
    [hamodule.kicad_pcb, hamodule.kicad_sch]
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2025-06-02 adding ground vias close to signal vias going to ULN2803. Adding Power supply model to silkscreen
    [hamodule.kicad_pcb]
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2025-07-30 Adding Test point for TCAL to ULN. Small astetic change in the schematic: Moving the voltage divider resistors after the NOT gate
    [BOM.csv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]
2025-08-02 [V26] Rearranging some nets. Fixing some connections that were missing. Solving some ERC. Updating UL28003 footprint to match current library
    [hamodule.kicad_pcb, hamodule.kicad_sch]
2025-08-04 [V26] Updated RST-80-AMMO (lib -> kicad_sym). Updated components to match library naming <library:footprint>. Utilize standard library for some components (SHT40, ULN). Updated LD1117 symbol to match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
    [hamodule.kicad_pcb, hamodule.kicad_sch]
2025-08-04 Added 0201 capacitors for decoupling high frequencies. Reshuffled some resistors to make more straight paths. Added silkscreen where missing
    [hamodule.kicad_pcb, hamodule.kicad_sch]
2025-08-04 Fixed library filters to allow selected footprint
    [hamodule.kicad_pcb, hamodule.kicad_sch]
2025-08-04 Created only one project specific symbol library, one for footprints, and one for icons. Deleted all the rest from the components folder
    [AQG12205.stl, MCP23018-E_SO.step, SHT40-AD1B-R3--3DModel-STEP-231308.STEP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]
2025-08-05 Created symbols for every image and logo, in order there are no warnings
    [hamodule.kicad_pcb, hamodule.kicad_sch]
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2025-08-14 change large 3.3v capacitor orientation. Fixed SNT IC silkscreen. Moved TP on data line to avoid GND plane breaking
    [hamodule.kicad_pcb, hamodule.kicad_sch]
2025-08-14 Removing 4 way junctions. Rotating capacitor close to ESP32. Adding enclosure size layer
    [bom.csv, designators.csv, hamodule.kicad_pcb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]
2025-08-14 renaming 26.8 to 26.1 - numbering will be used for different board sizes to test fit in the enclosure
    [BOM.csv, bom.csv, designators.csv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]
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2025-08-15 Fixing KiBot to point to 26.1. Adding JLCPCB column to BOM output
2025-08-15 moved a bit the data lines between TCAL and SNT to make sure they have solid GND plane beneath. Updated footprints from library since Kibot complains. lets see if it fixes it
    [hamodule.kicad_pcb]
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2025-08-19 Adding 26 2L. This is a version used only to test fit of the PCB on the case. All v26 will be like that. The main difference is the production files
    [BOM.csv, bom.csv, designators.csv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]
2025-08-19 Adding v 26.2. This is the same as V26.1. In the next commit, it will have a smaller board. to test fit in the case.
    [bom.csv, designators.csv, freerouting.dsn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]
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2025-10-13 thicker traces for mains going to relays, in preparation for larger fuses. Moved 4 layer testers. Added vias for 3.3V traces in both layers
    [hamodule.kicad_pcb, hamodule.kicad_sch]
2025-10-13 Fixing GH Action: type: pcbdraw does not support layers selection anymore
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2025-11-27 [v27] uses now 1k resistor as pull down for TCAL read port. Updated schematic and PCB with V27
    [hamodule.kicad_pcb, hamodule.kicad_sch]
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2026-06-26 [v27] Fix USB-c schematic does not match footprint Rule error
    [hamodule.kicad_pcb]
2026-06-27 [v27] Replaced small caps by 22uF. Reshuffled LED for 3.3V and 5V for more separation. Separate more 3.3v, 5v and jumper connection
    [bom.csv, designators.csv, hamodule.kicad_pcb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]
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2026-07-13 moved all code to firmware. Created a new firmware that will be the one actually used
    [partitions.csv]
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2026-07-27 Fix GitHub release OTA downloads
    Increase the HTTP request buffer for GitHub signed redirects, refresh release metadata per update, and publish download progress.
    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
    [main.cpp]
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2026-07-27 reverse the status led. its always off and blink on messages
    [main.cpp]

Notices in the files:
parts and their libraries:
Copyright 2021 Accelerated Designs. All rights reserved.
